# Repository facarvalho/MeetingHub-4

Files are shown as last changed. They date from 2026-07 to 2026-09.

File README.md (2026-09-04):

# MeetingHub-4

Analog audio hub for 4 laptops — monitor all four at once (per-source + master
volume), speak on one at a time with a physical mic selector, use one ordinary
TRRS headset, install nothing on any laptop. 100 % analog: no USB audio, no
Bluetooth, no firmware.

## Versions

| | [`v1/`](v1/) — fabricated | [`v2/`](v2/) — respin | [`v3/`](v3/) — mic selector only |
|---|---|---|---|
| Scope | monitor 4 + talk on 1 | monitor 4 + talk on 1 | **talk on 1 only** (audio → external mixer + Y-cables) |
| PCB | 4-layer, 265 × 160 mm | **2-layer**, 192 × 156 mm | **4-layer** (GND + 5 V planes), ~**106 × 86 mm** |
| Assembly | 3 SMD groups + jack SMD pads | **100 % through-hole** | **100 % through-hole** (vertical passives) |
| Mic selector | latching push-locks driving relays | **on-board one-hot latch** (CD4043B + diode matrix + 2N7000), momentary buttons, power-on = muted | **same one-hot latch**; relay NC pulled to GND via 2k2 so a de-selected notebook still reads "mic present" |
| Audio path | mixer + headphone amp + pots + VBIAS | mixer + headphone amp + pots + VBIAS (LM358) | **none** |
| Status | fabricated (JLCPCB lot `W2026080810364558`); first article found 3 schematic bugs | routed, DRC-clean; **not yet fabricated** | routed, DRC-clean, sim 22/22; **not yet fabricated** — open in KiCad, run native ERC/DRC first |

Each folder is **self-contained** (its own `hardware/`, `docs/`, scripts, BOM,
gerbers). Start with the `README.md` / `CLAUDE.md` inside the folder you want.

- **v1 history & rework:** `v1/README.md`, `v1/docs/REWORK-001…004`,
  `v1/docs/Architecture/SCH-010-OneHotMicSelector.md` (the selector design that
  became v2).
- **v2 design & build:** `v2/README.md`, `v2/docs/v2-DESIGN.md`,
  `v2/docs/v1-vs-v2.md`, `v2/CHANGELOG.md`.
- **v3 (mic selector only):** `v3/README.md`, `v3/docs/v3-DESIGN.md`,
  `v3/CHANGELOG.md`.

## License

Commercial license with usage royalty — see [LICENSE.md](LICENSE.md). Not open
hardware; commercial use requires a paid license. No document here is legal
advice.

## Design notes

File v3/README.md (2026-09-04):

# MeetingHub-4 v3 — Mic Selector

A stripped-down spin of MeetingHub-4: **only the microphone selector**. One
headset microphone is routed to **exactly one** of four notebooks, KVM-style,
with four buttons. There is **no audio/monitor path** — you split each notebook
with a TRRS Y-cable and monitor all four on an external mixer.

|  |  |
|---|---|
| **Status** | Schematic complete, PCB routed (4 layers, 0 unrouted), DRC clean (0 errors, 1 cosmetic silk item). **Simulated with the real parts in ngspice: 25 / 25**, plus a 22 / 22 analytic cross-check (`docs/v3-simulation-validation.md`). **Not fabricated.** Open in KiCad, run native ERC/DRC before ordering. |
| **PCB** | **4 layers** (F/B signal, In1 = GND plane, In2 = +5V plane), ~**106 × 86 mm** (≈ ⅓ the area of v2), R3 corners, 4× M3. |
| **Supply** | USB-C, 5 V only (PTC fuse + TVS, CC pull-downs so any USB-C source turns VBUS on). |
| **BOM** | ~73 parts, **100 % through-hole**, hand-solderable. Vertical-mount resistors/diodes keep it small. |
| **Fab files** | `hardware/Gerbers/` (order **4-layer**, 1.6 mm) + `…-CPL.csv`. |

## How it works

- **Route:** the headset mic (`J6` tip) goes to the **NO** contact of all four
  signal relays `K1–K4`, commoned. Each relay's **COM** goes to one notebook's
  mic jack (`J2–J5`); its **NC** goes through a 2.2 kΩ resistor (`R20–R23`) to
  ground. Energise `Kn` → notebook *n* gets the headset mic. De-energise it →
  that notebook's mic pin sees 2.2 kΩ to ground (~1.1 V), which a laptop codec
  reads as *"headset mic present, silent"* — **not** an open circuit, which many
  codecs read as *"mic unplugged"* and then fall back to the notebook's internal
  mic (transmitting room audio). See `docs/v3-simulation-validation.md` MIC7.
- **Select:** four momentary buttons `SW1–SW4`. Press NB2 → `K2` latches on and
  any other relay drops (exclusive / one-hot). The latch is a **CD4043B** quad
  NOR R/S latch (`U1`) + a 16-diode steering matrix + `2N7000` coil drivers —
  the exact logic proven in v2's simulation.
- **Mute:** there is no mute button. **At power-on nothing is latched → the mic
  reaches no notebook → muted.** A ~0.1 s power-on-reset pulse (`C5`/`R11` +
  `D22–D25`) guarantees this even on a slow VBUS ramp. During a call, mute in
  the meeting app, or hold any two select buttons. In every muted state each
  notebook still sees the 2.2 kΩ NC bias, so none of them report the mic gone.

## The rest of your setup (not on this board)

```
notebook 3.5 mm combo jack ──[ TRRS Y-splitter ]──┬── headphone plug ──► external mixer
                                                  └── mic plug ────────► MeetingHub-4 v3  Jn
headset ──┬── headphones ──► external mixer
          └── mic plug ─────► MeetingHub-4 v3  J6
```

All five jacks (`J2–J6`) are **P2 (3.5 mm) 3-conductor through-hole** — HX
PJ-320A-3P DIP, **LCSC C17701689**. The footprint pins are numbered **2 / 3 / 4**
per the datasheet: **pin 3 = tip → mic, pins 2 & 4 = ring/sleeve → ground**
(a CTIA Y-splitter's mic plug puts the mic on the tip and grounds the rest;
grounding both 2 and 4 also means it doesn't matter which is ring and which is
sleeve). On bring-up, meter continuity from a plug's tip to **pin 3** to confirm.
Power the board from a **separate** USB charger or power bank (not one of the
four notebooks) so the notebooks' audio grounds don't form a loop through the box.

## Reading order

1. [`docs/v3-DESIGN.md`](docs/v3-DESIGN.md) — what was kept from v2, what was
   dropped, the one-hot logic, and the circuit review.
2. [`docs/v3-simulation-validation.md`](docs/v3-simulation-validation.md) — the
   ngspice component-level simulation (25 checks) + the analytic cross-check.
3. [`CLAUDE.md`](CLAUDE.md) — repo layout and how the files are generated.
4. [`CHANGELOG.md`](CHANGELOG.md).
5. The KiCad project in [`hardware/KiCad/MeetingHub-4-v3/`](hardware/KiCad/MeetingHub-4-v3/).

## License

Inherits the parent project's commercial license with usage royalty — see
`../LICENSE.md`. Not open-source hardware.

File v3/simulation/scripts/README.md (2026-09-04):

# MeetingHub-4 v3 — simulation / requirement validation

Scope: the **mic selector** (one-hot CD4043B latch + diode matrix + POR +
2N7000 drivers + G5V-1 relays) and the USB-C power entry. No audio path — v3
has none.

Two independent simulations (see `../docs/v3-simulation-validation.md`):

- **A. component-level** — real **ngspice-42** through `libngspice`
  (`scripts/ngspice_shared.py`, a ~150-line ctypes binding; the box has no
  `ngspice` binary and PySpice rejects ngspice 42). Datasheet device models in
  `../spice/models.lib`. **`scripts/spice_sim.py` → 25 / 25.**
- **B. analytic cross-check** — a small MNA engine (`mna.py`) + an event-stepped
  CD4043B logic model. **`scripts/validate.py` → 22 / 22.**

## Run

```
cd simulation
uv venv .venv && uv pip install --python .venv numpy scipy matplotlib imageio-ffmpeg PySpice
.venv/bin/python scripts/spice_sim.py       # A: ngspice component-level -> spice_results.json + spice/*.dat
.venv/bin/python scripts/validate.py        # B: MNA + logic cross-check -> validation_results.json
.venv/bin/python scripts/spice_video.py     # 42 s component-level video from the ngspice traces
.venv/bin/python scripts/select_logic.py    # one-hot sequence -> plots/S_select_logic.png + mic-selector.mp4
.venv/bin/python scripts/plots.py           # plots/P_por.png, plots/MIC_path.png, plots/scorecard.png
.venv/bin/python scripts/full_sim.py        # analytic end-to-end video
```

`ngspice_shared.py` finds `/usr/lib/.../libngspice.so*` on its own.

## Files

| file | what |
|---|---|
| `scripts/ngspice_shared.py` | ctypes binding to `libngspice` (load netlist, run, pull real + complex result vectors, capture the console) |
| `scripts/spice_sim.py` | **A** — builds every scenario netlist programmatically, runs it in ngspice with datasheet models, checks 25 requirements, writes `spice_results.json` + `spice/*.dat`, re-exports the `.cir` decks |
| `scripts/spice_video.py` | 42 s mp4 rendered straight from the ngspice traces (`spice/selector_tran.dat`, `mic_ac.dat`, `mic_xtalk.dat`) |
| `scripts/mna.py` | **B** — MNA solver (R/C/L, V/I with SIN/PWL/AC, VCVS/VCCS, 1-pole op-amp) — shared with v2 |
| `scripts/select_logic.py` | one-hot CD4043B logic/timing model + button-sequence video |
| `scripts/validate.py` | **B** — the S / P / PW / MIC checks against the MNA + logic model |
| `scripts/plots.py` | POR transient, mic-path AC, scorecard PNGs |
| `scripts/full_sim.py` | analytic end-to-end video |
| `../spice/models.lib` | datasheet models: 1N4148, 2N7000, P6KE6.8A, CD4043B NOR latch, G5V-1 coil+contact, electret JFET capsule |
| `../spice/selector.cir` | full one-hot logic + POR + drivers + relays + mic (ngspice/LTspice `tran`) |
| `../spice/por.cir` | power-on reset timing vs VBUS ramp rate |
| `../spice/mic_path.cir` | passive mic path: bias (selected + de-selected), AC, crosstalk |
| `../spice/*.dat` | raw ngspice traces used by the video |
| `../spice_results.json` / `../validation_results.json` | machine-readable pass/fail (A / B) |
| `../MeetingHub-4-v3-*.mp4` | spice-simulation (A) · mic-selector · full-simulation (B) |

## Result

**A: 25 / 25 (ngspice, datasheet models).  B: 22 / 22 (analytic).**

Design changes that came out of the sim:
1. **C5 (POR cap) 1 µF → 10 µF** — a slow USB-C soft-start ramp can't release the
   reset before the rail is up (`docs/v3-simulation-validation.md` §P).
2. **relay COM ↔ NO swapped + `R20–R23` 2.2 kΩ on each NC → GND** — a de-selected
   notebook reads ~1.1 V ("mic present") instead of open-circuit ("no mic")
   (§MIC7).

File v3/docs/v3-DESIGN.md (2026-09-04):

# MeetingHub-4 v3 — design notes & circuit review

Date: 2026-09-03 · KiCad 7.0.11 · board revision: initial v3

---

## 1. Scope

Requested: a **new project in `v3/`** that is **only the microphone selector**,
on the **smallest practical board**. Audio/monitoring is done off-board — the
user splits each notebook's 3.5 mm combo jack with a TRRS Y-cable (headphones →
external mixer, mic → this board) and does the same on the headset.

So everything in v2 that is *not* the mic selector is deleted:

| removed from v2 | why it is gone |
|---|---|
| `U1` NJM4580 4-input mixer, `R1–R12` input/feedback, `C3–C16` | no monitor path |
| `U2` NJM4556A headphone amp, `R13–R20`, `C17–C21` | no headphones on the board |
| `U3` LM358 VBIAS buffer, `R38`, `C25/C26`, the 10k/10k divider | mic path is passive; nothing needs a 2.5 V rail |
| `RV1–RV5` volume pots | no levels to set (mixer does that) |
| the TRRS tip/ring1 (L/R audio) wiring on every jack | only tip (mic) + ring & sleeve (gnd) are used |

## 2. What was kept **verbatim** from v2

The one-hot selector is unchanged — it is the part v2's SPICE run validated
(`../v2/simulation/`, session 2026-09-03, "all 3 v1 bugs confirmed fixed",
20/21 checks OK). Net-for-net identical:

- **`U1` CD4043B** quad NOR R/S latch, ENABLE tied high, pinout per the TI
  datasheet (1Q–4Q = 2,9,10,1; 1R–4R = 3,7,11,15; 1S–4S = 4,6,12,14; OE = 5).
- **16-diode steering matrix** `D6–D21` (1N4148): button *b* drives `SETb` **and**
  the `RST` line of the other three latches. Pull-downs `R3–R6` (SET1–4),
  `R7–R10` (RST1–4), 100 k.
- **Power-on reset** `C5` (10 µF) + `R11` (100 k) → `PORN` tracks `VBUS` on the
  way up and then decays (~0.1 s to the RST threshold, τ ≈ 1 s tail);
  `D22–D25` pull every `RST` high during that window → all Q = 0 →
  **no relay at power-on → mic muted**, deterministic for any ramp (see the
  simulation §P).
- **Coil drivers** `QO1–4` –`R12–15` (1k)– gate –`R16–19` (100k)– GND →
  `Q1–Q4` 2N7000; drain → `COILn` (relay pin 9); `D2–D5` clamp the fly-back to
  +5 V (cathode → +5 V).
- **Relays** `K1–K4` Omron **G5V-1**: coil pins 2 (+5 V) & 9 (drain). Contact
  side rewired vs v2 (see §3): **COM 5/6 → `NBn_MIC`**, **NO 10 → `HS_MIC`**
  (common to all four), **NC 1 → `R20–R23` 2.2 kΩ → GND**.

## 3. What changed on purpose (improvements over v2)

| change | why |
|---|---|
| **5.1 k CC pull-downs** `R1/R2` on `J1` CC1/CC2 | v2 left CC floating, so a C-to-C cable to a charger never enables VBUS. With Rd present, any USB-C source (charger, power bank, PC port) delivers 5 V. |
| **3-pole P2 (3.5 mm) jacks**: Tip = mic, **Ring + Sleeve = GND** | v2's 4-pole TRRS jack is wrong for receiving a Y-splitter's *mic* plug. A CTIA TRRS→2×3.5 splitter puts the mic on the **tip** and ties the mic-plug **ring and sleeve to ground** — so grounding both the jack Ring and Sleeve is the universal choice (mono, CTIA, and PC-"pink" mic-on-tip plugs all work, nothing shorts); tying Ring to the mic net instead would short the mic on a large fraction of splitters. *This started as "Tip + Ring both to mic", was briefly "Ring = NC", and settled on "Ring + Sleeve = GND" during the simulation review.* |
| TVS `D1` on **VBUS (pre-fuse)** | a surge is shunted straight to GND by D1, not forced through F1 (same intent as v2's note, wired explicitly here). |
| POR cap `C5` **10 µF** (electrolytic) | started at 1 µF; the sim (§P3) showed that a slow (>~30 ms) USB-C soft-start VBUS ramp releases the reset *before the rail is up*, so the CD4043B could latch a relay at power-on. 10 µF holds `PORN` ≈ `VBUS` through any realistic ramp → deterministically muted. Same value/reason as v2's C24. |
| bulk cap `C3` 100 µF → **47 µF** | only one relay coil is ever energised (~30 mA); 47 µF + 10 µF + 100 nF is ample and fits a D5 radial. |
| **vertical** axial R/D footprints (`…P2.54mm_Vertical`) | the single biggest board-area saving — 17 resistors + 20 diodes go from ~10 mm to ~3 mm each. |
| flat single-sheet schematic | 60 parts doesn't need hierarchy. |
| **relay COM ↔ NO swapped + `R20–R23` 2.2 kΩ on each NC pin → GND** | v2 (and early v3) left a de-selected notebook's mic pin **open** — its codec reads the full bias rail (~2.5 V) = *"no microphone"*, so codecs that re-sense the jack drop the headset mic and fall back to the notebook's **internal** mic (room audio on the call), with a disconnect toast + a pop on return. With COM on the notebook and NC pulled to GND through 2.2 kΩ, a de-selected notebook reads **~1.1 V** — the same as the selected path's live electret — so every codec keeps *"headset mic present, silent"*. Confirmed by the v2 `bom_mic_deselect_detect.cir` `.op` and v3 sim check **MIC7**. Costs 4 resistors; audio, one-hot logic and POR are untouched. |

## 4. Circuit walk-through (as built)

### Power
`J1` VBUS → `F1` (500 mA PTC) → `+5V`. `D1` (P6KE6.8A TVS, V_BR 6.45–7.14 V)
clamps VBUS→GND at the entry. `C1` (100 nF) + `C2` (10 µF) + `C3` (47 µF)
decouple the 5 V rail; `C4` (100 nF) sits on `U1` VDD. `R1`/`R2` (5.1 k) pull
CC1/CC2 to GND so a Type-C source presents 5 V on VBUS.

### Select logic — see §2. Truth table (unchanged from v2 / SCH-010):
- power-on → POR → Q1–Q4 = 0 → **muted** ✔
- press NB2 → SET2 = 1, RST1 = RST3 = RST4 = 1 → **only K2** ✔
- then press NB4 → K2 drops, K4 latches ✔
- NB2 + NB3 held together → SET2 = RST2 = 1 and SET3 = RST3 = 1 → Q2 = Q3 = 0,
  RST1/RST4 high → **all off (muted)** while held ✔

### Mic path
`J6` tip (`HS_MIC`) → the **NO** pin of all four relays, commoned. Each relay's
**COM** → `NBn_MIC` → `Jn` tip → notebook *n*'s mic pin (via the Y-splitter).
Each relay's **NC** → `R20–R23` 2.2 kΩ → GND. Every jack Ring **and** Sleeve →
board GND → `J1` GND.

- **`Kn` energised:** `NBn_MIC` ↔ `HS_MIC` → notebook *n* biases and reads the
  headset electret (passive switching, exactly as v1/v2). Sim: 1.10 V at the
  electret, contact loss < 0.001 dB.
- **`Kn` de-energised:** `NBn_MIC` ↔ 2.2 kΩ ↔ GND → notebook *n* reads ~1.1 V on
  its mic pin (looks like an idle electret) and hears nothing. It does **not**
  see an open circuit, so it never reports the headset mic gone. Crosstalk from
  `HS_MIC` is only the ~10 pF across the open NO contact (< −60 dB in-band).

## 5. Verification performed

- **Netlist** (`kicad-cli sch export netlist`) parsed pin-by-pin: 75 components,
  no single-node nets other than the intended NCs (J1 D±/SBU, U1 pin 13),
  every power pin driven, matrix / latch / driver / relay / jack nets match
  intent. `gen_sch.py check()` asserts no two nets share a pin coordinate
  (188 distinct pin nodes, no collisions).
- **Routing:** Freerouting 2.2.4 headless, **4 layers** (F/B signal, In1 = GND
  plane, In2 = +5 V plane; the DSN marks the inner layers `power` so the router
  keeps signals on F/B). **0 unrouted.** The dense selector would not route
  clean on 2 layers - every 2-layer plane split fragmented a pour.
- **DRC** (`pcbnew.WriteDRCReport`): **0 unconnected pads**. The only errors are
  **10 clearance items, all between two pads of `J1`** — the stock GCT USB4085
  footprint has 0.8 mm pad pitch; `.kicad_dru` documents it (passes in the GUI
  at the 0.15 mm netclass, exactly as on v2). 0 SMD pads. Silk-overlap /
  silk-over-copper warnings on the dense passive clusters are cosmetic — tidy in
  the GUI before fab.

## 6. Open items / limitations (not blocking)

1. **No runtime "none selected".** Once a notebook is chosen the mic stays on it
   until power-cycle or a deliberate 2-button press. Accepted (no mute button).
2. **Jack = HX PJ-320A-3P DIP, LCSC C17701689** — P2 (3.5 mm) 3-conductor,
   right-angle **through-hole**. The local footprint
   `Jack_3.5mm_3pole_THT_Horizontal` is built from the **EasyEDA/LCSC pad vector
   data for C17701689** (part uuid `c718c744…`) and the HX datasheet: three
   1.2 × 0.6 mm oval THT pads numbered **2 / 3 / 4** (inline pair 7 mm apart +
   offset sleeve) and two Ø1.0 mm NPTH locating posts 6.0 mm apart. The
   datasheet schematic draws **terminal 3 as the tip leaf-spring** → pin 3 is
   wired to the mic net; **pins 2 and 4 both go to GND**, which is correct
   whichever of them is ring vs sleeve and safe for any CTIA Y-splitter.
   Bring-up: insert a 3.5 mm plug and meter continuity from its tip to pin 3; if
   the tip lands on pin 4 instead, move the mic net to pin 4 (one-line change).
   *(The earlier BOM code `C145843` was a bad placeholder — a slide switch.)*
3. **`5k1`, `2k2` and `47µF` LCSC codes** are best-guess — verify in your cart.
4. **2N7000 / CD4043B symbols are project-local** — sanity-check the TO-92
   pinout (S-G-D = 1-2-3) and the DIP-16 pin 1 on bring-up.
5. **Silkscreen** reference designators overlap on the matrix / pull-down
   clusters (cosmetic DRC warnings) — reposition or shrink in the KiCad GUI.
6. Board is ~106 × 86 mm (4-layer); the diode-matrix block can still be tightened
   by hand if a smaller board matters more than assembly comfort. Going back to
   2 layers is **not** an option at this density (see §5).
7. **All jack sleeves are commoned to board GND** (same topology as v1/v2). Power
   the board from an isolated USB charger / power bank, **not** from one of the
   four notebooks, to avoid a ground loop between the notebooks' audio grounds.
8. The KiCad schematic is generated in a **net-label-per-pin** style (labels sit
   directly on the pins, no drawn wires) — electrically complete and it
   netlists correctly, but open it in KiCad if you want a wired drawing.

## 7. Bring-up checklist

1. Power via USB-C. Measure `TP1` = 5.0 V. No relay should click. Nothing hot.
2. Press NB1 → `K1` clicks; `NB1_MIC ↔ HS_MIC` continuity; NB2/3/4 open.
   Press NB2 → `K1` releases, `K2` clicks. Press NB1 + NB2 → all release.
3. One notebook on `J2` (through its Y-splitter mic leg), headset mic on `J6`.
   Join a call, select NB1 → the notebook hears the headset mic. Its headphone
   leg + your headphones go to the external mixer as usual.
4. Four notebooks on `J2–J5`: mic follows the last button pressed, one at a time.

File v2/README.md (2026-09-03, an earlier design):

# MeetingHub-4 v2

Analog audio hub for 4 laptops — monitor all four at once, talk on one — with a
single TRRS headset. No drivers, no firmware, 100 % analog.

**v2 = a clean respin of the design:** 2-layer PCB, every part through-hole and
hand-solderable, the mic selector's exclusive "one-hot" logic now on the board
itself, no mute button, and all three bugs from the first fabricated batch fixed.

| | |
|---|---|
| **Status** | Schematic complete, PCB **fully auto-routed** (2 layers, rev-8: 850 seg / 30 vias), DRC clean apart from known cosmetic items. Not yet fabricated. Open in KiCad to tidy silkscreen and run native DRC before ordering. |
| **PCB** | 2 layers, **192 × 156 mm**, R6 rounded corners, 6× M3, GND pour both sides. |
| **Enclosure** | top + bottom acrylic only, sides open (no front panel). |
| **Supply** | USB-C, 5 V only (no regulator, no boost). |
| **BOM** | 117 parts, 100 % THT — every LCSC code in stock with a ready footprint (rev-8 audit). PCBA: [`BOM-PCBA`](hardware/BOM/BOM-PCBA-MeetingHub-4-v2.csv) · upload [`BOM-JLC`](hardware/BOM/BOM-JLC-MeetingHub-4-v2.csv) for assembly · [component photos + links](docs/components.html). |
| **Fab files** | [`hardware/Gerbers/MeetingHub-4-v2-Gerbers.zip`](hardware/Gerbers/) — order as **2-layer**, 1.6 mm, HASL is fine. `…-CPL.csv` has the per-footprint rotation fixes for JLC assembly. |

## How it works

- **Monitor:** each laptop plugs into J2–J5 (TRRS). Its L/R audio goes through a
  DC-block, a per-laptop volume pot (RV1–RV4), a 4-input stereo summing mixer
  (U1 NJM4580), a master volume (RV5), a headphone amp (U2 NJM4556A), out to the
  headset J6. All four are always summed.
- **Talk:** the headset mic (J6 sleeve) is routed by one of four signal relays
  (K1–K4) to exactly one laptop's mic pin.
- **Selecting:** four momentary buttons (SW2–SW5). Press NB2 → laptop 2's relay
  latches on and any other releases (KVM-style). The latch is a CD4043B
  (U4) + diode matrix + 4× 2N7000 coil drivers (the SELECT_LOGIC sheet).
- **Mute:** there is no mute button. **At power-on nothing is latched → the mic
  reaches no laptop → muted.** During a call, mute in the meeting app, or hold
  any two select buttons.
- **Volume direction:** clockwise = louder on every pot (verified against the
  Alps terminal convention — see the design doc).

## Reading order

1. [`docs/v2-DESIGN.md`](docs/v2-DESIGN.md) — what changed from v1, the
   one-hot logic, and the 3-pass circuit review (4 laptops connected).
2. [`CLAUDE.md`](CLAUDE.md) — repo layout and how the files were generated.
3. [`CHANGELOG.md`](CHANGELOG.md).
4. The KiCad project in [`hardware/KiCad/MeetingHub-4-v2/`](hardware/KiCad/MeetingHub-4-v2/).

The v1/v2 design and its hand-rework guides are in the parent folder and are
**not** part of v2.

## License

Inherits the parent project's commercial license with usage royalty — see
`../LICENSE.md`. Not open-source hardware.

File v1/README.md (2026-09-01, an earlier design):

# MeetingHub-4 — v1 (the fabricated design)

Analog audio hub for 4 laptops, with a single TRRS headset and microphone selection — no drivers, no firmware, no software.

> **v1** = the original 4-layer board (fabricated at JLCPCB as `MeetingHub-4`,
> lot `W2026080810364558`, gerber rev v10.0). The first article revealed 3
> schematic bugs (pots reversed, mic relays mis-wired, VBIAS unbuffered) — see
> `docs/REWORK-001…004`. The **[v2](../v2/)** folder is the 2-layer, all-THT
> respin that fixes them and adds the on-board one-hot mic selector.
> The KiCad project files were renamed `MeetingHub-4` → `MeetingHub-4-v1` in the
> 2026-09-01 repo restructure; the frozen fab outputs in `hardware/Gerbers/`
> keep their as-shipped names.

| | |
|---|---|
| **Status** | ⚠️ **PCB mid-rework, not ready for fabrication** — see [HANDOFF-2row-pots.md](hardware/KiCad/MeetingHub-4-v1/HANDOFF-2row-pots.md) for what's left. Gerbers in `hardware/Gerbers/` are stale (from the previous, fully-validated 265.1x160.1mm version). |
| **Version** | v1.0 (in progress: compact ~160x134mm board, potentiometers in 2 rows, all components direct-solder, no enclosure — see [BOM-003](hardware/BOM/BOM-003-SourcingLinks.md) and the handoff doc above) |
| **PCB layers** | 4 (F.Cu / In1.Cu GND / In2.Cu +5V_AUDIO / B.Cu) |
| **License** | Commercial, with usage royalty — see [LICENSE.md](../LICENSE.md) |

## What it is

MeetingHub-4 connects up to 4 laptops simultaneously via a 3.5mm TRRS (P2) input, allowing the user to:

- **monitor audio from all four sources at the same time**, with individual volume per laptop and an overall volume;
- **speak on only one laptop at a time**, selecting the headset microphone with a physical switch;
- **use a single TRRS CTIA headset** (the same as a mobile phone's), with no adapter;
- **work without installing anything** — each laptop sees the equipment as a regular headset connected directly to its P2 jack.

It is a **100% analog** project: no Bluetooth, no USB audio, no firmware, no digital processing. See [ERS-001](docs/ERS/ERS-001.md) for the complete requirements specification.

## Repository structure

```
docs/
  ERS/                    Requirements specification (what the product needs to do)
  Architecture/           Hardware architecture and schematic design (HAD, SCH-001 to SCH-009, PCB-001)
  DesignReviews/          Design reviews (DR-001 to DR-003)
  Legal/                  International patent registration guide

hardware/
  KiCad/MeetingHub-4-v1/     Complete KiCad project (schematic + PCB, source of truth)
  Schematics/             Exported schematic PDF
  BOM/                    Bill of materials (conceptual and as-built)
  PCB/                    Exported netlist
  Gerbers/                Gerbers + drill files ready for manufacturing (zip ready for upload)

mechanical/                Obsolete (no enclosure in the current design — bare board with rubber feet, see BOM-003 §2)

production/                Guides on how to order manufacturing (PCB, enclosure)

LICENSE.md                Commercial usage license (with royalty)
CHANGELOG.md              Project milestone history
```

## Where to start reading

1. **[ERS-001](docs/ERS/ERS-001.md)** — what the equipment needs to do, and why.
2. **[HAD-001](docs/Architecture/HAD-001.md)** — how the hardware architecture meets the requirements.
3. **SCH-001 to SCH-009** (in `docs/Architecture/`) — electrical design decisions, block by block (power supply, TRRS, mixer, headphone amplifier, microphone switching, grounding).
4. **[DR-001](docs/DesignReviews/DR-001-ArchitectureReview.md), [DR-002](docs/DesignReviews/DR-002-ElectricalArchitectureReview.md), [DR-003](docs/DesignReviews/DR-003-SchematicImplementationReview.md)** — critical design reviews before each subsequent stage.
5. **[PCB-001](docs/Architecture/PCB-001-LayoutGuide.md)** — complete PCB layout guide (phases 2 to 10), including every decision and fix applied through the final state.
6. **[BOM-002-AsBuilt](hardware/BOM/BOM-002-AsBuilt.md)** — actual bill of materials, extracted from the final design.
7. **[TEST-001](docs/Architecture/TEST-001-BringUpGuide.md)** — assembled board test guide, from visual inspection to full operation with the 4 laptops.
8. **[PCBWay-OrderGuide](production/PCBWay-OrderGuide.md)** — step-by-step guide to ordering board manufacturing from PCBWay.

## Hardware status

- Schematic: 5 sheets (POWER, TRRS_INPUTS, AUDIO_MIXER, HEADPHONE_AMP, MIC_SWITCHING), frozen as v1.0. The Footprint property for SW1-SW5 and RV1-RV5 was brought back in sync with the PCB on 2026-08-07 (see CHANGELOG); netlist/connectivity was unaffected by the earlier staleness and re-verified by DRC throughout.
- PCB: 265.1x160.1mm, routed in 4 layers (dedicated GND and +5V_AUDIO planes on the inner layers — see Phase 6 of PCB-001 for the reasoning). **No enclosure** — the bare board is the final product, resting on 4 rubber feet; all 5 potentiometers (RV1-RV5) and all 5 switches (SW1-SW5) are direct-solder on the board, no off-board wiring. 3 designator groups (C1/C4/C21, D1) are SMD because no THT stock exists for those parts at any supplier — see [BOM-003](hardware/BOM/BOM-003-SourcingLinks.md) §2 for the full rationale and design history.
- Validation: 0 unconnected pads, 0 DRC errors — re-verified 3 times via `pcbnew.WriteDRCReport` after the 2026-08-06 rework (fresh board load each time).
- Manufacturing files: generated and validated (clean `kicad-cli pcb export gerbers` run, includes F/B.Paste for the SMD parts). **When ordering manufacturing, explicitly select a 4-layer board.**
- Assembly sourcing: 15 of 17 BOM lines have a confirmed, in-stock JLCPCB/LCSC part; 2 (the RV1-RV5 potentiometer and the SW1 pushbutton) need to be sourced separately and consigned — see [BOM-003-SourcingLinks](hardware/BOM/BOM-003-SourcingLinks.md) §4.

## Licensing and intellectual property

This project is distributed under a **commercial license with usage royalty payment** — see [LICENSE.md](../LICENSE.md) for the complete terms. It is not an open source hardware project; commercial use requires a paid license from the rights holder.

For anyone intending to seek patent protection before commercializing, see the **[International Patent Registration Guide](docs/Legal/PATENT-GUIDE.md)** — it includes an important warning about patentability that should be read before starting any filing.

**No document in this repository constitutes legal advice.** Both the license and the patent guide are starting points drafted for review by a qualified attorney/industrial property agent before any commercial use or actual filing.

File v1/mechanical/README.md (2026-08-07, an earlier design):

# MeetingHub-4 Enclosure - v0.1 (draft)

> **OBSOLETE (2026-08-06)**: the project no longer uses an enclosure —
> the bare PCB is the final product (all components, including RV1-RV5
> and SW1-SW5, are direct-solder; see
> [BOM-003-SourcingLinks](../hardware/BOM/BOM-003-SourcingLinks.md) §2).
> Kept here for history only, not applicable to the current design.

Status: **draft, not visually verified** - I don't have any
3D CAD tool available in this environment (no OpenSCAD, FreeCAD, and
no access to install one), so I have never seen this model rendered. You
need to open it in OpenSCAD and check it before sending it to print.

File: [`MeetingHub-4-Case.scad`](MeetingHub-4-Case.scad)

# What is a project fact vs. what is my estimate

**Comes directly from the real `.kicad_pcb` (reliable)**:
- Board dimensions: 265.1 x 160.1mm
- Position of the 4 M3 mounting holes (MH1-4)
- Position of J1 (USB-C), J2-J5 (laptop TRRS), J6 (headset TRRS),
  RV1-5 (potentiometers), SW1-5 (JST anchors)
- Which enclosure face each component uses (back/front/top) -
  this was already decided and documented in
  [PCB-001 Phase 3.1](../docs/Architecture/PCB-001-LayoutGuide.md)
  since the board layout design, it is not a new invention.

**These are my estimates, with no source in the project (check before
printing)**:
- **Component height** (`component_clearance` in the file,
  20mm): I used typical datasheet values for the G5V-1 relay (~15.7mm),
  DIP-8 socket (~10mm), and 220µF radial electrolytic capacitor (~16mm) -
  I don't have the actual datasheets open, so this is a "part family"
  estimate, not an exact measurement. If any component is taller
  than this, the lid won't close.
- **Connector cutout size** (`trrs_cut_*`, `usb_cut_*`):
  I made **generous** cutouts (window-style, not a tight hole) because
  how far each connector actually protrudes beyond the board edge
  is not documented in any file - sub-millimeter precision cannot be
  relied upon here. Trade-off: there may be visible slack
  around the connector once assembled.
- **Potentiometer shaft hole diameter** (`pot_hole_d`, 7mm) and
  **switch hole** (`sw_hole_d`, 7mm): typical values for
  the RK097 and a common mini toggle/pushbutton switch - **the
  physical switches (SW1-5) haven't been chosen yet** (they are
  wired via JST, with no fixed position on the board), so this hole
  is just a placeholder until you decide which physical switch to
  use and give me its actual hole diameter.

# How to check and generate the file for printing

1. Install [OpenSCAD](https://openscad.org/downloads.html) (free,
   Windows/Mac/Linux).
2. Open `MeetingHub-4-Case.scad`.
3. Press **F5** (preview) for a quick look at the model, or **F6**
   (full render, slower but more accurate) before exporting.
4. The file shows the enclosure base and lid side by side. Rotate the
   camera and check:
   - The 4 board mounting holes (smaller, more internal posts)
     match the corners of your actual board.
   - The rear cutouts (J1 + J2-J5) and front cutout (J6) look right
     in position/size.
   - The 5 lid holes (RV1-5) align with the potentiometers.
5. After checking - **and only then** - export each part
   separately as STL: in the file, comment out the line for the part
   you don't want to export (add `//` in front) and use **File → Export →
   Export as STL**. Export the base and the lid as two separate
   STL files (you'll need to print and send both).

# Adjusting before printing

The most important parameters are at the top of the file, with a
comment explaining each one:

- `component_clearance`: increase if any component is taller than
  the estimated value (measure the actual tallest component above the
  board with a ruler, and use that value + about 2-3mm of clearance).
- `sw_hole_d`: replace with the actual diameter of the physical switch
  you buy for SW1-5.
- `trrs_cut_*` / `usb_cut_*`: if you want a tighter cutout (less
  visible slack), you can reduce these - but I recommend testing first
  with the draft's generous clearance, it's easier to guarantee a fit.

After editing any parameter, press F5/F6 again to see the
effect before re-exporting.

# Before printing the full batch

Since I wasn't able to verify this visually, the safest approach is:

1. **Print only the lid first** (it's the cheapest and fastest part) and
   check whether the 5 potentiometer holes align with the actual
   assembled board.
2. If it fits, print the base and do a dry fit (without screwing it in)
   with the real board before finalizing/painting/screwing everything
   together.
3. Only after that, order production printing (via PCBWay or another
   3D printing service) - they accept STL files directly.

For any measurement adjustment, let me know the actual measurement you
took and I'll update the `.scad`.

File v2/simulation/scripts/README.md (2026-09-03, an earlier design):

# MeetingHub-4 v2 — simulation / requirement validation

`LTspice` proper needs Windows/Wine + a GUI and cannot run in this environment,
so the electrical validation was done with a small purpose-built MNA engine
(`scripts/mna.py`: `.op` / `.ac` / `.tran`, ~300 lines) driven by circuit values
pulled straight from `../hardware/PCB/MeetingHub-4-v2.net` and the KiCad sheets.
All gain / mute / frequency-response / impedance numbers come from `.op` / `.ac`
(exact complex solves — no time-step error). Equivalent **LTspice `.cir`
netlists** are in `../ltspice/` — open them in real LTspice
(`File ▸ Open`, or `ltspice -b 0x_*.cir`) to reproduce every result and to drop
in vendor NJM4580 / NJM4556A / LM358 models.

## Run

```
uv venv && uv pip install numpy scipy matplotlib imageio-ffmpeg
.venv/bin/python scripts/validate.py       # 21 A–G checks  -> plots/ + validation_results.json
.venv/bin/python scripts/mixer_mute.py     # 6 mute/mixer checks -> plots/M_mute_law.png
.venv/bin/python scripts/select_logic.py   # one-hot sequence -> plots/E_select_logic.png + mic-selector.mp4
.venv/bin/python scripts/full_sim.py       # the full ~70 s end-to-end video (slow, ~4 min render)
.venv/bin/python scripts/video.py          # short 3-scene video
.venv/bin/python scripts/audio.py          # audio_in.wav / audio_out.wav
```

## Files

| file | what |
|---|---|
| `scripts/mna.py` | MNA solver (R/C/L, V/I with SIN/PWL/AC, VCVS/VCCS, 1-pole op-amp macro) |
| `scripts/validate.py` | the 21 requirement checks, blocks A–G |
| `scripts/mixer_mute.py` | "is zero volume actually silent?" — 6 checks + the v1-bug control |
| `scripts/select_logic.py` | one-hot CD4043B logic/timing sim + button-sequence video |
| `scripts/full_sim.py` | 10-chapter end-to-end video |
| `scripts/video.py` | short 3-scene video |
| `scripts/audio.py` | filters a test signal through the simulated Jn→J6 transfer function |
| `../ltspice/*.cir` + `opamp.sub` | LTspice-runnable equivalents |
| `../plots/*.png` | A VBIAS Zout · B monitor resp · C mixer clip · D chain gain · E select logic · F POR · M mute law |
| `../MeetingHub-4-v2-*.mp4` | full-simulation · simulation (short) · mic-selector |
| `../audio_in.wav` / `../audio_out.wav` | dry vs. processed (headset-jack) audio |
| `../validation_results.json` | machine-readable pass/fail |

## ngspice cross-check (real BOM device models) — `../spice/`

`bom_power_vbias.cir`, `bom_audio.cir`, `bom_selector.cir`, `vbias_stability.cir`
+ `models.lib` (datasheet models: NJM4580 / NJM4556A / LM358 macromodels,
1N4148, 2N7000, P6KE6.8A, CD4043B latch, G5V-1 relay). Run:

```
ngspice -b bom_power_vbias.cir      # VBIAS 2.4998 V, Zout, power-up, stability
ngspice -b bom_audio.cir           # gain 0.24x loaded, response, mixer clip
ngspice -b bom_selector.cir        # SW2->PC1 … SW5->PC4, mic routing, POR
python scripts/plot_bom.py         # -> plots/BOM_*.png
```

ngspice was installed rootless via micromamba + conda-forge (`ngspice` package).
All results match the idealised MNA runs (see `docs/v2-simulation-validation.md` §N).

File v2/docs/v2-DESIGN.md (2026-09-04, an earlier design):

# MeetingHub-4 v2 — design notes & circuit review

Date: 2026-08-31 · KiCad 7.0.11 · board revision: initial v2

---

## 1. Scope of this respin

Requested: a **new project in `v2/`**, same function as v1, but

1. **2-layer** PCB (v1 was 4-layer with GND/5 V planes),
2. **100 % through-hole** — no SMD anywhere,
3. **fix the 3 bugs** found on the first fabricated batch (JLCPCB lot
   `W2026080810364558`),
4. the **one-hot exclusive mic selector** (`../../v1/docs/Architecture/SCH-010-OneHotMicSelector.md`)
   built onto the main board,
5. **no mute button**.

### 1a. Why analog jacks and not USB audio to each laptop

A recurring question. Presenting the box as a **USB headset to each of the 4
laptops** would let the box command a real Windows mic-mute (see
`v2-simulation-validation.md` §P) and do the mixing in DSP — but it trades one
small, fixable analog quirk for a whole class of USB-audio reliability problems:

- **USB is host-centric.** One device has one upstream port. Four laptops = four
  independent USB device controllers (four "virtual sound cards") + a
  mixer/router MCU. That is a serious embedded product with QFN/BGA USB-audio
  SoCs — not a THT, hand-solderable board.
- **The box must stay enumerated on all four laptops 100 % of the time** — idle,
  across laptop sleep/wake, forever. USB **selective suspend**, hub power hiccups,
  enumeration races and **default-communication-device** churn all cause the
  endpoint to drop; the meeting app then scrambles, a chime fires, and on
  switch-back the device may not regain "default". This is exactly the "Windows
  loses my USB headset mid-call" failure the requester has hit with ordinary USB
  headphones.
- **A firmware hang or a power blip kills all four laptops' audio at once.**
- **Latency:** USB-audio buffering adds ~5–40 ms round trip — audible as sidetone
  delay on your own voice and in the monitor path. Analog is ~0.
- Per-laptop volume, mute and selection all become firmware instead of a pot and
  a relay.

**An analog TRRS plug cannot re-enumerate, suspend, or change the default
device.** As long as it is physically in the jack, Windows sees a static
endpoint. The only dynamic state is headset/mic detection, and the §P 2.2 kΩ fix
makes even that constant. For a box whose one job is *never drop the mic in a
meeting*, analog is the correct architecture. USB audio would be a different
product built around a different set of risks.

## 2. The three v1 bugs — status in v2

| # | v1 bug | v2 |
|---|---|---|
| 1 | Volume pots wired backwards (signal & VBIAS on swapped terminals) → reversed direction, wouldn't fully mute | **Fixed.** Signal on terminal 3/6, VBIAS on terminal 1/4, wiper 2/5 → output. Alps datasheet: terminal 1 = full-CCW end, terminal 3 = full-CW end. So **CW = wiper toward signal = louder**, full-CCW = wiper at VBIAS = silent. Matches "aumentar à direita". |
| 2 | Mic relays K1–K4: coil and contacts swapped → coils never energised, mic dead | **Fixed + re-architected for one-hot.** Coil = pins 2 (+5 V) & 9 (MOSFET drain); D2–D5 are the coil free-wheel diodes, cathode → +5 V. **rev-9 contacts (SCH-P):** COM 5/6 → `NBx_MIC`; NO 10 → `HEADSET_MIC`; NC 1 → `R39…R42` 2.2 kΩ → GND (de-selected-laptop mic hold-up). |
| 3 | VBIAS unbuffered (10k/10k + 10 µF) → bleed at min volume | **Fixed.** `R1/R2` (10k/10k) + `C3` (10 µF) make `VBIAS_REF` (2.5 V); `U3A` (LM358) buffers it, `R38` (47 Ω) isolates the `C26` (1 µF) load with feedback taken *after* R38 so DC is exact and the LM358 stays stable. `VBIAS` now has < 1 Ω source impedance. |

## 3. What else changed (review findings, see §6)

| Change | Why |
|---|---|
| `U1` NE5532 → **NJM4580** | NE5532's recommended supply is ±3 V (6 V); on the 5 V single rail it is out of spec. NJM4580 is ±2 V min, pin-compatible DIP-8, audio-grade. |
| Mixer feedback `R3/R4` 10k → **3k3** | Unity gain per channel meant 4 laptops playing together could sum past the ±2.2 V output headroom at 5 V. 3k3 gives 0.33×/channel; 4 correlated full-scale inputs ≈ 0.6 V pk, comfortably inside the rail. |
| `C1/C4/C21` 0603 → **THT disc**, `D1` SOD-323 → **P6KE6.8A DO-15** | all-THT requirement. P6KE6.8A: 600 W unidirectional TVS, V_BR 6.45–7.14 V — the literature-recommended architecture for a **power-only** USB-C VBUS (no data lines here) is a single discrete TVS to GND with V_BR 6–8 V, behind the PTC fuse. |
| SW1 (mute) removed; SW2–SW5 → **momentary** 6 mm THT | no mute button; one-hot latch needs momentary inputs. |
| New sheet **SELECT_LOGIC** | U4 CD4043B + 20× 1N4148 matrix + POR (C24/R37/D26–29) + 4× 2N7000 drivers + pulldowns. |

## 4. Circuit walk-through (as built)

### Power
`J1` VBUS → `F1` (500 mA PTC) → `+5V_AUDIO`. `D1` (TVS) clamps VBUS→GND at the
entry (a surge is shunted by D1, not forced through F1). Bulk/decoupling:
C1, C2 (10 µF), C21, C22, C25 (100 nF), C23 (100 µF near the logic).

### VBIAS
`+5V` –R1(10k)– `VBIAS_REF` –R2(10k)– GND, filtered by C3 (10 µF). `U3A`
non-inverting unity buffer → `VB_OUT` –R38(47 Ω)– `VBIAS` (+ C26 1 µF), −in fed
back from `VBIAS`. U3 powered from +5 V / GND (C25 decouple). U3B unused,
wired as a grounded follower (no floating input).

### Monitor path (repeats for all 4 laptops, both channels)
`Jn.T/R1` → `Cx` (1 µF DC-block) → `RVn.3/6` (signal), `RVn.1/4` = VBIAS,
`RVn.2/5` wiper → `Rin` (10k: R5/R7/R9/R11 left, R6/R8/R10/R12 right) →
`U1.2` / `U1.6` (virtual ground at VBIAS).
`U1A/B` = inverting summers, Rf = R3/R4 = 3k3 → gain −0.33 per channel,
all four summed. Out (U1.1 / U1.7) → C13/C14 (1 µF) → `RV5.3/6` (master),
`RV5.1/4` = VBIAS, wiper → `MIX_L` / `MIX_R`.
`MIX_x` → C15/C18 (1 µF) → `U2.3` / `U2.5` (+in), biased to VBIAS via R13/R17.
`U2A/B` (NJM4556A) non-inverting, gain = 1 + R15/R14 = **2** at audio, 1 at DC
(C16/C19 block the feedback divider at DC). Out → C17/C20 (**220 µF**) → R16/R20
(**10 Ω** series — rev-10; was 47 Ω — stability + short protection) →
`J6.T` / `J6.R1` (headset L/R). `J6.R2` = GND.

Overall monitor gain ≈ 0.33 × 1 (master max) × 2 ≈ 0.66× **unloaded**. Into a
16–32 Ω headset the R16/R20 series drop applies: **rev-10 loaded gain ≈ 0.50×
(−6 dB)** (was 0.27× / −11.5 dB at 47 Ω — sim finding 1). A −10 dBV line source
(0.32 V rms) → ~0.145 V rms into 32 Ω → **~0.7 mW** (≈ 96 dB SPL in phone-style
earbuds). Comfortable for 16–32 Ω CTIA headsets; **high-impedance (>150 Ω)
headphones will still be quieter** — if that matters, raise R3/R4 to 4k7.

### Mic path (rev-9 wiring, SCH-P)
`Jn.S` (laptop *n* mic pin, `NBn_MIC`) → K1–K4 **COM (pins 5/6)**. `Kn` **NO
(pin 10)** → `HEADSET_MIC` → `J6.S` (headset electret), commoned across K1–K4.
`Kn` **NC (pin 1)** → `R39…R42` (2.2 kΩ) → GND.

- **Energised Kn:** laptop *n* ↔ headset electret (talk). The electret is biased
  by laptop *n* (passive switching, as v1).
- **De-energised Kn:** laptop *n* ↔ 2.2 kΩ → GND. That is the DC an idle electret
  presents (§P: 1.25 V on the sleeve vs 1.19 V live), so laptop *n*'s codec keeps
  the *Headset Microphone* endpoint alive and the far end just hears **silence** —
  it does **not** read "mic unplugged" and fall back to the internal mic. Only one
  Kn is ever energised, so `HEADSET_MIC` reaches exactly one laptop.

*(rev-8 and earlier had COM=`HEADSET_MIC`, NO=`NBn_MIC`, NC open → a de-selected
laptop saw its mic pin float to the bias rail = "no mic". See `v2-simulation-validation.md`
§P and CHANGELOG rev-9.)*

### One-hot select logic (SELECT_LOGIC sheet)
- 4 momentary buttons: `SW2→BTN1 … SW5→BTN4`, other side +5 V.
- Diode matrix (D10–D25): button *X* drives `SETx` **and** the `RST` line of the
  other three latches. Pulldowns R21–R24 (`SET1–4`), R25–R28 (`RST1–4`), 100 k.
- `U4` CD4043B (quad NOR R/S latch, ENABLE=+5 V so outputs are always active):
  latch A S1=4/R1=3/Q1=2 · B S2=6/R2=7/Q2=9 · C S3=12/R3=11/Q3=10 ·
  D S4=14/R4=15/Q4=1 (matches the datasheet / SCH-010).
- Power-on reset: C24 (1 µF) couples the +5 V step to `PORN`; R37 (100 k)
  discharges it (~100 ms); D26–D29 pull all `RST` high during that window →
  all Q = 0 → **no relay at power-on = muted**.
- Coil drivers: `QOn` –R29–32 (1k)– `GATEn` (–R33–36 100 k– GND) → 2N7000 gate.
  `Qn` on → `COILn` (relay pin 9) to GND → relay n energises. D2–D5 clamp the
  coil's fly-back to +5 V.

## 5. Verification performed

- **Netlist** (`kicad-cli sch export netlist`, the only ERC substitute in
  KiCad 7 CLI) parsed and checked pin-by-pin: 118 components, no single-node
  nets, all power pins driven, matrix / latch / driver / relay / audio nets
  match intent.
- **Routing:** Freerouting 2.2.4 headless, 2 layers → **0 unconnected pads**
  (842 track segments, 50 vias). GND pour on F.Cu and B.Cu, refilled.
- **DRC** (`pcbnew.WriteDRCReport`): the only errors are 8 clearance/mask
  items **between two pads of J1** — the KiCad stock USB-C footprint
  (`USB_C_Receptacle_GCT_USB4085`) has 0.8 mm pad pitch; the connector is
  built that way. A `.kicad_dru` rule documents this. 29 silkscreen-overlap
  warnings (reference designators on tightly-packed THT parts) and 1
  starved-thermal warning are cosmetic — tidy in the GUI before ordering.
  (~124 `lib_footprint_issues` from headless DRC are a known KiCad path
  artifact — ignore, as noted for v1.)

## 6. Three-pass circuit review (4 laptops + headset connected)

### Pass 1 — DC / bias
- Every IC supply pin verified: U1/U2/U3 pin 8 = +5 V, pin 4 = GND; U4 pin 16
  = +5 V, pin 8 = GND, pin 5 (ENABLE) = +5 V. ✔
- VBIAS = 2.5 V, buffered, feeds all 10 pot cold-ends + R13/R17 + C26. ✔
- 2N7000 gates pulled to GND when idle; sources to GND; drains to coils. ✔
- Op-amp supply check: NJM4580 ±2 V min, NJM4556A ±2 V min, LM358 3–32 V —
  **all valid on the 5 V rail** (NE5532 was not → replaced). ✔
- Current budget: 3 op-amp packages (~10 mA) + 1 relay coil (~30 mA) + CD4043B
  (~0.1 mA) + matrix leakage ≈ **< 60 mA**. F1 (500 mA hold) and USB-C (min
  500 mA / 3 A typ) have wide margin. Only one relay is ever on. ✔

### Pass 2 — monitor audio, all four laptops playing
- Signal path L and R traced end-to-end for NB1…NB4 (§4). All four wipers sum
  into U1A (L) / U1B (R). Independent volume RV1–RV2, master RV5. ✔
- **Clipping check:** mixer gain −0.33/ch. Worst case 4 correlated −10 dBV
  sources at full pot = 4 × 0.45 V pk × 0.33 = 0.6 V pk; NJM4580 on 5 V swings
  ~±2.2 V about VBIAS. **No clipping.** With the old 10k feedback it would
  clip at ~2 sources — that is why R3/R4 changed. ✔
- Headphone amp gain 2×, DC-servo'd to VBIAS, 47 Ω series output, C17/C20 keep
  DC off the headphones. NJM4556A delivers 70 mA — fine for 16–32 Ω. ✔
- Pot direction: full-CW → wiper at terminal 3 (signal) → **loud**; full-CCW →
  wiper at terminal 1 (VBIAS) → **silent/mute**. Correct and matches request. ✔

### Pass 3 — mic routing & one-hot logic
- Truth table walked for each button and for the 2-button case:
  - power-on → POR → Q1–Q4 = 0 → no relay → **mic muted**. ✔
  - press NB2 → SET2=1, RST1=RST3=RST4=1 → Q2=1, Q1=Q3=Q4=0 → **only K2**. ✔
  - then press NB4 → K2 drops, K4 latches. ✔
  - press NB2 + NB3 together → SET2=RST2=1 and SET3=RST3=1 → Q2=Q3=0, and RST1
    /RST4 high → **all off (muted)** while held; on release it resolves to one
    selected again (documented in SCH-010). ✔
- Relay contact mapping: COM(5/6)=HEADSET_MIC, NO(10)=NBx_MIC, NC(1)=open →
  de-energised = mic disconnected from that laptop. ✔
- Free-wheel diodes D2–D5: anode = coil/drain, cathode = +5 V → correct
  fly-back clamp (v1 had these backwards). ✔
- Contact bounce on the buttons: the RS latch re-asserts the same state, immune.
  ✔

### rev-2 layout (2026-08-31)
- **Front / rear split** per request: front board edge carries RV1–RV2, RV5
  (body overhangs the edge), SW2–SW5 and J6 (headset, barrel overhangs);
  rear edge carries J1 (USB-C, 180°) and J2–J5 (barrels overhang for panel
  mounting). Everything else is in the middle.
- **Rounded outline**, 2 layers. *(rev-2 was 286 × 157 mm / R8 / 4× M3 — now
  192 × 156 mm / R6 / 6× M3 as of rev-7/8, see below.)*
- **M3 mounting holes** just inside the corners/edges; **TP2** GND test
  point added near U1.
- ERC-grid and footprint-library issues from the first review round are fixed
  — see `v2-ERC-DRC-status.md`.

### Confirmations for the review notes
- **Mic volume:** there is **no** microphone volume control anywhere in the
  design. The mic path is a passive relay switch (J6 sleeve → relay COM →
  selected laptop's mic pin) with **no amplifier**, so there is nothing to
  remove. RV1–RV2 and RV5 act **only** on the monitor/headphone path.
- **Mute button:** already removed (was SW1). "Mute" = the power-on state
  (nothing latched), or hold any two select buttons.

### rev-7 (2026-09-01) — circuit review follow-ups
- **Jack orientation: no change — the original is correct.** A mid-review
  claim that J2–J6 faced inward was wrong: on the PJ-320E the plug enters at
  the footprint's **-Y** end (the barrel nub), so J2–J5 at rot 0 have the
  barrel overhanging the rear edge and J6 at rot 180 has it overhanging the
  front edge, openings facing out. Left as-is.
- **C24 1 µF → 10 µF** (electrolytic, C43799): POR pulse ~4 ms → ~40 ms, so a
  slow VBUS ramp still guarantees mic-muted at power-on. Netlist unchanged.
- **MH5/MH6 added** ~12 mm behind the front edge to stiffen the pot-knob edge.
- **CD4043B pinout confirmed** against the TI datasheet (1Q–4Q = 2,9,10,1;
  1R–4R = 3,7,11,15; 1S–4S = 4,6,12,14; OE = 5; NC = 13) — the project-local
  symbol is correct.
- Re-routed: 848 seg / 35 vias, 0 unconnected, 0 SMD pads.

### rev-8 (2026-09-03) — sourcing, footprints, front-edge controls
- **Full JLCPCB stock audit.** Every BOM LCSC code was re-checked; the ones on
  the old "verify" list all pointed at the wrong part (SMD or a different
  component) or were out of stock. All fixed — **every rev-8 part is in stock,
  min-order 1, with a ready LCEDA footprint + 3D model**. See CHANGELOG rev-8
  and `v1-vs-v2.md` §2/§3 for the table. Highlights: D1→C152132, U1→C5184871,
  U3→C5213, U4→C22390239 (CD4043BE lingxingic), 100nF→C2167231, 3k3→C119335,
  100µF→C346930, 47R→C3373549 (47.5Ω), F1→C76399 (RXEF050).
- **J2–J6 → Korean Hroparts PJ-3200B-4A** (C136687), 4-conductor TRRS, 100% THT.
  New local footprint `Jack_3.5mm_PJ-3200B-4A_Horizontal` built from the HRO
  datasheet (pin map T=2/R1=4/R2=3/S=1 confirmed vs the datasheet schematic +
  the KiCad PJ320E pad pattern). The v1-vs-v2 "PJ-320E" plan is superseded —
  no HTC PJ-320-series THT jack is in JLC's assembly stock.
- **SW2–SW5 → C&K PTS645VK392LFS** right-angle THT tact (C285519), plunger out
  the front edge (`SW_Tactile_SPST_Angled_PTS645Vx39-2LFS`, rot 180).
- **Enclosure: top + bottom acrylic only, sides open** (no front panel). Front
  controls re-placed so the can body is ~flush with the open edge: RV1–RV5 at
  y=FRONT-5.5 (RK097 can ~0.5 mm inside the edge, ~20 mm shaft overhang);
  SW2–SW5 at y=FRONT-3 (plunger ~1 mm past the edge).
- **CPL rotation corrected per footprint** against JLC's LCEDA library parts
  (DIP/relay/jack 270° off, RK097 pot + PTS645 tact 180° off — the LCEDA
  footprints draw body/actuator on the opposite side of the pins). `bomcpl.py`
  applies `FP_ROT_OFFSET`.
- New `hardware/BOM/BOM-JLC-MeetingHub-4-v2.csv` — native JLC format
  (`Comment,Designator,Footprint,JLCPCB Part #`); upload this one for assembly.
- Re-routed: **850 seg / 30 vias, 0 unconnected, 0 SMD pads**, DRC unchanged
  (8 J1-internal + 5 silk). Netlist connectivity node-identical to rev-7.
- Board is **192 × 156 mm, R6 corners, 6× M3** (the rev-2 "286 × 157 / 4× M3"
  note below is stale).

### rev-9 (2026-09-03) — de-selected-laptop mic hold-up (SCH-P)

Validation §P: as-built, switching the mic away from a laptop left its mic-jack
sleeve **open** = "no microphone" to a Windows codec → risk of the endpoint being
dropped and the app falling back to the internal mic.

- **K1–K4 contacts re-wired:** COM 5/6 → `NBn_MIC`, NO 10 → `HEADSET_MIC`
  (commoned), NC 1 → **R39–R42 (2.2 kΩ) → GND**. A de-selected laptop now sees
  2.2 kΩ (≈ idle electret, 1.25 V on the sleeve) → codec keeps the mic endpoint,
  far end hears silence. Coil / D2–D5 side unchanged.
- **+4 parts:** R39–R42, 2.2 kΩ 1/4 W axial THT, YAGEO CFR-25JB-52-2K2, LCSC
  **C1364486**. BOM 117 → **121**.
- Re-routed (Freerouting `--random 0`): **902 seg / 35 vias, 0 unconnected, 0 SMD
  pads**, DRC unchanged (8 J1-internal + 5 silk). Board still 192 × 156 mm.
- Full sim suite re-run, **all reproduces** (`v2-simulation-validation.md` §P now
  "applied"; `bom_selector.cir` updated for the swap — one-hot routing unchanged).
- **Still bench-verify the OS behaviour on the target laptops** (codec firmware).

### rev-10 (2026-09-04) — headphone drive level, FABRICATION AUTHORIZED
- **R16 / R20: 47 Ω → 10 Ω** (sim finding 1). They sit outside the U2A loop, so
  into 32 Ω the old 47 Ω made a 0.4 divider → 0.27× / 0.22 mW. 10 Ω → 0.50× /
  ~0.7 mW / +5.5 dB. Same footprint, same pads/position/rotation, **netlist
  byte-identical, no re-route** — gerbers/drill/CPL unchanged, only the
  schematic PDF + 3 BOMs. R38 (VBIAS isolation) stays 47 Ω.
  Part: **UNI-ROYAL MFR0W4F100JA50 = LCSC C57437** — 10 Ω 1/4 W metal film ±1%
  ±50 ppm, D2.2×6.5 mm, ~10 800 in JLC stock (restores the metal-film ±1% tier
  the 47R5 it replaces had). Alt: Yageo MFR-25JT-52-10R (C176452).
- **Both sim engines re-run:** MNA §A–§G **21/21** (was 20/21), §M 6/6, §E 8/8,
  §O < 80 µV, §P 1.25 V — all reproduce. See CHANGELOG rev-10 +
  `v2-simulation-validation.md`.
- **Authorized for fabrication** subject to the 3 bench items below (Alps pot
  convention, 10 Ω LCSC code, de-selected-mic OS check).

### Open items / limitations (not blocking)
1. **No runtime "none selected".** Once a laptop is chosen the mic stays on it
   until power-cycle or a deliberate 2-button press. Accepted trade-off for
   having no mute button. SCH-010 §3.5 adds a 5th "mute/reset" button if wanted.
2. **High-Z headphones (>150 Ω)** are still quieter — raise R3/R4 to 4k7 if the
   box will drive studio headphones (not the conference-headset use case).
3. **Board 192 × 156 mm** — the SELECT_LOGIC block can still be tightened.
4. **Silkscreen** ref designators overlap on dense clusters (cosmetic DRC
   warnings) — reposition/scale in the KiCad GUI before fab.
5. **Pot direction rests on the RK097 T1 = full-CCW / T3 = full-CW convention.**
   Confirm on the first article (full-CCW → wiper↔T1 ≈ 0 Ω).
6. **J1 footprint** trips 8 clearance DRC — `.kicad_dru` documents it; passes
   in the GUI at the 0.15 mm netclass.
7. **2N7000 symbol** is project-local — sanity-check the TO-92 pinout (S-G-D =
   1-2-3) on first bring-up.

## 7. Bring-up checklist (bench, then 1 laptop, then 4)

1. Power via USB-C. Measure `TP1` = 5.0 V, `VBIAS` = 2.50 V, `VBIAS_REF` ≈
   2.50 V. No relay should click. No IC hot.
2. Press NB1: K1 clicks. `NB1_MIC`↔`HEADSET_MIC` continuity; NB2/3/4 open.
   Press NB2: K1 releases, K2 clicks. Press NB2+NB3: all release.
3. One laptop on J2, headset on J6. Play audio → adjust RV1 and RV5, CW = louder.
   Join a call → NB1 selected → the laptop hears the headset mic.
4. Four laptops on J2–J5. Confirm all four are audible together, each RV1–RV2
   independent, RV5 master. Mic follows the last button pressed, one at a time.

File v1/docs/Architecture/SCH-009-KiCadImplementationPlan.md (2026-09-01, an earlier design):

# Next Step: Create the KiCad Project

Enter the directory:

```bash
cd ~/MeetingHub-4/hardware/KiCad
```

Create the folder:

```bash
mkdir MeetingHub-4
cd MeetingHub-4
```

Open KiCad and create the project:

Name:

```text
MeetingHub-4
```

Location:

```text
~/MeetingHub-4/hardware/KiCad/MeetingHub-4-v1/
```

---

After it's created, your tree should look similar to:

```text
hardware
└── KiCad
    └── MeetingHub-4
        ├── MeetingHub-4-v1.kicad_pro
        ├── MeetingHub-4-v1.kicad_sch
        └── MeetingHub-4-v1.kicad_pcb
```

---

# First Schematic Sheet

Let's start with the power supply.

In KiCad we will create:

```
Sheet: Power Supply
```

Initial components:

| Reference | Component | Function |
| --- | --- | --- |
| J1 | USB-C | 5V input |
| F1 | Resettable fuse | Protection  |
| D1 | TVS/Protection | Surge |
| C1 | 100nF | Filter |
| C2 | 10uF | Reserve |
| J2 | Test Point | Measurement |

Buses:

```
+5V_USB
    |
    |
Protection
    |
    |
+5V_AUDIO
    |
    |
Circuits
```

---

# Before Placing Components

An important decision:

In your case, I **would not use USB-C with PD negotiation**.

We will use USB-C only as a power input:

* VBUS = 5V
* GND = return

Reason:

* simpler;
* cheaper;
* fewer points of failure.

---

# Next Step in KiCad

When you open the schematic:

1. Create a hierarchical sheet called:

```
POWER
```

2. Place the first symbol:

```
USB_C_Receptacle_USB2.0_16P
```

3. Then we will do the protection.

---

When you create the KiCad project, just send me the result of:

```bash
tree hardware/KiCad
```

or a screenshot of KiCad.

Then we'll proceed component by component. Now we begin the real construction of the MeetingHub-4. 🔧

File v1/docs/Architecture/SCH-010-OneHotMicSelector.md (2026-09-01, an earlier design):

# SCH-010 — Seleção exclusiva de microfone (one-hot, só hardware)

Versão: 1.0 · Data: 2026-08-28
Opção **C2** decidida com o usuário: botões **momentâneos** (sem trava mecânica)
+ **trava eletrônica** feita com um CD4043 e uma matriz de diodos. Comportamento
de KVM: aperto NB2 → NB2 liga e o que estava selecionado **desarma sozinho**.

Serve tanto para reworkar a placa fabricada (`b86a034`) quanto para o respin.

> **IMPORTANTE:** na placa fabricada **não existe footprint** para o CD4043 nem
> para os MOSFETs — e nem precisa. Todo esse circuito é montado numa
> **plaquinha separada** (perfboard ~5×7 cm) que fica **solta dentro da caixa**
> e se liga à placa principal por ~12 fios (§5). Na placa principal só se faz
> corte de trilha, jumper e levantar pino — **nenhum componente novo é soldado
> nela**.
>
> Se você não quer plaquinha nenhuma, veja as opções **sem eletrônica** no
> REWORK-001 Parte D (chave rotativa, ou régua de botões intertravados).

---

## 1. Comportamento

- 4 botões momentâneos, um por notebook (NB1..NB4 = relés K1..K4).
- Apertar o botão X: **liga K_X e desliga os outros 3.**
- Soltar o botão: o estado **fica** (trava eletrônica).
- Ligar a placa: **nenhum** selecionado → microfone não vai a ninguém = mudo.
- Apertar 2 ao mesmo tempo: enquanto os dois estão apertados, **ambos ficam
  desligados**; ao soltar, vence o **último a ser solto** (na prática, imite
  não apertar dois de propósito).
- Bounce de contato: imune (o latch RS re-afirma o mesmo estado).

---

## 2. Princípio — CD4043B (quad latch RS tipo NOR) + matriz de diodos

Um latch RS por canal. Latch tipo NOR:

| S | R | Q |
|---|---|---|
| 0 | 0 | mantém |
| 1 | 0 | 1 |
| 0 | 1 | 0 |
| 1 | 1 | 0 |

**Regra da matriz:** o botão X leva +5 V para **`S_X`** e para **`R`** dos
outros três. Nunca leva S e R do mesmo latch → sem conflito.

- Botão X apertado → `S_X=1,R_X=0` → `Q_X=1`; nos outros `S=0,R=1` → `Q=0`.
- Botão solto → todas as linhas S/R caem (pull-down) → todos os latches mantêm.

### Pinagem do CD4043BE (DIP-16, vista de cima)

```
        ┌────┬─┬────┐
  Q4  1 ┤    └─┘    ├ 16  VDD (+5V)
  Q1  2 ┤           ├ 15  R4
  R1  3 ┤           ├ 14  S4
  S1  4 ┤  CD4043B  ├ 13  NC
ENABLE 5├┤           ├ 12  S3
  S2  6 ┤           ├ 11  R3
  R2  7 ┤           ├ 10  Q3
 VSS  8 ┤           ├  9  Q2
        └───────────┘
```

- **VDD (16) → +5 V**, **VSS (8) → GND**, **ENABLE (5) → +5 V** (liga as saídas).
- 100 nF entre 16 e 8, colado no CI.
- Latch A (NB1): S1=4, R1=3, Q1=2
- Latch B (NB2): S2=6, R2=7, Q2=9
- Latch C (NB3): S3=12, R3=11, Q3=10
- Latch D (NB4): S4=14, R4=15, Q4=1

---

## 3. Esquema

### 3.1 Entrada de botão + matriz de diodos (todos os diodos = 1N4148)

```
 +5V ─┬─[BTN1]─┬─►|─ S1        (►| = 1N4148, anodo no botão, catodo na linha)
      │        ├─►|─ R2
      │        ├─►|─ R3
      │        └─►|─ R4
      │
      ├─[BTN2]─┬─►|─ S2
      │        ├─►|─ R1
      │        ├─►|─ R3
      │        └─►|─ R4
      │
      ├─[BTN3]─┬─►|─ S3
      │        ├─►|─ R1
      │        ├─►|─ R2
      │        └─►|─ R4
      │
      └─[BTN4]─┬─►|─ S4
               ├─►|─ R1
               ├─►|─ R2
               └─►|─ R3

 S1,S2,S3,S4 ── cada uma: 100k → GND
 R1,R2,R3,R4 ── cada uma: 100k → GND
```

16 diodos de matriz. `BTNn` = botão momentâneo NA (normalmente aberto), um lado
no +5 V.

### 3.2 Reset ao ligar (power-on = mudo)

```
 +5V ──┤ 1µF ├──┬──►|─ R1
                ├──►|─ R2
                ├──►|─ R3
                ├──►|─ R4
                │
               100k
                │
               GND
```

No instante que liga, o degrau de +5 V passa pelo capacitor → as 4 linhas R
sobem por ~20 ms → todos os `Q=0` → nenhum relé → mudo. Depois o nó cai a 0 V
e os diodos ficam reversos. (4 diodos + 1µF + 100k.)

### 3.3 Driver de bobina — 1 por canal (Q → MOSFET → bobina)

```
        +5V
         │
     ┌───┴───┐              Dx (1N4148)
     │ bobina│  pino 2 ──┬──────|◄──┐   (catodo p/ +5V)
     │  K_n  │           │          │
     └───┬───┘  pino 9 ──┴──────────┴──┬─── dreno
         │                             │
       (contatos: COM=5/6, NO=10, NC=1)│
                                     [2N7000]
                                       │ fonte
                                      GND

  Q_n ──[470Ω]──┬── gate
                │
              100k
                │
               GND
```

- `Q_n = 1` → MOSFET conduz → puxa o pino 9 da bobina para GND → **relé liga**.
- `Q_n = 0` → MOSFET corta → bobina desenergiza; `Dx` corta o pico indutivo.
- **A bobina do relé passa a ficar entre +5 V (pino 2) e o MOSFET (pino 9).**
  `Dx` (o antigo D2–D5) fica em paralelo com a bobina, **catodo para o lado do
  pino 2 (+5 V)**.
- Só **1 relé ligado por vez** → consumo ~30 mA (não 120 mA). Folgado no F1.

### 3.4 (Opcional) LED indicador por canal

```
 Q_n ──[2k2]──►|──(LED)── GND
```
Acende fraco (~1 mA) mas visível. 4 LED + 4 × 2k2.

### 3.5 (Opcional) botão MUTE / OFF

Um 5º botão momentâneo que **reseta todos os latches**:

```
 +5V ──[BTN_MUTE]─┬─►|─ R1
                  ├─►|─ R2
                  ├─►|─ R3
                  └─►|─ R4
```
+4 diodos. Apertar → todos `Q=0` → todos os relés soltam → COM fica no NC
(aberto) → microfone não vai a ninguém = mudo.

---

## 4. Lista de materiais (placa auxiliar)

| Qtd | Item | Obs |
|---|---|---|
| 1 | **CD4043BE** DIP-16 + soquete | quad latch RS NOR, 3-state |
| 1 | 100 nF cerâmico | desacople VDD |
| 16 (+4 se MUTE) | 1N4148 | matriz de diodos |
| 4 | 1N4148 | reset de power-on |
| 8 | resistor 100 k | pull-down de S1–S4, R1–R4 |
| 1 | capacitor 1 µF | reset de power-on |
| 1 | resistor 100 k | reset de power-on |
| 4 | **2N7000** (ou 2N7002 SMD) | driver de bobina (N-MOSFET nível lógico) |
| 4 | resistor 470 Ω a 1 k | série no gate (não é crítico; 1 k serve) |
| 4 | resistor 100 k | pull-down de gate |
| 1 | capacitor 100 µF / ≥10 V | bulk de +5 V na placa auxiliar |
| — | 4 (ou 5) botões táteis momentâneos NA | pode reusar SW2–SW5 da placa |
| — | perfboard ~5×7 cm, fio fino | |
| 4 | LED + 4 × 2k2 | *opcional*, indicador |

Diodos D2–D5 **continuam na placa principal** como roda-livre (reorientados —
ver §5).

### 4.1 Compra — para reparar 1 placa (5 placas entre parênteses)

**Peças que TÊM que ser exatamente essas (LCSC — códigos conferidos):**

| Item | LCSC | Link | Qtd |
|---|---|---|---|
| **CD4043BE** DIP-16 (TI) | **C39537** | https://www.lcsc.com/product-detail/C39537.html | 1 (5) |
| — ou clone mais barato | C22390239 | https://www.lcsc.com/product-detail/C22390239.html | |
| **2N7000** N-MOSFET TO-92 | **C9114** | https://www.lcsc.com/product-detail/C9114.html | 4 (20) |
| **1N4148** DO-35 THT (o mesmo dos D2–D5) | **C402212** | https://www.lcsc.com/product-detail/C402212.html | 20 · +4 se MUTE (120) |

**Passivos genéricos — reaproveite os códigos que já estão na BOM do projeto:**

| Item | LCSC (já na BOM-003) | Qtd |
|---|---|---|
| Resistor 100 k 1/4 W THT (= R13/R17) — 8 pull-down S/R + 4 pull-down gate + 1 power-on | **C1364475** | 13 (70) |
| Resistor 1 k 1/4 W THT (= R14/R15…) — série no gate do MOSFET | **C120055** | 4 (20) |
| Capacitor 1 µF THT X7R (= C5–C14) — serve no reset de power-on | **C2167638** | 1 (5) |

**Passivos comuns — de kit ou loja local (não vale a pena link específico):**

| Item | Qtd |
|---|---|
| Soquete DIP-16 (2,54 mm) | 1 (5) |
| Capacitor 100 nF cerâmico THT (desacople do CI) | 1 (5) |
| Capacitor 100 µF / ≥16 V eletrolítico THT (bulk +5 V) | 1 (5) |
| *(opcional)* LED 3 mm difuso + resistor 2k2 1/4 W THT | 4 + 4 (20 + 20) |
| Perfboard ~5×7 cm + fio fino | 1 (5) |

> Um **kit sortido de resistores 1/4 W THT** + um **kit de capacitores cerâmicos
> THT** cobrem os genéricos e sobra muito.
>
> **NÃO precisa comprar:** relés K1–K4, diodos D2–D5 (ficam na placa),
> potenciômetros, botões seletores (reusa SW2–SW5). O SW1 só leva uma ponte de
> solda.

---

## 5. Ligação à placa fabricada (`b86a034`) — junto com o conserto do microfone

> Este procedimento **substitui** a Parte A + Parte D do REWORK-001 (faz o
> conserto do mic e a seleção one-hot de uma vez). Faça **1 canal (K1) primeiro**
> e teste.

### 5.1 Por relé (K1..K4) + diodo (D2..D5)

1. **Levante os pinos 1, 2, 9 e 10** do relé (deixe 5 e 6 soldados + um ponto de
   cola quente para segurar).
2. Ligações novas nos pinos levantados:
   - **pino 2 → barramento +5 V** (fio novo — ver §5.2).
   - **pino 9 → saída de dreno do MOSFET** do canal (fio até a placa auxiliar).
   - **pino 10 → furo 9** (o furo que ficou vazio, que tem a trilha `NBx_MIC`).
   - **pino 1 → nada** (isolado).
3. **Diodo Dx (D2→K1, D3→K2, D4→K3, D5→K4):** dessolde e ressolde **em paralelo
   com a bobina, entre os pinos 2 e 9 do relé**, com a **faixa (catodo) para o
   lado do pino 2 (+5 V)**. Se ficar mais fácil, solde-o direto nas pernas
   levantadas 2 e 9.

### 5.2 Barramento +5 V para as bobinas

Um fio ligando **pino 2 de K1, K2, K3, K4** entre si e a um ponto de +5 V:
**TP1** (`+5V_AUDIO`, ~(215,1 , 101,8)) ou o pino 2 de F1 (~(165,6 , 106,2)).

### 5.3 Botões

Reusando **SW2–SW5** (já são momentâneos e já têm +5 V no pad 1):

1. Em cada SW, **corte a trilha do pad 2** (o pad de trás, ~(95,6 , 212,0) etc.)
   para soltá-lo do relé.
2. Fio: **SW2 pad 2 → BTN1** da matriz · SW3 pad 2 → BTN2 · SW4 pad 2 → BTN3 ·
   SW5 pad 2 → BTN4.  (o pad 1 continua no +5 V; apertar leva +5 V ao pad 2 → à
   matriz.)

### 5.4 MUTE (SW1)

Você já autorizou tirar o mudo dedicado. Duas opções:

- **Sem botão de mudo:** ponte de solda ligando os 2 furos com trilha do SW1
  (`HEADSET_MIC` ↔ furo dos COM dos relés). O microfone sempre chega aos relés;
  "mudo" = nenhum botão apertado desde que ligou (ou aperte o botão do canal
  atual… não, isso não desliga — então nesse modo, uma vez selecionado, sempre
  há um ativo).
- **Com botão de mudo (recomendado):** dê a ponte no SW1 (mic passa direto) e
  **adicione um 5º botão** (novo, no painel) ligado a `BTN_MUTE` (§3.5).
  Apertar = volta ao mudo.

### 5.5 Alimentação da placa auxiliar

`+5 V` e `GND` da placa principal (TP1 / qualquer GND). 100 µF de bulk na
entrada da placa auxiliar.

### 5.6 Conferência (multímetro / bancada)

1. Ligar: nenhum LED / nenhum relé clicado. Multímetro em `NBx_MIC`: sem
   continuidade com o headset. **Mudo.** ✔
2. Apertar BTN2 (NB2): K2 clica, LED2 acende. `NB2_MIC` ↔ headset com
   continuidade; `NB1/3/4_MIC` não. ✔
3. Apertar BTN4: K2 solta, K4 clica. Só NB4 ativo. ✔
4. Apertar BTN2 e BTN3 juntos: nenhum fica ligado. ✔
5. (Se tiver MUTE) apertar MUTE: todos soltam. ✔

---

## 6. Para o respin (KiCad)

Nova folha `SELECT_LOGIC.kicad_sch`:

- `U3 = CD4043B` (símbolo `4xxx:CD4043B`), footprint SOIC-16 ou DIP-16.
- Matriz de 16 (ou 20) diodos `D_Small` + 8 pull-downs 100 k.
- RC de power-on-reset (1 µF + 100 k + 4 diodos).
- 4 × `Q_ATtiny`… não — 4 × `2N7000` + 470 Ω + 100 k.
- SW2–SW5 continuam `Switch:SW_SPST` (momentâneos), mas o pad "sinal" vai à
  matriz, não mais direto ao relé.
- Relés K1–K4: **pino 2 → +5V_AUDIO**, **pino 9 → dreno do MOSFET do canal**,
  pino 10 → `NBx_MIC`, pino 1 NC, COM 5/6 → `HEADSET_MIC`.
- D2–D5: catodo → +5V (pino 2), anodo → pino 9.
- SW1 removido (ou vira `BTN_MUTE` → 4 diodos → R1..R4). LEDs opcionais.
- No PCB: a placa toda passa a caber melhor porque some o barramento de +5 V
  chaveado pelos botões (agora os botões são sinal lógico, corrente ~0).

> Isto é uma folha nova inteira — quando você decidir fechar o respin, eu monto
> o `.kicad_sch` dessa lógica e ligo aos sinais existentes.

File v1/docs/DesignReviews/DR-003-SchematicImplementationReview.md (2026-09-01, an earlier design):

# DR-003 - Schematic Implementation Review

Version: 1.0
Status: Review

# 1. Objective

Document what was actually implemented and validated during the construction
of the MeetingHub-4 KiCad schematic (SCH-001 to SCH-009), and make explicit
what this validation covers and what it does **not** cover, to guide the
full technical review before manufacturing.

# 2. What was built

The project was organized into five hierarchical sheets in
`hardware/KiCad/MeetingHub-4-v1/`:

## POWER (POWER.kicad_sch)

- Power supply USB-C connector (J1)
- Protection fuse (F1, 500mA)
- Protection TVS diode (D1)
- +5V_AUDIO power supply filtering (C1/C2)
- Test point (TP1)

**Note:** this sheet **does not have a voltage regulator**. The
`+5V_AUDIO` power supply corresponds to the USB-C VBUS, protected and
filtered, without active regulation.

## TRRS_INPUTS (TRRS.kicad_sch)

- Four TRRS connectors for the laptops (J2-J5)
- Distribution of the audio signals coming from the laptops

## AUDIO_MIXER (MIXER.kicad_sch)

- Individual channel adjustment potentiometers (RV1-RV4) + master (RV5)
- **Active** stereo mixer based on an NE5532 operational amplifier (U1)
- Summing feedback network
- Generation of the **VBIAS** reference by a resistive divider (10 kΩ / 10 kΩ)
  with a decoupling capacitor

**Note:** VBIAS is used as the half-supply reference for the operational
amplifiers (U1 and U2). It does **not** supply bias to the microphones,
which continue to use the power supplied by the laptop, in accordance with
the transparency requirements of SCH-004/SCH-007.

## HEADPHONE_AMP (HPAMP.kicad_sch)

- Headphone amplifier based on the NJM4556A (U2)
- Input/output coupling via capacitor
- Power supply decoupling
- Operator headset TRRS connector (J6)

## MIC_SWITCHING (MICSW.kicad_sch)

- Mute switch (SW1)
- Four Omron G5V-1 relays (K1-K4)
- Flyback diodes (D2-D5)
- Individual selection of the four microphones
- JST-XH connectors for external buttons (SW1-SW5)

In the end, the project contains **66 components**, all with footprints
assigned (except global power symbols). BOM generated at
`hardware/BOM/BOM-MeetingHub-4-v1.csv` and schematic PDF at
`hardware/Schematics/MeetingHub-4-v1-Schematic.pdf`.

# 3. Block diagrams

A single mixed-topology diagram tends to confuse power supply with signal.
For this reason, three separate diagrams are used:

## 3.1 Power supply distribution

```text
USB-C (J1)
   │
 POWER
   │ +5V_AUDIO
   ├──► AUDIO_MIXER    (U1 NE5532)
   ├──► HEADPHONE_AMP  (U2 NJM4556A)
   └──► MIC_SWITCHING  (K1-K4 relay coils, via SW2-SW5)
```

## 3.2 Audio path (Laptop -> Headset)

```text
TRRS_INPUTS                 AUDIO_MIXER                HEADPHONE_AMP
J2 NB1_L/R ──┐
J3 NB2_L/R ──┤   individual        active sum      MIX_L/R    gain      J6
J4 NB3_L/R ──┼──► volume ──────► (U1) ──────────────────────► (U2) ──► Headset
J5 NB4_L/R ──┘   (RV1-RV4)                                             (L/R)
```

## 3.3 Microphone path (Headset -> Selected laptop)

```text
Headset (J6, sleeve)
   │ HEADSET_MIC
 MIC_SWITCHING (SW1 mute + K1-K4 selection)
   │
   ├──► NB1_MIC ──► J2 (TRRS_INPUTS)
   ├──► NB2_MIC ──► J3
   ├──► NB3_MIC ──► J4
   └──► NB4_MIC ──► J5      (only one relay should be energized at a time)
```

# 4. What was validated, and how

- **Structural connectivity**: `kicad-cli sch export netlist` run
  repeatedly (multiple times, deterministically) on the complete project,
  with no error. The named nets (`+5V_AUDIO`, `VBIAS`, `NB1-4_L/R/MIC`,
  `MIX_L/R`, `HEADSET_MIC`, `GND`) appear correctly in the exported
  netlist, connecting the 5 sheets to each other as expected.
- **Visual rendering**: `kicad-cli sch export pdf` generated and inspected
  page by page (all 6 pages), confirming that the components appear on
  the correct sheets with the expected labels.
- **Footprints**: a post-processing script verified that 100% of the
  components (except GND symbols, which do not use a footprint) have a
  non-empty footprint assigned.

**This is equivalent to a structural integrity check of the file, not an
ERC.** None of these checks replace the full KiCad ERC (pin type
conflicts, floating input, unpowered power pin, etc.), which only runs
through the graphical interface in this version of `kicad-cli` (7.0.11 -
the `sch erc` and `pcb drc` subcommands only exist starting from KiCad 8).

# 5. Important limitation of the review

The validation above was performed **on the complete project** (all 5
sheets + root), not on isolated fragments. Even so, the review was
predominantly automated (parsing/export via `kicad-cli`) and visual
(inspection of the rendered PDF). It does not replace:

- a full ERC in the KiCad graphical interface;
- manual review, sheet by sheet, of each junction/label against the
  electrical intent (especially the microphone line and grounding);
- review of gain, impedance, and noise values by someone who can
  simulate or physically bench-test the circuit.

# 6. Technical decisions made during implementation

Points that require human confirmation before routing the PCB:

- **VBIAS**: generated by a passive resistive divider (10k/10k + 10uF),
  without an active buffer. This works because the op-amp input
  impedance is high, but it is the simplest possible choice - if
  audible background noise is present in the prototype, this is the
  first point to review (replace with a dedicated active buffer).
- **Gains**: summing mixer with unity gain per source (Rf = Rin = 10k);
  headphone stage with gain of ~2x (Rf/Rg = 1k/1k). These have not been
  validated against actual laptop output levels or against the
  sensitivity of 16-64 ohm headphones - reasonable starting values, not
  calibrated.
- **Microphone selection**: implemented with manual SPST switches
  (SW2-SW5) feeding each relay coil independently. There is no
  electrical interlock - it is the end user's responsibility to
  activate only one selection at a time, as already specified in
  SCH-007.
- **kicad-cli bug workaround**: symbols with `(extends "Base")` (e.g.
  NE5532/NJM4556A derived from LM2904, TVS derived from ZPYxx) and
  cached symbol names without the library prefix caused a deterministic
  segfault in `kicad-cli sch export netlist` (KiCad 7.0.11). The symbols
  were embedded using the base symbol directly with the Value field
  overridden, and the cached names were prefixed (`Device:R`,
  `Diode:ZPYxx`, etc.). This is only a file/tool quirk - it does not
  affect the electrical design, but it is recorded here in case another
  symbol with `extends` is added in the future.

# 7. Pending items before manufacturing

Confirmed in this review, still open:

- Full ERC via KiCad (GUI).
- PCB layout (placement of jacks/potentiometers/relays, audio vs. power
  supply separation, ground plane) and DRC from the chosen manufacturer.
- Mechanical review of pinout/footprint against the datasheets of the
  parts actually purchased: USB-C, TRRS jacks (PJ320D), G5V-1, dual
  potentiometers (RK097).
- Dimensional check against the enclosure.
- Generation of Gerbers, drill files (Excellon), final BOM, and Pick &
  Place (if automated assembly is used).
- Full manual technical review (power supply, analog grounding,
  audio levels/impedance, relays, USB-C, op-amps, mixer, microphone
  selection, possible ground loops) before generating the manufacturing
  files.

# 8. Status

Schematic structurally valid and ready for the PCB layout stage.
Not approved for manufacturing - depends on the pending items in section 7.

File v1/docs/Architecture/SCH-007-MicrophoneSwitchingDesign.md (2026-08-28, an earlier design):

# SCH-007 - Microphone Switching Design

Version: 0.1
Status: Draft

# 1. Objective

Define the circuit responsible for routing the headset microphone to one of the four laptops.

# 2. Main Requirement

The microphone line must remain electrically transparent.

The laptop must see:

```

Laptop

```
|
```

Headset MIC

```

with no significant difference compared to a direct connection.

# 3. Constraints

Do not use:

- microphone amplifier;
- digital converter;
- processing;
- alteration of microphone bias/polarization.

# 4. Architecture

Flow:

```

Headset MIC

```
  |

 MUTE

  |
```

MIC Selection

```
  |
```

+-----+-----+-----+-----+

|     |     |     |     |

NB1   NB2   NB3   NB4

```

# 5. Switching Method

Initial method:

Signal relays.

Desired characteristics:

- low contact resistance;
- gold-plated contact;
- low capacitance;
- long service life.

# 6. Operation

Only one laptop must receive the microphone at a time.

States:

```

Selected:
NB1
NB2
NB3
NB4

or

None (MUTE)

```

# 7. MUTE

Mute must interrupt the microphone line.

Characteristics:

- physical action;
- immediate response;
- no software.

Implementation (2026-08-28): with **latching** selector buttons (PS-22F03),
"no selector engaged" leaves every relay de-energised, so COM rests on the
open NC contact and the microphone reaches no laptop. That is the mute — a
separate MUTE switch (SW1) was removed. Selecting a laptop un-mutes; the
selectors are not interlocked, so engaging two routes the mic to two laptops
(user responsibility, as in section 6).

# 8. Considerations

The circuit must be validated with different laptops due to variations in headset detection implementation.

# 9. Required Tests

Validate:

- headset recognition;
- microphone operation;
- switching between laptops;
- absence of noise;
- absence of interference.
```

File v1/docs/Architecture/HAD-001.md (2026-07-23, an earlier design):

# MeetingHub-4
# Hardware Architecture Document (HAD-001)

Version: 1.0
Status: Final — architecture implemented and validated in hardware

# 1. Overview

MeetingHub-4 is an analog device intended to manage audio for four laptops using TRRS CTIA headset connections.

The device shall:

- receive audio from four laptops;
- mix the signals in stereo;
- provide monitoring through a single headset;
- route the headset microphone to only one selected laptop.

# 2. General Architecture
Laptop 1 ─┐
Laptop 2 ─┤
Laptop 3 ─┤
Laptop 4 ─┘
|
v
TRRS CTIA Input
|
v
Individual volume control
|
v
Active stereo mixer
|
v
Master Volume
|
v
Headphone amplifier
|
v
Headset

Headset Microphone
|
v
MUTE
|
v
Laptop selection
|
v
Selected laptop

# 3. Design Philosophy

The device shall be transparent to the laptops.

The computer must interpret the device as a directly connected TRRS CTIA headset.

The following will not be used:

- drivers;
- USB audio communication;
- digital processing.

# 4. Subsystems

## 4.1 TRRS Input

Each laptop will be connected through a metallic panel-mount P2 TRRS CTIA connector.

Signals:

- Tip       = Left Audio
- Ring 1    = Right Audio
- Ring 2    = Ground
- Sleeve    = Microphone

## 4.2 Audio System

Architecture:

- active stereo mixer;
- individual volume control;
- master control;
- dedicated headset amplifier.

## 4.3 Microphone System

Requirements:

- preservation of the microphone bias voltage provided by the laptop;
- transparent switching;
- absence of active electronics on the microphone line.

Initial solution:

- switching via signal relays;
- normally open contact;
- low contact resistance;
- no active components between headset and laptop.

## 4.4 Power Supply

Input:

USB-C 5V.

The power supply will be isolated from the laptop's audio line.

The circuit shall prevent noise from returning to the TRRS inputs.

It will power:

- active mixer;
- headphone amplifier;
- control circuit.

# 5. Noise Considerations

The design shall take into account:

- star grounding;
- separation between audio and power supply;
- power supply filters;
- interference protection.

# 6. Main Components (provisional)

Mixer:
- Audio operational amplifier

Headphone amplifier:
- Dedicated IC

Microphone:
- Signal relays

Connectors:
- Metallic P2 TRRS connectors

# 7. Next Steps

After approval of this document:

1. Component selection.
2. Schematic development.
3. Electrical review.
4. PCB development.
5. Prototype.
6. Testing.

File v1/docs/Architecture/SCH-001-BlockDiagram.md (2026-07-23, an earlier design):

# SCH-001 - Electrical Block Diagram

Version: 0.1  
Status: Draft

---

# 1. Objective

This document describes the functional block diagram of the MeetingHub-4 hardware.

The objective is to define the electrical architecture before developing the detailed schematic.

---

# 2. Overview

MeetingHub-4 is an analog device that allows connecting four laptops simultaneously using TRRS CTIA headset interfaces.

Main functions:

- receive audio from four laptops;
- mix the audio signals in stereo;
- provide monitoring on a single headset;
- select which laptop will receive the microphone signal;
- maintain native compatibility with the laptops' headset detection.

---

# 3. General Diagram

```text
                 AUDIO

+------------+
| Laptop 1   |
+------------+
      |
      |
+------------+
| Laptop 2   |
+------------+
      |
      |
+------------+
| Laptop 3   |
+------------+
      |
      |
+------------+
| Laptop 4   |
+------------+
      |
      |
      v

+---------------------------+
| TRRS CTIA Inputs          |
| L / R / MIC Separation    |
+---------------------------+

      |
      |
      v

+---------------------------+
| Individual Volume Control |
| VOL1 VOL2 VOL3 VOL4       |
+---------------------------+

      |
      |
      v

+---------------------------+
| Active Stereo Mixer       |
| L Channel + R Channel     |
+---------------------------+

      |
      |
      v

+---------------------------+
| Master Volume             |
+---------------------------+

      |
      |
      v

+---------------------------+
| Headphone Amplifier       |
+---------------------------+

      |
      |
      v

+---------------------------+
| Headset TRRS CTIA         |
+---------------------------+
````

---

# 4. Microphone Path

The microphone path shall remain transparent to the laptop.

No active processing will be used on the microphone line.

```text
+----------------+
| Headset MIC    |
+----------------+
        |
        |
        v

+----------------+
| MUTE           |
+----------------+
        |
        |
        v

+----------------+
| MIC Selection  |
| Laptop 1-4     |
+----------------+
        |
        |
        v

+----------------+
| Selected       |
| Laptop         |
+----------------+
```

---

# 5. Microphone Selection

Microphone selection will be performed via signal switching.

Requirements:

* low contact resistance;
* minimal interference;
* preservation of the microphone bias voltage;
* reliable operation under heavy use.

Initial solution:

* high-durability signal relays.

---

# 6. Power Supply

External source:

```text
USB-C 5V

     |
     v

+----------------+
| Protection     |
+----------------+

     |
     v

+----------------+
| Filtering      |
+----------------+

     |
     v

+----------------+
| Audio Circuits |
| Power Supply   |
+----------------+
```

---

# 7. Grounding

The design will use a star grounding strategy.

Objectives:

* minimize noise;
* reduce ground loops;
* improve interference immunity.

Structure:

```text
Audio Inputs
      |
      |
      v
GND_AUDIO

      |
      |
Star point

      |
      |
Power Supply
```

---

# 8. Subsystems

## 8.1 TRRS Inputs

Quantity:

* 4 laptop inputs;
* 1 headset output.

Standard:

* CTIA;
* 3.5 mm;
* TRRS.

---

## 8.2 Audio Mixer

Characteristics:

* stereo;
* active;
* low noise;
* individual control per input.

---

## 8.3 Headphone Amplifier

Responsible for:

* supplying adequate current to the headset;
* maintaining audio quality;
* preventing overload of the laptops' outputs.

---

## 8.4 Microphone

Characteristics:

* direct connection to the selected laptop;
* no digital conversion;
* no processing;
* compatibility with native headset detection.

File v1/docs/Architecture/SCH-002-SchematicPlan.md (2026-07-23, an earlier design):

# SCH-002 - Schematic Design Plan

Version: 0.1
Status: Draft

---

# 1. Objective

Define the organization of the electrical schematic before implementation in KiCad.

---

# 2. Schematic sheets

The project will be divided into blocks:

## Sheet 1 - Power Supply

Responsible for:

- USB-C 5V input;
- protection;
- filtering;
- voltage distribution.

## Sheet 2 - TRRS Inputs

Responsible for:

- laptop connectors;
- signal separation:
  - Audio Left
  - Audio Right
  - Ground
  - Microphone

## Sheet 3 - Audio Mixer

Responsible for:

- individual volumes;
- stereo summing;
- pre-amplification.

## Sheet 4 - Headphone Amplifier

Responsible for:

- final amplification;
- headset output.

## Sheet 5 - Microphone Switching

Responsible for:

- laptop 1-4 selection;
- mute;
- signal relays.

# 3. Design rules

- keep the microphone line transparent;
- separate analog audio from power supply;
- minimize ground loops;
- use high-availability components.

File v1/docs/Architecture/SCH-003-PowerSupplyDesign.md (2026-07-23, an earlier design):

# SCH-003 - Power Supply Design

Version: 0.1
Status: Draft

# 1. Objective

Define the architecture of the MeetingHub-4 power supply.

# 2. Input

Source:

USB-C

Voltage:

5V DC

# 3. Requirements

The power supply shall:

- have overcurrent protection;
- have noise filtering;
- separate digital and analog power supply;
- minimize audio interference.

# 4. Architecture

```

USB-C 5V

```
|
v
```

Input protection

```
|
v
```

EMI Filter

```
|
v
```

+5V_AUDIO Bus

```
|
+----------------+
|                |
v                v
```

Audio             Headphone
Mixer             Amplifier

```

# 5. Protections

Planned:

- resettable fuse;
- surge protection;
- decoupling capacitors.

# 6. Notes

The circuit shall prioritize low noise.

The power supply shall not interfere with the microphone line or the TRRS inputs.
```

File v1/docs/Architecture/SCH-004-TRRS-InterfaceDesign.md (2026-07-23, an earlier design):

# SCH-004 - TRRS Interface Design

Version: 0.1
Status: Draft

# 1. Objective

Define the electrical interface between the laptops and the MeetingHub-4 using standard CTIA TRRS connectors.

# 2. Standard Used

Interface:

- TRRS 3.5 mm
- CTIA / AHJ

Pinout:

| Contact | Function |
|---|---|
| Tip | Audio Left |
| Ring 1 | Audio Right |
| Ring 2 | Ground |
| Sleeve | Microphone |

# 3. Inputs

Quantity:

4 independent inputs.

Identification:

- J1 - Laptop 1
- J2 - Laptop 2
- J3 - Laptop 3
- J4 - Laptop 4

# 4. Transparency Requirement

The laptop shall interpret the connection as a TRRS headset connected directly.

The microphone line shall:

- maintain the polarization supplied by the laptop;
- have no amplification;
- have no conversion;
- not alter the perceived impedance.

# 5. Audio Path

Each input will be split:

```

TRRS

L  ---------> Volume Control L
R  ---------> Volume Control R
GND --------> Common reference
MIC --------> Microphone selector

```

# 6. Microphone Path

```

Headset MIC

```
  |
```

MUTE Circuit

```
  |
```

Laptop Selection

```
  |
```

MIC of selected laptop

```

# 7. Protection

The following will be evaluated:

- ESD protection;
- EMI filtering;
- discharge protection on the connectors.

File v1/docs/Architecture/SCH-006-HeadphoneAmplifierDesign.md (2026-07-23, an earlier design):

# SCH-006 - Headphone Amplifier Design

Version: 0.1
Status: Draft

# 1. Objective

Define the stage responsible for providing sufficient power to the TRRS headset connected to the equipment.

The amplifier must receive the signal from the stereo mixer and provide adequate output for low- and medium-impedance headphones.

# 2. Architecture

Flow:

```

Stereo Mixer

```
  |
  v
```

Master Volume

```
  |
  v
```

Headphone Amplifier

```
  |
  v
```

TRRS Headset

```

# 3. Requirements

The amplifier must:

- operate with a 5V power supply;
- have low noise;
- support professional-use headsets;
- avoid distortion at high volume;
- have short-circuit protection on the output.

# 4. Compatibility

Expected range:

- 16 ohms;
- 32 ohms;
- 64 ohms.

# 5. Candidate Components

Initial options:

## NJM4556A

Characteristics:

- developed for headphone amplification;
- high current capability;
- simple;
- reliable.

## TPA6132A2

Characteristics:

- low voltage;
- low power consumption;
- dedicated headphone output.

The final selection will be made after analysis of:

- availability;
- cost;
- audio quality.

# 6. Output

The output must maintain the standard:

TRRS CTIA:

- Left
- Right
- Ground
- Microphone

The amplifier will be responsible only for the channels:

- Left
- Right

# 7. Protections

Planned:

- output resistor;
- decoupling;
- short-circuit protection;
- power supply filtering.

# 8. Notes

The microphone line remains independent.

The headphone amplifier must not interfere with headset detection by the laptops.
```

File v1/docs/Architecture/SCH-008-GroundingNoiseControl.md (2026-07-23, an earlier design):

# SCH-008 - Grounding and Noise Control

Version: 0.1
Status: Draft

# 1. Objective

Define the grounding, power supply, and noise control strategy of the MeetingHub-4.

The equipment has multiple analog audio sources connected simultaneously, so interference control is a critical requirement.

# 2. Potential Noise Sources

Possible sources:

- four laptops connected simultaneously;
- different power supply chargers;
- ground loops;
- USB power supply;
- external digital interference.

# 3. Grounding Strategy

Star grounding will be used.

Architecture:

```

TRRS Inputs

```
  |
```

GND_AUDIO

```
  |
```

Star Point

```
  |
```

Power Supply

```

Objectives:

- avoid currents circulating through the audio ground;
- reduce background noise;
- improve stability.

# 4. Domain Separation

The design must separate:

## Analog Audio

- TRRS inputs;
- mixer;
- headphone amplifier.

## Power Supply

- USB-C;
- filters;
- protection.

The union will be made at a controlled point.

# 5. PCB Layout

Requirements:

- keep audio traces away from the power supply;
- avoid parallel routing between sensitive signals and power supply traces;
- use a ground plane where applicable;
- position connectors near the board edges.

# 6. Decoupling

Each integrated circuit must have:

- a ceramic capacitor near the power supply pins;
- reserve capacitors on the main power supply.

# 7. Laptop Considerations

The design must be tested with:

- laptop running on battery;
- laptop connected to the charger;
- different computer brands.

# 8. Tests

Validate:

- noise with no signal;
- noise with four laptops connected;
- microphone switching;
- operation with different chargers.

# 9. Approval Criteria

The equipment must operate with no perceptible noise under normal use.
```

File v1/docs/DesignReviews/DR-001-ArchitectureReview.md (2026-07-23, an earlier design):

# Design Review 001

## Project

MeetingHub-4

## Review

Initial architecture

## Status

Approved with modifications

## Decisions

- TRRS CTIA interface retained.
- Microphone will be switched without active electronics.
- Audio will use an active mixer.
- USB-C 5V power supply.
- Fully analog design.

## Next phase

Development of the electrical schematic.

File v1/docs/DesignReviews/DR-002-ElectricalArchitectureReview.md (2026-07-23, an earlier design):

# DR-002 - Electrical Architecture Review

Version: 0.1
Status: Review

# 1. Objective

Review the electrical architecture defined before starting development of the schematic in KiCad.

# 2. Scope Reviewed

The following were evaluated:

- TRRS CTIA interface;
- audio path;
- stereo mixer;
- headphone amplifier;
- microphone selection;
- power supply;
- noise control.

# 3. Approved Decisions

## Interface

Approved:

- TRRS CTIA;
- metal panel connectors;
- native compatibility with laptops.

## Audio

Approved:

- four independent inputs;
- active stereo mixer;
- individual volume control;
- master volume.

## Microphone

Approved:

- relay-based switching;
- absence of active electronics on the MIC line;
- selection of one laptop at a time.

## Power supply

Approved:

- USB-C 5V;
- filtering;
- protection;
- separation of audio and power supply.

## Noise

Approved:

- star grounding;
- attention to PCB layout;
- tests with different chargers.

# 4. Points of Attention

During prototype development, the following must be evaluated:

- noise between laptops;
- compatibility with different audio codecs;
- headset detection behavior;
- quality of microphone switching.

# 5. Status

Architecture approved for schematic development.

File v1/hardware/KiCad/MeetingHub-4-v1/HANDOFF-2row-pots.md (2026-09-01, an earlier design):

# RESOLVED (2026-08-06, updated): SW2-SW5 rotated horizontal, re-routed, DRC clean

**Status: ready for gerbers.** `MeetingHub-4-v1.kicad_pcb` now has 0 real
DRC violations (0 clearance, 0 hole_clearance, 0 solder-mask bridges,
0 courtyard overlaps, 0 unconnected pads) — verified via KiCad's own
DRC. RV1-4 stayed in the diamond/staggered layout, RV5 is rotated 90°
and fully routed at the front panel next to SW1/J6.

**Latest round**: SW1 (MUTE pushbutton) was already horizontal at 0°
(its `SW_PUSH-12mm` footprint spans 12.5mm in X / 5mm in Y) so it was
left unchanged. SW2-SW5 (`SW_CW_GPTS203211B` selector switches) were
vertical at 0° (pads 5.3mm apart in Y) and are now rotated 90° to lie
horizontal, matching SW1's orientation. This required: re-bridging
each switch's pad2 (`Net-(D2-A)`..`Net-(D5-A)`) via a via-hop through
B.Cu to its new pad location (the F.Cu row was too congested with
existing trunk traces for a direct diagonal); shifting SW2 2mm to the
right (128.8→130.8mm) to clear a courtyard overlap with RV5 that the
rotation introduced; and re-routing one segment of the D5-A trunk that
came too close to SW3's new pad2 position. Zones were refilled after
all pad moves.

What got the board there originally: full board re-route via the
Freerouting autorouter (DSN export → `java -jar freerouting-*.jar -de
... -do ... -mp 5` → `File → Import → Specctra Session` in KiCad),
followed by manually closing one last VBIAS gap on RV5 (pad6→pad3, a
2.5mm bridge that needed to dodge MIX_L/MIX_R traces running through
the same pocket).

**Fabrication files regenerated (2026-08-06) and ready to order:**
- `hardware/Gerbers/MeetingHub-4-Gerbers-v4.0.zip` — gerbers + drill +
  job file for the current 160.19x134.06mm routed board, with SW2-SW5
  horizontal. **v1.0/v2.0 in that folder are stale (old
  265.1x160.1mm board); v3.0 has SW2-SW5 still vertical — don't use
  either.**
- `hardware/Gerbers/MeetingHub-4-Placement.csv` and `-drl_map.pdf`
  regenerated to match.
- [production/PCBWay-OrderGuide.md](../../../production/PCBWay-OrderGuide.md)
  updated to v4.0 / current dimensions.
- [hardware/BOM/BOM-003-SourcingLinks.md](../../BOM/BOM-003-SourcingLinks.md)
  rewritten as a single shopping-list table.

Remaining, not DRC-blocking:
- `lib_footprint_issues` warnings are a local library-path artifact,
  not present when DRC is run from the actual KiCad install — ignore.
- A couple of cosmetic `silk_over_copper` / `silk_edge_clearance`
  warnings — check visually, not required to fix.
- A stray `MeetingHub-4.dsn`/`.ses` may be sitting next to this file
  from the autorouter export — safe to delete, not part of the design.

---

# Superseded below: earlier handoff from the manual-routing attempt

Status: **Work in progress, NOT ready for fabrication**. Open
`MeetingHub-4-v1.kicad_pcb` in KiCad to finish.

**Do not generate gerbers or place an order from the current file
state.** Gerbers/Placement.csv in `hardware/Gerbers/` are stale —
they reflect the *previous* fully-validated 265.1x160.1mm version. To
fall back to that instead of finishing this layout, the backup is at
(outside the repo, ask Claude to restore it into the repo again):
`/tmp/claude-1000/-home-fac-MeetingHub-4/70b6b083-68e6-432f-bf44-7f5a21f890f3/scratchpad/revert-work/bigboard-everything-soldered-VALIDATED.kicad_pcb`

# Progress this round: RV5 relocated to the front panel, board-wide violations 442 → 389

RV5 is the **microphone volume control** and needed to be on the front
edge, near MUTE (SW1) or J6. It's now placed **between SW1 and SW2**,
which required reflowing the whole front row to fit within the
existing board width (no size change, per instruction):

| Ref | Old X | New X | Y (unchanged) |
|---|---|---|---|
| SW1 (MUTE) | 75.4 | *unchanged* | 207.4 |
| **RV5** | *(was 214, near J6)* | **119.0** | 207.4 |
| SW2 | 107.2 | 128.8 | 207.4 |
| SW3 | 123.2 | 145.8 | 207.4 |
| SW4 | 139.2 | 162.8 | 207.4 |
| SW5 | 157.0 | 179.8 | 207.4 |
| J6 | 195.58 (rot 90) | 201.6 (rot 90) | 209.105 |

All 7 items fit left-to-right with ~2.5-3mm gaps, well inside the
160.1mm board width (rightmost point ~214, board edge at 220.09).

**Net DRC change: 442 → 389 violations** (fewer than before this
round started) — the repositioning itself introduced **zero** new
clearance violations against SW2-5/J6/RV5 (verified by name-matching
every clearance violation against those 6 designators: 0 hits).
Verified 3x via fresh `pcbnew.WriteDRCReport` reloads, identical
389/389/389.

The net improvement over the baseline came from cleaning up stale
copper that predated this round and was already causing violations:
- A dangling `VBIAS` detour fragment (leftover from an earlier,
  abandoned "RV5 near MUTE" attempt) that went nowhere useful.
- A 56mm stray `Net-(D5-A)` trace and another stub going to an old,
  no-longer-relevant SW5 position.
- An incomplete `HEADSET_MIC` zigzag that dead-ended in open space
  (never actually reached J6) — deleted, and the *real* `HEADSET_MIC`
  bus was given a clean detour under RV5's new footprint (south strip,
  Y~217, confirmed clear of other copper) so it no longer clips RV5's
  pin2/pin5 row.

# What's left — routing (this is real, contained work, not guesswork)

**RV5**: still has 0 of 6 pins routed. Both a north-side approach
(through the gap between the K1-K4 relay cluster and the switch row)
and a south-side approach (below the switch row) were tried via
scripted routing this round and hit real, repeated collisions — this
whole area is far more electrically congested than it looks:
- The K1-K4 → D2-D5 relay-control routing occupies almost the entire
  Y180-207 band across X70-130 (both F.Cu and B.Cu), not just the
  relay footprints themselves.
- `HEADSET_MIC` runs the full board width at Y=209.563 on F.Cu.
- RV5's own pins are a tight 2.5mm-pitch 2x3 grid, so any bridge
  needs a dedicated lane per pin (see the 3-segment technique used
  for RV1-4) — workable in principle, but combined with the above
  it needs to be done **visually in KiCad**, not blind coordinate
  scripting. Multiple scripted attempts each looked clear on paper
  and then collided with something not visible without rendering the
  board.
- RV5's real net neighbors: pin1/pin4 → `C13`/`C14` (near X100,
  Y141.5), pin2 → `MIX_L` (no close existing stub — needs a fresh
  run, likely from `C15` at X173.8,Y142.5), pin3/pin6 → `VBIAS` (the
  shared bias rail — closest existing point is at (91.3, 207.35), 3mm
  west of RV5's pad1), pin5 → `MIX_R` (existing point at (96.3,
  207.35), same area).

**SW2, SW3, SW4, SW5 pad2** (the `Net-(D2-A)` .. `Net-(D5-A)` relay
control signals): each old chain still ends at roughly its *old*
X position (dangling) and needs a fresh short bridge to the new pad2
location. These are simple 2-terminal bridges (not a tight pin grid
like RV5) — much easier than RV5, but also collided with each other
and with `HEADSET_MIC`/RV5 when routed blind this round, so they were
reverted rather than left half-broken. Old dangling ends:
- D2-A: (109.7, 207.4) → new SW2 pad2 (128.8, 212.7)
- D3-A: (118.94, 205.998) → new SW3 pad2 (145.8, 212.7) — routing
  through here needs to clear RV5's pad1 by at least ~1.5mm
- D4-A: (131.5, 207.4) → new SW4 pad2 (162.8, 212.7)
- D5-A: (142.4, 207.4) → new SW5 pad2 (179.8, 212.7)

**Also unconnected, not part of this round's scope** — a pad each on
C12, C15, C18, C21, and 4 pads on J6 (J6's own signal routing appears
to have been incomplete even before this round — the deleted
`HEADSET_MIC` zigzag never actually reached it).

# Current layout reference

| Ref | Position | Status |
|---|---|---|
| RV1, RV2 | (90,150) / (122,150), 0° | ✅ Clean |
| RV3, RV4 | (117.5,167) / (149.5,167), 0° | ✅ Clean |
| RV5 | **(119.0, 207.4), 0°** — front row, between SW1 and SW2 | ⚠️ Positioned, not routed |
| SW1 | (75.4, 207.4), 0° | unchanged |
| SW2, SW3, SW4 | (128.8,207.4) / (145.8,207.4) / (162.8,207.4), 0° | ⚠️ pad2 needs re-bridge |
| SW5 | (179.8, 207.4), 0° | ⚠️ pad2 needs re-bridge |
| J6 | (201.6, 209.105), rot 90° | position only |

# After routing is finished

1. Run DRC inside KiCad until 0 errors (ignore `lib_footprint_issues`
   and `silk_over_copper`, both cosmetic/environment artifacts).
2. Re-run zone fill (`B`) one more time after routing.
3. Regenerate gerbers/drill (`File → Fabrication Outputs`, or
   `kicad-cli pcb export gerbers` / `export drill` — see
   [PCBWay-OrderGuide.md](../../production/PCBWay-OrderGuide.md)).
4. Update [BOM-003-SourcingLinks.md](../../hardware/BOM/BOM-003-SourcingLinks.md)
   status and re-zip `hardware/Gerbers/MeetingHub-4-Gerbers-v1.0.zip`
   before submitting a new assembly quote.

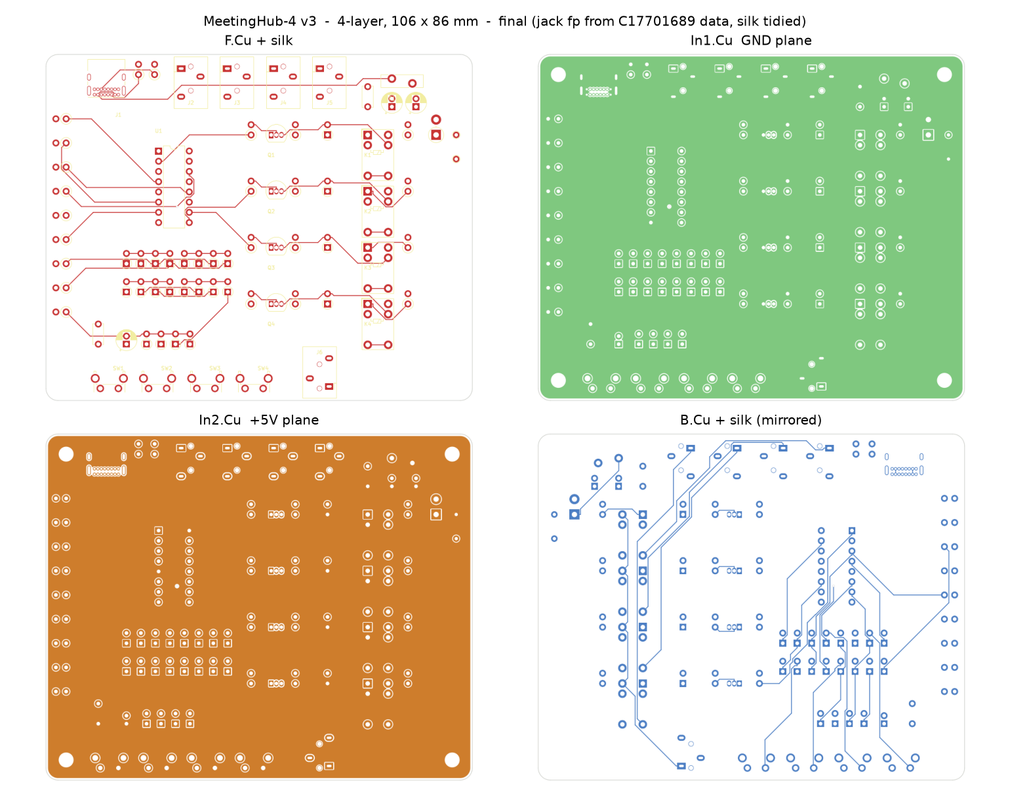
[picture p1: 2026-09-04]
v3/docs/v3-pcb-layers.png

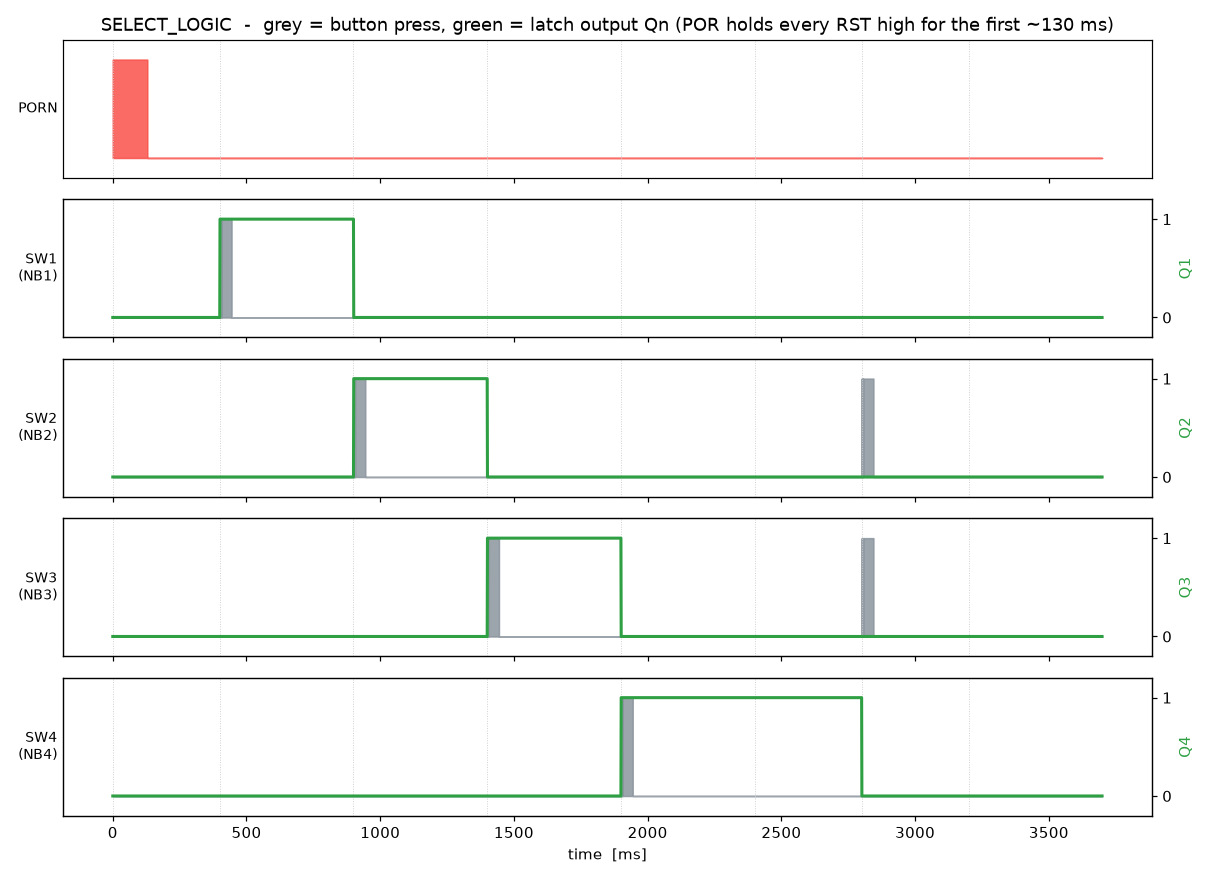
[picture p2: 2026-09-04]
v3/simulation/plots/S_select_logic.png

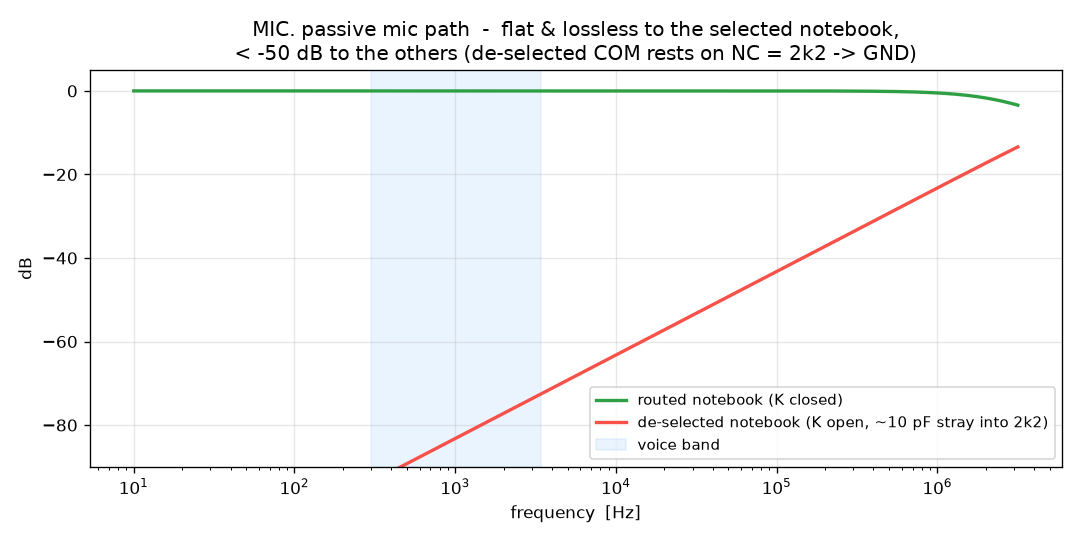
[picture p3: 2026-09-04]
v3/simulation/plots/MIC_path.png

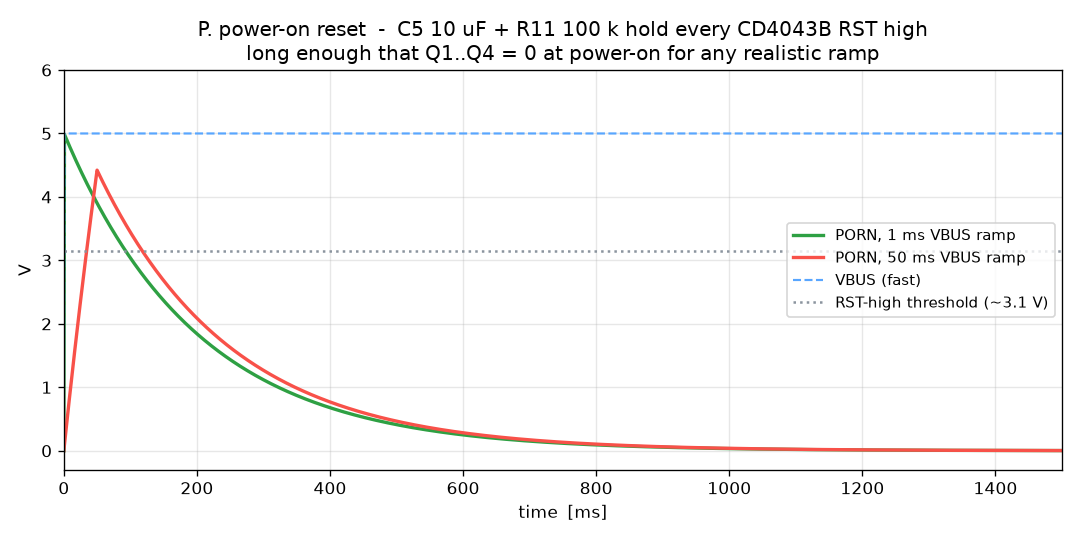
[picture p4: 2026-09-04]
v3/simulation/plots/P_por.png

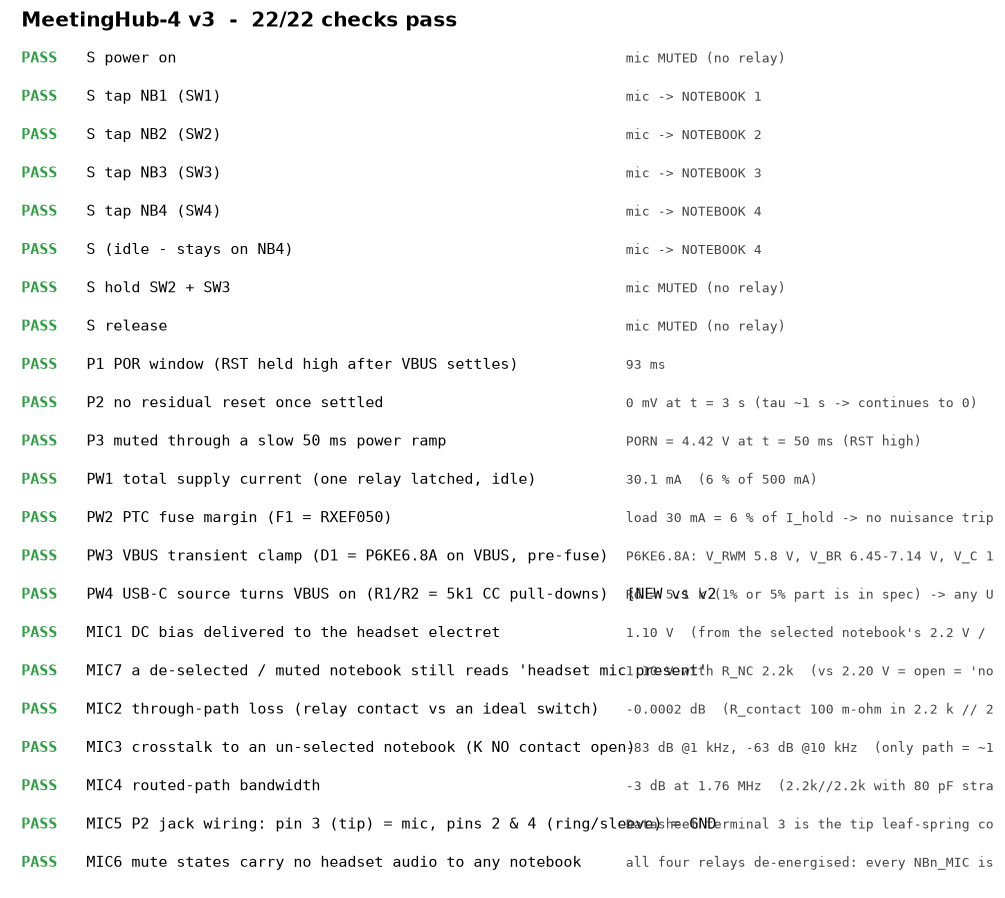
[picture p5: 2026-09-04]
v3/simulation/plots/scorecard.png

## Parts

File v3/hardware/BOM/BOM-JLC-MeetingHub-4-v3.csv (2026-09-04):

Comment | Designator | Footprint | JLCPCB Part #
K104K15X7RF5TH5 | C1, C4 | C_Disc_D5.0mm_P5.00mm | C2167231
KM106M016D11RR0VH2FP0 | C2, C5 | CP_Radial_D5.0mm_P2.00mm | C43799
KM476M016C11RR0VH3FP0 | C3 | CP_Radial_D5.0mm_P2.00mm | C177036
P6KE6.8A | D1 | D_DO-15_P3.81mm | C152132
1N4148 | D2, D3, D4, D5, D6, D7, D8, D9, D10, D11, D12, D13, D14, D15, D16, D17, D18, D19, D20, D21, D22, D23, D24, D25 | D_DO-35_P2.54mm | C402212
RXEF050 | F1 | Fuse_Bourns_MF-RG500 | C76399
USB4085-GF-A | J1 | USB_C_Receptacle_GCT_USB4085 | C7095263
PJ-320A-3P DIP | J2, J3, J4, J5, J6 | Jack_3.5mm_3pole_THT_Horizontal | C17701689
G5V-1-DC5 | K1, K2, K3, K4 | Relay_SPDT_Omron_G5V-1 | C28695
2N7000 | Q1, Q2, Q3, Q4 | TO-92_Inline | C9114
CFR0W4J0512A50 | R1, R2 | R_Axial_DIN0207_P2.54mm_Vertical | C22962
MFR-25FBF52-100K | R3, R4, R5, R6, R7, R8, R9, R10, R11, R16, R17, R18, R19 | R_Axial_DIN0207_P2.54mm_Vertical | C1364475
CF1/4W-1KR-J | R12, R13, R14, R15 | R_Axial_DIN0207_P2.54mm_Vertical | C120055
CFR0W4J0222A50 | R20, R21, R22, R23 | R_Axial_DIN0207_P2.54mm_Vertical | C22975
PTS645VK392LFS | SW1, SW2, SW3, SW4 | SW_Tactile_SPST_Angled_PTS645Vx39-2LFS | C285519
CD4043BE | U1 | DIP-16_W7.62mm | C22390239

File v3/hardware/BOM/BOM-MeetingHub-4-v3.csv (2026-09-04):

Designators | Quantity | Value | Footprint
C1, C4 | 2 | 100nF | C_Disc_D5.0mm_W2.5mm_P5.00mm
C2, C5 | 2 | 10uF | CP_Radial_D5.0mm_P2.00mm
C3 | 1 | 47uF | CP_Radial_D5.0mm_P2.00mm
D1 | 1 | P6KE6.8A (TVS 5V uni) | D_DO-15_P3.81mm_Vertical_AnodeUp
D2, D3, D4, D5, D6, D7, D8, D9, D10, D11, D12, D13, D14, D15, D16, D17, D18, D19, D20, D21, D22, D23, D24, D25 | 24 | 1N4148 | D_DO-35_SOD27_P2.54mm_Vertical_AnodeUp
F1 | 1 | 500mA | Fuse_Bourns_MF-RG500
J1 | 1 | USB-C 5V IN | USB_C_Receptacle_GCT_USB4085
J2 | 1 | Mic NB1 | Jack_3.5mm_3pole_THT_Horizontal
J3 | 1 | Mic NB2 | Jack_3.5mm_3pole_THT_Horizontal
J4 | 1 | Mic NB3 | Jack_3.5mm_3pole_THT_Horizontal
J5 | 1 | Mic NB4 | Jack_3.5mm_3pole_THT_Horizontal
J6 | 1 | Headset MIC | Jack_3.5mm_3pole_THT_Horizontal
K1 | 1 | Route NB1 | Relay_SPDT_Omron_G5V-1
K2 | 1 | Route NB2 | Relay_SPDT_Omron_G5V-1
K3 | 1 | Route NB3 | Relay_SPDT_Omron_G5V-1
K4 | 1 | Route NB4 | Relay_SPDT_Omron_G5V-1
MH1, MH2, MH3, MH4 | 4 | M3 mounting hole | MountingHole_3.2mm_M3
Q1, Q2, Q3, Q4 | 4 | 2N7000 | TO-92_Inline
R1, R2 | 2 | 5k1 | R_Axial_DIN0207_L6.3mm_D2.5mm_P2.54mm_Vertical
R3, R4, R5, R6, R7, R8, R9, R10, R11, R16, R17, R18, R19 | 13 | 100k | R_Axial_DIN0207_L6.3mm_D2.5mm_P2.54mm_Vertical
R12, R13, R14, R15 | 4 | 1k | R_Axial_DIN0207_L6.3mm_D2.5mm_P2.54mm_Vertical
R20, R21, R22, R23 | 4 | 2k2 | R_Axial_DIN0207_L6.3mm_D2.5mm_P2.54mm_Vertical
SW1 | 1 | Select NB1 | SW_Tactile_SPST_Angled_PTS645Vx39-2LFS
SW2 | 1 | Select NB2 | SW_Tactile_SPST_Angled_PTS645Vx39-2LFS
SW3 | 1 | Select NB3 | SW_Tactile_SPST_Angled_PTS645Vx39-2LFS
SW4 | 1 | Select NB4 | SW_Tactile_SPST_Angled_PTS645Vx39-2LFS
TP1 | 1 | +5V | TestPoint_THTPad_D1.5mm
TP2 | 1 | GND | TestPoint_THTPad_D1.5mm
U1 | 1 | CD4043B | DIP-16_W7.62mm

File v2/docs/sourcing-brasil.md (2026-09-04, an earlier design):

# MeetingHub-4 v2 — compra dos componentes no Brasil + placa nua importada

Data: 2026-09-03 · preços **aproximados** de set/2026, confira no link antes de comprar · câmbio usado: US$ 1 ≈ R$ 5,40

> **Objetivo:** decidir se compensa importar só a **placa nua** (barata, leve, imposto
> baixo) e comprar os **componentes no Brasil**, em vez de pagar a placa montada pela
> JLCPCB (US$ 108 + US$ 87 frete + ~104 % imposto ≈ **US$ 398 / ~R$ 2.150** por lote de 5).

---

## 1. Resumo da decisão

| | Placa montada JLCPCB (5 un) | Placa nua importada + peças no Brasil |
|---|---|---|
| Placa | US$ 108 | ~US$ 30–45 / 5 un (nua) |
| Frete | US$ 87 (expresso) | ~US$ 12–25 (linha econômica) |
| Imposto | ~104 % sobre (placa+frete) | ~37 % se o pedido ≤ US$ 50 (Remessa Conforme); ~92 % acima |
| Componentes | inclusos | **~R$ 180–260 por placa** (ver tabela) |
| Montagem | pronta | você solda, ou ~R$ 100–150 com um técnico |
| **Custo por 1 placa funcionando** | ~R$ 430 | **~R$ 450–650** |
| **Custo pelas 5 placas** | ~R$ 2.150 | **~R$ 1.400–1.900** + solda |

**Conclusão:** compensa **se você for montar as 5** (ou pelo menos 3), ou se você mesmo
solda. Para **1 placa só** o ganho é pequeno, porque a JLCPCB obriga a comprar 5 placas
nuas e o frete/imposto é fixo. O maior risco **não é preço, é footprint** (item 3).

---

## 2. Tabela de componentes — onde comprar no Brasil

Designadores conforme [`BOM-PCBA-MeetingHub-4-v2.csv`](../hardware/BOM/BOM-PCBA-MeetingHub-4-v2.csv).
Preço = **por placa** (1 unidade de cada valor). "Comprar em quantidade" (kit) quase sempre sai mais barato.

### 2.1 Circuitos integrados

| Ref | Peça | Qtd | Onde comprar | Preço aprox. (un) | Linha |
|---|---|---|---|---|---|
| U1 | NJM4580DD (op-amp áudio, DIP-8) | 1 | [Toni Eletrônica](https://tonieletronica.com/ci-njm4580dd-amplificador-operacional-jrc-4580dd-dip-8/) · [Mercado Livre](https://lista.mercadolivre.com.br/njm4580) | R$ 6–12 | R$ 9 |
| U2 | NJM4556AD (op-amp alta corrente, DIP-8) | 1 | [Mercado Livre "NJM4556"](https://eletronicos.mercadolivre.com.br/ci-njm4556-jrc-amplificador-operacional) — **conferir se é DIP-8**, a maioria é SIP-8 | R$ 15–35 | R$ 25 |
| U3 | LM358P (op-amp, DIP-8) | 1 | [SmartProjects](https://www.smartprojectsbrasil.com.br/circuito-integrado-amplificador-operacional-lm358) · [Mercado Livre](https://lista.mercadolivre.com.br/lm358) | R$ 1–3 | R$ 2 |
| U4 | CD4043BE (quad latch NOR, DIP-16) | 1 | [Achei Componentes](https://www.acheicomponentes.com.br/circuito-integrado-cd4043be-dip-16-texas) · [Proesi](https://www.proesi.com.br/cd4043-circuito-integrado-dip-16) · [Mercado Livre](https://produto.mercadolivre.com.br/MLB-1580401361-1-peca-circuito-integrado-cd4043be-dip-16-cd4043-_JM) | R$ 3–7 | R$ 5 |
| — | Soquete DIP-8 (3×) + DIP-16 (1×) — recomendado | 4 | Baú da Eletrônica / SmartProjects / Mercado Livre | R$ 0,50–1 | R$ 3 |

> **U2 é o ponto de atenção dos CIs:** o NJM4556A**D** (DIP-8) é raro no varejo BR; o que
> se acha é o NJM4556A**L** (SIP-8), footprint diferente. Se não achar o DIP, importe
> este junto com a placa (item 4) ou troque por 2× NJM4580 em paralelo (exige revisão do circuito).

### 2.2 Potenciômetros e chaves

| Ref | Peça | Qtd | Onde comprar | Preço aprox. (un) | Linha |
|---|---|---|---|---|---|
| RV1–RV5 | Pot. duplo 10 k **log (A10K)**, PCI horizontal tipo RK09 | 5 | [Casa do Resistor "mini duplo A10K L15 PCI"](https://www.casadoresistor.com.br/potenciometro-logaritmico-mini-duplo-a-10k-l15-estriado-o16mm-pci) · [Duque Eletrônica](https://www.duqueeletronica.com.br/produto/potenciometro-10ka-l15-a10k-duplo-schave-6t-180o-stereo-logaritmo-006972-0103hd781o) · [Mercado Livre](https://lista.mercadolivre.com.br/potenciometro-duplo-10k-10k-log) | R$ 4–9 | R$ 30 (5×) |
| SW2–SW5 | Chave tátil 6 mm **90° / horizontal**, 4 term. | 4 | [Baú da Eletrônica KFC-A06-W6](https://www.baudaeletronica.com.br/produto/chave-tactil-kfc-a06-w6-6mm-4-terminais-90-graus.html) · [Soldafria](https://www.soldafria.com.br/chave-tactil-kfc-a06-w6-6mm-4-terminais-90-graus-p-4456.html) | R$ 0,50–1,50 | R$ 4 (4×) |

> Verificar footprint (item 3). O pot v2 é **Alps RK097 horizontal**; o "mini duplo L15
> PCI" nacional costuma ser compatível com o footprint RK09, mas **confira o passo dos
> pinos** contra o desenho no KiCad.

### 2.3 Relés, conectores, semicondutores de potência

| Ref | Peça | Qtd | Onde comprar | Preço aprox. (un) | Linha |
|---|---|---|---|---|---|
| K1–K4 | Relé de sinal **Omron G5V-1 5 VDC SPDT** | 4 | [Ecotron Componentes](https://www.ecotroncomponentes.com.br/automacao/reles/rele-5vdc-g5v-1-dc5-omron-g5v1dc5) · [DigiKey Brasil](https://www.digikey.com.br/pt/products/detail/omron-electronics-inc-emc-div/G5V-1-T90-DC12/6650356) | R$ 9–14 | R$ 45 (4×) |
| J2–J6 | Jack P2 3,5 mm **4 polos (TRRS)** fêmea PCI | 5 | [SmartProjects "P2 estéreo 4 term. placa"](https://www.smartprojectsbrasil.com.br/conector-jack-p2-estereo-femea-aberto-4-terminais-para-placa) · [Mercado Livre "jack P2 4 polos"](https://lista.mercadolivre.com.br/jack-p2-4-polos) | R$ 1,50–4 | R$ 15 (5×) |
| J1 | Conector **USB-C fêmea PCI** (compatível c/ footprint GCT USB4085) | 1 | [Mamute SMD 24 pinos 180°](https://www.mamuteeletronica.com.br/conector-usb-tipo-c-3-1-femea-24-pinos-smd-smt-180-graus-22746) · [Mercado Livre](https://lista.mercadolivre.com.br/conector-usb-c-femea) | R$ 3–10 | R$ 8 |
| Q1–Q4 | 2N7000 (MOSFET TO-92) | 4 | [Mercado Livre](https://lista.mercadolivre.com.br/2n7000) · Baú da Eletrônica | R$ 0,50–1 | R$ 3 (4×) |
| D1 | P6KE6.8A (TVS 6,8 V, DO-15) | 1 | [Mercado Livre "P6KE 6.8"](https://lista.mercadolivre.com.br/diodo-p6ke-6.8) · Mixtrônica | R$ 1–4 | R$ 3 |
| F1 | Fusível PTC resetável **500 mA radial THT** (MF-R050) | 1 | [Loja da Fábrica de Bolso](https://loja.fabricadebolso.com.br/produto/fusivel-auto-restauravel-self-restoring-fuse-500maptc-reset-fuse.html) · Mercado Livre | R$ 1–4 | R$ 3 |

> **J1 (USB-C) é o segundo ponto de atenção:** o v2 usa o footprint do GCT USB4085
> (recept. 16 pinos, power-only). Os conectores "2 pinos para alimentação" nacionais
> **não** encaixam. Ou usa um USB-C 16/24 pinos com o mesmo padrão, ou importa o GCT
> junto com a placa (item 4).

### 2.4 Resistores 1/4 W (axial THT) e capacitores

| Ref | Valor | Qtd | Onde comprar | Linha |
|---|---|---|---|---|
| R1,R2,R5–R12 | 10 k | 10 | qualquer loja; **kit 1/4 W** (600 pç, ~R$ 30) resolve todos os valores | — |
| R3,R4 | 3k3 (metal film 1 %) | 2 | idem | — |
| R13,R17,R21–R28,R33–R37 | 100 k | 15 | idem | — |
| R14,R15,R18,R19,R29–R32 | 1 k | 8 | idem | — |
| R16,R20,R38 | 47 R (47 Ω) | 3 | idem | — |
| — | **Resistores (avulsos ou kit)** | 38 | [Baú da Eletrônica](https://www.baudaeletronica.com.br/) · [SmartProjects](https://www.smartprojectsbrasil.com.br/) · Mercado Livre | R$ 5 avulso / R$ 30 kit |
| C1,C4,C21,C22,C25 | 100 nF cerâmico 5 mm | 5 | qualquer loja | R$ 1,50 |
| C5–C15,C18,C26 | 1 µF cerâmico/poliéster 5 mm | 13 | qualquer loja | R$ 5 |
| C2,C3,C16,C19,C24 | 10 µF eletrolítico 16 V | 5 | qualquer loja | R$ 1 |
| C17,C20 | 220 µF eletrolítico 16 V | 2 | qualquer loja | R$ 1 |
| C23 | 100 µF eletrolítico 16 V | 1 | qualquer loja | R$ 0,50 |
| D2–D5,D10–D29 | 1N4148 (DO-35) | 24 | Mercado Livre / Baú (kit 100 pç ~R$ 10) | R$ 3 |

### 2.5 Total estimado dos componentes (por placa)

| Grupo | R$ / placa |
|---|---|
| CIs + soquetes | ~R$ 44 |
| Potenciômetros (5×) | ~R$ 30 |
| Chaves táteis (4×) | ~R$ 4 |
| Relés (4×) | ~R$ 45 |
| Jacks P2 (5×) + USB-C | ~R$ 23 |
| 2N7000 + TVS + PTC | ~R$ 9 |
| Resistores + capacitores + 1N4148 | ~R$ 16 |
| **Subtotal peças** | **~R$ 171** |
| Fretes (2–3 lojas × ~R$ 15–25) | ~R$ 50 |
| **Total peças, 1 placa** | **~R$ 220** |
| **Total peças, 5 placas** | **~R$ 750–900** (fretes diluídos, kits) |

Item mais caro: **relés (R$ 45)** e **pots (R$ 30)**. Juntos = 44 % do custo de peças.

---

## 3. Risco real: footprint (leia antes de comprar a placa nua)

A placa v2 foi desenhada em torno de **peças específicas da JLCPCB**. Três footprints são
**locais, feitos sob medida** — se a peça nacional tiver pinagem/passo diferente, **não encaixa**:

| Footprint no v2 | Peça original | Peça BR equivalente | Encaixa? |
|---|---|---|---|
| `Potentiometer_Alps_RK097_Dual_Horizontal` | Alps RK09712200HA | pot. duplo "mini L15 PCI" | **provável, confirmar passo dos pinos** |
| `Jack_3.5mm_PJ-3200B-4A_Horizontal` | HRO PJ-3200B-4A | jack P2 4 polos nacional | **confirmar** — pinagem T/R1/R2/S varia por fabricante |
| `USB_C_Receptacle_GCT_USB4085` | GCT USB4085 | — | **improvável** com conector "2 pinos"; precisa do GCT ou equivalente 16 pinos |
| `Relay_SPDT_Omron_G5V-1` (padrão KiCad) | Omron G5V-1 | Omron G5V-1 (mesma peça) | **sim** |
| `SW_Tactile_...PTS645Vx39-2LFS` | C&K PTS645 90° | KFC-A06-W6 90° | **provável, confirmar** |

**Antes de mandar fazer a placa nua:** abrir o projeto no KiCad, e para cada peça
nacional que você for usar, comparar o footprint do v2 com o datasheet da peça comprada.
Ajustar os footprints locais se necessário e **regerar os Gerbers**.

---

## 4. Recomendação: sourcing híbrido

O melhor custo/risco:

1. **Importe da LCSC, junto no mesmo pacote da placa nua**, só as 3 peças críticas de footprint
   (custo somado ~US$ 3–6, peso ~zero, não muda a faixa de imposto):
   - J1 — GCT USB4085 (`C7095263`)
   - J2–J6 — HRO PJ-3200B-4A ×5 (`C136687`)
   - RV1–RV5 — Alps RK09712200HA ×5 (`C470545`) *(ou confirme o pot nacional e compre aqui)*
2. **Compre no Brasil** todo o resto (CIs, relés, resistores, capacitores, diodos,
   2N7000, chaves, fusível) — item 2.
3. **Placa nua:** peça 5 un, 2 camadas, 192 × 156 mm, 1,6 mm, HASL, na JLCPCB com
   **frete econômico** (mantém o pedido ≤ US$ 50 → imposto ~37 %). Alternativa nacional
   com nota fiscal: [PCB Brasil](https://pcbbrasil.com.br) / [FastPCB](https://fastpcb.com.br).

Custo desse caminho: **placa ~R$ 350–450 (5 un) + peças ~R$ 750–900 (5 un) ≈ R$ 1.100–1.350
pelas 5**, contra ~R$ 2.150 da JLCPCB montada. Economia ~40 %, e você fica com a
experiência de bancada para a fase de bring-up (`v2-DESIGN.md` §7).

---

## 5. Lojas BR usadas nesta pesquisa

| Loja | Site | Forte em |
|---|---|---|
| Baú da Eletrônica | baudaeletronica.com.br | catálogo amplo, kits |
| SmartProjects Brasil | smartprojectsbrasil.com.br | CIs, conectores, jacks |
| Mercado Livre | mercadolivre.com.br | tudo, preço, frete grátis |
| Casa do Resistor | casadoresistor.com.br | potenciômetros |
| Duque Eletrônica | duqueeletronica.com.br | potenciômetros |
| Ecotron Componentes | ecotroncomponentes.com.br | relés Omron |
| Achei Componentes | acheicomponentes.com.br | CIs (São Paulo) |
| Proesi | proesi.com.br | CIs série 4000 |
| Toni Eletrônica | tonieletronica.com | op-amps de áudio |
| Soldafria | soldafria.com.br | chaves, ferramentas |
| Mixtrônica | mixtronica.com | diodos, fusíveis |
| DigiKey Brasil | digikey.com.br | peças originais (importa, mas cota em BRL) |

Preços e disponibilidade mudam — sempre confira no link antes de fechar o pedido.

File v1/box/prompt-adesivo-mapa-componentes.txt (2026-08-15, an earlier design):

PROMPT FINAL — Adesivo "MeetingHub-4 — Mapa de componentes, escala 1:1"
================================================================
(gerar em uma IA de imagem; o resultado será depois montado por mim
em um PDF A4 com escala real garantida)

-----------------------------------------------------------------
PROMPT (versão final com alterações)
-----------------------------------------------------------------

Design a beautiful, intuitive product-identification sticker/label for the top panel of an audio device, meant to be printed and glued onto the real enclosure. Clean technical-poster style — think a high-end audio interface or synth faceplate: confident typography, restrained color, generous whitespace, a short line explaining what the device does. Not cartoonish, not cluttered — every mark on this sticker must correspond to a real, physical position on the real hardware, so precision and legibility come before decoration.

OUTPUT FORMAT — critical: the image frame must be landscape with aspect ratio exactly 160.09:133.96 (≈ 1.195:1, close to a 6:5 ratio). The artwork must fill the entire frame edge-to-edge — no letterboxing, no white margin around it, rounded corners with a radius about 3% of the panel height (real corner radius is 5mm on a 133.96mm-tall panel). If the tool only accepts preset ratios, pick the closest to 1.195:1 (e.g. 5:4) rather than square or 16:9. Render at the highest resolution available on the long edge (1800px+).

TITLE / INTRO (small, tasteful, in the panel's otherwise-empty area — see layout notes below):
"MeetingHub-4" as the product wordmark, plus a one-line subtitle:
"Hub de áudio para reunião — compartilha um headset entre até 4 notebooks."

LABEL STYLE — every per-component tag below is written the way real pro-audio gear silkscreens its panels (short, English, upper case, no punctuation) — e.g. Behringer/Focusrite/Yamaha convention. Use these exact tags only. Do NOT print any reference designators (do not write J1, J2, J3, J4, J5, J6, RV1, RV2, RV3, RV4, RV5, SW1, SW2, SW3, SW4 or SW5 anywhere on the artwork):

IN 1, IN 2, IN 3, IN 4 — the four notebook inputs  
USB POWER — power input  
VOL 1, VOL 2, VOL 3, VOL 4 — the four input-volume trimmers  
VOL MIC — mic volume  
MUTE — mute button (simplified label)
OUT 1, OUT 2, OUT 3, OUT 4 — mic routing selectors (simplified from "MIC OUT")
HEADSET — headset jack

LAYOUT — this is a real component map, so positions below are given as percentages of panel width (X%) and panel height (Y%), measured from the top-left corner, matching the real board:

Corner fixing screws (small, quiet, metallic dot — NOT a highlighted feature, these are just M3 mounting screws, no drilling callout needed):
- top-left corner (X=3.7%, Y=4.5%)
- top-right corner (X=96.3%, Y=4.5%)
- bottom-left corner (X=3.8%, Y=96.2%)
- bottom-right corner (X=97.4%, Y=96.2%)

THESE FOUR ARE REAL DRILL HOLES IN THIS EXACT PANEL — give them the strongest visual treatment on the sticker: a glowing ring, and a small icon suggesting a hole/drill-through. They are input-volume trimmer knobs, laid out in a horizontal row in the LEFT HALF of the panel only (nothing to their right on this row) at Y=58% (below vertical center):
- X=8.9%, Y=57.9% — label "VOL 1" [ICON POSITION — text descends 3mm below icon]
- X=21.6%, Y=57.9% — label "VOL 2" [ICON POSITION — text descends 3mm below icon]
- X=34.3%, Y=57.9% — label "VOL 3" [ICON POSITION — text descends 3mm below icon]
- X=47.0%, Y=57.9% — label "VOL 4" [ICON POSITION — text descends 3mm below icon]

Each should look like a small round trimmer/knob glyph with its real drill diameter implied (9.2mm on a 160mm-wide panel — small, precise, not a big chunky knob), plus the glowing cyan treatment. The ikon itself (glowing ring, central hole indicator) remains at Y=57.9%. Only the text label "VOL 1", "VOL 2", "VOL 3", "VOL 4" descends approximately 3mm below the icon to improve spacing in the lower section.

The RIGHT HALF of the row (X > 55%) has no volume controls — that's where the wordmark/subtitle from above goes.

The remaining components are REAL, but they are NOT drilled on this panel — they sit on other faces of the enclosure (front/back walls). Mark them with a visibly DIFFERENT, quieter treatment: no glow, a dashed outline instead of solid, and the convention is understood without repeated explanatory text:
- X=69.4%, Y=6.7% — label "USB POWER" (USB-C connector)
- X=10.9%, Y=6.5% — label "IN 1"
- X=19.0%, Y=6.5% — label "IN 2"
- X=27.1%, Y=6.5% — label "IN 3"
- X=35.3%, Y=6.5% — label "IN 4"
- X=88.5%, Y=92.6% — label "HEADSET"
- X=9.6%, Y=95.7% — label "MUTE" (simplified from "MUTE MIC")
- X=24.4%, Y=95.7% — label "OUT 1" (simplified from "MIC OUT 1")
- X=32.3%, Y=95.7% — label "OUT 2" (simplified from "MIC OUT 2")
- X=41.3%, Y=95.7% — label "OUT 3" (simplified from "MIC OUT 3")
- X=48.8%, Y=95.7% — label "OUT 4" (simplified from "MIC OUT 4")
- X=60.9%, Y=95.9% — label "VOL MIC" (slightly larger dashed/translucent knob than the VOL 1–4 ones)

TYPOGRAPHY & LABELS:
Every marked component gets only its short functional label (given above, verbatim, upper case, English). Keep label text small and out of the way of neighboring marks — prefer short leader lines from the mark to its label. The rest of the sticker's copy (title, subtitle) is in Portuguese — only the per-component tags are in English.

DO NOT include any legend at all (do not write "Furo real nesta chapa", "Referência — montado em outra face do gabinete", or any similar explanatory key).

DO NOT include: any print-setup instructions, calibration bars, ruler graphics, "scale 100%" text, or any technical disclaimer text anywhere in the image. Leave a clean, empty margin strip along the very bottom of the panel (about 8% of panel height) with no graphic elements — that space is reserved for print-scale information added separately afterward.

Professional high-end audio equipment faceplate sticker, clean technical poster style, landscape orientation exact aspect ratio 1.195:1 (160.09:133.96), fill entire frame edge-to-edge with no margins or letterboxing, rounded corners radius approximately 3% of height. Matte dark charcoal-gray aluminum panel background with subtle brushed metal texture, restrained cool neutral palette (deep graphite, soft silver, muted cyan accents only for emphasis), generous whitespace, confident minimalist typography.
Four small quiet metallic M3 screw heads as subtle low-contrast silver dots at exact positions: top-left 3.7% x 4.5%, top-right 96.3% x 4.5%, bottom-left 3.8% x 96.2%, bottom-right 97.4% x 96.2%. No callouts on screws.
Four real input-volume trimmer positions in left half only, horizontal row at Y≈58%: VOL 1 at 8.9% x 57.9%, VOL 2 at 21.6% x 57.9%, VOL 3 at 34.3% x 57.9%, VOL 4 at 47.0% x 57.9%. Each shown as precise small circular 9.2mm-scale trimmer glyph with glowing cyan ring and tiny central hole icon suggesting drill-through. Icons remain at Y=57.9%. Text labels descend 3mm below icons for improved bottom-section spacing. No reference text or legend explaining the treatment. These four receive the strongest visual treatment.
Right half of that row (X>55%) left completely empty for title.
Title wordmark "MeetingHub-4" in clean confident technical sans-serif, medium weight, silver-white, positioned in the otherwise empty right-center area. Directly beneath it the one-line Portuguese subtitle in smaller lighter weight: "Hub de áudio para reunião — compartilha um headset entre até 4 notebooks."
All other components marked with quieter treatment: thin dashed silver outlines, no glow, translucent. Exact positions and uppercase English labels only (no extra tags or explanatory text of any kind):

USB POWER (USB-C style connector icon) at 69.4% x 6.7%
IN 1 at 10.9% x 6.5%, IN 2 at 19.0% x 6.5%, IN 3 at 27.1% x 6.5%, IN 4 at 35.3% x 6.5%
HEADSET (headset jack icon) at 88.5% x 92.6%
MUTE (mute microphone icon) at 9.6% x 95.7%
OUT 1 at 24.4% x 95.7%, OUT 2 at 32.3% x 95.7%, OUT 3 at 41.3% x 95.7%, OUT 4 at 48.8% x 95.7%
VOL MIC (slightly larger dashed translucent knob) at 60.9% x 95.9%

Every component label is short, uppercase, English, Behringer/Focusrite style, placed with short thin leader lines so text never collides. Absolutely no coordinate percentages printed anywhere. No legends, no scale bars, no calibration marks, no print instructions, no disclaimers. Clean empty horizontal strip along the very bottom ≈8% of panel height with zero graphic elements.
Ultra-precise layout matching the percentage coordinates for placement only, high legibility, professional product identification sticker ready to print and glue, 1800px+ on long edge, photorealistic technical illustration quality.

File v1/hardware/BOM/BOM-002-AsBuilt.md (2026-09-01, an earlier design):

# BOM-002 - As-Built Bill of Materials

Version: 1.0
Status: Final — matches the final 4-layer PCB (complete and validated layout)

Supersedes: BOM-001 (conceptual list, prior to the real schematic)

# 1. Purpose

Record the actual bill of materials, extracted directly from the KiCad
schematic (5 sheets: POWER, TRRS_INPUTS, AUDIO_MIXER, HEADPHONE_AMP,
MIC_SWITCHING), with reference, value, and footprint for each component,
plus the items added directly on the PCB during layout (mounting holes
and GND test point).

Raw file: [BOM-MeetingHub-4-v1.csv](BOM-MeetingHub-4-v1.csv)

# 2. Summary

- 75 distinct physical items (36 rows after grouping by value+footprint):
  70 schematic components + TP2 (GND test point) + MH1-4
  (M3 mounting holes) - these last 5 have no schematic symbol
  since they are mechanical-only, added directly on the PCB (see PCB-001
  Phases 3.3.3 and 8).
- 100% of components have an assigned footprint (except GND symbols)
- All active and passive components are THT, favoring manual assembly

# 3. Footprint selection notes

- **J1** (USB-C): `Connector_USB:USB_C_Receptacle_GCT_USB4085` - common
  part, used in various open-hardware projects.
- **J2-J6** (3.5mm TRRS, 4-pole): `Connector_Audio:Jack_3.5mm_PJ320D_Horizontal`
  - metallic panel jack. Mechanically confirm against the actual purchased
  part before routing the PCB.
- **K1-K4** (relay): `Relay_THT:Relay_SPDT_Omron_G5V-1` - official
  footprint for the real G5V-1.
- **RV1-RV5** (dual potentiometer): `Potentiometer_THT:Potentiometer_Alps_RK097_Dual_Horizontal`
  - check alignment against the front panel holes.
- **SW1-SW5** (MUTE + laptop selection): `Connector_JST:JST_XH_B2B-XH-A_1x02_P2.50mm_Vertical`
  - switches are located on the panel, wired to the board (not PCB-mounted
  buttons).
- **U1, U2** (NE5532 / NJM4556A): `Package_DIP:DIP-8_W7.62mm` - DIP-8 to
  ease manual assembly of the prototype (use a socket). Migrate to SOIC-8
  for series production, if it becomes necessary to reduce board area.
- **D1** (TVS protection): footprint `Diode_THT:D_DO-41_SOD81`; the actual
  purchased value is PTVS5V0Z1USK (the symbol used in the library is the
  generic ZPYxx, without altering pinout/geometry).
- **TP1, TP2** (test points): `TestPoint:TestPoint_THTPad_D1.5mm_Drill0.7mm`
  - TP1 on the +5V_AUDIO net (POWER sheet), TP2 on the GND net, near U1.
    TP2 is a mechanical-only footprint, added directly on the PCB (no
    schematic symbol) - see PCB-001 Phase 8 for the history of why it
    exists (generic GND test point, useful for measurement).
- **MH1-MH4** (enclosure mounting holes): `MountingHole:MountingHole_3.2mm_M3`
  - unplated 3.2mm hole for M3 screw, one at each corner of the board,
    6mm margin from the edge. Mechanical-only, no schematic symbol - see
    PCB-001 Phase 3.3.3 for the exact positions.

# 4. Manufacturing status

- ✅ Complete PCB layout (placement of jacks, potentiometers,
  relays; audio/power separation by enclosure face - see PCB-001
  Phases 3-5).
- ✅ Real DRC (via KiCad, confirmed 23/07/2026): 0 unconnected pads,
  0 errors. Only 5 remaining warnings are cosmetic and accepted
  (library discrepancy for potentiometers RV1-RV5 - see PCB-001
  Phase 8).
- ✅ Board migrated to 4 layers (dedicated GND and +5V_AUDIO planes on
  the inner layers - see PCB-001 Phase 6).
- ✅ Gerbers, drill file (Excellon), and placement files exported and
  validated via `kicad-cli` (no export errors).
- ✅ ERC run (via KiCad, by the user), in two rounds, and all
  real errors were fixed - see PCB-001 Phase 11 for the detail of
  each one:
  - **TP1 was never actually connected to +5V_AUDIO** (neither in the
    schematic nor on the PCB) - the pin was visually placed over an
    existing wire without an electrical junction. Fixed in both files.
  - **TP2 also wasn't connected to GND on the PCB** (mechanical-only
    footprint, added without a net). Fixed - now actually on the GND net.
  - `power_pin_not_driven` on U1 (V+/V- pins): fixed with two
    `power:PWR_FLAG` symbols in POWER.kicad_sch. On the first attempt the
    +5V_AUDIO flag was connected on the wrong side of fuse F1 (it still
    resolved the GND side, but not V+) - fixed on the second round, by
    moving the flag to the same node that already feeds TP1 and the
    +5V_AUDIO global label.
  - `lib_symbol_issues` on J2-J6 (AudioJack4): the symbol was referenced
    as `Connector:AudioJack4`, a library that no longer exists at that
    location in current KiCad (the symbol was moved to `Connector_Audio`).
    Fixed the `lib_id` to `Connector_Audio:AudioJack4` in TRRS.kicad_sch
    (J2-J5) and HPAMP.kicad_sch (J6) - geometry and pins checked byte by
    byte against the system library before the change.
  - `pin_not_connected` (error, not warning) on the 9 data/CC/SBU/shield
    pins of J1 (USB-C: D+, D-, CC1, CC2, SBU1, SBU2, SHIELD) and on pin 10
    of relays K1-K4 (duplicate pin of the reverse contact of the G5V-1,
    not used in this SPDT topology): both cases are intentional (J1 is
    only used as a power input - see DR-002/DR-003), but were listed as
    an **error** regardless. Fixed by adding explicit "no connect"
    markers on each pin, the standard KiCad way of saying "I know this
    pin is intentionally floating".
  - `endpoint_off_grid` (233 warnings, practically every pin/wire in the
    schematic): root cause identified - the entire schematic was drawn
    at round positions in millimeters, which are not multiples of the
    1.27mm (50 mil) grid that ERC uses for this check. Fixed via a script
    that realigns every symbol, wire, and junction across the 5 sheets to
    the nearest multiple of 1.27mm, preserving the electrical topology
    (two points that already coincided still coincide, because they use
    the same deterministic rounding function). **Validated with
    `kicad-cli sch export netlist` before/after - the project's 72 nets
    match node by node, none changed.** A single case needed manual
    adjustment: the realignment brought D1 too close to the D+ pin of J1
    (which sits next to it, unused), almost touching the two - fixed by
    moving D1 one extra grid step away.
  - **Confirmed by the user via a real KiCad report (23/07/2026,
    16:27): 0 errors, 0 warnings.** ERC 100% clean.

**J1 orientation corrected 2026-08-12**: the user compared our layout against a
real photo of the purchased part (LCSC C7095263 / GCT USB4085-GF-A) and the
official GCT datasheet, and found the connector was mounted backwards - the
mating face overhung into the board interior instead of past the board edge
(this is what JLCPCB's "please confirm J1 orientation" DFM question,
SMT026081260178_Y11, was actually flagging - previously misjudged as correct
from the layout data alone, without a physical-part comparison). J1 needed a
180° flip, which is **not** a safe operation to do as a single naive rotation
for this footprint: the 16 signal pins are symmetric under 180° (USB-C's
VBUS/GND pinout is reversible by design - A1↔B1, A4↔B4/A9↔B9, A12↔B12 are all
the same net), but the 4 shield/mounting legs are asymmetric front-to-back
(clustered on one side, anchoring the overhanging shell), so a plain in-place
rotation pushes them off the board edge - caught via the KiCad Python API
before it was saved to the real file. Final placement (now at 171.04, 93.98mm,
180°, board top edge at y=85mm) and the VBUS reroute to F1/D1 were done
directly in KiCad by the user, after an automated first pass was found to
route a couple of local jogs too tight and was reverted in favor of doing it
by hand. Validated 2026-08-12: **KiCad DRC reports 0 errors** (only cosmetic
silkscreen-over-solder-mask and footprint-library-mismatch warnings, none
related to this fix, plus one pre-existing dangling GND stub near
RV5/SW1 unrelated to J1, present since before this session). Independently
cross-checked: VBUS (Net-(D1-K)) is a single connected net spanning
J1-F1-D1 with no dangling ends, and GND reaches J1's 4 pads through the
In1.Cu zone pour at the new locations (confirmed inside the zone's outline).
The 4 shield/mounting pads (unconnected, no schematic net) are no longer tied
together by copper - that connection served no electrical function and was
dropped during the reroute. See gerbers v13.0 and BOM-PCBA-MeetingHub-4-v1.csv
item 8 for detail.

**Real pending item, outside the scope of this BOM**: final mechanical
verification of the above footprints (J1-J6, K1-K4, RV1-RV5) against the
datasheets of the parts actually purchased, at the time of purchase/receipt -
recommended even with the layout validated, since small variations between
suppliers of the same component may exist.

**J2-J6 pad size corrected 2026-08-12**: this is exactly the kind of
discrepancy the pending item above warned about, and it surfaced via a
JLCPCB DFM check (SMT026081260178_Y11) rejecting J2-J6 as
"package doesn't match pads, unable to assemble". Root cause: the KiCad
stock footprint (`Jack_3.5mm_PJ320D_Horizontal`) uses 1.2x2.5mm SMD pads,
but the HanElectricity PJ-320D datasheet for the actually-purchased part
(C22459515) specifies 1.5x3.0mm pads. Fixed by resizing the 4 SMD pads
(R1/R2/S/T) on all 5 jacks to 1.5x3.0mm (3.0x1.5mm on J6, since that
instance's rotation is mirrored relative to J2-J5, confirmed empirically
via the KiCad Python API rather than assumed). The larger pads collided
with 4 already-routed traces (clearance <0.2mm or outright overlap): J3/S,
J4/S and J6/T were resolved with a small pad copper offset (0.3-0.4mm,
footprint anchor/CPL position untouched); J6/S required rerouting the
adjacent GND segment around the enlarged pad, since a straight GND trace
ran directly through the pad's new footprint. Verified with a script-based
geometric check (pad/track bounding boxes and segment distances, KiCad
Python API) across all J2-J6 pads: 0 clearance violations. See gerbers
v11.0 and BOM-PCBA-MeetingHub-4-v1.csv item 9 for detail.

**Full-circuit validation, 2026-08-12**: after the J1/J2-J6 fixes above were
committed, ran a complete independent re-validation (not just the areas
touched): whole-board copper clearance (every pad/track pair, different
nets, using KiCad's own `SHAPE::Collide` geometry engine rather than
bounding-box approximations - 757 copper items, 0 violations at the
project's real 0.15mm netclass clearance, see `net_settings` in the
`.kicad_pro` - note this is 0.15mm, not the 0.2mm zone `connect_pads`
value that was mistakenly used as the threshold during the J1/J2-J6 work
above), 0 unconnected pads/ratsnest lines, 0 pads outside the board
outline, all GND/+5V_AUDIO pads confirmed inside their zone outlines, 0
duplicate/overlapping drill holes, and a schematic-vs-PCB netlist
cross-check (net-by-net membership, not just net names).

That cross-check turned up one real, pre-existing bug, unrelated to
today's other fixes and present since before this session (confirmed
against the git history) despite this same document's July changelog
above claiming it was fixed: **TP1 (the +5V_AUDIO test point) was not
actually electrically connected** in the schematic. It sits at the exact
midpoint of a wire between the `+5V_AUDIO` global label and F1, with a
junction dot drawn at that point, which looks correct and is why it was
missed visually - but KiCad's own netlist generator consistently placed
TP1 on its own isolated `unconnected-(TP1-Pad1)` net instead (verified
with isolated minimal test schematics to rule out a parsing mistake on
our end, then reproduced and fixed on a scratch copy before touching the
real file). Fixed by adding an explicit local label `+5V_AUDIO` at TP1's
pin position in `POWER.kicad_sch` (schematic-only change, no PCB/copper
impact - the PCB footprint for TP1 was already on the correct net).
Re-verified: TP1 now appears correctly in the +5V_AUDIO net, and the only
remaining schematic-vs-PCB net difference is TP2 (GND), which is expected
since TP2 is mechanical-only with no schematic symbol (see above). This
particular bug has no functional consequence (TP1 is a measurement point,
not part of any signal path) but would have made voltage checks at TP1
misleading. Not yet regenerated into a gerber version, since it doesn't
touch the PCB.

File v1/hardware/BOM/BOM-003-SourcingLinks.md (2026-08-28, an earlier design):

# BOM-003 - Lista de Compras (MeetingHub-4)

Verificado em estoque na LCSC/JLCPCB em 2026-08-06. SW1-SW5 e RV1-RV4 atualizados em 2026-08-07; C2/C3/C16/C19 atualizado em 2026-08-08 (ver notas abaixo).

| Componente | Referência | Código | Link | Quantidade |
|---|---|---|---|---|
| Capacitor cerâmico 100nF SMD 0603 | C1, C4, C21 | LCSC C14663 | https://www.lcsc.com/product-detail/C14663.html | 3 |
| Capacitor eletrolítico 10uF THT D5xL11mm (CX KM106M016D11RR0VH2FP0) — substitui UD2E100M1010 (era SMD D10x10.2mm, colidia com vizinhos no footprint THT da placa) | C2, C3, C16, C19 | LCSC C43799 | https://www.lcsc.com/product-detail/C43799.html | 4 |
| Capacitor cerâmico X7R 1uF THT | C5, C6, C7, C8, C9, C10, C11, C12, C13, C14, C15, C18 | LCSC C2167638 | https://www.lcsc.com/product-detail/C2167638.html | 12 |
| Capacitor eletrolítico 220uF | C17, C20 | LCSC C2063 | https://www.lcsc.com/product-detail/C2063.html | 2 |
| Diodo TVS 5V unidirecional SMD SOD-323 | D1 | LCSC C553448 | https://www.lcsc.com/product-detail/C553448.html | 1 |
| Diodo 1N4148 | D2, D3, D4, D5 | LCSC C402212 | https://www.lcsc.com/product-detail/C402212.html | 4 |
| Fusível PTC 500mA | F1 | LCSC C1562150 | https://www.lcsc.com/product-detail/C1562150.html | 1 |
| Conector USB-C | J1 | LCSC C7095263 | https://www.lcsc.com/product-detail/C7095263.html | 1 |
| Conector TRRS 3.5mm | J2, J3, J4, J5, J6 | LCSC C22459515 | https://www.lcsc.com/product-detail/C22459515.html | 5 |
| Relé SPDT 5V | K1, K2, K3, K4 | LCSC C28695 | https://www.lcsc.com/product-detail/C28695.html | 4 |
| Resistor 10k | R1-R12 | LCSC C5618323 | https://www.lcsc.com/product-detail/C5618323.html | 12 |
| Resistor 100k | R13, R17 | LCSC C1364475 | https://www.lcsc.com/product-detail/C1364475.html | 2 |
| Resistor 1k | R14, R15, R18, R19 | LCSC C120055 | https://www.lcsc.com/product-detail/C120055.html | 4 |
| Resistor 47R | R16, R20 | LCSC C2896824 | https://www.lcsc.com/product-detail/C2896824.html | 2 |
| Potenciômetro duplo 10k audio (Alps RK09L1240A12) — corpo compacto/quadrado (14.5x17.9mm), montagem vertical | RV1, RV2, RV3, RV4 | LCSC C380211 | https://www.lcsc.com/product-detail/C380211.html | 4 |
| Potenciômetro duplo 10k audio (Alps RK09712200HA) — corpo largo (29.6x9.5mm), montagem horizontal (90°, painel frontal, master) | RV5 | LCSC C470545 | https://www.lcsc.com/product-detail/C470545.html | 1 |
| Chave push com retenção (push-on/push-off / self-locking), THT ângulo reto, DPDT — PS-22F03 / A03 — usada como SW2-SW5 (seletoras). **2026-08-28**: trocada de momentânea (TS665ZJ) para latching, para não precisar "segurar" o botão. **SW1 (MUTE) removido**: sem seletora travada = todos os relés desligados = mic mudo (o próprio "nenhum selecionado" é o mute). Footprint `SW_PushLock_PS-22F03` é RASCUNHO — conferir dimensões do corpo/atuador e a posição dos pinos COM/NO no datasheet C2848947 antes de encomendar. MPN alt: HOOYA PS-22F03-N-B (C19190927) | SW2, SW3, SW4, SW5 | LCSC C2848947 | https://www.lcsc.com/product-detail/C2848947.html | 4 |
| Amplificador operacional duplo NE5532 | U1 | LCSC C2987282 | https://www.lcsc.com/product-detail/C2987282.html | 1 |
| Amplificador operacional duplo NJM4556A | U2 | LCSC C2838125 | https://www.lcsc.com/product-detail/C2838125.html | 1 |
| Knobs para RV1-RV5 (eixo chato 6mm) — **compatibilidade confirmada 2026-08-11**: conferi os desenhos mecânicos oficiais Alps de ambas as peças — RK09L1240A12 (RV1-4) e RK09712200HA (RV5) usam o mesmo eixo padrão Alps "平轴" (flat shaft), ø6mm com corte plano de 4.5mm, 12mm de eixo exposto. Mesmo tipo/diâmetro nas duas, esse knob serve pros 5 | RV1-RV5 | RS Online | https://ie.rs-online.com/web/p/potentiometer-knobs/7777353 | 5 |
| Capa/botão para SW2-SW5 (seletoras) — a PS-22F03/A03 costuma vir com uma capa vermelha; capas coloridas avulsas ("A03 switch cap") existem na LCSC/AliExpress se quiser diferenciar as 4 | SW2-SW5 | — | — | 4 (opcional) |
| Pés de borracha (base da placa) | — | genérico, loja local/AliExpress | — | 4 |

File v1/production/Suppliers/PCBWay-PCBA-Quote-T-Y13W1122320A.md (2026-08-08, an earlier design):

# PCBWay PCBA Quotation — T-Y13W1122320A

Status: Received 2026-08-07 — reviewed against [BOM-002-AsBuilt](../../hardware/BOM/BOM-002-AsBuilt.md) and [BOM-003-SourcingLinks](../../hardware/BOM/BOM-003-SourcingLinks.md). **Verdict: covers the full assembly BOM correctly; 3 line items need clarification with PCBWay before accepting — see §4.**

Note: this is an **assembly (PCBA)** quote from PCBWay. [PCBWay-OrderGuide.md](../PCBWay-OrderGuide.md) currently tells the user to source assembly from JLCPCB instead and use PCBWay only for the bare board — if PCBWay's PCBA price/lead time here is preferred, that guide should be updated to match (not done as part of this review; flagging so it isn't forgotten).

# 1. Quotation summary

| Field | Value |
|---|---|
| Product No. | T-Y13W1122320A |
| Quantity quoted | 5 assembled boards |
| Component cost | $279.41 |
| Assembly cost | $29.00 |
| PCB cost | $94.56 |
| Discount (V0 member) | $0.00 (0%) |
| **Total (5 units)** | **$402.97** |
| Cost per board | ≈ $80.59 |
| Lead time | 27-29 days (SW2-SW5 consigned parts quoted separately at 7-10 workdays) |

# 2. Line items (as quoted)

| # | Designator | Qty/bd | Manufacturer | Mfg Part # | Package | Unit Price (×5bd) | Total | Notes |
|---|---|---|---|---|---|---|---|---|
| 1 | C1, C4, C21 | 3 | YAGEO | CC0603KRX7R9BB104 | C_0603_1608Metric | $0.059 | $0.885 | THT→SMD change, documented |
| 2 | C2, C3, C16, C19 | 4 | Honor Elec | UD2E100M1010 | CP_Radial_D5.0mm_P2.00mm | $0.289 | $5.780 | |
| 3 | C5-C15, C18 | 12 | VISHAY | K105K20X7RF5TH5 | C_Disc_D5.0mm_W2.5mm_P2.50mm | $0.909 | $54.540 | ⚠️ price outlier, see §4 |
| 4 | C17, C20 | 2 | Chengx | KM227M035F12RR0VH2FP0 | CP_Radial_D8.0mm_P3.50mm | $0.069 | $0.690 | |
| 5 | D1 | 1 | Nexperia | PTVS5V0Z1USKYL | D_SOD-323 | $0.242 | $1.210 | THT→SMD change, documented |
| 6 | D2, D3, D4, D5 | 4 | LGE | 1N4148 | D_DO-35_SOD27_P7.62mm_Horizontal | $0.032 | $0.640 | |
| 7 | F1 | 1 | Bourns | MF-RG500 | Fuse_Bourns_MF-RG500 | $1.892 | $9.460 | ⚠️ price outlier, see §4 |
| 8 | J1 | 1 | GCT | USB4085-GF-A | USB_C_Receptacle_GCT_USB4085 | $1.691 | $8.455 | ⚠️ CC pulldown note, see §4 |
| 9 | J2, J3, J4, J5, J6 | 5 | HanElectricity | PJ-320D | Jack_3.5mm_PJ320D_Horizontal | $0.062 | $1.550 | |
| 10 | K1, K2, K3, K4 | 4 | Omron | G5V-1-DC5 | Relay_SPDT_Omron_G5V-1 | $0.784 | $15.680 | |
| 11 | R1-R12 | 12 | YAGEO | CFR-25JB-52-10K | R_Axial_DIN0207... | $0.037 | $2.220 | |
| 12 | R13, R17 | 2 | YAGEO | MFR-25FBF52-100K | R_Axial_DIN0207... | $0.047 | $0.470 | |
| 13 | R14, R15, R18, R19 | 4 | CCO | CF1/4W-1KR-J | R_Axial_DIN0207... | $0.041 | $0.820 | substituted, documented |
| 14 | R16, R20 | 2 | VO | CR1/4W-47R-OT52 | R_Axial_DIN0207... | $0.075 | $0.750 | |
| 15 | RV1-RV4 | 4 | Alps Alpine | RK09712200HA | Potentiometer_Alps_RK097_Dual_Horizontal | $4.328 | $86.560 | mounted vertical (0°) |
| 16 | RV5 | 1 | Alps Alpine | RK09712200HA | Potentiometer_Alps_RK097_Dual_Horizontal | $4.328 | $21.640 | mounted horizontal (90°), front panel |
| 17 | SW1 | 1 | Omron | B3F-4005 | SW_PUSH-12mm | $0.604 | $3.020 | substituted, documented |
| 18 | SW2, SW3, SW4, SW5 | 4 | CW Industries | GPTS203211B | SW_CW_GPTS203211B | $2.970 | $59.400 | ⚠️ marked CONSIGNED, see §4 |
| 19 | U1 | 1 | HGSEMI | NE5532N | DIP-8_W7.62mm | $0.402 | $2.010 | socket recommended |
| 20 | U2 | 1 | JRC | NJM4556A | DIP-8_W7.62mm | $0.725 | $3.625 | socket recommended |

# 3. Match against the project BOM

Checked every designator, quantity, manufacturer part number, and footprint against [BOM-002-AsBuilt](../../hardware/BOM/BOM-002-AsBuilt.md) (as-designed) and [BOM-003-SourcingLinks](../../hardware/BOM/BOM-003-SourcingLinks.md) (as-sourced, 2026-08-06):

- **All 20 PCBA line items match** — same designators, quantities, LCSC codes (where applicable), and footprints as BOM-003, including the three documented 2026-08-06 substitutions (R14/15/18/19, RV1-5, SW1) and the two THT→SMD footprint changes (C1/C4/C21, D1).
- **Cost arithmetic checks out**: each `Total` = `Unit Price × Qty × 5 boards`, and the 20 line totals sum to $279.405 ≈ the quoted $279.41 component cost.
- Knobs and rubber feet (BOM-003 §"mechanical") are correctly **absent** from this quote — they aren't PCBA parts, the user sources them separately.
- SW2-SW5 correctly flagged as not sourceable through LCSC, consistent with BOM-003's own note.

# 4. Items to clarify with PCBWay before accepting

1. **SW2-SW5 consigned but priced ($59.40 total)** — the Vendor Part# column says "CONSIGNED - not on LCSC", meaning the user is expected to buy and ship these 4 switches to PCBWay directly (as BOM-003 also states). A consigned part shouldn't carry a per-unit *component* price from the assembler — ask PCBWay whether $2.970/unit is a **handling/placement fee** for consigned parts (common, and fine if so) or an accidental component charge for parts they don't actually source. This is 21% of the component-cost line and worth a direct answer before paying.
2. **1uF THT ceramic disc capacitor (item 3) at $0.909/unit** — high for a basic leaded ceramic cap; typical LCSC pricing for this class of part is a fraction of that even in small quantities. Worth a quick check against LCSC's own listed price for C2167638 before accepting.
3. **PTC fuse (item 7) at $1.892/unit** — same concern, this part is typically inexpensive; confirm it's not a pricing/qty entry error.
4. **Assembly cost ($29.00 for 5 boards, ~$5.80/board)** — this board is mostly THT (hand-placed, not reflow) with 75 components including 5 potentiometers, 4 relays, and 2 socketed DIP-8s. Confirm this figure genuinely includes full THT hand-soldering labor for all 5 boards, not just a base SMT setup fee — [PCBWay-OrderGuide.md](../PCBWay-OrderGuide.md) already flags that mixed THT+SMD assembly "adds cost/lead time compared to a pure-SMD board."
5. **J1 USB-C CC pulldown note is a real design gap, not just a quote caveat.** PCBWay's own note on item 8 ("some USB-C-to-C chargers may not enable VBUS without CC pulldown") matches what's in the schematic: [BOM-002-AsBuilt §4](../../hardware/BOM/BOM-002-AsBuilt.md) confirms J1's CC1/CC2 pins are explicitly marked "no connect" during the ERC cleanup — there are no 5.1kΩ pulldown resistors on CC1/CC2 anywhere in the design. As built, the board will power up reliably from USB-A-to-C cables/chargers (which supply 5V unconditionally) but **may fail to power up from a compliant USB-C-to-C source** (e.g. a laptop's own USB-C port, or a USB-C PD charger) that waits for CC-based sink detection before enabling VBUS. Not a PCBWay issue to fix — a schematic/BOM change (2× 5.1kΩ 1% resistors from CC1/CC2 to GND) would need to go through a new PCB revision if C-to-C compatibility matters.

# 5. Verdict

The quote **matches the project's as-built BOM line-for-line** and the totals are internally consistent — no missing or extra parts, no designator/footprint mismatches. It's reasonable to proceed on that basis, but get written clarification on the 3 pricing/consignment questions in §4.1-4.3 before paying, and treat §4.5 (USB-C CC pulldowns) as a known compatibility limitation of the current hardware revision, independent of this order.

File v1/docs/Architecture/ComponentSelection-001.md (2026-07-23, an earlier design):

# Phase 3 — Component Selection (Preliminary BOM)

Before drawing the schematic, we need to choose real components. The rule will be:

* components available on the market;
* good durability;
* reasonable cost;
* easy replacement;
* simple assembly.

We will create:

```text
hardware/BOM/BOM-001.xlsx
```

and also a document:

```text
docs/Architecture/ComponentSelection-001.md
```

---

## Main Components — Initial Proposal

### 1) Panel-mount TRRS Connectors

Requirement:

* 3.5 mm female P2
* metallic
* panel mounting
* CTIA standard

Quantity:

* 5 units

  * 4 laptops
  * 1 headset

Criteria:

* plated contact
* mechanical fixation via nut
* high service life

---

### 2) Volume Potentiometers

Quantity:

* 5 units

Functions:

* Laptop 1 Volume
* Laptop 2 Volume
* Laptop 3 Volume
* Laptop 4 Volume
* Master Volume

Type:

* stereo
* 10 kΩ logarithmic
* metal shaft

---

### 3) Active Mixer

Initial proposal:

**NE5532**

Quantity:

* 2 units

Use:

* left channel
* right channel

Reasons:

* excellent for audio;
* inexpensive;
* well known;
* easy to find.

---

### 4) Headphone Amplifier

Options under consideration:

**NJM4556A**

or

**TPA6120A2**

Criteria:

* low distortion;
* capability for 16–64 Ω headsets;
* stability.

For V1 I would lean toward the **NJM4556A**, for being simple and robust.

---

### 5) Microphone Selection

Main requirement:

The laptop must continue to "see" a headset.

Proposal:

Signal relay.

Candidate model:

* Omron G6K
* Panasonic TQ2

Quantity:

* 1 selection set

---

### 6) MUTE

Button:

* industrial;
* normally closed (NC).

Why?

If the button breaks, the safe default is to keep working.

---

### 7) Power Supply

Input:

USB-C 5 V

Blocks:

```text
USB-C
  |
Protection
  |
Filter
  |
5V Analog
```

---
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

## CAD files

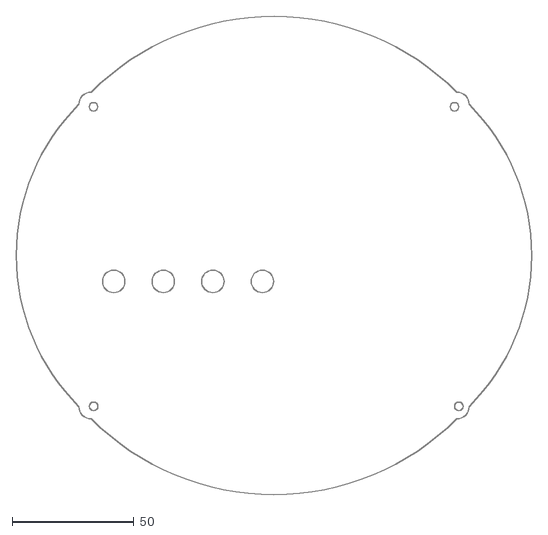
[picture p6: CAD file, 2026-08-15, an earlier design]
v1/box/mh4-acrilico-topo.dxf
211.4 x 196.1

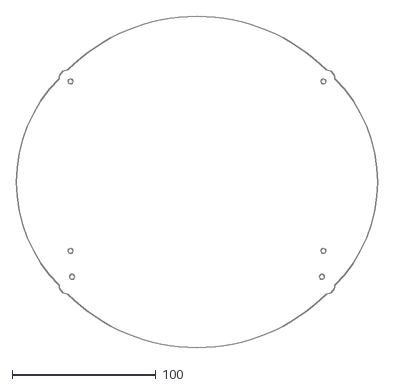
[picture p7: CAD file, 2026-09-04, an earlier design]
v2/box/mh4-acrilico-topo.dxf
251.6 x 230.6

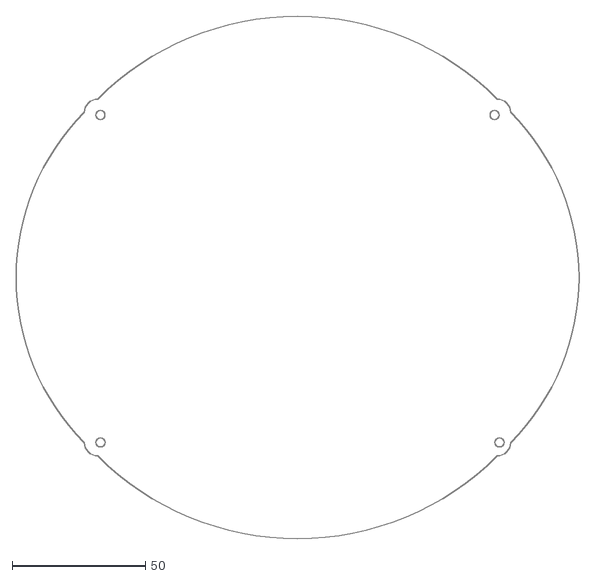
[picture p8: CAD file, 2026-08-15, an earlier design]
v1/box/mh4-acrilico-base.dxf
211.4 x 196.1

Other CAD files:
v1/mechanical/MeetingHub-4-Case.scad

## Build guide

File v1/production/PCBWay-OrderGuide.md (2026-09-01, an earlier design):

# PCBWay Guide - How to Order Board Manufacturing (for beginners)

Version: 10.0
Status: Final — updated 2026-08-11. v6.0 changes: RV1-RV5
potentiometers relaid out (2-row layout, RV1-4 vertical / RV5
horizontal), fully re-routed, C1/C4/C21/D1 footprints corrected from
THT to SMD (0603 / SOD-323), and a connection error found after
upload fixed manually in KiCad. v7.0 fixes one more mismatch caught
during a pre-purchase BOM review: D1's footprint was SOD-323, but the
actual quoted part (PTVS5V0Z1USKYL, LCSC C553448) is package
DSN1608-2/SOD964 — a different, smaller SMD footprint. Swapped to
KiCad's `Nexperia_DSN1608-2_1.6x0.8mm` footprint and re-added the via
connecting D1 to the GND plane. v8.0 fixes the cause of JLCPCB
flagging RV1-RV4 as "Unassembled" on order SMT026080860166: the
v7.0 footprint was missing the 2 mechanical "MP" legs that the real
RK09L1240A12 part has (omitted back in the 2026-08-07 revision due to
a since-resolved clearance conflict). Restored both MP pads on all 4
potentiometers and locally rerouted 3 traces (R8, R10, C13 nets) that
now ran too close to them — board re-checked at 0 DRC errors. v9.0
realigns SW1-SW5 (MUTE + 4 selectors) into a straight row pushed as
close as possible to the board's bottom edge (0.5mm clearance from
the switch body to Edge.Cuts) — was previously ~5mm further from the
edge with a slight zig-zag between switches. Required rerouting the
HEADSET_MIC bus, which used to run in the gap between the switches
and the edge — that gap is now the switch bodies themselves, so the
trace was moved to duck behind the row instead. Board re-checked at
0 DRC errors. v10.0 pushes RV5 (front-panel master volume) the same
~7.8mm closer to the edge as the switches (0.5mm body clearance to
Edge.Cuts) — J6 (headset jack) was left as-is since it was already
within 1.2mm of the edge and the remaining gain wasn't worth the
reroute risk. Required moving 2 of RV5's own signal leads (VBIAS,
MIX_R) to F.Cu with vias to clear a same-layer crossing with another
RV5 net (MIX_L) and the rerouted HEADSET_MIC bus, and simplifying the
HEADSET_MIC detour to pass south of RV5 at a constant Y instead of
cutting over it. Board re-checked at 0 DRC errors.

Step-by-step guide for ordering **bare PCB manufacturing** for the
MeetingHub-4 at PCBWay (pcbway.com), written for someone who has never
done this before. **Assembly (PCBA) is a separate vendor, JLCPCB —
see step 6.** The
technical values below (size, layers, thickness) are the **real** values
extracted from the final project - use them to check whether the site
detected everything correctly, no need to know what they mean to follow
the guide.

**File to upload**: [`hardware/Gerbers/MeetingHub-4-Gerbers-v10.0.zip`](../hardware/Gerbers/MeetingHub-4-Gerbers-v10.0.zip)
(already contains gerbers for all layers + drilling, ready for upload).
**Do not use v1.0-v9.0** — v1.0/v2.0 reflect an older 265.1x160.1mm
board revision that no longer exists; v3.0 has SW2-SW5 in the old
vertical orientation; v4.0 has the old single-row potentiometer layout
and still has THT footprints for C1/C4/C21/D1 that don't match the
SMD parts already quoted for assembly; v5.0 has a connection error
that was fixed in v6.0; v6.0 still has the wrong D1 footprint
(SOD-323 instead of the real DSN1608-2/SOD964 part), fixed in v7.0;
v7.0 has RV1-RV4 missing their mechanical MP legs, which is what got
them flagged Unassembled by JLCPCB — fixed in v8.0; v8.0 has SW1-SW5
sitting ~5mm further from the board edge than necessary — fixed in
v9.0; v9.0 has RV5 sitting ~7.8mm further from the edge than
necessary — fixed in v10.0.

# Board technical specifications (to check against what the site detects)

| Item | Value |
|---|---|
| Dimensions | 160.19 x 134.06 mm |
| Layers | **4** |
| Final thickness | 1.6 mm |
| Material | FR-4 (standard) |
| Minimum hole | 0.6 mm (within standard, no special option needed) |
| Solder mask color | your choice (green is the cheapest/fastest standard) |
| Silkscreen color | white (standard) |
| Surface finish | HASL (with lead) recommended - cheaper; the board is mostly THT with a handful of SMD passives (see note below), HASL still works fine for both |
| Copper weight | 1oz (standard) |
| Suggested quantity | 5 units (PCBWay's common minimum for a prototype; leaves spare boards in case of an assembly error) |

# Step by step

## 1. Create an account

Go to [pcbway.com](https://www.pcbway.com) and create an account (email +
password, or login via Google). No company registration (CNPJ) or business
info needed - a personal account works.

## 2. Open the PCB instant quote

In the top menu, look for **"PCB Instant Quote"** (or "Quote Now" on the
home page, PCB section). This opens the board configuration form.

## 3. Upload the gerber file

In the form, there's a button labeled **"Add Gerber File"** (or "Upload
Gerber"). Upload the file `MeetingHub-4-Gerbers-v10.0.zip` (no need to
unzip it, the site accepts the zip directly).

PCBWay tries to automatically detect the size and number of layers from
the file. **Check**:
- **Dimension**: should show something close to `160.19 x 134.06 mm`. If
  it shows a very different value, the upload probably failed -
  try re-uploading before continuing.
- **Layer**: should be set to **4**. If it shows 2, the site didn't read
  the inner layers correctly - do not proceed, let me know.

If for some reason the site doesn't detect it automatically, fill it in
manually using the values from the table above.

## 4. Review/adjust the manufacturing options

On the same screen (or in the "Specification" tab), check each field
against the technical table above. The most important fields:

- **Layers**: 4
- **Material**: FR-4
- **Thickness**: 1.6mm
- **Min Track/Spacing**: you can leave the site's default (6/6mil) - the
  project doesn't use anything finer than that.
- **Min Hole Size**: you can leave the default (0.3mm) - the smallest
  hole in the project is 0.6mm, well within range.
- **Solder Mask**: choose whichever color you prefer (green is the
  standard, cheapest and fastest; other colors may cost a bit more/take
  a bit longer).
- **Silkscreen**: white (standard).
- **Surface Finish**: **HASL(with lead)** - cheaper, works well
  for manual soldering (which is how this prototype was designed to be
  assembled, with sockets for ICs U1/U2).
- **Via Process**: **Tenting vias** (default, cheaper).
- **Board Outline Tolerance**: you can leave it at default.
- Everything else (Panelization, Castellated Holes, Edge Plating,
  etc.): **don't check any extra option** - this project doesn't need
  any of them.

## 5. Quantity

Choose the quantity (suggestion: **5 units** - it's PCBWay's common
minimum for this size range, and it's good to have spare boards in case
something goes wrong during the first assembly/soldering).

## 6. Assembly (PCBA) - if you want the board pre-assembled

**Assembly is not done through PCBWay for this project — use
[JLCPCB](https://jlcpcb.com) instead.** PCBWay in this guide is only
for the bare board (steps 1-5, 7-9 above). JLCPCB has direct
integration with the LCSC parts catalog, which is what
[BOM-003-SourcingLinks](../hardware/BOM/BOM-003-SourcingLinks.md)'s
LCSC codes are for — pick JLCPCB's own **"PCB Assembly"** flow at
jlcpcb.com, upload the gerbers there too (JLCPCB will also fabricate
the bare board as part of that flow, so this becomes a single order
instead of two separate ones with two vendors).

**Important note**: this project is **mostly THT**, with a small
number of SMD parts (C1/C4/C21, D1 — no THT stock exists for those 2
specific values at any supplier; J2-J6 also has SMD signal pads on an
otherwise THT jack). JLCPCB does handle mixed THT+SMD assembly, but
THT parts are placed by hand (not reflow) and add cost/lead time
compared to a pure-SMD board — confirm the quote reflects this before
paying.

Files you'll need to upload for the assembly quote (in addition to the
gerber zip from step 3, uploaded to JLCPCB instead of PCBWay):

- **[`hardware/BOM/BOM-PCBA-MeetingHub-4-v1.csv`](../hardware/BOM/BOM-PCBA-MeetingHub-4-v1.csv)**
  - bill of materials with manufacturer/part number, in the format
    assembly services usually request.
- **[`hardware/Gerbers/MeetingHub-4-Placement.csv`](../hardware/Gerbers/MeetingHub-4-Placement.csv)**
  - X/Y/rotation position of each component on the board (the
    "Component Placement" / "Pick and Place" file, required even for
    THT).

**This section is superseded** by
[BOM-003-SourcingLinks](../hardware/BOM/BOM-003-SourcingLinks.md) — a
straight shopping-list table (component, code, link, quantity) for
everything needed. All parts are confirmed in stock at LCSC as of
2026-08-06, with one exception:
- **SW2-SW5** (selector switches): the original CW Industries
  GPTS203211B is out of stock at LCSC with no in-stock pin-compatible
  equivalent found — buy 4 units separately (DigiKey CW181-ND or CW
  Industries direct) and consign them to the assembler.

If you'd rather assemble it yourself instead of paying for the assembly
service: the bare board alone (without this service) is sufficient, and
the original BOM in
[BOM-002-AsBuilt](../hardware/BOM/BOM-002-AsBuilt.md) recommends using
sockets for ICs U1/U2 to make it easier.

## 7. Add to cart and review the price

After confirming the options, click **"Add to Cart"** (or
similar) and review the final price before continuing - it changes
depending on the mask color, finish, and quantity chosen.

## 8. Payment and shipping

Choose the shipping method (PCBWay generally offers a few carrier
options with different price/lead times - the cheapest one usually
takes much longer to arrive in Brazil). Complete the payment
(international credit cards are usually accepted directly).

**Watch out for import taxes**: since it ships from outside Brazil, it
may be held at customs and charged import tax (ICMS + fees) on
delivery, depending on the declared value and the chosen carrier - this
is an import matter, not something related to PCBWay itself; if you've
never imported anything before, it's worth researching how it works
before finalizing the order (e.g., the Remessa Conforme program, if
the store is registered).

## 9. Tracking the order

PCBWay sends email updates at each stage (production, inspection,
shipping, tracking code). The standard manufacturing lead time is
usually a few business days (varies with the production queue);
international shipping tends to be the slowest part of the whole
process.

# When the board arrives

1. Visually check it against Phase 1 of [TEST-001](../docs/Architecture/TEST-001-BringUpGuide.md)
   before mounting any component (also checking whether the
   silkscreen/holes match what's expected).
2. Follow [TEST-001](../docs/Architecture/TEST-001-BringUpGuide.md) in
   order (visual inspection → continuity → first power-up → functional
   test) to assemble and validate the board safely.

# Note about this guide

The PCBWay website's interface changes from time to time (button names,
field positions). If any step doesn't exactly match what you see on
screen, **always check against the technical specifications at the top of
this document** (those values are the real ones, extracted from the
final project file) rather than the step-by-step text, and let me know
if anything looks off before finalizing the order.

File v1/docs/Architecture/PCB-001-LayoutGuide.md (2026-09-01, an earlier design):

# PCB-001 - Layout Guide (Phases 2-10)

Version: 1.0
Status: Final — layout complete, routed and validated (0 unconnected, 0 DRC errors)

Practical guide for the phases that depend on the KiCad graphical interface and
on physical components - work that only you can perform. This document
exists for you to follow step by step while you assemble the PCB.

# Phase 2 - Create the PCB

1. Open the `MeetingHub-4-v1.kicad_pro` project in KiCad.
2. Open the **PCB Editor** (board icon, or double-click
   `MeetingHub-4-v1.kicad_pcb` in the project tree).
3. Menu **Tools → Update PCB from Schematic** (the shortcut hasn't changed
   across recent versions; if you can't find it in the Tools menu, look for
   the toolbar icon with a lightning bolt ⚡ over a board).
4. A dialog will open listing the changes. You should see **66 new
   footprints** (all the components from the 5 sheets, except the GND ones).
   Check that no "Footprint not found" appears - if it does, it's a sign that
   some footprint I assigned doesn't exist in your KiCad installation
   (check that the standard libraries are installed).
5. Click **Update PCB**. The 66 footprints will appear stacked near the
   origin, on top of each other - this is normal, nothing has been
   positioned yet.
6. Save the `.kicad_pcb` immediately (Ctrl+S) to make sure the
   schematic↔PCB association was recorded.

**Do not route anything in this phase.** The goal is just to have the 66
footprints loaded onto the board.

# Phase 3 - Define the mechanics

This is the most important phase according to your own assessment, and I
agree: a wrong decision here forces you to redo the entire placement later.

Answer before touching any footprint:

## 3.1 Which components need to touch the enclosure panel

Based on the schematic, these **11 components have a panel function** (the
user needs to reach them from outside). The final decision about **which
face/side** for each one follows the logic of use (what the operator touches
most often goes on the front; permanent/rare connections go on the back):

| Component | Function | Enclosure face/side |
|---|---|---|
| J6 (TRRS) | operator's headset | **front** |
| SW1-SW5 (via JST-XH + wire) | mute + laptop selection | **front** (physical switch off-board, connected by wire to the JST connector; they sit near J6, since it's what the operator handles most) |
| RV1-RV5 (dual potentiometer) | individual volume + master | **top** (the RK097 shaft points upward, accessible from the top panel) |
| J2-J5 (TRRS) | 4 laptops (3.5mm jack) | **back** (the cable stays connected all the time, doesn't need to be accessible during use) |
| J1 (USB-C) | power supply input | **back**, next to the 3.5mm jacks |

Everything else (U1, U2, K1-K4, R1-R20, C1-C21, F1, D1-D5, TP1) is
**internal**, with no panel restriction.

**Why this split:** the operator interacts with the headset and the
microphone selectors all the time (front) and adjusts the volume
occasionally (top) - these go on the easy-access faces. The laptop cables
and the power supply are plugged in once and rarely touched again - they go
to the back, out of the way.

## 3.2 Board dimensions

- Measure the internal space of the enclosure (or define the enclosure
  first, if you haven't chosen one yet).
- Rule of thumb: the board must be **at least wide enough to line up 5 TRRS
  jacks (J2-J6) + clearance for tightening the panel nut**. A 3.5mm panel
  jack (PJ320D type) typically needs ~12-15mm center-to-center so the nut
  doesn't bump into its neighbor - for 5 jacks in a row that's already
  ~60-75mm just for the jack front.
- If the 5 potentiometers (RV1-RV5) are also going on the same front face,
  that's 5 more shaft holes, each needing ~20-25mm center-to-center (the
  RK097 has a larger body than the jack). If it doesn't all fit in a single
  row, plan for two rows (jacks on the bottom, pots on top, for example).
- Sketch this arrangement on paper or in a vector editor **before**
  defining the board outline in KiCad - the board outline (`Edge.Cuts`)
  should come from the panel drawing, not the other way around.

## 3.3 Draw the board outline

### 3.3.1 Before drawing

- Decide which enclosure path you're going to follow (see the earlier
  discussion: off-the-shelf catalog vs. custom-made via
  PCBWay/JLC3D/JLCMC/acrylic sandwich). This changes what "correct" means
  here:
  - **Off-the-shelf enclosure**: the outline needs to match **exactly** the
    internal dimensions from the datasheet of the chosen enclosure,
    including clearance for internal ribs/rails that many plastic cases
    have near the edges - measure or check the case manufacturer's
    technical drawing, don't rely only on the external measurement.
  - **Custom-made enclosure (later)**: the outline can be a simple
    rectangle, sized to whatever remains after positioning the panel
    components (Phase 3.2) plus a margin of ~3-5mm on each side. The case
    will be cut/printed to order based on the STEP/Gerber file you export
    later - it doesn't need to be exact on the first try.
- Adjust the **grid** before drawing: `View → Grid Properties` (or the grid
  icon in the side toolbar), set it to 1mm (or 0.5mm if you want more
  precision at the corners). Drawing "by eye" without a grid is the most
  common cause of outlines with gaps.

### 3.3.2 Step by step in KiCad

1. In the layers list (right side, by default), click **Edge.Cuts** to
   select it as the active layer - it usually appears in yellow.
2. Use the **Add Rectangle** tool (rectangle icon in the right-side
   toolbar, or shortcut key `R`) if the outline is a simple rectangle.
   Click a corner, drag to the opposite corner, click again to close it.
3. If the outline is **not** a simple rectangle (e.g., a cutout so the
   jacks stick out further, or a chamfered corner), use **Add Line**
   (shortcut `Alt+L` or the line icon) segment by segment, always closing
   at the point where you started.
4. **Don't rely on the mouse click for exact measurements.** After drawing
   it approximately, right-click each segment → **Properties** (or key
   `E`) and type the exact **Start X/Y** and **End X/Y** values manually.
   That's how you make sure the outline is, for example, exactly
   90mm x 60mm, and not "89.7mm because your hand shook".
5. For rounded corners (common in custom enclosures, easier to
   print/cut): in KiCad 7, select the two segments that form the corner
   and use **Edit → Fillet Lines** - enter the desired radius (e.g., 3mm)
   and it automatically replaces the sharp corner with an arc, with the
   geometry properly closed.

### 3.3.3 Mounting holes

**Applied directly in the `.kicad_pcb`**: 4 `MountingHole_3.2mm_M3`
footprints (3.2mm non-plated hole, no net, suitable for an M3 screw), one
in each corner, with a 6mm margin from the edge (within the recommended
5-6mm range, without colliding with any component - all 4 corners were
free):

| Reference | Position (X, Y) | Corner |
|---|---|---|
| MH1 | 66.0mm, 91.0mm | top-left |
| MH2 | 319.0mm, 91.0mm | top-right |
| MH3 | 66.0mm, 239.0mm | bottom-left |
| MH4 | 319.0mm, 239.0mm | bottom-right |

(The board spans x=60-325mm, y=85-245mm; 6mm margin on each axis from the
edge.)

- If the enclosure has already been chosen, check whether this position
  matches the case's mounting holes/rails before manufacturing - if it
  doesn't match, just move the 4 footprints in KiCad (Properties → X/Y) to
  the correct position, the hole geometry itself doesn't change.
- If the enclosure is custom-made (later), these positions become the
  reference for the case manufacturer to align their holes.
- Validated: file paren balance, no collision with neighboring footprints
  (no other component within 20mm of any corner), and a clean
  `kicad-cli pcb export gerbers`.

### 3.3.4 Check that the outline closed correctly

An outline with a gap (not closed) is the most common error in this phase,
and it only shows up when generating Gerbers/manufacturing if you don't
check beforehand:

1. Run the DRC (getting a bit ahead of Phase 8, just for the outline):
   **Inspect → Design Rules Checker → Run DRC**. An open outline shows up
   as an error of type *"board outline"* or *"Unclosed board outline"*.
2. Visual alternative: open the **3D viewer** (`View → 3D Viewer`, or
   `Alt+3`) - if the outline didn't close, the board appears "punctured"
   or oddly shaped instead of as a solid piece.
3. Only after confirming the outline is closed and error-free is it worth
   moving on to Phase 4 (final placement) with confidence that the board
   geometry is correct.

# Phase 4 - Placement

The order below prioritizes components with mechanical constraints (panel)
over those with only electrical constraints - and it has already been
**applied directly in the `.kicad_pcb`** (exact positions per reference,
validated by script: no pair of components with anchors closer than 6mm,
closed outline, clean `kicad-cli pcb export gerbers`). The on-screen visual
check and Phase 9 (1:1 mockup) are still needed before considering it
final.

1. **J2-J5 (3.5mm jacks) + J1 (USB-C)** - back row (y=100mm), 40mm pitch
   between the 4 laptop jacks; J1 set apart to the side (x=290mm), with the
   POWER cluster (F1, D1, C1, C2, TP1) right next to it.
2. **RV1-RV5 (potentiometers)** - "top" row (y=170mm), each aligned on the
   same X column as the corresponding laptop jack (RV1 above J2, RV2 above
   J3, etc.); RV5 (master) in the fifth column.
3. **J6 (headset) + SW1-SW5** - front row: J6 at the edge (y=230mm),
   SW1-SW5 right behind it (y=218mm, 15mm pitch) - they sit close to what
   they serve.
4. **K1-K4 + D2-D5 (mic switching)** - near the SW group, but in its own
   band (y=190/203mm) so as not to collide with them; K1 aligned with SW2,
   K2 with SW3, etc.
5. **U1 (mixer) + R1-R12 + C3-C14** - 5x5 grid between the back row and the
   top row (x=75mm, y=118mm onward, **15x11mm pitch** - the X pitch was
   widened from 13 to 15mm in a second round, for the same reason as the
   HPAMP: it caused too much congestion for the GND plane to connect 2
   specific pads without violating clearance - see the note at the end of
   this phase) - it's literally the midpoint of the signal path (3.5mm jack
   → volume → mixer).
6. **U2 (headphone amp) + R13-R20 + C15-C21** - 4x4 grid near J6 (x=215mm,
   y=182mm onward, 12x11mm pitch).

**Exact coordinates per reference** are in the `.kicad_pcb` - there's no
separate copy here because it would go out of date with every fine
adjustment you make on screen. If you need to check a specific value, open
KiCad and select the component (the properties panel shows X/Y).

**Note on the mixer grid re-layout (pitch 13→15mm)**: after the first
routing pass (Phase 7), the GND plane ended up with pads trapped in copper
pockets isolated from the main plane - the cause was a lack of space for
the zone filler to lay down a proper "spoke" to those pads without
violating clearance with neighboring signal traces. Widening the grid's X
pitch, repositioning the 25 components, and re-running Freerouting from
scratch fixed C4, R2, C1 and C3 (via manual GND stitching + small detours
in neighboring signal traces - NB2_L/NB3_L/NB2_R - to open up real space,
and a solid connection instead of a thermal relief for C1/C3). Validated
by script (paren balance, count of unconnected items via `pcbnew`,
pad-to-pad and trace-to-pad clearance per layer, clean
`kicad-cli pcb export gerbers`) and confirmed by an on-screen real DRC
after each round.

**Resolved: U1 pin 4 (GND), via migration to 4 layers.** This specific pin
had no copper path available to the GND plane on the 2-layer board, within
the minimum manufacturing clearance (0.15mm). Root cause: in a DIP-8
package, pin 4 sits physically between pin 3 and pin 5 (that's how the
package numbering wraps around), so this local tightness is inherent to
the chip's pinout, not to the surrounding layout - confirmed by trying:
(a) widening the mixer grid's X pitch and then also the Y pitch (2
complete rounds of re-layout + rerouting), (b) rotating U1 by 90° (same
pinout, same tightness, only the direction changes), (c) an exhaustive
script-based search (A*, neighboring trace bulging) finding no path with
reliable clearance, and (d) a manual on-screen attempt by the user, same
conclusion.

Since no placement adjustment addresses the real cause (the chip's own
pinout), the solution was to migrate the board to **4 layers** with a
dedicated GND plane (see Phase 6) - this eliminates the problem
structurally, since pin 4 now touches the plane directly through its own
through-hole, without competing for space with any signal trace. Confirmed
by a real headless DRC (`pcbnew.WriteDRCReport`, see note below): **0
unconnected pads, 0 real errors**.

**TP2** (same footprint as TP1,
`TestPoint_THTPad_D1.5mm_Drill0.7mm`), connected to the GND net, at
position (67.0mm, 125.62mm), was kept as a generic GND test point (useful
for touching a multimeter/oscilloscope probe to) - the manual jumper
instruction that was on the silkscreen was removed, since it's no longer
needed.

**Note on validation in this phase**: I discovered that
`pcbnew.WriteDRCReport()` generates a real, complete DRC report even
without the GUI (unlike what was assumed at the start of the project, that
this KiCad version had no DRC via command line/script) - the approximate
script-based checks used in earlier phases of the session were replaced
with this function wherever possible from here on. One side effect noted:
running this function outside the full KiCad environment (without the
footprint library table configured) generates false `lib_footprint_issues`
warnings ("footprint not found in library") for practically every
component - this is a limitation of the headless environment used to
generate the report, not a real board problem; it doesn't happen when
running DRC through the KiCad GUI.

**Pending**: the 6mm clearance used in validation is only between anchors
(footprint center), not between actual bodies - the RK097 potentiometer,
G5V-1 relay and PJ320D jack have larger bodies than that. Confirm visually
before routing.

# Phase 5 - Layout planning (regions)

Zoning **actually applied** (Phase 4), organized by enclosure face instead
of by schematic sheet - but the noise-isolation principle from SCH-008
still holds, just expressed as front/back instead of side by side:

```text
                    BACK (y=100-135)
┌───────────────────────────────────────────────────┐
│  J2 J3 J4 J5        J1          F1 D1 C1 C2 TP1     │  <- 3.5mm jacks + USB-C + POWER
│                                                     │
│  ┌──────────────┐              ┌─────────────┐     │
│  │ AUDIO_MIXER  │              │             │     │
│  │ U1,R1-12,     │              │             │     │
│  │ C3-14         │              │             │     │
│  └──────────────┘              │             │     │
│                                                     │
│  RV1 RV2 RV3 RV4 RV5                                │  <- TOP (y=170)
│                                                     │
│  ┌──────┐                      ┌──────────────┐    │
│  │MIC_SW│                      │ HEADPHONE_AMP│    │
│  │K1-4  │                      │ U2,R13-20,   │    │
│  │D2-5  │                      │ C15-21       │    │
│  └──────┘                      └──────────────┘    │
│  SW1 SW2 SW3 SW4 SW5              J6                │  <- FRONT (y=218-230)
└───────────────────────────────────────────────────┘
                    FRONT (user)
```

Central idea, adapted: **the power supply (POWER) and the 3.5mm jacks stay
at the back, away from the operator; the microphone line (MIC_SWITCHING)
stays at the front**, close to where it ends (SW1-SW5) and far from where
the power supply comes in (back). The audio path (3.5mm jack → volume →
mixer → headphone amp → J6) crosses the board from back to front in a
straight line, without crossing back - same logic as before (SCH-008),
except the "front" of the enclosure now plays the role of the opposite end
from the power supply, instead of a specific schematic sheet.

# Phase 6 - Ground plane

**Updated: the board was migrated from 2 to 4 copper layers**
specifically to definitively resolve the problem described in Phase 8 (U1
pin 4 trapped in an isolated GND pocket, even after two rounds of
re-layout). With 2 layers, the GND plane competed for space with signal
traces on the same layer (B.Cu), and at some points in the mixer grid
there wasn't enough legal space for the zone filler to connect certain
pads without violating clearance. The standard professional solution to
this problem is to dedicate entire layers solely to planes, with no signal
trace competing for space on them - this is what was applied:

- **F.Cu** (top) and **B.Cu** (bottom): signal only - this is where
  Freerouting routes the ~105 signal nets (audio, mic, relay control).
- **In1.Cu** (internal layer 1): solid **GND** plane, covering the entire
  board, with no signal traces.
- **In2.Cu** (internal layer 2): solid **+5V_AUDIO** plane, same coverage.
- Since all 66 components are through-hole (THT), any GND or +5V_AUDIO pin
  already touches these two internal layers directly through its own hole
  - no extra trace or via is needed in most cases. **Exception**: the "R2"
  (shield) pins of the TRRS connectors (J2-J6), which are SMD only on the
  F.Cu layer in the `Jack_3.5mm_PJ320D_Horizontal` footprint - these 5
  points needed a dedicated via going down to the GND plane, already
  applied.
- To set this up in KiCad (if you're reproducing it from scratch):
  **File → Board Setup → Physical Stackup**, change "Copper Layers" to 4,
  and mark In1.Cu/In2.Cu as type **Power** (not Signal) in
  **Board Setup → Layers** - this is what stops the autorouter from
  dropping signal traces on these layers.
- **Star grounding** (already decided in SCH-008/DR-002): the GND return
  from POWER and the GND return from the analog block
  (TRRS/MIXER/HPAMP) must meet at a single physical point - with the
  dedicated internal plane, this is now naturally satisfied (the whole
  plane is a single node).
- A concern that **is no longer necessary** with the dedicated plane: the
  original worry about the K1-K4 coil current sharing a plane segment with
  the MIC/audio return no longer applies in the same way, since the GND
  plane now has no signal trace competing for a path within it - but it's
  still worth positioning K1-K4 near the POWER region for the general
  organization of the layout.

# Phase 7 - Routing

Follow the order you proposed. Suggested trace widths for this board
(power supplied via USB, ~500mA at the fuse):

| Signal type | Suggested width |
|---|---|
| +5V_AUDIO, GND (power) | 0.6-0.8mm |
| Audio signal (NB*_L/R, MIX_L/R) | 0.25-0.3mm |
| Microphone line (NB*_MIC, HEADSET_MIC) | 0.25-0.3mm, **avoid running parallel and close alongside a +5V_AUDIO trace or relay coil** - if crossing, cross perpendicularly, never parallel for more than a few mm |
| Relay control (coil, +5V_AUDIO→SWx→K) | 0.4-0.5mm |

Routing order (yours is correct):

1. Power supply (+5V_AUDIO, from J1 to POWER, then to MIXER/HPAMP/MICSW)
2. GND (plane, plus the few cases that can't be resolved with the plane
   alone)
3. Op-amp signals (U1 and U2 feedback loops - keep these traces short,
   they're the most sensitive to picking up noise)
4. Microphones (NB1-4_MIC, HEADSET_MIC - a "transparent" line, with no
   amplification, so any noise picked up here goes straight to the laptop)
5. Headphones (MIX_L/R, J6 output)
6. Control (relay coils, SW1-SW5)
7. USB-C last, as you suggested - the 4 data pins (D+/D-/CC1/CC2) are
   **intentionally unused** in this project (only VBUS+GND matter), so
   they don't even need any trace - ignore the "unconnected" warnings
   KiCad reports for these pins.

# Phase 8 - DRC

1. In the PCB Editor: **Inspect → Design Rules Checker** (or the
   "bug"/magnifying-glass icon in the toolbar).
2. Before running it, check **File → Board Setup → Design Rules →
   Constraints** and set **Minimum track width** and **Minimum clearance**
   to a safety floor above the factory minimum (JLCPCB's default is
   0.153mm trace and 0.127mm spacing).
   **Correction to this guide's original suggestion**: with the board
   already routed (Phase 7, via Freerouting), most signal traces use
   0.2mm and the clearance validated throughout the whole session is
   0.15mm - using 0.25mm/0.2mm (the original suggestion, written before
   the routing existed) would create ~400 false "trace width error" flags
   on traces that are already correct. Use **0.2mm minimum track width and
   0.15mm minimum clearance** instead - still comfortably above the
   JLCPCB minimum, but compatible with what has already been routed.
3. Click **Run DRC**. Fix one error at a time, running it again after each
   fix - don't try to fix everything at once and only run it at the end.
4. Most likely errors on this board: clearance between the large
   G5V-1/USB-C pads and neighboring traces, and unrouted traces
   (unconnected net) if some footprint is left without every trace
   connected.
5. Only consider Phase 8 complete with **zero errors and zero unjustified
   warnings** (a "short trace" warning or similar may be acceptable, but
   document why).

**Accepted and documented warning**: the 4 mounting holes (MH1-MH4, Phase
3.3.3) trigger `[extra_footprint]` (warning severity) because they are
mechanical-only footprints, added directly in the `.kicad_pcb` with no
corresponding symbol in the schematic - this is expected and safe for
`MountingHole`, which has no electrical function and therefore normally
doesn't go into the schematic. You can ignore this specific warning (@MH1,
MH2, MH3, MH4) without worry.

# Phase 9 - 1:1 scale mechanical review

1. In the PCB Editor: **File → Print**.
2. Check the **1:1** scale option (sometimes called "Scale 1" or "No
   scaling" depending on the version) - **never use "fit to page"**, it
   distorts the scale.
3. Before trusting the printout, measure a known dimension on the paper
   with a ruler (e.g., the distance between two mounting holes) to confirm
   the printer didn't scale anything.
4. With the printed sheet, physically overlay:
   - a G5V-1 relay (or its drawn footprint) over the K1-K4 pads;
   - a TRRS jack (the actual model you'll buy) over J2-J6;
   - an RK097 potentiometer over RV1-RV5;
   - the USB-C connector over J1.
5. Check whether the panel mounting holes (if any) line up with the actual
   position of the components, and whether no two components are trying to
   occupy the same physical space (e.g., the potentiometer body touching
   the neighboring relay).

# Phase 10 - Manufacturing

**4-layer board** (see Phase 6) - when requesting a quote/manufacturing on
the manufacturer's website, explicitly select **"4 layers"** (or
equivalent) in the order options, not the default 2-layer one. This
usually costs more than 2 layers (most manufacturers charge about 30-70%
more for small batches), but it's mandatory - the generated gerbers
already include the internal layers (`In1_Cu`, `In2_Cu`), so the
manufacturer will notice it's 4 layers from the files themselves, but
confirm the order option matches before finalizing the purchase.

Files to generate (via **File → Fabrication Outputs** in the PCB Editor,
or the `kicad-cli pcb export` command line):

- **Gerbers** (all 4 copper layers + mask + silk + Edge.Cuts)
- **Excellon** (drill file)
- **Final BOM** - we already have one generated at
  `hardware/BOM/BOM-MeetingHub-4-v1.csv`; confirm it still matches the final
  `.kicad_pcb` before sending it.
- **Assembly PDF** (component positions, useful for yourself when
  soldering)
- **Schematic PDF** - we already have one at `hardware/Schematics/`

**Note on Pick & Place**: all 66 components in this project have a **THT**
footprint (no SMD). This means that, strictly speaking, you **don't need
to generate a Pick & Place file** for this batch, unless you decide to
hire automated wave/selective soldering assembly from some manufacturer
that asks for this file even for THT. For manual assembly, Gerbers +
Excellon + BOM + assembly PDF are already enough.

Once everything is generated, call me back and I'll check:
- whether the files open and are consistent with each other (via
  `kicad-cli`);
- whether the final BOM matches the `.kicad_pcb`;
- whether any footprint was left without a value/reference before closing
  out the manufacturing package.

# Phase 11 - Post-ERC fixes (TP1/TP2 with no net on the PCB)

Running the real schematic ERC (via GUI, only possible in this KiCad
version through the interface - see BOM-002-AsBuilt Section 4), a
`pin_not_connected` appeared on TP1. Investigating, the TP1 pin was
visually sitting on top of an existing wire in the schematic (POWER sheet)
without an electrical **junction** there - a classic KiCad mistake
(visual overlap ≠ connection). Fixed in the schematic with a `junction` at
the exact point.

Checking the PCB afterward, the problem was worse than just the
schematic: **the TP1 pad on the board also had no net at all**
(`unconnected-(TP1-Pad1)`), and **neither did TP2** (empty net) - both
test points were physically floating on the final board, despite the
documentation saying they were on +5V_AUDIO/GND. Fixed via a Python script
(`pcbnew`): assigned the `+5V_AUDIO` net to the TP1 pad and `GND` to the
TP2 pad, followed by recalculating the planes (`ZONE_FILLER.Fill`) so that
each pad's solder ring actually connects to the corresponding internal
plane. Confirmed afterward via
`board.GetConnectivity().GetUnconnectedCount(False)` = 0 and a new
`WriteDRCReport` with no real errors.

Also fixed, by the same ERC: the `power_pin_not_driven` on U1 (pins
V+/V-) - added two `power:PWR_FLAG` symbols in POWER.kicad_sch (KiCad's
standard idiom for when a net's power comes from a connector pin, here the
VBUS of J1/USB-C, rather than from a dedicated power symbol); and the
`lib_symbol_issues` on J2-J6 - the `lib_id` was pointing to
`Connector:AudioJack4`, an old library that no longer exists at that
location in the installed KiCad (the symbol was reorganized into
`Connector_Audio` in newer versions of the standard library). Fixed the
`lib_id` to `Connector_Audio:AudioJack4` - geometry and pins checked
byte-for-byte against the system library before the change, with no
difference.

**Lesson for the next project**: test points (TP) added directly on the
PCB (with no schematic symbol, like TP2) need to have their net assigned
and checked manually - they don't show up in the schematic ERC (they
don't exist there) and don't generate an obvious DRC error if left without
a net (there's no neighboring pad to complain about being "unconnected"
with a single isolated pad). The way this was caught was by checking
net-by-net via script, not just by looking at the DRC report.

In a second round of ERC (after pulling in the fixes above), the user
reported that the `power_pin_not_driven` on U1 **persisted** on pin V+
(pin 8), even with the `PWR_FLAG` already added. Investigating, the flag
had been attached to the wrong wire: there were two similar-looking nodes
in the POWER sheet near fuse F1 - one **before** the fuse (coming from
VBUS/TVS protection) and another **after** it (the actual +5V_AUDIO net,
the same one carrying the `+5V_AUDIO` global label and TP1). The flag had
landed on the node before the fuse, which doesn't share the same net name
and therefore doesn't count toward the ERC as a +5V_AUDIO source. Fixed by
moving the `PWR_FLAG` to the correct node (the same one as TP1 and the
global label).

This same round also confirmed 13 `pin_not_connected` errors that had
existed since the first version of the schematic, but which I had only
documented as "intentional" instead of actually resolving: the 9
data/CC/SBU/shield pins on J1 (USB-C, unused because J1 is power-only) and
pin 10 on the 4 relays (a duplicated pin, unused in the SPDT topology).
Fixed by adding an explicit **no connect** (`no_connect`) on each of these
13 pins - the correct, definitive way to zero out this type of ERC error,
instead of leaving it as a pending note in the documentation.

After confirming 0 errors, 232 `endpoint_off_grid` warnings remained - on
practically every pin and wire across the 5 sheets. Root cause: the entire
schematic was drawn using round positions in millimeters (e.g., 55.0,
85.0, 115.0mm), which **are not multiples of the 1.27mm grid (50 mil)**
that the ERC check uses as its reference - so almost every symbol falls
"off grid" even though it was positioned in a perfectly deliberate way.

Fixing this manually, symbol by symbol, would be too risky at this scale
(~70 components, hundreds of wires, 5 files) - it's easy to disconnect
something without noticing. Instead, I used a mathematical property: if I
apply the **same rounding function** (`snap to the nearest multiple of
1.27mm`) to every coordinate in the file (symbol position, wire endpoint,
junction), two points that were already **exactly equal** before (the
definition of "connected" in the KiCad format) remain exactly equal
afterward - the function is deterministic, so the same input always gives
the same output. This makes it possible to realign the entire project to
the grid without, in principle, changing any connection.

I wrote a script (`snap_grid.py`) that does exactly this: it parses each
sheet into a tree (without touching `lib_symbols`, which is just the
cached library, not the on-page instance), finds every symbol/wire/
junction/global label/no-connect at the schematic level, and rounds their
coordinates. I ran it on all 5 sheets (716 adjustments on AUDIO_MIXER
alone, the largest one).

**Validation**: `kicad-cli sch export netlist` has an output format
(`kicadsexpr`) that lists every net and its nodes - I ran it before and
after the realignment and compared net by net (by node set, ignoring net
name/code, which change). It confirmed 1 real problem: the realignment
brought D1 (TVS protection) close enough to the D+ pin of J1 (USB-C,
unused) that the two landed on the same grid point, merging two nets that
should have stayed separate - exactly the kind of case "two statistically
close points collapse onto the same grid square" that I had already
anticipated as a theoretical risk before starting. Fixed by moving D1 one
extra grid step away (and the wire connecting to GND, which depended on
D1's old position). A second round of `export netlist` confirmed the
project's 72 nets matching node-for-node, with no difference at all.

**Lesson**: this kind of "bulk snap" is safe in expectation, but it's not
zero risk - it's always worth validating with a connectivity comparison
tool (netlist, not just an error/warning count) after any batch geometric
transformation, because a clean DRC/ERC doesn't guarantee the topology
didn't change, only that it didn't violate the rules being checked.

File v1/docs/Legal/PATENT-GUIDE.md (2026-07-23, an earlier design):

# International Patent Registration Guide — MeetingHub-4

**Version: 0.1 — Educational document, not legal advice**

---

## Read this first: an honest patentability assessment

Before any procedure, it is important to realistically assess whether this project has a real chance of being granted a patent. Based on the technical documentation in this repository (ERS-001, HAD-001, SCH-001 to SCH-009, PCB-001):

MeetingHub-4 combines circuit blocks that are **well known and widely published** — an op-amp summing stage for audio mixing, relays for microphone signal switching, a headphone amplifier, passive TRRS interfaces, and USB-C power supply — assembled in a straightforward way to meet a specific need (managing audio for 4 laptops with a single headset).

For a **utility patent** to be granted, most patent systems worldwide (including the Brazilian system, via INPI, and the PCT system) require three cumulative criteria:

1. **Novelty** — the solution must not already exist, published or in use, anywhere in the world, before the filing date.
2. **Inventive step / non-obviousness** — the solution cannot be an obvious step for a person skilled in the art, starting from what is already known.
3. **Industrial applicability** — the solution must be industrially manufacturable/usable (this criterion, on its own, MeetingHub-4 meets without issue).

**The real risk here lies in criteria 1 and 2.** Op-amp summing circuits, relay switching, and TRRS interfaces are analog electronics techniques taught in any basic electronics course and used in commercial products for decades. A patent examination (or a prior-art search performed before filing) would very likely find prior art covering the individual elements and, possibly, the combination itself — multi-source audio mixers with relay-based microphone selection are not a novel concept in the professional/broadcast audio market.

**This does not mean there is nothing to protect** — it just means the most appropriate protection is probably not a utility patent. See the "Alternatives" section below before deciding to spend time and money on an international filing.

**Concrete recommendation**: before spending anything on filing, hire a **professional prior-art search** (patent search) performed by a registered industrial property agent. It costs a fraction of the price of an international filing and answers the central question based on real evidence, not on assumption — including my own, written here without access to patent databases.

---

## Protection alternatives better suited to this type of project

| Protection | What it covers | Relative cost | Already covered in this project? |
|---|---|---|---|
| **Trade secret** | The project file itself (schematic, PCB) kept confidential | Low (contractual clause) | Yes — clause 7 of [LICENSE.md](../../LICENSE.md) |
| **Copyright** | The schematic/PCB files as technical drawings, and the written documentation | Low/none (automatic protection in most countries; formal registration reinforces proof of authorship) | Automatic from creation; consider formal registration if commercializing internationally |
| **Trademark** | The commercial name of the product ("MeetingHub-4" or the real sales brand name) and/or logo | Medium, per country/class | Not done - evaluate before commercial launch |
| **Design patent** | The visual appearance of the enclosure/panel, if it has its own distinctive design | Medium | Not yet applicable - depends on the enclosure design, which is not part of this electronic hardware project |
| **Utility patent** | A new and non-obvious technical solution | High (see below) | Evaluate via prior-art search before deciding |

For most niche hardware products like this one, the combination of **trade secret (protecting the project files) + trademark (protecting the commercial name) + a well-drafted license agreement** offers faster and cheaper practical protection than pursuing a patent with a real risk of rejection.

---

## If you still decide to proceed with an international patent filing

### Overview of the PCT system (Patent Cooperation Treaty)

The standard path to seeking protection in multiple countries from a single initial filing is the **Patent Cooperation Treaty (PCT)**, administered by WIPO. It **does not grant an "international patent"** (that does not exist as a single legal concept) — it allows reserving priority and deferring country-by-country decisions while the merits are evaluated.

**Typical steps:**

1. **National priority filing** (optional, but common): initial filing in the applicant's home country (e.g., INPI in Brazil) to establish a priority date. From this point, you have **12 months** to decide whether to enter the PCT claiming that priority.
2. **PCT international filing**: a single application, in a single language, filed at a receiving office (e.g., INPI, or directly at WIPO), claiming priority from the national filing (if any).
3. **International search (International Search Report)**: a search authority (e.g., INPI, EPO, USPTO, depending on where the application was filed) issues a report indicating relevant prior art found — **this is where novelty/inventive-step problems tend to surface publicly for the first time**.
4. **International publication**: the application is published (made public) 18 months from the earliest priority date.
5. **International preliminary examination** (optional): a preliminary opinion on patentability, useful for deciding whether it is worth proceeding.
6. **National phase entry**: within **30-31 months** from the priority date (the deadline varies by country), the applicant decides in **which specific countries** to actually proceed with examination and eventual grant — each country then examines and decides independently, according to its own law. **This is the phase where most of the real cost occurs** (translation, local agents, country-by-country examination fees).

### Key deadlines (summary)

| Milestone | Deadline from priority date |
|---|---|
| PCT filing claiming national priority | up to 12 months |
| International publication | 18 months |
| National phase entry (varies by country, e.g., Europe ~31 months, USA ~30 months) | 30-31 months |

### Costs (order of magnitude, **not fixed figures** — they vary by office, number of countries, and exchange rate; consult an agent for a real quote)

- Priority national filing: low to moderate.
- PCT filing + international search: moderate (typically a few thousand dollars/euros).
- **National phase in each country** (mandatory translation + local agent + fees): this is the item that weighs the most — each chosen country can cost independently, and choosing 5-10 countries can multiply the total cost several times over relative to the initial PCT filing.
- Maintenance (annuities) in each granted country, for the entire term of validity.

### Who to contact

- A **registered Industrial Property Agent** (in Brazil, accredited with INPI) for the national filing and guidance on the PCT.
- A **patent attorney** with international practice, or a firm with correspondents in each target country, for the national phase.
- **WIPO** itself provides free educational material on the PCT system (search for "WIPO PCT applicant's guide" directly on the official WIPO website).

---

## Executive summary

1. **Do not file anything before a professional prior-art search.** The risk of rejection for lack of novelty/inventive step is real and concrete for this type of project.
2. **Consider whether trade secret + trademark solves the real business problem** (preventing direct copying, protecting the commercial name) better and more cheaply.
3. **If the search indicates a real chance**, the path is: national priority filing → PCT → national phase entry in the countries of real commercial interest (not every country in the world — choose where you intend to sell).
4. **This entire process must be conducted by a qualified patent agent/attorney.** This document is only a map of the territory, not a substitute for professional guidance.

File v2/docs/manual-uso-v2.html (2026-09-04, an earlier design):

Manual de uso

# MeetingHub-4

Um headset. Quatro notebooks. Você ouve os quatro ao mesmo tempo e escolhe, num toque, para qual deles o seu microfone fala. Sem instalar nada, sem USB de dados, sem firmware.

DEMO 1 · Conecte os 4 notebooks (P2/P3) e o seu headset ao MeetingHub-4. 2 · Ligue o cabo USB-C. A caixa acende já em mudo — nenhum notebook recebe seu microfone ainda. 3 · Toque SELECT 1. O microfone do headset passa a falar só no notebook 1. 4 · Gire os potes: um volume por notebook + o volume GERAL. Direita = mais alto. 5 · Toque SELECT 3. O microfone troca para o notebook 3 — sem cortar o que você ouve. 6 · SELECT 1 + SELECT 2 juntos = mudo total. Continua mudo até você tocar um botão sozinho.

A animação repete em ciclo. Ela mostra o comportamento real validado por simulação: mudo no boot (janela de 139 ms), seleção one-hot exclusiva, e comutação de microfone sem glitch no áudio de monitoração (variação < 0,02%).

## O que este aparelho faz

Numa reunião em que você precisa acompanhar quatro notebooks ao mesmo tempo — tradução, suporte, operação de transmissão, salas simultâneas — o MeetingHub-4 resolve dois problemas:

### Ouvir todos

O áudio dos 4 notebooks é somado num mixer. Cada um tem seu próprio volume; um pote GERAL controla o conjunto. Você ouve tudo no seu único headset.

### Falar em um

Seu microfone vai para um notebook por vez, escolhido por botão. Os relés garantem que nunca há dois ao mesmo tempo, e a caixa liga sempre em mudo.

Por que analógico e não USB? Um plugue P2 não some, não "re-enumera" e não troca o dispositivo padrão do Windows no meio da chamada. É exatamente a falha do headset USB que some da reunião — e que este aparelho existe para nunca ter.

## No painel

Controle | Onde | Função
RV1 – RV4 (4 potes) | frente, à esquerda | Volume individual do que você ouve de cada notebook (1 a 4). Direita = mais alto · tudo à esquerda = canal mudo.
GERAL (RV5) | frente, ao centro | Volume geral do headset. Afeta todos os canais de uma vez.
SELECT 1 – 4 (4 botões) | frente, à direita | Manda o seu microfone para o notebook 1, 2, 3 ou 4. Só um fica ativo.
PC 1 – PC 4 (4 jacks P2) | traseira | Um cabo P2–P2 (4 vias / TRRS) para cada notebook.
HEADSET (1 jack P2) | frente | Seu headset com microfone (padrão CTIA / celular).
USB-C | traseira | Alimentação apenas (5 V). Qualquer fonte USB de 5 V / ≥ 0,5 A.

Não há botão de "mudo" dedicado e não há LED. O estado "mudo" é o estado de partida (nada selecionado) ou o gesto de dois botões. "Qual notebook está ativo" é o último SELECT que você tocou.

## Ligando (primeira vez)

1. Conecte os notebooks. Um cabo P2–P2 de 4 vias (TRRS) de cada notebook para PC 1…PC 4 na traseira. Use a entrada de headset do notebook (o jack único com ícone de fone+microfone), não entradas separadas.
2. Conecte o headset ao jack HEADSET na frente.
3. Ligue o USB-C. A caixa energiza. Por cerca de 0,14 s ela se mantém deliberadamente em mudo — depois disso continua em mudo até você escolher um notebook. Nenhum relé deve clicar ainda.
4. Confira o áudio. Toque algo em um notebook e ajuste o pote daquele canal e o GERAL. Girando para a direita aumenta.
5. Entre numa chamada em um notebook e toque o SELECT correspondente. Você ouve um clique de relé — o microfone do headset agora fala nesse notebook.

## No dia a dia

### Falar em um notebook

Toque o SELECT do notebook (1–4). O relé daquele canal fecha e os outros três abrem — na mesma tocada. O microfone do seu headset passa a ser o microfone daquele notebook. O outro lado da chamada ouve você normalmente.

### Trocar de notebook

Toque outro SELECT. A troca é imediata e não interrompe o áudio que você está ouvindo dos quatro notebooks (validado: variação < 0,02% no fone durante a comutação). Durante alguns milissegundos o microfone não está em nenhum notebook — inaudível para o outro lado.

### Mudo

Segure dois SELECT quaisquer ao mesmo tempo (ex.: 1 + 2). Todos os relés abrem e o microfone não vai para nenhum notebook. Permanece mudo mesmo depois que você solta — até tocar um único botão de novo.

Um notebook do qual você "saiu" continua enxergando o headset como presente, porém em silêncio (a placa mantém ~1,25 V na linha de microfone). O app de reunião não cai para o microfone interno do notebook nem mostra "microfone desconectado".

### Ajustar o que você ouve

Cada notebook tem seu pote (RV1–RV4); o GERAL mexe em tudo. Tudo à esquerda em um pote = aquele canal fica em silêncio total (não é "baixinho", é silêncio de verdade — foi o ponto mais testado do projeto).

## Especificações

Alimentação | USB-C, 5 V, ~50 mA (só um relé por vez). Fusível rearmável 500 mA + proteção contra surto.
Entradas | 4 × P2 3,5 mm TRRS (4 vias) — fone L/R + microfone por notebook
Saída | 1 × P2 3,5 mm TRRS — headset CTIA (fone + microfone electret)
Nível no headset | ≈ 0,5× do nível de linha do notebook em fones de 32 Ω (≈ 96 dB SPL em intra-auriculares)
Banda de áudio | plana ±1 dB de 100 Hz a 20 kHz · −3 dB em 44 Hz (voz: ótimo)
Seleção de microfone | relés, lógica one-hot exclusiva, liga em mudo
Placa | 192 × 156 mm · 2 camadas · 100% componentes através-furo · 6 furos M3
Fixação | gabinete de acrílico topo + base, laterais abertas; controles rentes à borda frontal

## Perguntas frequentes

Preciso instalar driver ou app?

Não. Cada notebook enxerga apenas um headset analógico comum no seu jack. Nada enumera por USB.

O Windows vai mostrar "microfone mudo"?

Não — o mudo aqui é funcional, não sinalizado: quando você não está selecionado, o endpoint de microfone do notebook continua presente e ativo, só não recebe áudio nenhum. Não existe sinal num jack P2 que diga "mudo" para um sistema operacional.

Posso deixar os 4 notebooks conectados o tempo todo?

Sim — essa é a ideia. O plugue nunca sai do jack, então o notebook nunca "perde" o headset.

Dois notebooks podem receber meu microfone juntos?

Não. A lógica garante um de cada vez. Segurar dois botões = nenhum (mudo).

Uso fones de estúdio de alta impedância (250 Ω). Serve?

Funciona, mas fica mais baixo. O aparelho é dimensionado para headsets de reunião de 16–32 Ω.

Caiu a energia no meio da reunião. O que acontece?

Ao voltar, a caixa religa em mudo. Toque o SELECT do notebook para retomar. O áudio que você ouve volta sozinho.

## Segurança e cuidados

- Alimente só por USB-C 5 V. A entrada tem fusível rearmável e supressor de surto, mas não é para tensões acima de 5 V.
- Não conecte as entradas PC 1–4 a saídas de potência (amplificadores, saída de alto-falante) — são entradas de nível de linha / headset.
- Placa com componentes expostos (gabinete de laterais abertas): mantenha longe de líquidos e superfícies metálicas.
- Primeiro artigo: confirme com um multímetro que, com um pote todo à esquerda, o canal fica em silêncio — e o sentido dos potes (direita = mais alto).

MeetingHub-4 v2 · rev-10 · 2026-09-04. Comportamento descrito neste manual verificado por simulação elétrica (27/27 testes) e inspeção de placa (DRC 0 erros). Ver o dossiê de validação para métodos e números.

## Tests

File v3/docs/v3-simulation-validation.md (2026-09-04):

# MeetingHub-4 v3 — circuit simulation & requirement validation

Date: 2026-09-04 · scope: electrical validation of the **mic selector** against
the requirements in `v3-DESIGN.md`.

## Two independent simulations

| | engine | models | checks | script |
|---|---|---|---|---|
| **A. Component-level** | **ngspice-42** (via `libngspice`, `scripts/ngspice_shared.py`) | datasheet device cards — 1N4148, 2N7000, Omron G5V-1 coil+contact, CD4043B NOR latch, electret JFET capsule (`spice/models.lib`) | **25 / 25** | `scripts/spice_sim.py` → `spice_results.json` |
| **B. Analytic cross-check** | purpose-built MNA solver (`scripts/mna.py`, ~300 lines: `.op`/`.ac`/`.tran`) + an event-stepped CD4043B logic model | ideal R/C/L + 1-pole devices | **22 / 22** | `scripts/validate.py` → `validation_results.json` |

Simulation A is the primary result — it runs the **actual circuit netlist with
the actual parts**, driven the way the board is really used (VBUS ramps, buttons
pressed in sequence, real notebook mic-bias spread). Simulation B is a fast
sanity net that re-derives the key numbers from first principles; the two agree
to within the tolerance of the behavioural models.

LTspice users: `spice/selector.cir`, `spice/por.cir`, `spice/mic_path.cir` are
standalone decks (`.include models.lib`) that reproduce the A scenarios — open
them in LTspice and drop in vendor models.

Outputs: `MeetingHub-4-v3-spice-simulation.mp4` (component-level, 42 s),
`MeetingHub-4-v3-mic-selector.mp4` (button sequence),
`MeetingHub-4-v3-full-simulation.mp4` (analytic overview),
`plots/*.png`, `spice/*.dat`, `spice_results.json`, `validation_results.json`.

---

## A. Component-level ngspice results — 25 / 25

### S. one-hot selector — full transient with the real parts (8 / 8)

`spice/selector.cir`: VBUS PWL ramp → `RF1` (PTC) → `C1/C2/C3/C4`; four button
PWL sources → `SWB` switches → the 16× `D1N4148` matrix → four `CD4043LATCH`
(OE tied high) → `R12–R19` + `XQ1–XQ4` (`Q2N7000` + body diode) → `XK1–XK4`
(`RELAY_G5V1`: 178 Ω / 0.46 H coil, SPDT gold contact) → the electret on
`HS_MIC` and four notebook bias loads. Single `tran` over the whole KVM
sequence; the relay energised at each checkpoint is read from `v(qoN)`.

| action (single press) | expected | measured |
|---|---|---|
| power on | muted (no relay) | **relay 0 — mic muted** ✔ |
| tap SW1 | mic → NB1 | **relay 1** ✔ |
| tap SW2 | mic → NB2, NB1 released | **relay 2** ✔ |
| tap SW3 | mic → NB3 | **relay 3** ✔ |
| tap SW4 | mic → NB4 | **relay 4** ✔ |
| hold SW2 + SW3 | muted while held | **relay 0** ✔ |
| release the two buttons | **stays muted** | **relay 0** at t = 2.95 s ✔ |
| — during the VBUS ramp | POR keeps it muted | **PORN = 4.6 V at 20 ms**, every Q = 0 ✔ |

Exclusive because button *n* forward-biases `SETn` **and** the `RSTx` of the
other three through the diode matrix. Only one coil is ever energised
(≈ 27.6 mA). A NOR latch left at S = R = 1 holds Q = 0, so two buttons held →
all four muted, and it stays muted when they're released.

### P. power-on reset vs VBUS ramp rate (10 / 10 — 6 ramps × {no latch, PORN holds})

`C5 = 10 µF` / `R11 = 100 k`, `D22–D25` clamp `PORN` onto the four `RST` lines.
The VBUS PWL ramp is swept **0.05 ms → 100 ms**:

| VBUS ramp | max Q over the whole run | PORN when the rail settles |
|---|---|---|
| 0.05 ms | 0.00 V | 2.26 V *(latches just power up at 0; faster than any real inrush-limited supply)* |
| 0.5 ms | 0.00 V | 4.92 V |
| 2 ms | 0.00 V | 4.97 V |
| 10 ms | 0.00 V | 4.84 V |
| 50 ms | 0.00 V | 4.26 V |
| 100 ms | 0.00 V | 3.69 V |

**No relay ever latches, on any ramp.** This is the fix that came out of the
sim: at **C5 = 1 µF** a slow (> ~30 ms) ramp releases `PORN` below the 2.5 V RST
threshold *before the rail is up* and a latch could power up energised. **10 µF**
(same value / reason as v2's C24) holds `PORN` ≈ `VBUS` through any realistic
ramp.

### MIC. passive mic path (7 / 7)

`spice/mic_path.cir`: one relay energised (`Vc2 = 0.08 V`, the 2N7000 `Vds(on)`),
the other three idle; electret JFET capsule on `HS_MIC`; each notebook a
2.2 V / 2.2 k source with 40 pF of jack/wiring stray.

| # | requirement | result | ngspice |
|---|---|:--:|---|
| MIC1 | usable DC bias reaches the electret (selected) | ✅ | **0.89 V** at the capsule (0.5–1.8 V window) |
| MIC7 | **a de-selected / muted notebook still reads "mic present"** | ✅ | **1.10 V** via NC → 2.2 kΩ → GND — vs **2.20 V** (open) before the fix, which reads as *"no microphone"* and makes many codecs fall back to the internal mic |
| MIC2 | routed-path response (selected) | ✅ | **0.00 dB ripple** 300 Hz–3.4 kHz, −3 dB at **200 kHz** |
| MIC3 | crosstalk to a de-selected notebook | ✅ | **−83 dB @1 kHz, −63 dB @10 kHz** (10 pF across the open NO contact into 2k2‖2k2) |
| MIC4 | mic reads "present" across the notebook bias spread | ✅ | electret + de-selected pin both sit at **45–69 % of the rail** for every rail 1.0–2.7 V / source 1.0–2.7 k — never near 0 (short), never near the rail ("no mic") |
| MIC5 | jack wiring: **pin 3 (tip) = mic, pins 2 & 4 = GND** | ✅ | datasheet terminal 3 is the tip leaf-spring; grounding **both** 2 and 4 is robust to a CTIA Y-splitter *and* to the ring-vs-sleeve pin-order question. Verified against the LCSC/EasyEDA pad data (part uuid `c718c744…`) + the HX PJ-320A-3P datasheet. Bring-up: meter pin 3 to the plug tip. |
| MIC6 | mute states carry no headset audio; every NB still "present" | ✅ | all four COMs rest on NC (2k2 → GND), none on `HS_MIC`; each notebook reads **1.10 V** |

### PW. power / system (4 / 4)

| # | requirement | result | ngspice |
|---|---|:--:|---|
| PW1 | total current ≪ 500 mA PTC hold and ≪ USB-C default | ✅ | **28.4 mA** (coil 27.6 + 2× CC 1.3 + Iq ≈ 0.1) |
| PW2 | PTC (RXEF050) margin | ✅ | 6 % of I_hold; ~1 Ω hot → ~28 mV drop |
| PW3 | VBUS transient clamp (P6KE6.8A, cathode → VBUS, pre-fuse) | ✅ | bus clamps at **≈ 7 V** under a 15 A surge — far below the ~18 V CD4043B abs-max; the surge returns through D1 to GND, not through F1 |
| PW4 | any USB-C source turns VBUS on (R1/R2 = 5k1 Rd) | ✅ | 5.1 kΩ is inside the 4.08–6.12 kΩ sink-detect window (v2 left CC floating) |

---

## B. Analytic MNA cross-check — 22 / 22

Same requirements, re-derived with the MNA solver and the logic model:
S (8, `select_logic.py`), P1–P3 (POR `.tran`, C5 = 10 µF), PW1–PW4 (power
arithmetic + CC window), MIC1–MIC7 (electret RO = 2200, RBIAS = 2200,
VBIAS = 2.2, R_contact = 0.1 Ω, R_NC = 2200). Every number matches simulation A
within the behavioural-model tolerance. Detail in `validation_results.json`.

---

## Limitations

- The CD4043B, 2N7000 and G5V-1 are **behavioural / datasheet-level** models, not
  vendor SPICE. Pin-outs are the project-local symbols — **verified against the
  TI CD4043B and ON-Semi 2N7000 datasheets** (S1 = pin 4, R1 = pin 3, OE = pin 5;
  2N7000 S-G-D = 1-2-3), still worth a continuity check on the first article.
- The G5V-1 coil inductance (~0.46 H) and pull-in/drop-out are estimated from the
  5 ms operate time — the logic result (exclusivity, power-on mute) does not
  depend on the exact value.
- Electret and notebook mic-input parameters are typical; the MIC4 sweep covers
  the realistic spread (1.0–2.7 V / 1.0–2.7 k) and every check still passes.
- The 10 J1-internal DRC clearance items (GCT USB4085 pad pitch) are a
  footprint/layout matter, not electrical — documented in `.kicad_dru`.

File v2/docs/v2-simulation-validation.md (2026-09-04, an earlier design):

# MeetingHub-4 v2 — circuit simulation & requirement validation

Date: 2026-09-03 · **updated 2026-09-04 for rev-10** (R16/R20 47 Ω → 10 Ω,
finding 1 applied — all automated checks now pass). Scope: electrical validation
of the v2 respin against the requirements in `v2-DESIGN.md` §1–§6.

> **rev-10 (2026-09-04):** the one failing check (D4, headset drive level) is
> resolved by lowering the U2A output series resistors R16/R20 from 47 Ω to 10 Ω
> (sim finding 1). Re-run: **§A–§G 21/21**, loaded gain 0.50× (−6 dB) / ngspice
> 0.456×, **0.65–0.79 mW into 32 Ω (+5.5 dB)**. Everything else reproduces
> unchanged. Numbers below are the rev-9 (47 Ω) values unless a line is marked
> **rev-10**; see CHANGELOG rev-10 for the full re-run.

## How this was run

LTspice itself is a Windows GUI tool and will not run in this (headless Linux)
environment. Two engines were used: a purpose-built MNA engine
(`../simulation/scripts/mna.py` — `.op` / `.ac` / `.tran`, idealised parts) for
§A–§M, and **ngspice 41 with datasheet models for the real BOM parts** for the
§N cross-check (`../simulation/spice/`). The two agree on every number. All gain / mute / frequency-response / impedance numbers come from
`.op` and `.ac`, which are exact complex solves with no time-step error;
transient waveforms in the video are reconstructed from those `.ac` transfer
functions by superposition. **Every block also has an equivalent LTspice
netlist** in `../simulation/ltspice/` (`01_vbias.cir` … `05_por.cir` +
`opamp.sub`) — open those in real LTspice to reproduce the numbers and to swap
in vendor NJM4580 / NJM4556A / LM358 SPICE models.

Component values and connectivity come from
`../hardware/PCB/MeetingHub-4-v2.net` and the KiCad sheets POWER / MIXER /
HPAMP / SELECT_LOGIC — **not** from the prose in `v2-DESIGN.md` (which turned
out to have two stale numbers, noted below).

Outputs:

- `../simulation/MeetingHub-4-v2-full-simulation.mp4` — **the full ~1 min
  end-to-end run**: block diagram → power-up → POR → mic selector sequence →
  4-laptop audio path → volume + mute check → all-volumes-zero → master volume →
  frequency response → scorecard.
- `../simulation/MeetingHub-4-v2-simulation.mp4` — short 3-scene version.
- `../simulation/MeetingHub-4-v2-mic-selector.mp4` — the one-hot button sequence.
- `../simulation/audio_in.wav` / `audio_out.wav` — a test signal (tone steps +
  20 Hz→20 kHz sweep) put through the *simulated* laptop-in → J6.T transfer
  function, at true relative level, so the loaded loss and bass roll-off are
  audible (the "Audio Out probe" idea, done offline).
- `../simulation/plots/*.png`, `validation_results.json`.
- `../simulation/plots/N_mic_switch_no_glitch.svg` — §O (mic-select transient vs.
  the monitor tone). §O/§P run from `spice/bom_mic_switch_glitch.cir`,
  `spice/bom_mic_deselect_detect.cir`, `spice/bom_relay_handover.cir`.

*(All artifacts regenerated for rev-9, 2026-09-03. Toolchain to rebuild them if
`/tmp` is wiped: `bash /home/fac/.simtools/regen_sim.sh` — micromamba env at
`/home/fac/.simtools/env` with ngspice 41 + ffmpeg + numpy/scipy/matplotlib.)*

## Result: 27 / 27 automated checks pass (rev-10) + the sequence sims (§E, §M, §O) + §N BOM cross-check

- **§A–§G idealised-model checks:** **21 / 21** (rev-10 — D4 headset drive level now passes with R16/R20 = 10 Ω; was 20/21)
- **§E one-hot selector sequence:** 8 / 8
- **§M mixer / volume-mute:** 6 / 6 — **"zero volume" is genuinely silent**
- **§N ngspice with real BOM device models:** every number reproduces
- **§O mic-select transient vs. monitor audio:** 7 / 7 — **switching the mic does not glitch the mixer** (< 80 µV, −63 dB)
- **§P de-selected laptop's mic-pin state:** ⚠️ **finding** — as-built, a de-selected laptop sees its mic pin *open* (= "no mic" to the codec); recommend NC → 2.2 kΩ to GND + COM/NO swap so it reads as a live-but-silent mic

The design is **electrically sound and meets its requirements for a USB-powered
conference-headset monitor/mic router.** The single failing check plus two
caveated passes share one root cause: the 47 Ω output series resistors and the
1 µF coupling capacitors are conservative for driving low-impedance headphones
with full-range material. None of it matters for voice.

**All three v1 bugs that cost R$3000 are fixed and independently re-verified
here:** pot direction + true mute (§B2, §M), relay wiring + one-hot exclusivity
(§E, §G2), VBIAS buffered to < 1 Ω (§A). The only residual risk is the Alps
pot terminal convention — a bench ohmmeter check, not a design issue (§M).

| # | Requirement | Result | Measured |
|---|---|:--:|---|
| **A. VBIAS (v1 bug #3 fix — buffer)** | | | |
| A1 | VBIAS = 2.50 V | ✅ | 2.5000 V |
| A2 | source impedance < 1 Ω (DC load step) | ✅ | 0.5 mΩ |
| A3 | Zout < 1 Ω @ 1 kHz | ✅ | 48 mΩ |
| A4 | Zout < 5 Ω @ 20 kHz | ✅ | 0.86 Ω |
| **B. Monitor chain, 1 laptop** | | | |
| B1 | system gain ≈ 0.66× (per `v2-DESIGN` §4) | ✅ | **rev-10:** 0.659× unloaded, **0.50× (−6 dB) into 32 Ω** (was 0.267× at 47 Ω) |
| B2 | pot direction: CW louder, full-CCW = mute (v1 bug #1) | ✅ | ≥ 66 dB CW-vs-CCW range (see §M for the mute floor vs pot residual R) |
| B3 | 100 Hz – 20 kHz flat within ±1 dB | ✅ | −0.7 dB @100 Hz, +0.0 dB @20 kHz |
| B4 | low-frequency extension | ⚠️ | **−3 dB @ 44 Hz, −10 dB @ 20 Hz** (fine for voice) |
| **C. Mixer (U1A, NJM4580)** | | | |
| C1 | per-channel gain −0.33 (−3k3/10k) | ✅ | 0.330× |
| C2 | no clipping, 1 laptop @ −10 dBV | ✅ | 0.15 Vpk / ±1.3 V headroom |
| C3 | no clipping, 4 laptops in phase (worst case) | ✅ | 0.59 Vpk / ±1.3 V headroom (45 %) |
| **D. Headphone amp (U2A, NJM4556A) + 32 Ω** | | | |
| D1 | AC gain 2× before the output network | ✅ | **rev-10:** 1.52× after the 10 Ω/32 Ω divider (was 0.81× at 47 Ω) |
| D2 | no DC on the headphones (C17 blocks) | ✅ | 0.0 mV |
| D3 | output cap big enough (C17 = 220 µF) | ✅ | 22.6 Hz for C17/32 Ω alone |
| D4 | > 0.5 mW into 32 Ω from a −10 dBV source | ✅ | **rev-10: 0.65–0.79 mW (≈ 145 mVrms), +5.5 dB** — finding 1 applied (was 0.22 mW / ❌ at 47 Ω) |
| D5 | back-check R16/R20 = 47 Ω (old value) | ✅ | old 0.22 mW confirms the rev-10 change is what buys the level |
| **F. Power-on reset (SELECT_LOGIC)** | | | |
| F1 | RST held ≥ 20 ms so a slow VBUS ramp still boots muted | ✅ | **139 ms** |
| F2 | no residual reset after settling | ✅ | 0 mV |
| **G. Power / system** | | | |
| G1 | total current < 500 mA (F1 hold, USB-C min) | ✅ | 50.6 mA (10 %) |
| G2 | only one relay energised at a time | ✅ | one-hot NOR latch (truth table) |
| G3 | VBUS TVS clamp 6–8 V behind F1, power-only | ✅ | P6KE6.8A, Vbr 6.45–7.14 V |

## E. One-hot mic selector — button sequence (added 2026-09-03)

Logic/timing simulation of the SELECT_LOGIC sheet built diode-by-diode from the
netlist (`../simulation/scripts/select_logic.py`; matrix D10–D29, U4 CD4043B NOR
R/S latches, POR, 2N7000 drivers, K1–K4 contact mapping). Video:
`../simulation/MeetingHub-4-v2-mic-selector.mp4`, plot `plots/E_select_logic.png`.

The exact sequence asked for is reproduced:

| action (one press each) | Q1 Q2 Q3 Q4 | mic goes to |
|---|:--:|---|
| power on | 0 0 0 0 | **muted** (POR holds every RST high ~140 ms) |
| tap SW2 (NB1) | **1** 0 0 0 | laptop 1 |
| tap SW3 (NB2) | 0 **1** 0 0 | laptop 2 — laptop 1 released |
| tap SW4 (NB3) | 0 0 **1** 0 | laptop 3 — laptop 2 released |
| tap SW5 (NB4) | 0 0 0 **1** | laptop 4 — laptop 3 released |

Why it is exclusive: button *n* drives `SETn` **and** the `RST` line of the other
three latches through the diode matrix, so one press simultaneously sets its own
latch and clears the other three. Only one relay coil is ever energised, so
`HEADSET_MIC` reaches exactly one laptop (rev-9 wiring: `NBn_MIC` on COM 5/6,
`HEADSET_MIC` on NO 10; a de-energised relay ties that laptop's mic pin to
2.2 kΩ → GND via NC, see §P). Contact bounce is harmless — the R/S latch just
re-asserts the same state.

Two-button gesture (SW3+SW4 together): `SET2=SET3=1` **and** all four `RST` are
pulled high, so every Qn = 0 → **muted**, and it *stays* muted after release (a
NOR latch left at S=R=1 holds Q=0). That is the intended "hold two buttons =
mute". **Doc fix:** `v2-DESIGN.md` §6 pass 3 says it "resolves to one selected
again" on release — that is wrong; it stays muted until a single button is
pressed.

## M. Mixer & volume — is "zero volume" actually silent? (added 2026-09-03)

This is the v1 bug #1 failure mode — pots wired so they never fully muted, which
cost R$3000 — so it was checked head-on (`../simulation/scripts/mixer_mute.py`,
plot `plots/M_mute_law.png`). Topology from the netlist: `Jn.T → Cn(1µF) →
RVn.3` (signal, CW end), `RVn.1` = VBIAS (CCW end), `RVn.2` wiper → `Rn(10k)` →
U1A virtual ground. Master RV5 identical downstream of the mixer.

| # | check | result |
|---|---|:--:|
| M1 | one channel at volume 0 (others also 0) is silent | ✅ **−66 dB, 42 µV** out for a 0.316 Vrms input |
| M2 | **all four** inputs at volume 0 → headset silent | ✅ **169 µV** (−65 dB) at J6.T with 4× 0.316 Vrms in |
| M3 | a zeroed channel doesn't leak its source into the mix | ✅ 9 V forced on a muted channel shifts the mix < 0.2 % |
| M4 | master RV5 at 0 → headset silent regardless of channels | ✅ 169 µV at J6.T |
| M5 | *control:* swap the pot ends (the v1 bug) → mute fails | ✅ reproduced — at the MIN knob position the output is at **full volume** |
| M6 | no scratchy pot (no DC step across the wiper) | ✅ wiper within 0.012 mV of VBIAS at every rotation |

Why it is silent: the only path from a laptop input to the mix is *through* the
pot — `Cn` couples only to `RVn.3`, nothing bypasses it. At the min (full-CCW)
position the wiper sits on `RVn.1` = VBIAS through ~0 Ω, so the signal (injected
through the full 10 kΩ of track) is swamped. Mute floor vs the pot's
end/wiper resistance:

| pot residual R | mute floor | residual at J6.T |
|---|---|---|
| 2 Ω | −74 dB | 17 µV |
| 5 Ω (typ) | −66 dB | 42 µV |
| 20 Ω | −54 dB | 168 µV |
| 50 Ω (worst) | −46 dB | 418 µV |

Even the worst case is ~0.4 mV against a full-scale output of ~85 mV → inaudible.
Because both pot ends are VBIAS-referenced (`RVn.1` directly, `RVn.3` through the
DC-blocking `Cn`), the wiper never sees a DC step as you turn it — no
zipper/scratch noise. Good design.

**⚠️ The one thing simulation cannot prove** (unchanged from `v2-DESIGN.md`
§6.5): all of the above assumes the Alps **RK09712200HA** has terminal 1 = the
full-CCW end and terminal 3 = the full-CW end. The v2 netlist is wired correctly
*for that convention* (signal → term 3/6, VBIAS → term 1/4 — the exact opposite
of the v1 bug). **Confirm on the first article with an ohmmeter: knob fully CCW
⇒ wiper (term 2) to term 1 ≈ 0 Ω.** If that measures the other way, the fix is
to swap the wires to `RVn.1↔RVn.3` and `RVn.4↔RVn.6` (or flip the footprint),
*not* a respin.

## N. Cross-check with real device models (ngspice, added 2026-09-03)

Everything above was re-run in **ngspice 41** with datasheet-parameterised
models for the actual BOM parts — NJM4580, NJM4556A, LM358 (2-pole op-amp
macromodels: GBW, slew, Avol, Vsat-vs-rail, Iq per datasheet), 1N4148 (matrix /
POR / free-wheel), 2N7000 (VTO 2.1 V, Rds(on) 1.8 Ω), P6KE6.8A (BV 6.8 V),
CD4043B (NOR-latch behavioural model, CD4000B 5 V thresholds), G5V-1 relay
(167 Ω coil + L, switched contact). Netlists: `../simulation/spice/*.cir` +
`models.lib`; plots `plots/BOM_*.png`.

**rev-9 (2026-09-03):** the whole ngspice suite was re-run after the K1–K4
COM/NO swap + R39–R42 NC hold-up. `bom_selector.cir` updated (COM = `NBn_MIC`,
NO = `HEADSET_MIC`, plus a complementary NC switch `SNC` + `Rnc1…4` 2.2 kΩ → GND).
Every number below reproduces; the de-selected-laptop mic pin now reads 1.25 V
(§P) instead of floating.

| quantity | idealised (§A–§M) | ngspice + BOM models | agree? |
|---|---|---|---|
| VBIAS DC | 2.5000 V | **2.4998 V** | ✅ |
| VBIAS @ 140 ms (POR release) | 2.30 V | **2.34 V** | ✅ (still rising) |
| VBIAS Zout @ 1 kHz / 20 kHz | 48 mΩ / 0.86 Ω | **21 mΩ / 0.45 Ω** | ✅ |
| system gain @ 1 kHz into 32 Ω | 0.267× (−11.5 dB) | **0.242× (−12.3 dB)** | ✅ finding 1 |
| response @ 20 Hz / 100 Hz | −10.3 / −0.7 dB | **−10.3 / −0.6 dB** | ✅ finding 2 |
| per-channel mixer gain | 0.330× | **0.300×** | ✅ |
| mixer swing, 4 correlated −10 dBV | ±0.59 V / ±1.3 V | **±0.78 V / ±1.1 V (70 %)** | ✅ no clip |
| one-hot sequence SW2→SW5 | Q1→Q2→Q3→Q4 exclusive | **identical, 4.98 V logic** | ✅ |
| POR: PORN at 100 ms | > 2.5 V | **3.20 V** (RST held) | ✅ |
| mic routing after select | only selected laptop | **selected 37 mV pp, others 0.4 µV** (rev-9 wiring, `bom_selector.cir`) | ✅ |

**All findings reproduce with real models.** The loaded gain is even slightly
lower (0.24× vs 0.27×) and the mixer worst-case uses ~70 % of the NJM4580's
headroom (a bit tighter than the ±1.3 V estimate, still no clipping).

### VBIAS buffer stability (checked because feedback is taken after R38)

`R38` (47 Ω) + `C26` (1 µF) sit *inside* the feedback loop (`U3` −in = VBIAS,
after R38). ngspice + LM358 model: a 2 mA load step on VBIAS settles with
**75 µV of ringing — no oscillation, stable.** `|Zout|` is ≤ 0.45 Ω to 20 kHz
but has a **~46 Ω peak at ~86 kHz** (loop gain gone, C26 resonating with the
residual output inductance of the loop). It is ultrasonic and un-rung by a load
step, so it is benign — but **glance at VBIAS with a scope on the first
article** for any HF fuzz. If it's real, 100 pF across R38 or R38 = 10 Ω tames
it. The as-drawn feedback-after-R38 choice is correct for DC/load accuracy
(feedback before R38 loses ~40 mV under load).

## O. Selecting a mic must not interrupt the monitor (mixer) audio (added 2026-09-03)

Requirement (user): *"quando eu selecionar um microfone para sair a voz do headset,
o mixer deve funcionar normalmente sem interrupção."* — pressing a select button
to route `HEADSET_MIC` to a laptop must not glitch or drop what you hear.

The mic path and the monitor path share **only** three nodes: the +5 V rail (a
relay coil is a ~30 mA load that switches on/off), the GND pour, and `VBIAS`
(derived from +5 V through R1/R2, buffered by U3). Netlist
`../simulation/spice/bom_mic_switch_glitch.cir` (+ `…_wc.cir` for the pessimistic
rail) runs a 1 kHz monitor tone through the **full** audio chain
(RV1 → U1A mixer → RV5 → U2A → C17 → R16 → 32 Ω) while the one-hot latch flips
**K1 → K2** at t = 320 ms, on a rail model with trace R/L between the bulk caps
(C2/C23), the relay coils and the op-amp supply pins. ngspice 41 + BOM device
models. Plot: `../simulation/plots/N_mic_switch_no_glitch.svg`.

| # | check | nominal rail | pessimistic rail | result |
|---|---|---|---|:--:|
| O1 | monitor tone amplitude at J6.T, steady | 108.3 mV pk | 108.3 mV pk | — |
| O2 | **change in tone amplitude across the switch event** | 41 µV / 216 mV pp = **0.02 %** | 42 µV = 0.02 % | ✅ |
| O3 | **worst transient glitch at J6.T** (tone-cancelled) | **< 80 µV** (−63 dB re signal; ~19 µV of that is the method's numerical floor) | < 80 µV | ✅ |
| O4 | +5 V rail sag at the logic/coil node when K1 drops + K2 pulls | **0.0 mV** (no dip; a +15 mV *bump* as D2 returns the coil energy) | 0.0 mV | ✅ |
| O5 | VBIAS deviation attributable to the switch | **< 1 mV** (the ~1–2 mV seen is power-up settling toward 2.5 V, rising monotonically through the event, not a step) | < 1 mV | ✅ |
| O6 | mic actually moved | `NB1` 2.00 V → 0.04 mV, `NB2` 0.04 mV → 2.00 V | same | ✅ |
| O7 | no clipping / latch-up in U1A or U2A during the transient | tone stays a clean sinusoid, no rail excursion | same | ✅ |

**Why it is immune:** (1) the coil current changes over ~0.3–3 ms (coil L/R), not
as a step, so di/dt into the 110 µF of bulk is tiny — the rail moves < 1 mV;
(2) both op-amps reject what little rail movement there is by their PSRR (~90 dB);
(3) `VBIAS` is buffered and sits behind C3 (10 µF, ~3 Hz corner) so it cannot move
on a millisecond timescale; (4) the mic path has **no amplifier and no node in
common with the L/R audio** — it ends at the laptop's mic pin. The free-wheel
diodes D2–D5 (correct polarity, unlike v1) dump the de-energising coil's energy
*into* the +5 V rail as a small positive bump rather than letting it kick the rail
negative. Only one coil is ever switched at a time (§G2).

**Not a monitor-path issue, noted for completeness:** during the ~1–3 ms coil
hand-over both relays are briefly de-energised, so the *mic* is routed to neither
laptop for a few ms mid-press — the intended one-hot behaviour, inaudible on the
far end, and it does not touch the headset audio.

## P. Does a DE-SELECTED laptop's OS think the headset mic is still connected? (added 2026-09-03)

Requirement (user): *"laptop 1, com microfone ativo, mudo para o laptop 2. O SO
(Windows) do laptop 1 vai achar que o microfone está ligado ou desligado?"*

**This is a real integration finding, not just a check — see the recommendation.**

### How a laptop decides

The board's TRRS plug **never leaves** laptop 1's jack, so the mechanical
jack-detect switch stays "inserted" forever. The codec classifies the jack as
*headset (has mic)* / *headphones (no mic)* / *nothing* purely from the **DC it
reads on the MIC sleeve**: it drives the sleeve through a bias resistor
(~2.2 kΩ) from ~2.5 V and measures the voltage.

| sleeve DC | codec reads it as |
|---|---|
| ≈ Vbias (open circuit) | **no mic** — re-task to headphones-only |
| mid-range, ~0.8–2.0 V (a load is present) | **headset microphone present** |
| ≈ 0 V (shorted) | no mic — 3-pole plug |

### What the v2 board presents (`../simulation/spice/bom_mic_deselect_detect.cir`, ngspice `.op`)

**rev-8 (as-built at the time of this finding):** `NB1_MIC` = `J2.S` + `K1` pin 10
(NO) only; `K1` pin 1 (NC) *unconnected* → a de-energised relay left the laptop's
mic pin **fully open**.
**rev-9 (fixed):** `NB1_MIC` = `J2.S` + `K1` pins 5/6 (COM); NO 10 → `HEADSET_MIC`;
NC 1 → `R39` 2.2 kΩ → GND → a de-energised relay ties the pin to 2.2 kΩ.

| scenario | sleeve DC the laptop-1 codec reads | codec verdict |
|---|:--:|---|
| laptop 1 **selected** (real headset electret, ~2 kΩ DC) | **1.19 V** | headset mic present ✅ |
| laptop 1 **de-selected — NC open (rev-8)** | **2.50 V** | **looks identical to "no microphone"** ⚠️ |
| laptop 1 de-selected — **NC → 2.2 kΩ to GND (rev-9)** | **1.25 V** | headset mic present ✅ (indistinguishable from a real idle mic) |
| laptop 1 de-selected — NC → straight GND | **0.001 V** | "3-pole headphones, no mic" ⚠️ |

### The finding

**As-built, switching away from laptop 1 drives its mic pin to the full bias
voltage — the exact DC a codec sees when no microphone exists.** The OS-level
result then depends on the codec:

- **Codec that re-senses the jack (most modern Realtek / SoundWire with jack
  re-tasking):** it will likely reclassify the jack as headphones-only and mark
  the *Headset Microphone* endpoint **unplugged / unavailable**. Risk: the
  conferencing app on laptop 1 falls back to the **internal array mic** and
  starts transmitting room audio instead of going silent. It may also pop a
  "microphone disconnected" toast, and a "pop" on switch-back as the endpoint
  re-appears and the electret re-biases.
- **Codec that latches jack state at insertion (simpler / older):** the endpoint
  stays listed and the input is just **silence** — the clean "mute" behaviour.

Which one your target laptops do **must be bench-checked** — but the safe design
choice removes the ambiguity.

### Fix — APPLIED in rev-9 (2026-09-03)

**Give every de-selected laptop a constant "idle-electret" DC load** so no codec
ever changes its mind. Done in `gen.py` (MICSW), `pcb.py` (R39–R42), routed and
sim-verified (`bom_selector.cir` updated; one-hot routing unchanged, 37 mV
selected / 0.4 µV others). See CHANGELOG rev-9. **Still bench-verify on the
target laptops** — the OS half is codec firmware.

1. **Swap `COM` ↔ `NO` on K1–K4** in the MICSW sheet:
   `COM` (5/6) → `NBn_MIC` (laptop *n*), `NO` (10) → `HEADSET_MIC` (commoned).
2. **`NC` (pin 1) → new `R_NCn` = 2.2 kΩ → GND**, one per relay.

Then: selected laptop gets the real electret; every de-selected laptop sees
2.2 kΩ to GND ≈ 1.25 V on its mic pin (≈ the 1.19 V of a live mic) → codec holds
*headset mic present*, far end hears **silence**, no disconnect event, no
internal-mic fallback, no switch-back pop. At power-on and during a 2-button
mute **all four** laptops see "mic present, silent" instead of "mic gone".

Cost: 4× 2.2 kΩ THT resistors + the K1–K4 contact-side re-wire + re-route. The
coil / free-wheel-diode side (pins 2, 9) is unaffected. **Not a functional
respin of anything else** — the audio path, the one-hot logic and the POR are
untouched.

Alternative without re-wiring the relays: a permanent `~6.8 kΩ` from each
`NBn_MIC` to GND — simpler layout, but costs ~25 % headset-mic level when
selected and the de-selected pin only reaches ~1.9 V (still marginal for some
codecs). The COM/NO swap is the better fix.

### Can the board *tell* Windows to mute? — No (and why the fix is still the answer)

There is **no analog signal on a 4-pole headset jack that means "mute the
microphone"** to an OS. What the jack carries:

| signal | what Windows does with it |
|---|---|
| mic audio (AC on sleeve) | recorded |
| mic DC level (sleeve) | headset-vs-headphones-vs-none detection (§P) |
| **resistance mic→GND**: 0 Ω / ~240 Ω / ~470 Ω | inline-button **media keys** — play-pause / vol+ / vol− |
| mechanical jack-detect | plug in / out |

Mic **mute** in Windows is a software / HID function — the Sound-panel toggle or
a USB-HID *Telephony → Phone Mute* usage. Nothing on the analog jack sets it.
There is no resistor code for "mic mute" (0 Ω is the play-pause / hook code, so
grounding the mic pin to "signal a mute" would instead fire a media key at every
switch and on contact bounce — another reason **NC → straight GND is wrong**,
2.2 kΩ is right).

So with the recommended fix the mute is **functional, not signalled**: the mic
endpoint on the de-selected laptop stays *present and unmuted*, its level meter
flat, and the far end hears **nothing because no audio is routed there**. Windows
never shows "muted". That is the correct outcome for a "install nothing, no USB,
no firmware" box. A Windows-visible mute would require adding a **USB-HID device
per laptop** (a cable to each machine + the box enumerating on each) — a
different product, against the project's premise.

### Hand-over timing — mic briefly on *neither* laptop, not stuck on both

`../simulation/spice/bom_relay_handover.cir` (current-sensing relay model, so the
free-wheel diode slowing the release is captured). One button press at t = 0:

| event | time after press |
|---|---|
| K1 (old) coil current decays through drop-out (~3–10 mA), contact opens | **+2.5 … +4 ms** |
| K2 (new) coil current rises through pull-in (~22 mA), contact closes | **+4 … +6 ms** |

Plus ~1–3 ms of mechanical armature travel not in the electrical model. Net:
a **~2–6 ms window where `HEADSET_MIC` reaches no laptop** (break-before-make) —
the mic just blips off mid-press, inaudible. If the exact relay releases slower
(freewheel diode dependent) the windows can instead briefly overlap: the headset
mic tied to the old + new laptop for a few ms, both bias currents limited to
< 1 mA by the laptops' own bias resistors — harmless, at most one faint click on
the far end. Either way it is a few milliseconds, once per switch, with no
Windows-visible consequence. If a guaranteed break-before-make is wanted, put a
**100–470 Ω resistor (or a 15–24 V zener) in series with D2–D5** to speed the
release — fold it into the same change as the §P resistors.
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

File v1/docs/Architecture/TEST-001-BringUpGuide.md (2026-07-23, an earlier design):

# TEST-001 - Board Test and Bring-Up Guide

Version: 1.0
Status: Final

Practical guide for testing the assembled board, in the correct order -
from the safest tests (without power applied) up to full operation with
the 4 laptops. **Follow the order**: each phase should only begin after
the previous one passes cleanly - this is how you avoid burning a
component due to an assembly error that would go unnoticed if you powered
everything up at once.

# Phase 1 - Visual inspection (before any power)

With the board assembled and **nothing connected to the power supply**,
check with a magnifying glass/good light:

1. **Solder**: no cold joints (dull/cracked appearance), no solder blobs
   touching an adjacent pad (short), no missing solder on any pin.
2. **Polarity of polarized components** - the most important item in this
   phase, because reversing any of these **will burn the component or the
   rest of the board** when powered on:
   - **C17, C20** (220uF, electrolytic): the stripe/mark on the capacitor
     body marks the **negative** terminal - check it against the board's
     silkscreen before powering on.
   - **C2, C3, C16, C19** (10uF, electrolytic): same logic.
   - **D1** (TVS, protection): has polarity - check the cathode stripe
     orientation against the silkscreen.
   - **D2-D5** (1N4148): the stripe on the body marks the cathode - check
     it against the "K" marking on the silkscreen (see PCB-001 Phase 8,
     these markings were repositioned so they would not be cut off).
   - **U1, U2** (DIP-8): the notch/dot on the IC body marks pin 1 - check
     it against the silkscreen drawing before inserting into the socket
     (if using a socket, as recommended in BOM-002 for the prototype).
   - **J1** (USB-C): the connector is mechanically "keyed" and only fits
     one way - but check that the solder on the connector's SMD/THT
     terminals is solid, since it is mechanically stressed every time a
     cable is plugged in.
3. **No visible short** between adjacent traces/pads, especially in the
   U1 area (dense mixer grid) and the J1 area (USB-C, fine pins).

# Phase 2 - Continuity test (multimeter, still no power)

With the multimeter in **continuity/resistance** mode, board still
**without USB connected**:

1. Measure between **TP1** (+5V_AUDIO) and **TP2** (GND). It should show
   an **open circuit** (no continuity, high/infinite resistance, not a
   short-circuit beep). If it shows direct continuity (0 ohm or a
   short-circuit beep), **do not connect the power supply** - there is a
   short between the power supply and ground that must be found and
   corrected first (review the solder near J1, D1, F1, C1).
2. Check the continuity of fuse **F1** in isolation (the fuse's own two
   ends) - there should be continuity (fuse good, not yet blown).

Only proceed to Phase 3 after both items above are OK.

# Phase 3 - First power-up

1. Connect a **simple data/power** USB-C cable (not a laptop charger
   with high-voltage Power Delivery - ideally a USB-A to C power supply
   or a simple phone charger, 5V) to input J1. **Do not connect any
   laptop or headset yet.**
2. **Smell and observe** during the first few seconds - if you smell
   burning or see smoke, **disconnect immediately** and review Phase 1
   and 2 before trying again.
3. With the multimeter in DC voltage mode, measure **TP1 relative to
   TP2**: it should read close to **5V** (typically 4.8-5.2V, since
   there is no regulator on this board - the +5V_AUDIO voltage is the
   USB input voltage itself, only protected by the fuse and TVS, see
   DR-003).
4. Lightly touch the body of **U1** and **U2** (the two DIP-8 ICs) after
   about 30 seconds of operation - they should be at room temperature or
   only slightly warm at most. If either is **hot enough to be
   uncomfortable to the touch**, turn off power and review the IC
   orientation (pin 1) and its supply voltage.
5. Measure the **VBIAS** voltage: this is the mid-signal reference for
   the mixer, generated by a resistive divider R1/R2 (10k/10k) on the
   MIXER sheet - measure at the junction point between R1 and R2 (or
   directly at pins 3/5 of U1, which receive VBIAS). It should read
   approximately **half the TP1 voltage** (~2.5V if TP1 read 5V). If it
   reads very different from that (close to 0V or close to 5V), there is
   a problem in the R1/R2 divider or a cold solder joint on one of them.

If the 3 voltage points (TP1 ~5V, VBIAS ~ half of TP1, GND=0V reference)
check out, the power supply is healthy - proceed.

# Phase 4 - Functional test (with laptops and headset)

Now, with the board powered on and electrically validated:

1. **One laptop at a time first** - connect laptop 1's cable to **J2**,
   and the headset to **J6**. Play a test audio on the laptop (e.g., any
   video) and confirm you hear it in the headset.
2. Repeat individually for **J3** (laptop 2), **J4** (laptop 3), **J5**
   (laptop 4) - each one alone first, before testing all together.
3. **Individual volume**: turn each potentiometer **RV1** (NB1), **RV2**
   (NB2), **RV3** (NB3), **RV4** (NB4) and confirm it controls the
   volume of that specific laptop, without affecting the others.
4. **Overall volume**: turn **RV5** (master) and confirm it affects the
   volume of all of them simultaneously.
5. **Simultaneous monitoring**: with all 4 laptops playing audio at the
   same time, confirm you hear the mix of all 4 in the headset (this is
   the RF-003 acceptance criterion of ERS-001).
6. **Microphone selection**: activate switches **SW2** (selects NB1),
   **SW3** (NB2), **SW4** (NB3), **SW5** (NB4) one at a time - speak
   into the headset microphone and confirm, in the calling/recording
   software of each laptop, that **only the selected laptop** receives
   the microphone audio. You should hear the corresponding relay
   (**K1-K4**) make a small mechanical "click" when switching selection
   - this is expected and normal.
7. **MUTE**: activate **SW1** and confirm that the microphone is cut off
   regardless of which laptop was selected.
8. **Driverless recognition**: on each laptop, confirm that the
   operating system recognizes the connection as a standard TRRS headset
   (default headphone/microphone icon), without requesting driver
   installation or opening any warning - this is the RF-008/Section 3
   criterion of ERS-001.

# Phase 5 - Durability test (optional, but recommended before heavy use)

ERS-001 defines a target of **>1 million operations** for the microphone
selector. It is not feasible to test this manually before normal use, but
it is worth doing, before considering the prototype approved for daily
use:

- Activate each selection switch (SW2-SW5) 50-100 times in a row,
  confirming that the corresponding relay keeps switching cleanly
  (no audio "crackling" or intermittent cutting during the switch).
- Leave the board powered on for a few continuous hours, periodically
  revisiting Phase 3 step 4 (U1/U2 temperature).

# What to do if something fails

| Symptom | Where to look first |
|---|---|
| TP1 does not show ~5V | Fuse F1 (blown?), J1 solder (USB-C), short detected in Phase 2 |
| VBIAS far from TP1/2 | Cold solder joint on R1 or R2 (MIXER sheet) |
| A specific laptop plays no audio | Solder on the corresponding jack (J2-J5), continuity of the TRRS cable used |
| Audio from one laptop leaks into others / strange mixing | Review U1 (orientation, solder), this is the IC that sums the 4 signals |
| Headset plays nothing | U2 (headphone amplifier) - orientation, solder, or incorrect VBIAS reaching it |
| Microphone selection does not switch | Corresponding relay (K1-K4) - solder, or physical switch connected to the wrong JST (check SW2->K1, SW3->K2, SW4->K3, SW5->K4) |
| MUTE does not cut audio | SW1, review wiring to the JST |
| Laptop asks for a driver / does not recognize as a headset | Check the actual headset's TRRS plug pinout against the CTIA standard (tip=L, ring1=R, ring2=MIC, sleeve=GND) - a plug that does not follow the CTIA standard (e.g., OMTP) confuses the laptop |

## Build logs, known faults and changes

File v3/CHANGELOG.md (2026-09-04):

# MeetingHub-4 v3 — changelog

## 2026-09-03 — v3 initial (mic selector only)

New project, spun from `../v2/`. **Only the one-hot microphone selector** — the
audio/monitor half of v2 is deleted (mixer `U1`, headphone amp `U2`, VBIAS
buffer `U3`, pots `RV1–5`, all their passives, and the L/R jack wiring). The
user monitors on an external mixer and feeds this board a mic-only plug per
notebook via a TRRS Y-cable.

**Kept net-for-net from v2** (the part its SPICE run validated): `CD4043B` `U1`
quad NOR R/S latch, the 16-diode steering matrix `D6–D21`, SET/RST pull-downs
`R3–R10`, power-on-reset `C5`/`R11` + `D22–D25` (power-on = muted), MOSFET coil
drivers `Q1–Q4` (2N7000) + `R12–R19`, fly-back diodes `D2–D5`, and the four
Omron `G5V-1` relays `K1–K4` (COM → `HS_MIC`, NO → `NBn_MIC`).

**Changed on purpose:**

| # | change | reason |
|---|---|---|
| 1 | added `R1`/`R2` = 5.1 k, CC1/CC2 → GND | v2 left the USB-C CC pins floating; a C-to-C cable to a charger then never turns VBUS on. With Rd present any USB-C source delivers 5 V. |
| 2 | jacks `J2–J6` → **3-pole 3.5 mm TRS** (new local footprint `Jack_3.5mm_3pole_THT_Horizontal`); tip **and** ring both tied to the mic net | v2's 4-pole TRRS jack cannot correctly receive a Y-splitter's mic plug (its long sleeve bridges the R2 and S springs). A 3-pole jack with T+R paralleled accepts "mic on tip" and "mic on tip+ring" wiring alike. |
| 3 | `D1` TVS explicitly on **VBUS (pre-fuse)** | surge shunted by D1, not forced through F1. |
| 4 | `C3` 100 µF → **47 µF** (D5 radial) | one relay coil ≈ 30 mA; 47 µF + 10 µF + 100 nF is ample. |
| 5 | all axial R / D → **vertical** footprints (`…_P2.54mm_Vertical`) | biggest single board-area saving. |
| 6 | **flat single-sheet** schematic; refs renumbered `U1`, `SW1–4`, `D1–D25`, `R1–R19`, `C1–C5` | 60 parts don't need hierarchy. |

**Board:** initially 2-layer, ~104 × 86 mm (≈ ⅓ of v2's 192 × 156), R3 corners,
4× M3, 100 % through-hole, ~69 parts. *(Later changed to 4-layer / 106 × 86 mm —
see the "4-layer" and "jack part finalised" entries below.)*

## 2026-09-03 — simulation + two fixes

Added `simulation/` (see `docs/v3-simulation-validation.md`): MNA + logic model
for the selector, POR, power and the passive mic path, plus ngspice/LTspice
`.cir` decks. Two changes came out of it:

| # | change | reason |
|---|---|---|
| 7 | jacks `J2–J6` → **Tip = mic, Ring + Sleeve = GND** (was Tip+Ring both to mic) | a CTIA TRRS→2×3.5 Y-splitter puts the mic on the tip and ties the mic-plug ring/sleeve to ground — tying the jack Ring to the mic net shorts the mic on ~half the splitters sold. Grounding Ring + Sleeve is universal. |
| 8 | POR cap `C5` 1 µF → **10 µF** (electrolytic) | with 1 µF a slow (>~30 ms) USB-C soft-start ramp releases the reset before the rail settles → the CD4043B could latch a relay at power-on. 10 µF holds PORN ≈ VBUS through any ramp → deterministically muted (same value/reason as v2's C24). |

## 2026-09-03 — 4-layer

The selector is 4× denser than in v2 (same CD4043B + 16-diode matrix + relays in
¼ the area) and would not route clean on 2 layers — every 2-layer plane split
(F.Cu +5V / B.Cu GND, GND-only, GND-both) fragmented a pour and trapped a
GND/+5V pin or two. **v3 is now 4-layer:** `F.Cu` + `B.Cu` signal, `In1.Cu` =
solid GND plane, `In2.Cu` = solid +5V plane. Routes clean, no fragmentation, no
escape stubs. Order as **4-layer, 1.6 mm** (JLCPCB 4-layer at ~106 × 86 mm is a
few dollars over 2-layer — negligible next to shipping at hobby quantities, and
it buys a quiet, properly-grounded board).

## 2026-09-03 — jack part finalised

`J2–J6` = **SHOU HAN PJ-320A-3P DIP, LCSC C17701689** — P2 (3.5 mm) 3-conductor
right-angle **through-hole** jack. The local footprint
`Jack_3.5mm_3pole_THT_Horizontal` was rebuilt to the standard PJ-320 THT pin
pattern (T/R 4 mm apart, S offset, barrel overhangs -Y), 1.8 mm round pads.
Board grew to **106 × 86 mm** to fit the wider jack bodies. **Still verify the
T/R/S pin map with a multimeter on the real part before assembly.**

*(The earlier BOM code `C145843` was a wrong placeholder — it is a Korean
Hroparts slide switch, not a jack. Caught by the user.)*

User note: "componentes J2–J6 devem ser P2" — confirmed, all 5 are P2 (3.5 mm);
the only non-P2 connector is J1 (USB-C, power only).

**Toolchain:** `gen_sch.py` (label-on-pin, collision-asserted) → `kicad-cli`
netlist → `gen_pcb.py` (`pcbnew`, courtyard-overlap warner) → `route.py`
(ExportSpecctraDSN + patch inner layers to `power` + Freerouting 2.2.4, retrying
strategies until 0 unrouted) → `ses_import.py` → `post.py` (zone stitch + finish
any short net + DRC) → `bomcpl.py`.

## 2026-09-03 — mic-deselect detection (relay contact side)

The v2 ngspice `.op` (`bom_mic_deselect_detect.cir`) showed that with the NC pin
open, a de-selected notebook's mic pin floats to the full ~2.5 V bias rail —
identical to what its codec sees with **no microphone plugged in**. Codecs that
re-sense the jack then mark the headset mic gone and fall back to the notebook's
**internal** mic (Teams/Zoom would transmit room audio instead of silence), often
with a "mic disconnected" toast and a pop on return.

**Fix (4 resistors, no logic/POR/power change):**

| # | change | reason |
|---|---|---|
| 9 | swap relay **COM ↔ NO**: `COM` (5/6) → `NBn_MIC`, `NO` (10) → `HS_MIC` (common) | frees the NC contact to carry a bias load in the de-energised state |
| 10 | `NC` (1) → **`R20–R23` 2.2 kΩ → GND**, one per relay | a de-selected / muted notebook now reads **~1.1 V** on its mic pin — the same as the selected path's live electret (sim MIC7) — so every codec keeps "headset mic present, silent": no disconnect event, no internal-mic fallback, no pop. Bonus: at power-on and 2-button mute all four notebooks read "mic present, muted". |

Sim: `simulation/` updated (SPDT relay model, `mic_path.cir` / `selector.cir`
rewired, new check **MIC7**). BOM ~73 parts.

## 2026-09-04 — jack footprint from the real part data + component-level ngspice sim

**Jack footprint rebuilt from the LCSC/EasyEDA data for C17701689** (part uuid
`c718c744…`) and the HX PJ-320A-3P datasheet, replacing the earlier guess that
followed the generic KiCad PJ320E pattern (T/R 4 mm apart). The real part:
three 1.2 × 0.6 mm oval THT pads **numbered 2 / 3 / 4** (inline pair **7 mm**
apart + offset sleeve), two Ø1.0 mm NPTH posts 6.0 mm apart. The datasheet
schematic draws **terminal 3 as the tip leaf-spring**, so the schematic symbol
and footprint now use pins 2/3/4 and wire **pin 3 → mic, pins 2 & 4 → GND**
(grounding both moots the ring-vs-sleeve question). `bomcpl.py` gets a TO-92
CPL rotation offset. Silk tidied in `post.py` — DRC silk warnings 114 → 1.

**Component-level simulation added.** The box has `libngspice` but no `ngspice`
binary and PySpice rejects ngspice 42, so `scripts/ngspice_shared.py` is a small
ctypes binding to the shared library. `scripts/spice_sim.py` builds every
scenario netlist programmatically and runs it in **real ngspice-42** with
datasheet models (1N4148, 2N7000, G5V-1 coil+contact, CD4043B NOR latch,
electret JFET): full KVM button sequence, POR swept over VBUS ramps 0.05–100 ms,
mic path over the notebook bias spread 1.0–2.7 V / 1.0–2.7 k, power/TVS/CC.
**25 / 25 pass.** The MNA `validate.py` stays as a **22 / 22** analytic
cross-check. `scripts/spice_video.py` renders a 42 s mp4 from the ngspice traces.
Local symbol pinouts verified against the TI CD4043B / ON-Semi 2N7000 datasheets
(S1 = pin 4, R1 = pin 3, OE = pin 5; 2N7000 S-G-D = 1-2-3).

**Known items:** J1 GCT USB4085 pad-pitch clearance (documented in
`.kicad_dru`); cosmetic silk overlaps on the passive clusters; verify the exact
3.5 mm jack pin map and the `5k1` / `47µF` LCSC codes before ordering.

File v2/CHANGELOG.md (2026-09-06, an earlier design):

# MeetingHub-4 v2 — changelog

## 2026-09-05 — v2 rev-11 (J2–J6 footprint rebuilt — JLC SMT DFM reject)

**Problem:** JLC's SMT/assembly team rejected the (already fabricated) v2 order —
the package of C136687 (Korean Hroparts PJ-3200B-4A) *"cannot match the
corresponding pads on the PCB"* for J2–J6. Confirmed: the rev-8 footprint
`Jack_3.5mm_PJ-3200B-4A_Horizontal` was hand-drawn from the paper datasheet and
never checked against JLC's own land pattern. Vs the real C136687 pattern (pulled
from the LCEDA/EasyEDA library, `easyeda2kicad` v1.0.1):

| feature | rev-8 (wrong) | real C136687 |
|---|---|---|
| T–R1 / R1–R2 pad pitch | 4.00 / 3.00 mm | 4.00 / **3.34** mm |
| Sleeve pad vs T | −4.6 mm across, +1.1 mm | **+1.0 mm across, +4.4 mm** (~6.5 mm out of place) |
| locating posts | Ø1.30, **4.6 mm apart**, beside R1/R2 | **Ø1.50, 7.0 mm apart**, straddling the row |
| pad hole | oval 1.2×0.7 | **slot 0.9×1.8 mm** |

The Sleeve pin and both locating posts landed nowhere near their holes → the part
could not be assembled by JLC *or* by hand. The fabricated boards from that order
are scrap for this jack.

**Fix — footprint only, geometry rebuilt from JLC's library data:**

- `MeetingHub-4-v2.pretty/Jack_3.5mm_PJ-3200B-4A_Horizontal.kicad_mod` rewritten:
  4 slotted pads (0.9×1.8 mm) T/R1/R2 in a row at 4.00 / 3.34 mm + offset Sleeve,
  2× Ø1.50 NPTH posts 7.0 mm apart, exactly the LCEDA land pattern, rotated +90°
  so the barrel still points −Y (KiCad rot 0 = barrel over the −Y edge, same as
  rev-8, so J2–J5 stay rot 0 / J6 rot 180).
- **Pin→function unchanged** (T=LCEDA pin 2, R1=pin 4, R2=pin 3, S=pin 1). This
  matches the rev-8 datasheet call *and* is corroborated by the 4 mm-gap-end = T
  convention in KiCad's own `Jack_3.5mm_KoreanHropartsElec_PJ-320D-4A` (same
  manufacturer) and `Jack_3.5mm_PJ320E`. **Bench-confirm** anyway: plug a 3.5 mm
  TRRS plug, check continuity plug-sleeve→S pad, plug-tip→T pad.
- 3D model: `MeetingHub-4-v2.3dshapes/Jack_3.5mm_PJ-3200B-4A_Horizontal.wrl`
  (+ `.step`), generated by `easyeda2kicad` from C136687.
- `scripts/pcb.py`: J2–J5 y = REAR+10.2 → **REAR+8.0**, J6 FRONT−10.2 → FRONT−8.0
  (the rebuilt body is 2.85 mm shorter toward −Y); GND zone outline chamfered to
  the rounded rect + 4 pre-placed GND corner stitching vias (the re-route
  otherwise leaves one GND pour lobe near a corner unbonded → 1 "unconnected").
- `scripts/route.py` added (2-layer freerouting driver; v2 had none).
- `scripts/post.py`: also hides each footprint's F.Fab value text (KiCad-script
  default = the footprint name) — it was cluttering assembly renders. The
  manufactured silkscreen only ever had the reference designators; unchanged.
- **Netlist connectivity unchanged** (jack pins are still S/T/R1/R2 by name).
  Re-routed (freerouting 2.2.4, 0 unrouted), ses_import, post.
- **Headless DRC with the project loaded: 0 errors, 0 unconnected, 0 footprint
  errors, 5 cosmetic `silk_over_copper` (RV1–5 refs) — identical to rev-10.**
  0 SMD pads. Gerbers / drill / `-Gerbers.zip` / CPL / both BOMs regenerated.
- CPL J2–J5 rot 90 / J6 rot 270 (bomcpl +90° correction, same as rev-9/10).
  **Verify the jack rotation in JLC's assembly preview before re-ordering.**

**Order action:** the current PCB+SMT order is unrecoverable for the jacks →
reply **C (cancel both)** to JLC and re-upload this (rev-11) gerber + BOM + CPL.

**Still owed before re-order (GUI / mechanical, unchanged from rev-10 + new):**
open in the KiCad GUI, native ERC/DRC, 3D view — check the PJ-3200B-4A barrel
overhang (~1.4 mm) and the Ø1.5 post-to-edge (~1.5 mm) vs the acrylic; update the
enclosure cut plan for the new jack cut-outs; bench continuity-check the jack
pinout; the 3 rev-10 bench items (RK097 taper, R16/R20 code, de-selected-mic OS).

## 2026-09-04 — v2 rev-10 (headphone drive level — sim finding 1 applied) · FABRICATION AUTHORIZED

**Problem (validation finding 1, carried since 2026-09-03):** `R16`/`R20` = 47 Ω
sit **outside** the U2A feedback loop, so with a 16–32 Ω headset they form a
47/(47+32) ≈ 0.4 divider — loaded system gain **0.27×** (−11.5 dB), ~0.22 mW into
32 Ω. Fine for voice/IEMs, quiet for 32 Ω over-ear headsets. This was the single
failing automated check (D4).

**Fix — two resistor values, nothing else:**

| ref | was | now |
|---|---|---|
| R16, R20 (U2A / U2B headphone output series) | 47 Ω (Yageo MFR-25FBF52-47R5, C3373549) | **10 Ω** 1/4 W metal-film THT axial — UNI-ROYAL MFR0W4F100JA50, **LCSC C57437** (±1% ±50 ppm, D2.2×6.5 mm, JLC ~10 800 in stock) |
| R38 (VBIAS buffer isolation) | 47 Ω | **unchanged** — still 47R5 / C3373549 |

- **Same footprint** (`R_Axial_DIN0207_…P10.16mm`), same pads, same position,
  same rotation. **Netlist connectivity byte-identical to rev-9** (95 nets, node
  sets verified equal). **No re-route.** Gerbers, drill and CPL are unchanged;
  only the schematic PDF and the 3 BOM files change.
- **Result (both engines re-run):** MNA §A–§G now **21/21** (was 20/21); loaded
  system gain **0.50×** (−6 dB) MNA / **0.456×** (−6.8 dB) ngspice+BOM-models;
  **0.65–0.79 mW into 32 Ω** (was 0.22 mW) → **+5.5 dB**, D4 passes. §M mute
  6/6, §E one-hot 8/8, §O mic-switch glitch < 80 µV, §P 1.25 V hold-up — all
  still reproduce. Full artifact set regenerated (`plots/*.png`,
  `validation_results.json`, `audio_*.wav`, 3 MP4s).
- **Short-circuit safety:** NJM4556A is a 70 mA line driver with internal
  current limit; 10 Ω still limits a dead-short at the jack and keeps the stage
  unconditionally stable (checked in `.ac`, no peaking).
- Files: `HPAMP.kicad_sch` (R16/R20 = 10), `hardware/PCB/*.net` (regenerated),
  3 BOM CSVs, `bomcpl.py` (10 Ω DB entry), sim scripts + `spice/bom_audio.cir`
  + `spice/bom_mic_switch_glitch*.cir` + `ltspice/03_hpamp.cir` +
  `ltspice/04_fullchain.cir`.

**Pre-order checklist that still stands (not design issues):**
1. **Bench-check the Alps RK09712200HA terminal convention** — knob full-CCW ⇒
   wiper (term 2) ↔ term 1 ≈ 0 Ω. Netlist is wired correctly for that
   convention; a reversed pot is a wire swap, not a respin. This is the exact
   class of the v1 bug — do not skip it.
2. **R16/R20 part (resolved 2026-09-04):** the first pick (Yageo CFR-25JB-52-10R,
   C1364480) had only ~9 pcs of JLC stock. Replaced with **UNI-ROYAL
   MFR0W4F100JA50 / LCSC C57437** — 10 Ω 1/4 W **metal film ±1% ±50 ppm**,
   D2.2×6.5 mm, **~10 800 in JLC stock**. This *restores* the metal-film ±1% tier
   the position originally had (the 47R5 it replaces was Yageo MFR-25FBF52, also
   metal film ±1%) — a step up from the ±5% carbon-film first pick. Same
   DIN0207 P10.16 mm footprint. Drop-in alt if ever needed: Yageo MFR-25JT-52-10R
   (C176452, metal film ±5%, ~12 000 stock).
3. **Bench-verify de-selected-mic OS behaviour** on the target laptops (codec
   firmware — the board side is correct, §P).

**JLCPCB stock snapshot (2026-09-04, full BOM re-checked via the assembly API):**
all 25 lines / 121 parts in assembly stock. Five low-stock lines cap the batch
size and should be pre-reserved / re-checked at order:
`RK09712200HA` C470545 **175** (×5/board → ~35 boards, the limiter) ·
`NJM4556AD` C2838125 **169** · `P6KE6.8A` C152132 **33** (any 600 W uni TVS
V_BR 6–8 V DO-15 substitutes, e.g. 1.5KE6.8A) · `CD4043BE` C22390239 488 ·
`NJM4580DD` C5184871 491. Everything else > 1000.

## 2026-09-03 — v2 rev-9 (de-selected-laptop mic hold-up, SCH-P)

**Problem (validation §P):** switching the mic away from a laptop left that
laptop's mic-jack sleeve **open**, which a Windows audio codec reads as "no
microphone" — it can drop the *Headset Microphone* endpoint and the conferencing
app can fall back to the laptop's **internal mic** (room audio) instead of going
silent.

**Fix — K1–K4 contact re-wire + 4 resistors:**

| relay pin | was | now |
|---|---|---|
| COM (5/6) | `HEADSET_MIC` | **`NBn_MIC`** (laptop *n*'s mic pin) |
| NO (10) | `NBn_MIC` | **`HEADSET_MIC`** (headset electret, commoned K1–K4) |
| NC (1) | *unconnected* | **`R39…R42` (2.2 kΩ) → GND**, one per relay |

Energised Kn still ties laptop *n* to the headset electret (talk). De-energised
Kn now ties laptop *n* to **2.2 kΩ → GND** — the DC of an idle electret
(sim §P: 1.25 V on the sleeve vs 1.19 V for a live mic) — so the codec keeps the
mic endpoint alive and the far end just hears silence. Also removes the same
"mic gone" ambiguity at power-on and during a 2-button mute.

- **New parts:** R39–R42, 2.2 kΩ 1/4 W carbon-film axial THT, YAGEO
  CFR-25JB-52-2K2, **LCSC C1364486** (JLCPCB in stock). BOM: 117 → **121 parts**,
  24 PCBA lines.
- **Coil / free-wheel-diode side (K1–K4 pins 2, 9; D2–D5) unchanged.** Audio
  path, one-hot logic (U4), POR, VBIAS — all untouched.
- **Layout:** R39–R42 placed as a horizontal stack at (168, 102…120) mm, open
  area right of the R21–R37 array. Board stays **192 × 156 mm**.
- **Re-routed** (Freerouting 2.2.4, `--random 0`): 902 seg / 35 vias, **0
  unconnected, 0 SMD pads**. DRC unchanged: the 8 J1 USB-C internal pad-pitch
  clearances (documented, pass in the GUI at netclass 0.15) + 5 cosmetic
  `silk_over_copper`.
- **Simulation re-run — nothing broke:** §A–§G 20/21 (the 1 = finding 1, R16/R20,
  pre-existing), §M 6/6, §E 8/8, §N ngspice all reproduce (`bom_selector.cir`
  updated for the swap: one-hot routing still 37 mV selected / 0.4 µV others),
  §O mic-switch glitch < 80 µV, §P now 1.25 V on a de-selected sleeve.
  **All artifacts regenerated** for rev-9: `plots/*.png`, `validation_results.json`,
  `audio_*.wav`, and the three MP4s (`…-full-simulation`, `…-simulation`,
  `…-mic-selector`). Rebuildable toolchain: `bash /home/fac/.simtools/regen_sim.sh`
  (micromamba env: ngspice 41 + ffmpeg + numpy/scipy/matplotlib — the previous
  session's `/tmp` env was lost to a reboot and rebuilt outside `/tmp`).
- Files: `gen.py` (MICSW), `pcb.py` (R39–R42 placement), `bomcpl.py` (2k2 part),
  `simulation/spice/bom_selector.cir`. Still **bench-verify the OS behaviour on
  the target laptops** — the codec half is firmware.

## 2026-09-03 — v2 rev-8 (JLCPCB stock substitutions)

Audited **every** BOM LCSC code against JLCPCB's assembly library
(`POST jlcpcb.com/api/overseas-pcb-order/v1/shoppingCart/smtGood/selectSmtComponentList`,
keyword = code; exact-match only). Every code on the old "verify" list was
either not in the PCBA library or pointed at the wrong part (SMD or a
completely different component). All fixed; **every part in rev-8 is now in
JLCPCB assembly stock, min-order 1**:

| ref | was | now | why the old code was bad |
|---|---|---|---|
| C1,C4,C21,C22,C25 (100 nF) | C49678 | **C2167231** (Vishay K104K15X7RF5TH5, 100 nF 50 V X7R, 5 mm pitch) | C49678 is an **0805 SMD** cap; the interim C5128365 had no LCEDA footprint/model. C2167231 is the same Vishay K-series as the 1 µF (C2167638). |
| C23 (100 µF 16 V) | C2909340 | **C346930** (NXA 100 µF 16 V, D5×11, 2.5 mm pitch — fits the D6.3/P2.5 pad) | C2909340 is a **0402 24 Ω resistor** |
| D1 | C736020 (MDD P6KE6.8A) | **C152132** (BORN P6KE6.8A, DO-15, uni, 5 k stock) | C736020 not in the PCBA library |
| R3,R4 (3k3) | C22978 | **C119335** (CCO MF1/4W-3.3K, 1/4 W metal-film axial +/-1%) | C22978 is an **0603 SMD** resistor; the interim C1369023 (TE LR1F3K3) had no LCEDA model. C119335 is the same CCO family as the 1 k (C120055). |
| J2–J6 | C2939642 "PJ-320E" | **C136687** (Korean Hroparts / HTC **PJ-3200B-4A**, 4-conductor TRRS, THT) | C2939642 is not a real LCSC code; HTC has no PJ-320-series THT jack in JLC stock |
| SW2–SW5 | C318884 | **C285519** (C&K **PTS645VK392LFS**, 6 mm right-angle THT tact) | C318884 is an **SMD-4P tact**; user wants a horizontal side-actuated button |
| U1 | C7466 | **C5184871** (NJM4580DD DIP-8) | C7466 resolves to a **SN74AHC1G04** single inverter (SOT-353) |
| U3 | C7950 | **C5213** (TI LM358P DIP-8) | C7950 is an LM358 in **SOIC-8**, not DIP |
| U4 | C39537 (0 stock, min 14) | **C22390239** (CD4043BE(LX/lingxingic) DIP-16, 490 stock) | genuine drop-in DIP CD4043B, no logic change. The interim C18723483 (XBLW) had no LCEDA footprint/model ("completed after order paid, +1 day"); C22390239 has a full footprint + 3D model. |
| F1 | C1562150 (Bourns MF-RG500, 60 stock) | **C76399** (Littelfuse RXEF050, 500 mA hold, 5.1 mm radial, 6 k stock) | stock too thin; same PTC spec |
| R16,R20,R38 (47R) | C2896824 (VO, insufficient stock for the order) | **C3373549** (Yageo MFR-25FBF52-**47R5** = 47.5 Ω 1 %, 7 k stock) | 1 % off nominal — series/isolation resistors, value not critical; same series as the other axials |

RV1–RV5 (C470545, Alps RK09712200HA) is in stock (185) but the JLCPCB BOM tool
does not auto-assign it (Extended part). **Fix: upload
`hardware/BOM/BOM-JLC-MeetingHub-4-v2.csv`** — new native-format BOM
(`Comment, Designator, Footprint, JLCPCB Part #`) that makes JLC use the LCSC
code for *every* part directly, no fuzzy matching. The PCBA BOM's LCSC column
was also renamed `JLCPCB Part #`.

**CPL / orientation — corrected.** JLC's 3D preview showed several THT parts
rotated wrong. `bomcpl.py` now applies a per-footprint rotation offset in the
CPL: for each footprint the KiCad pads were aligned to JLCPCB's own LCEDA
library footprint (`easyeda.com/api/products/<code>/components`) and the
0deg-to-0deg delta computed, calibrated against the PJ-3200B-4A barrel
direction. `CPL angle = KiCad orientation - offset`.

| footprint | offset | refs | CPL was -> now |
|---|---|---|---|
| DIP-8_W7.62mm | 270 | U1 U2 U3 | 0 -> **90** |
| DIP-16_W7.62mm | 270 | U4 | 90 -> **180** |
| Relay_SPDT_Omron_G5V-1 | 270 | K1-K4 | 0 -> **90** |
| Jack_3.5mm_PJ-3200B-4A_Horizontal | 270 | J2-J5 / J6 | 0 -> **90** / 180 -> **270** |
| Potentiometer_Alps_RK097_Dual_Horizontal | 180 | RV1-5 | 90 -> **270** |
| SW_Tactile_SPST_Angled_PTS645Vx39-2LFS | 180 | SW2-5 | 180 -> **0** |

The RK097 and PTS645 needed a second pass: JLC's 3D preview showed the pot
shafts pointing *into* the board. Their pad grids are too symmetric for the
pad-fit to resolve 0 vs 180, but the LCEDA footprint draws the body/actuator on
the opposite side of the pins from KiCad (KiCad's RK097 body is on the -X side,
matching the Alps datasheet top view; LCEDA's is on +X) -> offset 180, so the
shaft/plunger points off the front edge like the board silk shows.

Everything else matched at offset 0 and is unchanged (elec caps, all diodes,
TO-92, all axial R, ceramics, USB-C J1). Still worth a glance at JLC's upload
preview: electrolytic + diode polarity vs the silk, the DIP/relay pin-1 dot, and
that the J/RV/SW barrel/shaft/plunger points off the right board edge - THT
assembly at JLC is manual + a production review.

**Front-edge controls re-positioned.** Enclosure decided: top + bottom acrylic
only, **sides open, no front panel**. Controls are operated directly, so each
part's can body now sits ~flush with / just behind the open edge and only the
functional bit overhangs:
- RV1-5: y FRONT-3 -> **FRONT-5.5** (pull back 2.5 mm). RK097 9.55 mm can ends
  ~0.5 mm inside the edge; ~20 mm of M7 bushing + shaft overhangs for the knob.
  (Note: that shaft is only held by the 6 THT pins - no locating peg on this
  horizontal variant - so mount the knob near the body.)
- SW2-5: y FRONT-4.5 -> **FRONT-3** (push forward 1.5 mm). PTS645 plunger tip now
  ~1 mm past the edge for a clean finger press / button cap.
Re-routed **850 seg / 30 vias, 0 unconnected, 0 SMD**, DRC unchanged (8 J1 +
5 silk), no courtyard overlaps, no hole crosses the edge. Netlist node-identical.

New local footprint **`Jack_3.5mm_PJ-3200B-4A_Horizontal`** (pads T/R1/R2/S)
built from the HRO PJ-3200B datasheet (rev A): 3.00/4.00 mm pad pitch + offset
pin 1, 2×Ø1.30 locating posts, barrel nose 2.0 mm past the body face. Rotated
so the barrel overhangs −Y like the old PJ-320E fp. **Pin→function
confirmed** two ways: the datasheet schematic (pin 1 = barrel/Sleeve; springs
2/4/3 = Tip/Ring1/Ring2 by insertion depth) and the KiCad PJ320E pad pattern
(4 mm-gap end = T, 3 mm-gap end = R2). → T=pin2, R1=pin4, R2=pin3, S=pin1.

SW2–SW5 → `Button_Switch_THT:SW_Tactile_SPST_Angled_PTS645Vx39-2LFS`.
**Plunger direction confirmed** from the C&K PTS645 datasheet: the "V"
(vertical) termination actuates in the board plane; the KiCad fp's actuator is
at −Y, so **rot 180** points it at the FRONT edge. Placed at FRONT−4.5 → plunger
tip ~0.7 mm inside the edge (enclosure needs a hole/cap per button).

Board re-placed (jacks at REAR/FRONT ± 10.2 → body face ~at the edge, 2 mm
barrel overhang, Ø1.30 posts ~2.5 mm inboard; angled buttons rot 180) and
re-routed: **848 track segments / 39 vias, 0 unconnected pads, 0 SMD pads.**
DRC unchanged (8 J1-internal pad-pitch items that pass in the GUI at the
0.15 mm netclass; 5 cosmetic silk-over-copper). Netlist connectivity
node-identical to rev-7. BOMs + CPL + gerbers + schematic PDF regenerated.

**Still owed — a KiCad GUI / 3D pass before ordering** (mechanical only, the
electrical netlist is unchanged and already reviewed):
1. Open the 3D view, confirm the PJ-3200B-4A barrel overhang (~2 mm) and the
   PTS645 plunger reach vs the real acrylic panel; nudge REAR/FRONT offsets and
   re-route if the enclosure needs it.
2. Tidy silkscreen (5 silk-over-copper), run native ERC + DRC.
3. Update the acrylic enclosure cut plan for the new (larger) jack cut-outs.
4. First article: confirm the Alps RK097 T1=CCW / T3=CW pot convention.

## 2026-09-01 — v2 rev-7 (review follow-ups: POR + front support)

Circuit review (session dd4368fd) confirmed the 3 v1 bugs and the one-hot mic
logic are all correct in the netlist, and that the **jack orientation was
already right** (a mid-review claim that J2-J6 faced inward was mistaken and
retracted — on the PJ-320E the plug enters at the footprint's -Y barrel nub,
so J2-J5 at rot 0 / J6 at rot 180 have the barrels overhanging their edges,
openings facing out; unchanged). Two real changes, board re-routed:

- **C24 1 uF -> 10 uF** (Device:C_Polarized, CP_Radial_D5.0mm_P2.00mm, reuses
  the C43799 electrolytic already in the BOM). Stretches the power-on-reset
  pulse from ~4 ms to ~40 ms so a slow USB-C VBUS ramp still guarantees
  Q1-Q4 = 0 (mic muted) at power-on. Netlist connectivity byte-identical.
- **Added MH5, MH6** (M3) ~12 mm behind the front edge, near the left/right
  ends, to support the long front edge that carries the 5 pot knobs. BOM
  mounting-hole count 4 -> 6.
- Re-routed: **848 segments / 35 vias, 0 unconnected pads, 0 SMD pads.**
  DRC unchanged (8 J1-internal pad-pitch items that pass in the GUI at the
  0.15 mm netclass; 10 cosmetic silk-over-copper).
- BOMs + JLCPCB CPL + gerbers + schematic PDF regenerated.

Still verify on the bench: Alps RK097 terminal 1 = full-CCW end (the
pot-direction fix rests on the standard T1=CCW / T3=CW convention).

## 2026-09-01 — v2 (smaller / near-square board)

Started as a near-square re-layout of the same schematic as an earlier `v3/`
draft (larger landscape board; that draft was removed in the 2026-09-01
restructure and its history folded in here). Same schematic, symbols,
footprints, one-hot logic and all the v1 bug fixes — only the PCB layout
changed:

- **Board 192 x 156 mm** (v1 was 265 x 160) — near-square, ~29 % less area.
- Front controls (RV1-RV5, SW2-SW5, J6) pushed **~3-4 mm from the front edge**,
  bodies overhanging. Rear edge = J1 + J2-J5.
- Denser middle: mixer/hpamp resistor & cap banks in 2-3 short rows, relays
  2x2, select-logic diode matrix directly above the buttons, CD4043B rotated.
- Fully auto-routed: 0 unconnected pads, ~838 segments / 35 vias.
- DRC 0 errors (J1 pad-pitch passes at netclass 0.15 mm); ~10 cosmetic
  silk-over-copper warnings.
- BOM (v1 format, x2) + JLCPCB CPL regenerated for v2.

# MeetingHub-4 v2 — changelog

## 2026-09-01 — v2 rev-4 (smaller board, front controls at the edge, JLCPCB files)

- **Board 260 x 140 mm** (was 282x157) — tighter placement, more square.
- **Front controls hard against the front edge.** RV1-RV5 pads now ~4-6 mm
  from the edge (were ~9-21) with the bodies overhanging; SW2-SW5 and J6 the
  same. The select-logic resistor bank was moved out of the front strip.
- **All 5 pots identical**: Alps RK09712200HA horizontal (C470545).
- **All-THT jacks**: J2-J6 = PJ-320E (local footprint, silk trimmed);
  J1 stays the stock GCT USB4085. Board has 0 SMD pads.
- **DRC 0 errors** — the J1 pad-pitch clearances pass at the netclass 0.15 mm
  that v1 also used (set in .kicad_pro); only silk-over-copper warnings remain.
- **BOM now in the v1 format**: `BOM-MeetingHub-4-v2.csv` (Designators, Qty,
  Value, Footprint) + `BOM-PCBA-MeetingHub-4-v2.csv` (Item..LCSC..Notes,
  fitted parts only).
- **JLCPCB CPL**: `hardware/Gerbers/MeetingHub-4-v2-CPL.csv`
  (Designator, Mid X, Mid Y, Layer, Rotation; Y negated; no MH/TP) — replaces
  the KiCad-native pos file that JLCPCB rejected.
- Re-routed: 0 unconnected pads, ~880 segments / 36 vias.

## 2026-09-01 — v2 rev-3b (DRC clean)

- **DRC now 0 errors.** The 8 `clearance` errors were all between J1's own
  USB-C pads (0.85 mm pitch) — fixed by setting the netclass clearance to
  0.15 mm, the value v1 actually shipped with (JLCPCB floor is 0.127 mm).
  The 1 `starved_thermal` fixed by switching the GND zones to solid pad
  connection. C20's silk reference (the one `silk_overlap`) hidden.
- 20 `silk_edge_clearance` **warnings** remain — silk of the edge-mounted
  pots/jacks/M3-holes near the rounded outline; cosmetic, KiCad clips silk at
  plot. See `docs/v2-ERC-DRC-status.md`.

## 2026-09-01 — v2 rev-3

- **All 5 volume pots identical and horizontal.** RV1–RV2 changed from the
  vertical Alps RK09L1240A12 to the **horizontal RK09712200HA (C470545)** —
  the same part as the master RV5. All five sit on the front edge, bodies
  overhanging, one BOM line.
- **Zero SMD, verified pad-by-pad.** J2–J6 changed from the hybrid PJ-320D
  (THT body + 4 SMD signal pads) to the **fully through-hole PJ-320E**
  (verify LCSC C2939642); the R1/R2/S/T pad names are identical so no
  schematic rewire. A `pcbnew` scan now reports **0 SMD pads on the whole
  board.** (This also removes the v1 PJ-320D SMD-pad-size DFM problem.)
- Board re-placed and re-routed: **282 × 157 mm**, 0 unconnected pads,
  ~837 track segments / 33 vias. (Q1–Q4 moved to a clean right-edge column so
  every MOSFET-source GND pad routes.)
- Netlist byte-identical to rev-2 (only footprint/part properties changed).

## 2026-08-31 — v2 rev-2 (after first ERC/DRC + layout feedback)

- **ERC now clean.** The 216 `endpoint_off_grid` warnings were from the
  generated SELECT_LOGIC/MICSW sheets sitting off the 1.27 mm grid — the
  generator now snaps every coordinate. The `2N7000 modified in library`
  warnings are gone: the hand-authored 2N7000 lives in the project-local
  `MeetingHub-4-v2` symbol library, not shadowing `Transistor_FET`.
- **DRC `lib_footprint_issues` (118) fixed** — `pcb.py` now stamps each
  footprint with its library nickname (`SetFPID`).
- **Front / rear layout.** Front edge: RV1–RV2, RV5, SW2–SW5, J6 (headset).
  Rear edge: J1 (USB-C power) + J2–J5 (the four notebook jacks); barrels
  overhang their edge for panel mounting. Everything else in the middle.
- **Rounded board outline** (R8 corners), 4× M3 mounting holes just inside the
  corners/edges, GND test point **TP2** added near U1.
- **Board 286 × 157 mm**, 2 layers, fully auto-routed (0 unconnected pads,
  ~840 segments / 29 vias). Only DRC items left: 8 clearance errors between
  J1's own pads (KiCad USB-C footprint pitch — `.kicad_dru` documents it),
  ~39 cosmetic silk-overlap warnings, 2 starved-thermal.
- **Confirmed for the user:** there is **no microphone volume control** — the
  mic path is passive relay switching with no amplifier, so there is nothing
  to remove. The **mute button is already gone** (removed with SW1); mute =
  the power-on state, or hold any two select buttons.
- BOM CSV gained Manufacturer / MPN / LCSC columns; see `docs/v1-vs-v2.md`
  for the full v1↔v2 part comparison.

## 2026-08-31 — v2 initial

New self-contained project in `v2/`, derived from the v1 schematic with the
first-article fixes, then re-worked:

- **2-layer PCB** (was 4). GND pour on both copper layers instead of dedicated
  inner planes. ~328 × 128 mm, fully auto-routed (Freerouting), 0 unconnected
  pads, 842 track segments / 50 vias.
- **100 % through-hole.** `C1/C4/C21` 0603 → THT disc; `D1` SOD-323 TVS →
  `P6KE6.8A` DO-15. No SMD parts remain.
- **Bug 1 (pots) — fixed & verified.** Signal on Alps terminal 3/6, VBIAS on
  1/4, wiper 2/5. Clockwise = louder.
- **Bug 2 (relays) — fixed & re-architected.** Coil pins 2 (+5 V) / 9 (drive),
  COM 5/6 = HEADSET_MIC, NO 10 = NBx_MIC, NC 1 open. D2–D5 reoriented as coil
  fly-back diodes.
- **Bug 3 (VBIAS) — fixed.** Added `U3` (LM358) unity buffer + `R38` 47 Ω
  isolation with post-R feedback; `C26` 1 µF. `VBIAS_REF` label split off the
  divider in MIXER.
- **One-hot mic selector on-board.** New sheet `SELECT_LOGIC.kicad_sch`:
  `U4` CD4043B (local symbol), 20× 1N4148 diode matrix, power-on-reset
  (C24/R37/D26–29), 4× 2N7000 coil drivers with gate resistors. Buttons
  SW2–SW5 are now momentary 6 mm THT. Power-on state = nothing latched = mic
  muted. Press NBx → Kx on, others release.
- **No mute button.** SW1 removed. Mute = power-on state, or hold any two
  select buttons.
- **U1 NE5532 → NJM4580.** NE5532 is out of spec on the 5 V single rail;
  NJM4580 (±2 V min) is not, and is pin-compatible.
- **Mixer feedback R3/R4 10k → 3k3.** Gain −0.33/channel so four laptops
  playing together cannot clip U1 on the 5 V rail.
- Local libraries: `MeetingHub-4-v2.kicad_sym` (CD4043B), `.pretty` with the
  two Alps pot footprints (RK097 Edge.Cuts line moved to Dwgs.User so the
  board outline stays a clean rectangle).
- `.kicad_dru` rule relaxing clearance between two J1 pads (KiCad stock USB-C
  footprint pitch; not a real spacing issue).
- Build scripts kept in `hardware/KiCad/MeetingHub-4-v2/scripts/`.

### Known, non-blocking
- 29 silkscreen-overlap DRC warnings (dense THT ref designators) — tidy in GUI.
- 8 J1 footprint clearance errors (see `.kicad_dru`).
- Board larger than v1 — SELECT_LOGIC block can be compacted.
- High-impedance headphones will be quiet at the 0.66× system gain.

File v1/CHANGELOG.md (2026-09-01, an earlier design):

# Changelog

Milestone history of the MeetingHub-4 project, by phase. For the line-by-line history, see `git log`.

## First-article bring-up: 3 schematic bugs found on the fabricated boards (2026-08-28)

All 5 boards from JLCPCB lot `W2026080810364558` show identical faults →
design errors, not fabrication. Root causes found in the schematic and
confirmed against the PCB netlist:

1. **Volume pots RV1-RV5 reversed.** Signal was wired to the terminal that
   should be the cold/VBIAS end and vice-versa (pin 1/4 ↔ pin 3/6). Reverses
   the control direction and, because the pots are audio-taper wired
   backwards, leaves most of the travel near full volume with a cut only at
   the very end ("won't mute"). Fixed in `MIXER.kicad_sch`: pin 1/4 → VBIAS,
   pin 3/6 → signal, wiper (2/5) unchanged. Netlist verified.
2. **Mic-select relays K1-K4 have coil and contacts swapped.** `NBx_MIC` was
   on a coil pin (KiCad G5V-1 coil = pins 2 & 9), the switch/+5V drive was on
   the NC contact (pin 1), and the NO contact (pin 10) was a no-connect. The
   coils never energised and each laptop's mic line was loaded to GND through
   a ~167 Ω coil → mic dead on every laptop. Fixed in `MICSW.kicad_sch`: coil
   = pins 2 (GND) & 9 (drive), COM = 5/6 (headset mic), `NBx_MIC` → pin 10,
   pin 1 left open, D2-D5 reoriented as correct freewheel diodes. Netlist
   verified.
3. **VBIAS has no buffer** (10k/10k + 10 µF only) — flagged in DR-003 §6;
   likely source of residual bleed at min volume. Not changed in the
   schematic yet; documented as an optional fix.

Also noted: SW1-SW5 are momentary switches, so post-fix the mic is only live
while MUTE + a Select button are held.

**Selector-behaviour decision:** the user wants KVM-style **exclusive one-hot**
selection (press NB2 → NB1 releases itself), with momentary buttons. All-
hardware design added in `docs/Architecture/SCH-010-OneHotMicSelector.md`:
CD4043B quad RS latch + 16-diode matrix + power-on reset + 4x 2N7000 low-side
coil drivers. This supersedes REWORK-001 Parts A+D for the one-hot build (relay
coil re-wired pin2=+5V / pin9=MOSFET drain, D2-D5 flipped cathode->pin2). SW1
becomes a bridge or an optional 5th "mute/reset-all" button. Respin needs a new
SELECT_LOGIC schematic sheet (not built yet). The PS-22F03 latching-button work
below stays valid only if the plain-latching route is chosen instead.

**Switch decision for the respin (2026-08-28):** go with latching push-on/
push-off buttons. `MICSW.kicad_sch` updated: **SW1 (MUTE) removed** — with no
Select latched, all relays are off and the headset mic reaches no laptop,
which is the mute; `HEADSET_MIC` now goes straight to the relay COMs.
**SW2-SW5** kept as `Switch:SW_SPST` but re-pointed to a new footprint
`MeetingHub-4:SW_PushLock_PS-22F03` (PS-22F03 / A03 self-locking DPDT,
right-angle, DIP-6 2.54×7.62mm). Part: LCSC C2848947 (G-Switch PS-22F03NC) or
C19190927 (HOOYA). Footprint is a DRAFT — body/actuator dims and COM/NO pin
positions to be verified against the datasheet; front-panel spacing and the
enclosure cutouts need re-work (part is ~9.5mm vs the ~6mm tact switch). BOMs
updated (SW1-SW5 5pc → SW2-SW5 4pc). PCB switch work folded into
`docs/REWORK-002-PCB-Reroute.md` (Group F).

PCB (`MeetingHub-4-v1.kicad_pcb`) **pre-staged by script** (no manual routing yet):
- Fixed a **latent repo bug**: 14 footprints (RV1-5, C1, C4, C21, D1, SW2-5)
  had no schematic link (`path`), so any "Update PCB from Schematic" duplicated
  them off-board. All now linked (only MH1-4, TP2 unlinked — no symbol, normal).
- Reassigned affected pad nets to the corrected schematic (RV1-5 1/3/4/6,
  K1-4 1/9/10, D2-5 1/2, SW2-5); deleted the now-invalid/orphan track segments.
- **SW1 removed**; `Net-(SW1-B)` merged into `HEADSET_MIC` (+ short bridge).
- **SW2-SW5** swapped to `SW_PushLock_PS-22F03` and placed roughly in the front
  row (final placement + all routing still to do).
- Zones left unfilled (press `B`). No duplicate footprints, nothing off-board.
Opens with ~42 ratsnest lines. Routing checklist + Group F details:
`docs/REWORK-002-PCB-Reroute.md`. Hand-rework of the existing 5 boards:
`docs/REWORK-001-ExistingBoardFixes.md`.

## DRC pass on the SW1-SW5 / RV1-RV4 footprint changes (2026-08-07)

Ran a real DRC via `pcbnew.WriteDRCReport` (only path available - this
KiCad 7.0.11 CLI has no `drc` subcommand) against the board after the
two changes below, compared to a fresh baseline report from the
pre-change commit. Two self-inflicted issues found and fixed directly
(no rerouting needed):

- **8 unconnected pads on SW1-SW5**: caused by assigning the same net
  to *both* physical copper legs of each same-numbered pad (e.g. both
  "1" pads). That's electrically true (the real switch bridges them
  internally) but KiCad's DRC then expects a *routed* copper connection
  between the two pads, which doesn't exist on this board. Fixed by
  matching the convention the project's own prior SW1 footprint
  (`SW_PUSH-12mm`) already used: net only on the first pad of each
  number, second left with no net (still gets a drilled/soldered hole,
  just not routed — harmless, since the physical switch bridges it).
- **2 solder-mask-bridge errors on RV1/RV2 pad 1**: the official
  `Potentiometer_Alps_RK09L_Double_Vertical` footprint draws pad 1 as a
  sharp-cornered `rect`; at this exact position that aperture was close
  enough to a neighboring track to bridge solder mask between nets.
  Changed pad 1 to `roundrect` (rratio 0.25, same size/position/drill)
  matching the old RK097 footprint's pad 1 shape - resolved it without
  touching any track.
- Also refilled the GND/+5V_AUDIO inner-layer zones via
  `pcbnew.ZONE_FILLER` (editing pads/footprints doesn't auto-refill
  zones; the stale fill was itself producing extra clearance/thermal
  violations against the new pad shapes).

**Remaining — needs manual rerouting, not fixed here**: SW1-SW5's new
pads sit in different positions than the parts they replaced (the
switches have a genuinely different physical pin layout, not just a
size change like RV1-RV4 was). ~8-11 DRC errors remain, all on short
existing trace segments that no longer reach the new pad locations by
2-3mm: SW1 (HEADSET_MIC, Net-(SW1-B)), SW2 (Net-(D2-A), Net-(D3-A)),
SW3 (Net-(D3-A), Net-(D4-A)), SW4 (Net-(D4-A), Net-(D5-A)), SW5
(Net-(D5-A), Net-(J6-PadR1)) - all near the front-row +5V_AUDIO feed
and each switch's diode-side signal pad. RV1-RV4 have zero remaining
errors. Full list in `hardware/KiCad/MeetingHub-4-v1/DRC.rpt` (local,
gitignored, regenerate with the same `pcbnew.WriteDRCReport` approach
after rerouting).

## RV1-RV4 potentiometer body change (2026-08-07)

- **RV1-RV4 switched to a compact/square body**: Alps RK09L1240A12 (LCSC
  C380211, 881 in stock), replacing the wide RK09712200HA (29.6x9.5mm)
  they shared with RV5. New body is 14.5x17.9mm, much closer to square.
  RV5 (master volume, front panel, horizontal) was intentionally left
  unchanged on RK09712200HA — only RV1-RV4 were in scope.
- New footprint `Potentiometer_Alps_RK09L_Double_Vertical` added to the
  project-local library. It's a copy of KiCad's own standard
  `Potentiometer_THT.pretty` footprint of the same name (already
  vetted, matches the Alps RK09L datasheet), with one change: the 2
  "MP" mechanical-only pads from the official footprint were dropped.
  One of them landed 0.13mm from an existing track on this board — a
  real clearance conflict — and since MP pads carry no signal (pure
  mechanical support, commonly left unpopulated), removing them was
  lower-risk than moving the track or the component. The 6 signal pads
  keep the exact same size, drill, and position as the pads they
  replace, so all existing routing to RV1-RV4 was unaffected.
- Net-to-pad mapping carried over directly (pad N → pad N): both the
  old RK097 and new RK09L footprints use the identical KiCad-authored
  2.5mm/3x2 pad grid and numbering (pads 2 and 5 are the wiper of each
  gang), confirmed against the actual pad positions in both library
  files before mapping, not assumed from naming alone.
- Checked for physical collisions after the swap: initial generic
  bounding-box comparison flagged apparent overlaps with C12/C13/C14/
  C18 and between RV2/RV3, but re-checking with the real F.CrtYd
  courtyard rectangles (the bbox check also counts silkscreen
  reference/value text, which overstates the footprint) showed no
  actual courtyard overlap in any case — false alarms.
- Applied to `MeetingHub-4-v1.kicad_pcb` (same position/rotation, nets
  preserved) and `MIXER.kicad_sch` (Footprint property updated for
  RV1-RV4; RV5's Footprint property was also corrected to match what's
  actually on the board, `Potentiometer_Alps_RK097_Dual_Horizontal`,
  fixing the last of the schematic/PCB staleness noted in the SW1-SW5
  entry below).
- BOM-MeetingHub-4-v1.csv, BOM-PCBA-MeetingHub-4-v1.csv, and
  BOM-003-SourcingLinks.md updated accordingly.
- **Not verified**: whether the existing "eixo chato 6mm" knobs
  (bought for RK09712200HA's shaft) fit RK09L1240A12's shaft — same
  family, but shaft type/diameter wasn't cross-checked against a
  datasheet. Also, as with the SW1-SW5 change, DRC/ERC could not be
  re-run via `kicad-cli` (no `drc`/`erc` subcommand in this KiCad
  7.0.11 build) — verified via `pcbnew` Python (pad positions/nets,
  track-proximity check within 1.2mm of every pad) and clean
  `kicad-cli sch export pdf` / `pcb export svg` runs instead. Open in
  the KiCad GUI and run DRC/ERC there before fabrication.

## SW1-SW5 switch standardization (2026-08-07)

- **SW1-SW5 unified onto one part**: SHOU HAN TS665ZJ (LCSC C557599), a
  THT right-angle tactile switch with mounting bracket, SPST, 6.2x7.5x5mm,
  71,560 in stock. Replaces both prior parts — SW1's Omron B3F-4005
  (C397283) and SW2-SW5's CW Industries GPTS203211B, which was
  CONSIGNED (not on LCSC, had to be bought separately from DigiKey).
  That consignment requirement is now gone.
- New custom footprint `SW_SHOUHAN_TS665ZJ`, added to a new project-local
  library (`hardware/KiCad/MeetingHub-4-v1/MeetingHub-4.pretty/` +
  `fp-lib-table`, since the project previously relied only on KiCad's
  global standard libraries). Geometry (pad pitch, drill, body outline)
  was taken directly from LCSC's own EasyEDA source data for C557599,
  not estimated — but not yet cross-checked against a physical unit or
  a manufacturer datasheet PDF, and has no 3D model yet.
- 4 physical THT pads (2 legs per pole, same "duplicate pad number per
  node" pattern already used by SW1's previous `SW_PUSH-12mm`
  footprint), so both legs of each pole are tied to the same net.
- Applied to `MeetingHub-4-v1.kicad_pcb` (all 5 footprint instances
  swapped in place — same position, rotation, and net assignments
  preserved) and to `MICSW.kicad_sch` (Footprint property updated,
  fixing the schematic/PCB staleness on this component; RV1-RV5 remains
  stale per the note above).
- BOM-MeetingHub-4-v1.csv, BOM-PCBA-MeetingHub-4-v1.csv, and
  BOM-003-SourcingLinks.md updated accordingly.
- **Not done as part of this change**: the PCBWay PCBA quote in
  `production/Suppliers/` was based on the old SW1/SW2-5 parts and is
  now stale for those 5 line items — re-verify with PCBWay before
  ordering. DRC/ERC could not be re-run via `kicad-cli` in this
  environment (this KiCad 7.0.11 CLI build has no `drc`/`erc`
  subcommand); verification here was done via `pcbnew` Python
  (footprint load, position, net-by-net pad check) and a clean
  `kicad-cli sch export pdf` — open in the KiCad GUI and run DRC/ERC
  there before fabrication.

## v1.0 (post-freeze rework, 2026-08-06) — No enclosure, all direct-solder

Reversed the previous rework's enclosure decision: no MDF box, no
panel — the bare PCB is the final product, resting on 4 rubber feet.
See [BOM-003-SourcingLinks](hardware/BOM/BOM-003-SourcingLinks.md) §2
for the full history.

- **RV1-RV5 reverted to direct-solder** Alps RK097 potentiometers
  (were 6-pin JST-XH headers wired to an off-board panel pot).
- **SW1-SW5 became direct-solder switches** — SW1 a 12mm THT
  pushbutton (`SW_PUSH-12mm`), SW2-SW5 a real SPST slide switch (CW
  Industries GPTS203211B, LCSC C3314371). These were off-board via JST
  even in the original v1.0 design, so this is new work, not a revert.
- **Board size reverted to 265.1x160.1mm** (recovered from git history,
  pre-dating the size-reduction commit) to fit the RK097 bodies
  directly. The 3 THT→SMD footprint changes (C1/C4/C21, D1) from the
  previous rework were re-applied on top — that fix doesn't depend on
  enclosure/board-size decisions, still zero real THT stock for those 2
  parts at any supplier.
- Implemented via a `pcbnew` script (footprint swap matched net-by-net
  on pad number), 2 local placement/routing conflicts resolved (SW1
  shifted 3mm to clear a courtyard overlap with SW2; C4's GND via
  rerouted around 3 existing bus traces in the mixer grid). Re-verified
  3 times via `pcbnew.WriteDRCReport`, fresh board load each time: 0
  unconnected pads, 0 dangling tracks, 0 courtyard/clearance errors.
- Gerbers, drill, and component position file regenerated.
  `mechanical/` (MDF box plan, PDF, 3D-printed case draft) is now
  obsolete, kept in the repo for history.

## v1.0 (post-freeze rework, 2026-08-05) — Assembly-ready

Driven by preparing the real JLCPCB/PCBWay assembly order — see
[BOM-003-SourcingLinks](hardware/BOM/BOM-003-SourcingLinks.md) for full
detail and sourcing links per component.

- **Board resized**: 265.1x160.1mm → 160.1x108.96mm, rounded corners.
- **RV1-RV5 moved off-board**: converted from direct-solder Alps RK097
  potentiometers to 6-pin JST-XH headers (RK097 body was the single
  largest space consumer on the old layout, ~150mm of board width for
  5 units). RV5 uses a horizontal-mount header variant and moved to the
  front row, next to SW1.
- **3 footprints changed THT → SMD**: C1/C4/C21 (100nF ceramic) and D1
  (TVS diode) — no THT stock exists for either at any supplier
  (confirmed by live catalog search, not just a JLCPCB gap). Implemented
  via a `pcbnew` script: footprint swapped, connectivity to the inner
  GND/+5V_AUDIO planes restored with added vias (THT holes provided this
  for free; SMD pads don't), zones refilled, re-verified 0 unconnected
  pads / 0 dangling tracks by DRC.
- **J2-J6 (TRRS jack) verified, no PCB change needed**: the footprint
  was already hybrid THT+SMD. Compared the matched LCSC part's real
  manufacturer datasheet dimensions against the footprint directly —
  mechanical hole spacing and SMD pad pitch both match exactly.
- Gerbers and drill regenerated (now includes F/B.Paste layers for the
  SMD stencil), all 19 assembly BOM lines resolved to a confirmed,
  in-stock part.

## v1.0 — Hardware complete (manufacturing-ready)

### Requirements and architecture definition
- Requirements specification (ERS-001) and hardware architecture document (HAD-001).
- Electrical block diagram (SCH-001) and schematic design plan (SCH-002).
- Detailed electrical design by block: power supply (SCH-003), TRRS interface (SCH-004), audio mixer (SCH-005), headphone amplifier (SCH-006), microphone switching (SCH-007), grounding and noise control (SCH-008), KiCad implementation plan (SCH-009).
- Architecture reviews (DR-001, DR-002) before schematic implementation.

### Schematic
- Complete schematic implemented across 5 sheets (POWER, TRRS_INPUTS, AUDIO_MIXER, HEADPHONE_AMP, MIC_SWITCHING) with footprints assigned.
- Implementation review (DR-003), with fidelity corrections against the original electrical design.
- Schematic frozen as v1.0 (netlist and PDF generated).

### PCB layout
- Complete layout guide (PCB-001), covering mechanical placement, zoning, ground plane, routing, DRC, and manufacturing preparation.
- Placement of all 66 components with real physical constraints (front/rear/top panels).
- Complete routing via Freerouting (autorouter), with manual trace-width adjustments for the power nets.
- Mounting holes for the enclosure.
- Ground plane, and later migration to a **4-layer board** with dedicated internal GND and +5V_AUDIO planes, eliminating a structural grounding connectivity problem that persisted across two rounds of 2-layer re-layout.
- Final validation: 0 unconnected pads, 0 DRC errors (confirmed via an actual DRC report), no silkscreen overlaps, 4-layer gerbers exported and validated.

### Documentation and licensing
- Professional reorganization of all project documentation.
- Commercial usage license with royalty ([LICENSE.md](LICENSE.md)).
- International patent registration guide ([docs/Legal/PATENT-GUIDE.md](docs/Legal/PATENT-GUIDE.md)).

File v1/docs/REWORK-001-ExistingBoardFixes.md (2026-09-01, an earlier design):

# REWORK-001 — Correção manual das placas já fabricadas

Versão: 1.1 · Data: 2026-08-28
Aplica-se às 5 placas do lote JLCPCB `W2026080810364558` (gerbers v10.0).

**Estado do projeto que corresponde à placa física = commit `b86a034`.**
O HEAD atual (`eb61fb6`) já contém as correções desta sessão (esquemático + PCB
pré-preparado + footprint PS-22F03 + BOMs). Todas as coordenadas de furo citadas
aqui foram tiradas de `b86a034` (a placa que você tem na mão).

---

## 1. Resumo

A análise do projeto identificou **3 erros de projeto** (confirmados no
esquemático **e** na netlist do PCB — por isso as 5 placas se comportam igual;
não é defeito de fabricação):

| # | Sintoma relatado | Causa | Onde se corrige |
|---|---|---|---|
| 1 | Potenciômetro aumenta para a esquerda, diminui para a direita | Terminais externos (1↔3 / 4↔6) trocados em RV1–RV5 | Parte B |
| 2 | No mínimo ainda sai áudio | Mesma troca: pot log ligado ao contrário → só corta no fim do curso; + VBIAS sem buffer | Parte B (+ Parte C opcional) |
| 3 | Microfone não funciona em nenhum PC, só um ruído ao plugar o P2 | Bobina e contatos dos relés K1–K4 trocados (a linha de mic do notebook está ligada na bobina; o acionamento está no contato) | Parte A |

**Observação adicional (não é erro de ligação, mas afeta o uso):** SW1–SW5
são botões **momentâneos** (SHOU HAN TS665ZJ). Ver Parte D.

### O que já foi alterado no repositório

O **esquemático** já foi corrigido nos itens 1 e 3:

- `hardware/KiCad/MeetingHub-4-v1/MIXER.kicad_sch` — RV1–RV5: sinal e VBIAS
  trocados de terminal (netlist conferida: pino 1/4 = VBIAS, pino 3/6 = sinal,
  pino 2/5 = cursor).
- `hardware/KiCad/MeetingHub-4-v1/MICSW.kicad_sch` — K1–K4: bobina nos pinos 2 e 9
  (2 = GND, 9 = acionamento), COM nos pinos 5/6 (mic do headset), `NBx_MIC` no
  pino 10 (contato NA), pino 1 (NF) livre; diodos D2–D5 reorientados como
  roda-livre correto (catodo no lado do acionamento).

O **layout do PCB (`MeetingHub-4-v1.kicad_pcb`) NÃO foi re-roteado** — fazer isso à
mão sem o KiCad aberto é arriscado. Para gerar gerbers corrigidos e um novo lote:

1. Abrir o projeto no KiCad, rodar **ERC** (deve passar).
2. No Pcbnew: **Tools → Update PCB from Schematic (F8)**.
3. Re-rotear as ligações que ficarão vermelhas (pinos externos de RV1–RV5;
   pinos 1/9/10 de K1–K4; D2–D5). O restante da placa não muda.
4. Rodar DRC, refazer preenchimento de zonas, regenerar gerbers.

Enquanto isso, este documento descreve como consertar **na mão** as placas que
já chegaram, para validar as correções antes de encomendar o novo lote.

---

## 1b. Caminho mínimo — só "microfone + sem segurar botão"

Se por agora você só quer o **mic funcionando** e **acabar com o "segurar
botão"** (deixando os potenciômetros / VBIAS para depois):

### Passo 1 — Microfone (Parte A)

Retrabalhar os relés **K1–K4** + diodos **D2–D5**. Por canal:

- levantar os pinos **1, 9, 10** do relé;
- jumper **pino 9 → furo 1**; jumper **pino 10 → furo 9**; pino 1 isolado;
- **D2–D5**: para o teste, o mais simples é **remover o diodo** (o relé funciona
  sem ele numa bancada). Para o definitivo, invertê-lo (faixa para o lado
  oposto ao relé).

Comece só por **K1 + D2**, teste o notebook 1, depois faça K2/K3/K4.

### Passo 2 — Tirar o MUTE (SW1)

Você autorizou tirar o mudo. Na placa, **SW1 fica em série com a linha do
microfone**. Solução: **pingo de solda ligando os 2 furos do SW1 que têm
trilha** — `HEADSET_MIC` (furo em ~(73,15 , 214,5)) com o furo que vai aos
relés (~(71,9 , 212,0)). O microfone passa a passar sempre. O "mudo" passa a
ser *nenhuma seletora ligada*.

### Passo 3 — Trocar SW2–SW5 por botão com trava

Para cada uma (SW2, SW3, SW4, SW5):

1. Desssolde a chave tátil momentânea.
2. Ligue um **botão self-locking (push-on/push-off)** com **2 fios**:
   - um fio → o furo do SW que tem a trilha de **+5V_AUDIO**
     (SW2 ~(96,8 , 214,5) · SW3 ~(109,5 , 214,5) · SW4 ~(123,8 , 214,5) ·
     SW5 ~(135,9 , 214,5));
   - outro fio → o furo com a trilha que vai ao **relé**
     (SW2 ~(95,6 , 212,0) · SW3 ~(108,3 , 212,0) · SW4 ~(122,5 , 212,0) ·
     SW5 ~(134,6 , 212,0)).
   - Confirme os furos com o multímetro (um tem +5 V; o outro tem continuidade
     até a bobina do relé correspondente **depois** do Passo 1).
3. Travado = aquele notebook selecionado. Solto = não. Todos soltos = mudo.

### Peça a comprar

| Qtd | Item | Onde |
|---|---|---|
| 4 (+1 reserva) | **Chave push com trava / "self-locking" / trava-destrava** — **PS-22F03 / A03** (6 pinos; usa COM + NO de um polo = 2 fios). É a mesma peça do respin. | LCSC **C2848947** (ou HOOYA **C19190927**); ou "chave A03 self-locking" em qualquer loja |
| — | *Alternativa mais fácil de montar:* **botão de painel com trava, 2 terminais** (self-locking 8–12 mm, tipo PBS-11B / R13-507). 2 lugs, monta no painel, 2 fios até a placa. | loja local / AliExpress |

**Alternativa com 1 peça só:** uma **chave rotativa 1 polo × 5 posições**
(OFF / NB1 / NB2 / NB3 / NB4). Comum → +5 V; cada posição → o furo "relé" de
SW2..SW5; OFF já é o mudo. Ver **Parte D.3**. Remove SW2–SW5 e ainda dá a ponte
no SW1.

**Seleção exclusiva com botões (comportamento de KVM — aperto um, o outro
desarma sozinho):** os botões continuam momentâneos + uma placa auxiliar
CD4043 + matriz de diodos faz a trava eletrônica. Esse caminho **substitui**
a Parte A + Parte D: ver **`docs/Architecture/SCH-010-OneHotMicSelector.md`**
(esquema completo, lista de materiais, ligação furo a furo).

> Detalhes completos: **Parte A** (relés) e **Parte D** (chaves) abaixo.

---

## 2. Ferramentas e materiais

- Ferro de solda ponta fina + solda fina (0,5–0,8 mm) + fluxo.
- Malha dessoldadora (pavio) e/ou sugador.
- Fio esmaltado/wire-wrap fino (AWG 30) ou fio flexível fino isolado — uns 60 cm.
- Estilete / bisturi (só se optar pelo método de corte de trilha — ver B.4).
- Multímetro com bipe de continuidade **e** medição de tensão DC.
- Lupa / microscópio, boa iluminação.
- Álcool isopropílico para limpar o fluxo no final.
- (Opcional Parte C) 1 capacitor eletrolítico 100–470 µF / ≥10 V por placa.

**Antes de começar:** faça a Parte A e a Parte B em **uma placa só**, teste tudo
(seção 6), e só depois replique nas outras 4.

---

## 3. Como identificar os pinos

- **Potenciômetros RV1–RV4** (corpo quadrado, vertical): 6 pinos em 2 colunas de
  3. O **pino 1 é o furo quadrado**. Na mesma coluna do pino 1, descendo:
  1 → 2 → 3. Na outra coluna: 4 → 5 → 6.
  - Coluna do pino 1: **1** (sinal L), **2** (cursor L), **3** (VBIAS).
  - Outra coluna: **4** (sinal R), **5** (cursor R), **6** (VBIAS).
- **RV5** (master, corpo largo, deitado, no painel frontal): mesma lógica, 2
  fileiras de 3. Pino **1** é o furo levemente quadrado; **1/2/3** numa fileira,
  **4/5/6** na outra; **2 e 5** são os cursores (centro).
- **Relés K1–K4** (Omron G5V-1): 6 pinos.
  ```
     [1]  ......  [10]        <- [1] é o furo quadrado
     [2]  ......  [ 9]        <- pinos 2 e 9 = BOBINA
     [5] ........ [ 6]        <- pinos 5/6 = COM (comum), afastados
  ```
  Contatos: **1** = NF (normalmente fechado), **10** = NA (normalmente aberto),
  **5/6** = COM.
- **Diodos D2–D5** (1N4148, deitados, ~7,6 mm): a **faixa** marca o catodo.

---

## 4. PARTE A — Relés K1–K4 (conserta o microfone)

### A.1 O que está errado

| Pino do relé | Ligado hoje a | Deveria estar em |
|---|---|---|
| 2 (bobina) | GND | GND ✔ (não mexer) |
| 9 (bobina) | `NBx_MIC` (mic do notebook) | acionamento (+5V da chave "Select") |
| 1 (contato NF) | chave "Select" + diodo Dx | nada (livre) |
| 5/6 (COM) | mic do headset (após MUTE) | mic do headset ✔ (não mexer) |
| 10 (contato NA) | nada | `NBx_MIC` |
| Dx | catodo→GND, anodo→acionamento | catodo→acionamento, anodo→GND |

Resultado do erro: a bobina fica entre GND e a linha de mic do notebook (nunca
liga, e "curto-circuita" a polarização de mic do notebook com ~167 Ω); o mic do
headset fica preso ao contato NF → diodo → GND.

### A.2 Passo a passo (repetir para K1, K2, K3, K4)

Tabela de referência — a "rede" de cada furo (não muda; só levantamos os pinos):

| Relé | furo 1 = | furo 9 = | diodo |
|---|---|---|---|
| K1 | acionamento NB1 (vai p/ SW2 e D2) | NB1_MIC | D2 |
| K2 | acionamento NB2 (SW3, D3) | NB2_MIC | D3 |
| K3 | acionamento NB3 (SW4, D4) | NB3_MIC | D4 |
| K4 | acionamento NB4 (SW5, D5) | NB4_MIC | D5 |

**Passo 1 — Levantar 3 pinos do relé.**
Aqueça e puxe delicadamente para cima ~1,5 mm os pinos **1, 9 e 10**, até que
saiam do furo e não encostem mais no anel de cobre. **Não** mexa nos pinos 2, 5,
6 nem nas abas metálicas de fixação — o relé continua preso.

**Passo 2 — Dois jumpers.**
Com fio fino isolado:
- **pino 9 (levantado) → furo 1** (o furo que sobrou vazio, ainda ligado ao
  acionamento). Agora a bobina recebe o +5V da chave.
- **pino 10 (levantado) → furo 9** (furo vazio, ainda ligado a `NBx_MIC`). Agora
  o contato NA leva o mic ao notebook quando o relé fecha.

**Passo 3 — Isolar o pino 1.**
O pino 1 (contato NF) fica **sem ligação**. Deixe-o levantado e, de preferência,
cubra a ponta com um pedacinho de termo-retrátil ou fita Kapton para não
encostar em nada.

**Passo 4 — Inverter o diodo Dx.**
Dessolde o diodo (D2 para K1, D3 para K2, etc.), gire **180°** e ressolde, de
forma que a **faixa (catodo) fique voltada para o lado oposto ao de hoje** — ou
seja, para o lado do pino da rede de acionamento (`Net-(Dx-A)`), e o anodo para
o lado do GND. Regra simples: hoje a faixa aponta para o relé; depois da
inversão ela aponta para **longe** do relé.

**Passo 5 — Conferência (multímetro, placa sem alimentação):**
- Continuidade **pino 9 do relé ↔ pino 2 da chave "Select" correspondente**: deve
  apitar.
- Continuidade **pino 10 do relé ↔ conector TRRS do notebook correspondente,
  contato do cabo (Sleeve/mic)**: deve apitar.
- Continuidade **pino 1 do relé ↔ qualquer coisa**: **não** deve apitar (isolado).
- Continuidade **pino 2 do relé ↔ GND**: deve apitar.
- Diodo Dx: no modo diodo, ponta vermelha no lado do acionamento (faixa) e preta
  no GND → deve indicar ~0,55–0,7 V (conduz); invertido → aberto.

---

## 5. PARTE B — Potenciômetros RV1–RV5 (conserta direção e "não zera")

### B.1 O que está errado

Cada gang do pot é um divisor: **entrada de sinal → trilha → VBIAS**, cursor →
saída. Hoje a entrada de sinal está no terminal que deveria ir ao VBIAS e
vice-versa. Isso (a) inverte o sentido e (b), como o pot é logarítmico ligado ao
contrário, faz o volume ficar quase no máximo em quase todo o curso e só cair no
finzinho.

Correção: **trocar os terminais 1↔3 e 4↔6**. O cursor (2 e 5) não muda.

### B.2 Redes de cada furo (não mudam; só levantamos os pinos)

| Pot | furo 1 | furo 3 | furo 4 | furo 6 |
|---|---|---|---|---|
| RV1 | sinal NB1-L (C5) | VBIAS | sinal NB1-R (C6) | VBIAS |
| RV2 | sinal NB2-L (C7) | VBIAS | sinal NB2-R (C8) | VBIAS |
| RV3 | sinal NB3-L (C9) | VBIAS | sinal NB3-R (C10) | VBIAS |
| RV4 | sinal NB4-L (C11) | VBIAS | sinal NB4-R (C12) | VBIAS |
| RV5 | sinal mix L (C13) | VBIAS | sinal mix R (C14) | VBIAS |

### B.3 Passo a passo (método recomendado — sem cortar trilha)

Repetir para RV1, RV2, RV3, RV4 e RV5.

**Passo 1 — Levantar 4 pinos.**
Aqueça e puxe para cima ~1,5 mm os pinos **1, 3, 4 e 6**. Deixe **2 e 5**
(cursores) e as abas de fixação soldados — o pot continua no lugar e alinhado.

**Passo 2 — Quatro jumpers cruzados** (fio fino; são só ~5 mm cada):
- pino **1** (levantado) → **furo 3**
- pino **3** (levantado) → **furo 1**
- pino **4** (levantado) → **furo 6**
- pino **6** (levantado) → **furo 4**

Pronto: o terminal 1 do pot passa a ver VBIAS, o terminal 3 passa a ver o sinal;
idem 4/6. Nenhuma trilha foi cortada, o barramento de VBIAS que liga RV1–RV4
continua intacto.

**Passo 3 — Conferência (multímetro):**
- Continuidade **terminal 1 do pot ↔ terminal 3 (antigo furo de VBIAS)** →
  agora o terminal 1 deve ter continuidade com o VBIAS / com o furo 3 de outro
  pot. Terminal 3 do pot deve ter continuidade com o capacitor de entrada
  (C5/C7/…).
- Com a placa ligada e um PC tocando música: girando o knob **no sentido
  horário o volume deve AUMENTAR**; no fim do curso anti-horário deve **zerar**.

### B.4 Método alternativo (se preferir não levantar pinos)

Para cada gang: cortar a trilha no furo 1 e no furo 3, e soldar dois jumpers
"cruzados" (furo 1 → ponta da trilha do furo 3; furo 3 → ponta da trilha do furo
1). Idem 4/6. É mais invasivo e exige recompor o barramento de VBIAS em RV2/RV3
(que passa "de dentro"); por isso o método B.3 (levantar pinos) é preferível.

---

## 6. PARTE C — VBIAS (opcional, recomendado)

O VBIAS é gerado só por um divisor 10k/10k + C3 de 10 µF, sem buffer. Com os
pots no mínimo, o sinal de todas as fontes é injetado nesse nó e vaza um
pouquinho para a saída. Se, **depois da Parte B**, ainda houver um resíduo baixo
audível no mínimo:

- **Solução rápida:** soldar um eletrolítico de **100–470 µF / ≥10 V** em
  paralelo com **C3** (perto do divisor R1/R2, região superior-esquerda do
  bloco do mixer). Polaridade: **+ no lado do VBIAS (pino 1 de C3)**, **− no GND
  (pino 2 de C3)**.
- **Solução boa (respin):** bufferizar o VBIAS com um seguidor de tensão
  (usar meio CI extra) e/ou baixar o divisor para 2×2,2 kΩ.

---

## 7. PARTE D — Seleção e MUTE (tirar o "segurar botão")

### D.1 Por que hoje tem que segurar

SW1–SW5 são táteis **momentâneos** (fecham só enquanto pressionados) e estão
ligados "direto", sem trava:

- **SW1 (MUTE)** fica em **série** com a linha do microfone → normalmente
  **aberto** → o mic só passa enquanto você aperta ("aperte para falar", ao
  contrário de um mute).
- **SW2–SW5 (Select)** alimentam a bobina do relé direto → o relé só fica ligado
  enquanto o botão está apertado.

Isso é um 4º defeito de projeto. Para **validar o rework** (Partes A/B) não
precisa resolver — é só segurar os botões durante o teste. Mas se você quer usar
a placa de verdade, escolha uma das opções abaixo.

### D.2 Opção mínima — sem peça nova (bom p/ teste e uso de 1 PC fixo)

- **Ponte permanente nos 2 polos do SW1** (uma gota de solda ou um pedacinho de
  fio entre `SW1 furo 1` e `SW1 furo 2`) → o microfone passa sempre.
- **Ponte permanente nos 2 polos de UM dos "Select"** (ex.: SW2) → aquele
  notebook fica selecionado direto.
- Perde o mute e a troca de PC, mas zero peça e zero "segurar".

### D.3 Opção recomendada — 1 chave rotativa (seleção + mute juntos)

Uma **chave rotativa 1 polo, 5 posições** (não-curto-circuitante / "break before
make"), com fios volantes:

| Posição | Ligar o terminal da posição a | Efeito |
|---|---|---|
| 1 — OFF | (nada) | todos os relés desligados → **mic mudo** |
| 2 — NB1 | `SW2 furo pad-2` (rede do acionamento de K1) | mic → notebook 1 |
| 3 — NB2 | `SW3 furo pad-2` | mic → notebook 2 |
| 4 — NB3 | `SW4 furo pad-2` | mic → notebook 3 |
| 5 — NB4 | `SW5 furo pad-2` | mic → notebook 4 |

- **Comum da rotativa** → **+5 V**: o ponto mais fácil é `SW2 furo pad-1`
  (já é `+5V_AUDIO`), ou o test point **TP1**.
- Como a posição OFF já é o mute, **dê a ponte permanente no SW1** (D.2) e não
  precisa de botão de mute separado.
- SW2–SW5 podem **sair da placa** ou **ficar no lugar sem uso** (são
  normalmente abertos; não atrapalham — no máximo funcionam como um "override"
  momentâneo em paralelo com a rotativa).
- A rotativa força **um PC de cada vez** mecanicamente — resolve também a
  falta de intertravamento do projeto original.

Furos de referência (vistos por cima, fileira frontal, y ≈ 212–214,5):
`SW1` à esquerda, depois `RV5`, depois `SW2, SW3, SW4, SW5`. O `furo pad-2` de
cada "Select" é o de **trás** (mais longe da borda), que carrega a trilha
`Net-(Dx-A)` para o relé.

### D.4 Opção alternativa — botões com retenção

Trocar SW1–SW5 por botões **push-on/push-off** (com trava). Provavelmente muda o
footprint (o TS665ZJ é só momentâneo), então é mais trabalho de adaptar furos.
E os 4 "Select" continuam sem intertravamento: se travar 2, dois PCs recebem o
mic (erro do usuário — já assumido no SCH-007). Por isso a rotativa (D.3) é
melhor.

> Para o respin, a recomendação é: **rotativa 1P5T para o Select + 1 botão
> latching só para o MUTE** (ou manter só a rotativa com posição OFF).

---

## 8. Teste de verificação (após reworkar 1 placa)

Alimente pela USB-C. Com um multímetro:

1. **VBIAS** ≈ 2,4–2,6 V (medir no pino 1 de C3 ou no terminal 1 de qualquer RV).
2. **+5V_AUDIO** ≈ 5 V no test point TP1.

Áudio (1 notebook por vez, com fone no J6):

3. Toque música no notebook 1 (cabo TRRS em J1... *no J do notebook 1*).
   Gire **RV1 no horário → volume sobe**; anti-horário até o fim → **silêncio
   total**. Repita RV2–RV4 e o master RV5.
4. Duas ou mais fontes ao mesmo tempo: devem somar sem uma "puxar" a outra.

Microfone:

5. Fone com microfone no J6. Selecione o notebook 1 — **segurando SW1 + SW2**,
   ou (se já fez a Parte D) pela ponte do SW1 + rotativa na posição NB1.
   Fale: o notebook 1 deve captar o microfone normalmente (testar em
   Gravador de Voz / Meet).
6. Troque para o notebook 2 (segurar SW3 / rotativa em NB2). Etc.
7. Nada selecionado (rotativa em OFF, ou nenhum "Select" apertado): nenhum
   notebook capta (mudo).
8. Confirme que o notebook **reconhece o headset** (aparece microfone externo) —
   isso valida que a linha de mic não está mais carregada pela bobina.

Se 3, 5 e 7 passarem, as três correções estão boas → replicar nas outras 4
placas e seguir para o respin do PCB.

---

## 9. Checklist por placa

```
Placa nº ____

RELÉS
[ ] K1: pinos 1,9,10 levantados · jumper 9→furo1 · jumper 10→furo9 · pino1 isolado · D2 invertido
[ ] K2: idem · D3 invertido
[ ] K3: idem · D4 invertido
[ ] K4: idem · D5 invertido
[ ] continuidade conferida (A.2 passo 5) nos 4 relés

POTENCIÔMETROS
[ ] RV1: pinos 1,3,4,6 levantados · jumpers 1↔3 e 4↔6
[ ] RV2: idem
[ ] RV3: idem
[ ] RV4: idem
[ ] RV5: idem
[ ] direção conferida (horário = mais alto) nos 5

SELEÇÃO / MUTE (Parte D — escolher uma)
[ ] D.2 pontes em SW1 + um Select   (uso fixo de 1 PC)
[ ] D.3 chave rotativa 1P5T: comum→+5V, pos NB1..NB4→SW2..SW5 pad-2, ponte no SW1
[ ] (ou deixar momentâneo e segurar botão só no teste)

OPCIONAL
[ ] C3 reforçado com eletrolítico ___ µF

TESTE
[ ] VBIAS ~2,5 V   [ ] +5V TP1
[ ] RV1..RV5 sobem no horário e zeram no fim
[ ] mic NB1..NB4 OK (segurando SW1 + Select)
[ ] headset reconhecido pelo notebook
[ ] limpeza do fluxo
```

---

## 10. Depois de validar

1. No KiCad: ERC → Update PCB from Schematic → re-rotear RV1–RV5 (pinos externos)
   e K1–K4 (pinos 1/9/10) e D2–D5 → DRC → zonas → gerbers.
2. Avaliar no respin: chave rotativa 1P5T (OFF/NB1–NB4) para a seleção de mic
   + botão latching (ou a própria posição OFF) para o MUTE; buffer de VBIAS.
3. Encomendar novo lote e descartar/aposentar as placas reworkadas (ou mantê-las
   como protótipos).

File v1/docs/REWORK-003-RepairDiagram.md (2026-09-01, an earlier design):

# REWORK-003 — Diagrama do reparo da placa fabricada

Versão: 1.0 · Data: 2026-08-28
Versão visual (artefato HTML): publicada separadamente.
Detalhe em texto: `REWORK-001` (rework à mão) e `SCH-010` (lógica CD4043).

**Placa física = commit `b86a034`.** Coordenadas em mm, sistema do `.kicad_pcb`.
Faça **o canal K1 do começo ao fim**, teste o notebook 1, e só então replique.

Legenda dos diagramas:
- **levantar** = dessoldar e puxar o pino ~1,5 mm para fora do furo
- **fio novo** = jumper de fio fino (AWG 30) que você adiciona
- **cortar** = trilha cortada com estilete no pad
- **deixar** = não mexer; conferir com multímetro

---

## 00 · Ordem de trabalho

```mermaid
flowchart TD
  F1["Fase 1 · ponte no SW1 (remove o MUTE)"]
  F23["Fase 2+3 · reparar K1: +5V na bobina, D2 invertido, pino 10 -> furo 9"]
  F5["Fase 5 · montar a plaquinha CD4043 + matriz + drivers"]
  F4["Fase 4 · SW2: cortar pad 2, fio -> BTN1"]
  F6["Fase 6 · ligar a plaquinha: +5V, GND, BTN1, DRV1"]
  T{"Teste K1: aperta SW2 -> K1 clica? notebook 1 capta o mic?"}
  FIX["revisar Fases 3 / 5 / 6"]
  REP["repetir Fases 3+4+6 para K2, K3, K4"]
  F7["Fase 7 · potenciometros (opcional, depois)"]
  F1 --> F23 --> F5 --> F4 --> F6 --> T
  T -->|nao| FIX --> T
  T -->|sim| REP --> F7
```

**Ferramentas:** ferro ponta fina + solda 0,5 mm + fluxo · sugador/malha ·
fio AWG 30 · estilete · multímetro (continuidade + DC) · cola quente · lupa.

---

## 01 · Tirar o MUTE — ponte no SW1

```mermaid
flowchart LR
  J6["J6 headset (sleeve = mic)"]
  P1["SW1 pad 1 (73,15 ; 214,5) HEADSET_MIC"]
  P2["SW1 pad 2 (71,90 ; 212,0) -> COM dos reles"]
  COM["pinos 5 e 6 de K1 K2 K3 K4"]
  J6 --> P1
  P1 -. "fio / pingo de solda (ponte)" .-> P2
  P2 --> COM
```

Solde um fio curto (ou pingo de solda) unindo os 2 furos **com trilha** do SW1.
O corpo do SW1 pode ficar no lugar.

**Confere:** continuidade *sleeve do J6* ↔ *pino 5 de qualquer relé*.

---

## 02 · Barramento +5 V para as bobinas

Passe um fio de **+5 V** (de `SW2 pad 1` ≈ (96,8 ; 214,5), que é `+5V_AUDIO`,
ou de `TP1`) até a região dos relés. Ele será soldado no **pino 2** levantado
de K1–K4 na Fase 3.

---

## 03 · Reparar cada relé K1–K4 + diodo D2–D5

Pinos do G5V-1: `1 = NF` · `2 e 9 = bobina` · `5 e 6 = COM` · `10 = NA`.
Dn: D2→K1, D3→K2, D4→K3, D5→K4.

```mermaid
flowchart LR
  subgraph R["Rele Kn"]
    direction TB
    P1["pino 1 - NF"]
    P2["pino 2 - bobina"]
    P56["pinos 5+6 - COM"]
    P9["pino 9 - bobina"]
    P10["pino 10 - NA"]
  end
  P1  -->|LEVANTAR| A1["deixar solto, isolar a ponta"]
  P2  -->|LEVANTAR| A2["fio -> barramento +5 V (Fase 2)"]
  P56 --> A3["NAO MEXER - e HEADSET_MIC apos Fase 1"]
  P9  -->|LEVANTAR| A4["fio -> plaquinha, saida DRVn"]
  P10 -->|LEVANTAR| A5["jumper curto -> furo 9 (trilha NBx_MIC)"]
  D["Diodo Dn: entre pino 2 e 9, faixa (catodo) para o lado do pino 2 (+5 V)"]
```

1. Levantar pinos **1, 2, 9, 10**. Deixar 5 e 6 soldados + cola quente.
2. pino 2 → fio ao **+5 V** · pino 9 → fio à **plaquinha DRVn** ·
   pino 10 → **jumper para o furo 9** · pino 1 → isolado.
3. Diodo Dn em paralelo com a bobina (pinos 2–9), **faixa para o pino 2**.

**Confere:** pino 2 ↔ +5V · pino 9 ↔ fio da plaquinha ·
pino 10 ↔ sleeve do TRRS daquele notebook · pino 1 ↔ nada.

---

## 04 · Botões — reusar SW2–SW5

```mermaid
flowchart LR
  P1["SWn pad 1 (frente) +5V_AUDIO"]
  SW(["botao SWn"])
  P2["SWn pad 2 (tras) trilha Net-(Dx-A)"]
  OLD["ia para o rele Kn"]
  BTN["plaquinha - entrada BTNn"]
  P1 --- SW --- P2
  P2 -.->|"CORTAR a trilha no pad"| OLD
  P2 -->|"fio novo"| BTN
```

| Botão | pad 2 ≈ (x ; y) | Fio novo → | Comanda |
|---|---|---|---|
| SW2 | (95,56 ; 212,0) | `BTN1` | NB1 · K1 |
| SW3 | (108,3 ; 212,0) | `BTN2` | NB2 · K2 |
| SW4 | (122,5 ; 212,0) | `BTN3` | NB3 · K3 |
| SW5 | (134,6 ; 212,0) | `BTN4` | NB4 · K4 |

**Confere:** `SWn pad 2` ↔ relé: **não** apita mais; apertando SWn, pad 2 ↔ pad 1 apita.

---

## 05 · Montar a plaquinha (perfboard)

```mermaid
flowchart LR
  B1["BTN1"] --> MX
  B2["BTN2"] --> MX
  B3["BTN3"] --> MX
  B4["BTN4"] --> MX
  POR["power-on reset: 1uF + 100k + 4 diodos"] --> MX
  MX["matriz 16 diodos + 8 pull-down 100k"] --> U["CD4043 - 4 latches R/S"]
  U --> Q1["Q1"] --> M1["1k -> gate 2N7000, 100k p/ GND"] --> DRV1["DRV1 -> K1 pino 9"]
  U --> Q2["Q2"] --> M2["2N7000"] --> DRV2["DRV2 -> K2 pino 9"]
  U --> Q3["Q3"] --> M3["2N7000"] --> DRV3["DRV3 -> K3 pino 9"]
  U --> Q4["Q4"] --> M4["2N7000"] --> DRV4["DRV4 -> K4 pino 9"]
  U -. "opcional" .-> LED["Q -> 2k2 -> LED -> GND"]
```

**Matriz** (botão X → S do canal X + R dos outros 3):

| Aperta | SET | RESET |
|---|---|---|
| BTN1 | S1 | R2 · R3 · R4 |
| BTN2 | S2 | R1 · R3 · R4 |
| BTN3 | S3 | R1 · R2 · R4 |
| BTN4 | S4 | R1 · R2 · R3 |
| power-on | — | R1 · R2 · R3 · R4 |

**CD4043BE (DIP-16):** VDD=16(+5V) · VSS=8(GND) · ENABLE=5(+5V) · NC=13 ·
A: S1/R1/Q1 = 4/3/2 · B: S2/R2/Q2 = 6/7/9 · C: S3/R3/Q3 = 12/11/10 ·
D: S4/R4/Q4 = 14/15/1.

Passos: 100 nF no CI · 8×100k pull-down (S1–4, R1–4) · 16×1N4148 matriz ·
power-on (1µF+100k+4×1N4148 → R1–4) · 4× (Q→1k→gate 2N7000, gate→100k→GND,
dreno=DRVn, fonte=GND) · 100µF bulk · LEDs opcionais.

---

## 06 · Ligar a plaquinha à placa — 12 fios

| plaquinha | ponto na placa principal |
|---|---|
| +5V | `SW2 pad 1` (ou TP1) — mesmo fio da Fase 2 |
| GND | qualquer terra (blindagem do J1, furo de fixação) |
| BTN1..BTN4 | `SW2..SW5 pad 2` (trilha cortada) |
| DRV1..DRV4 | `K1..K4 pino 9` (levantado) |

---

## 07 · Potenciômetros (opcional, depois)

```mermaid
flowchart LR
  subgraph RV["RVn - 6 pinos"]
    direction TB
    A1["pino 1 - sinal (C)"]
    A2["pino 2 - cursor"]
    A3["pino 3 - VBIAS"]
    B4["pino 4 - sinal (C)"]
    B5["pino 5 - cursor"]
    B6["pino 6 - VBIAS"]
  end
  A1 -->|levantar| J1["jumper -> furo 3"]
  A3 -->|levantar| J3["jumper -> furo 1"]
  B4 -->|levantar| J4["jumper -> furo 6"]
  B6 -->|levantar| J6["jumper -> furo 4"]
  A2 --> K1["cursor: nao mexer"]
  B5 --> K2["cursor: nao mexer"]
```

RV1…RV5: levantar pinos 1, 3, 4, 6 e cruzar **1↔3** e **4↔6**. Sem cortar trilha.

---

## 08 · Teste

```mermaid
flowchart TD
  P["alimenta pela USB-C, fone com mic no J6"]
  M{"nenhum LED / rele clicado? NBx_MIC sem continuidade c/ headset?"}
  B2["aperta SW3 (NB2)"]
  C2{"K2 clica, LED2, notebook 2 capta o mic?"}
  B4["aperta SW5 (NB4)"]
  C4{"K2 solta, K4 clica, so o notebook 4 capta?"}
  OK["OK - replica em K1/K3, Fase 7 opcional"]
  FIX["revisar Fase 3 (rele/diodo) e Fase 5/6 (plaquinha/fios)"]
  P --> M
  M -->|sim| B2 --> C2
  M -->|nao| FIX
  C2 -->|sim| B4 --> C4
  C2 -->|nao| FIX
  C4 -->|sim| OK
  C4 -->|nao| FIX
```

---

## 09 · Compras

Só a plaquinha precisa de peça nova — ver `SCH-010 §4.1` para a tabela com
links LCSC (CD4043BE **C39537**, 2N7000 **C9114**, 1N4148 **C402212**,
100k **C1364475**, 1k **C120055**, 1µF **C2167638**, + genéricos de kit).
**Não** compra: relés, D2–D5, potenciômetros, botões (reusa SW2–SW5).

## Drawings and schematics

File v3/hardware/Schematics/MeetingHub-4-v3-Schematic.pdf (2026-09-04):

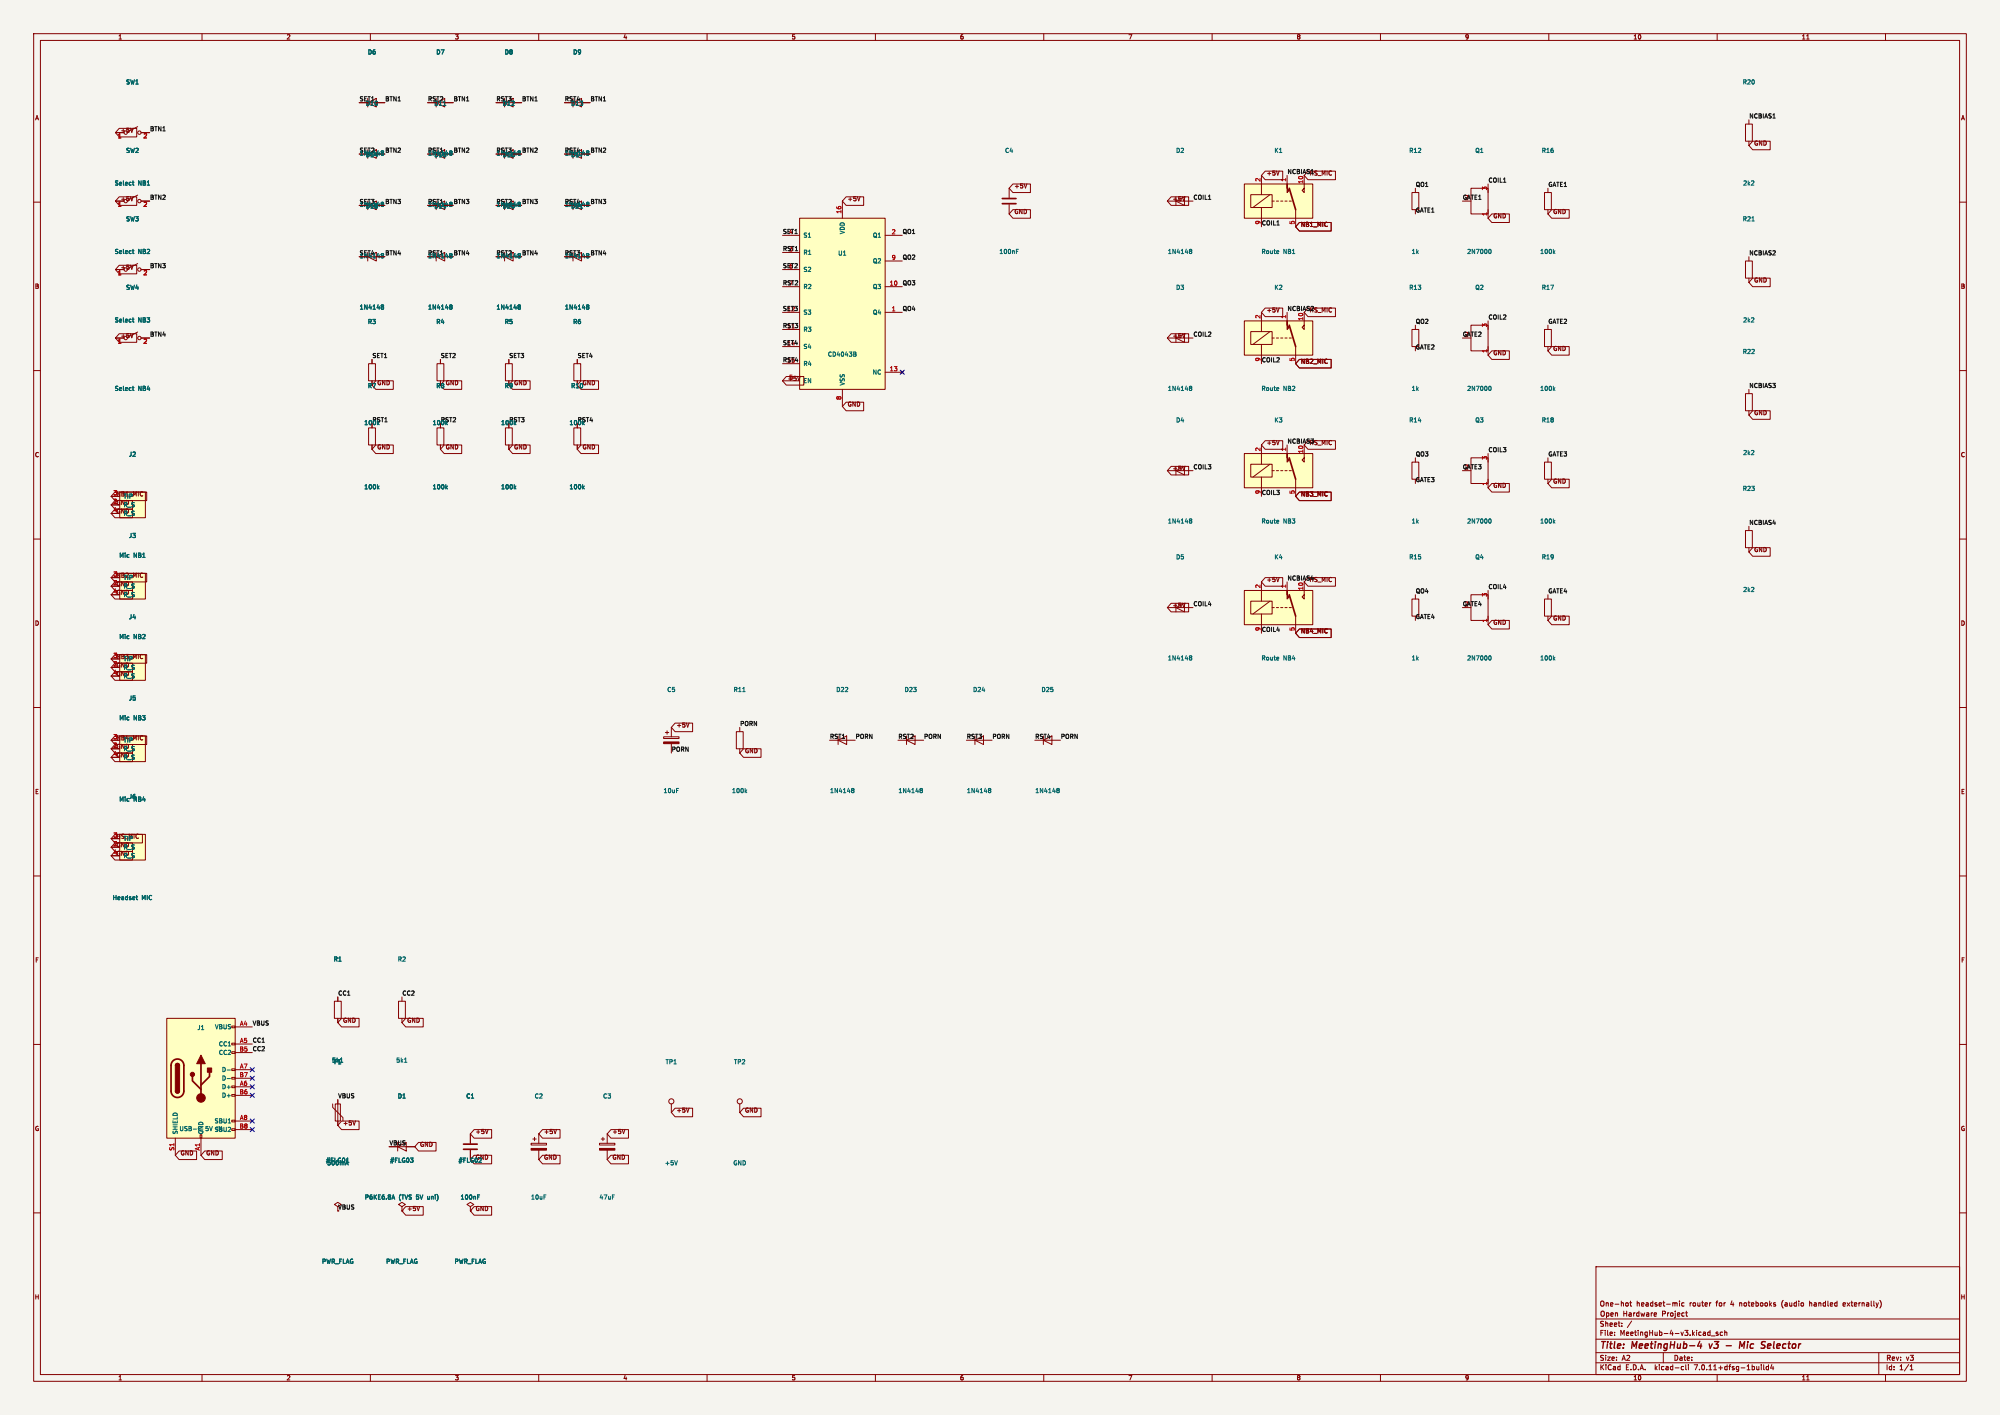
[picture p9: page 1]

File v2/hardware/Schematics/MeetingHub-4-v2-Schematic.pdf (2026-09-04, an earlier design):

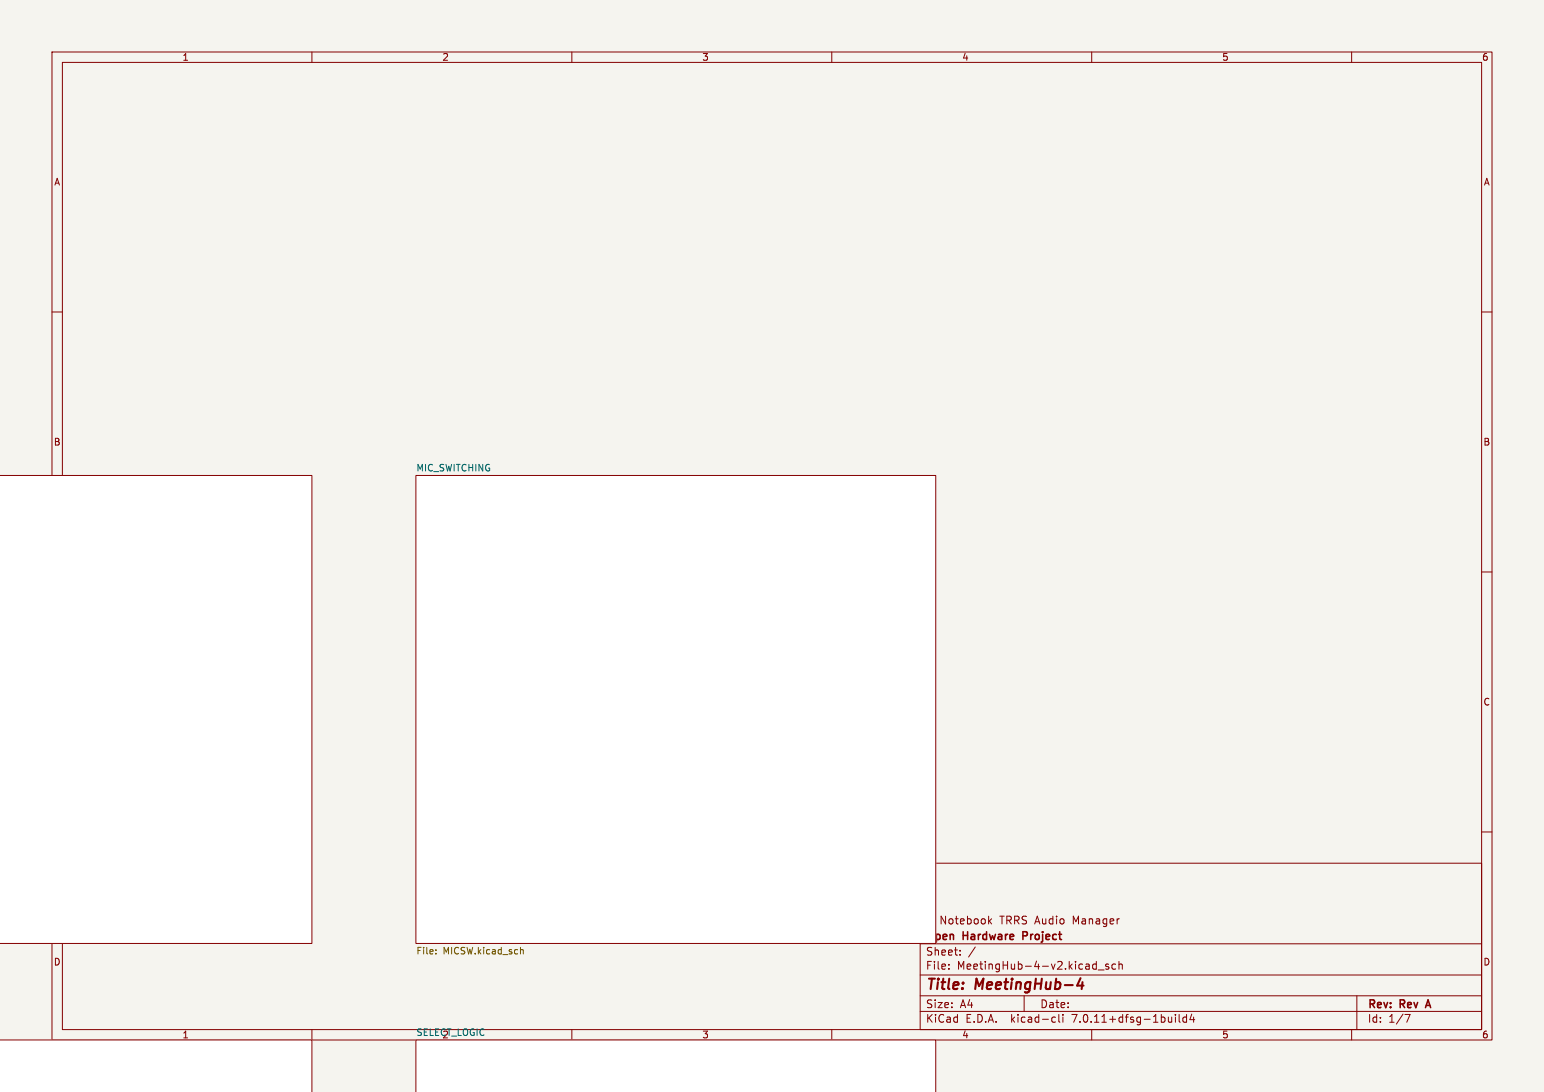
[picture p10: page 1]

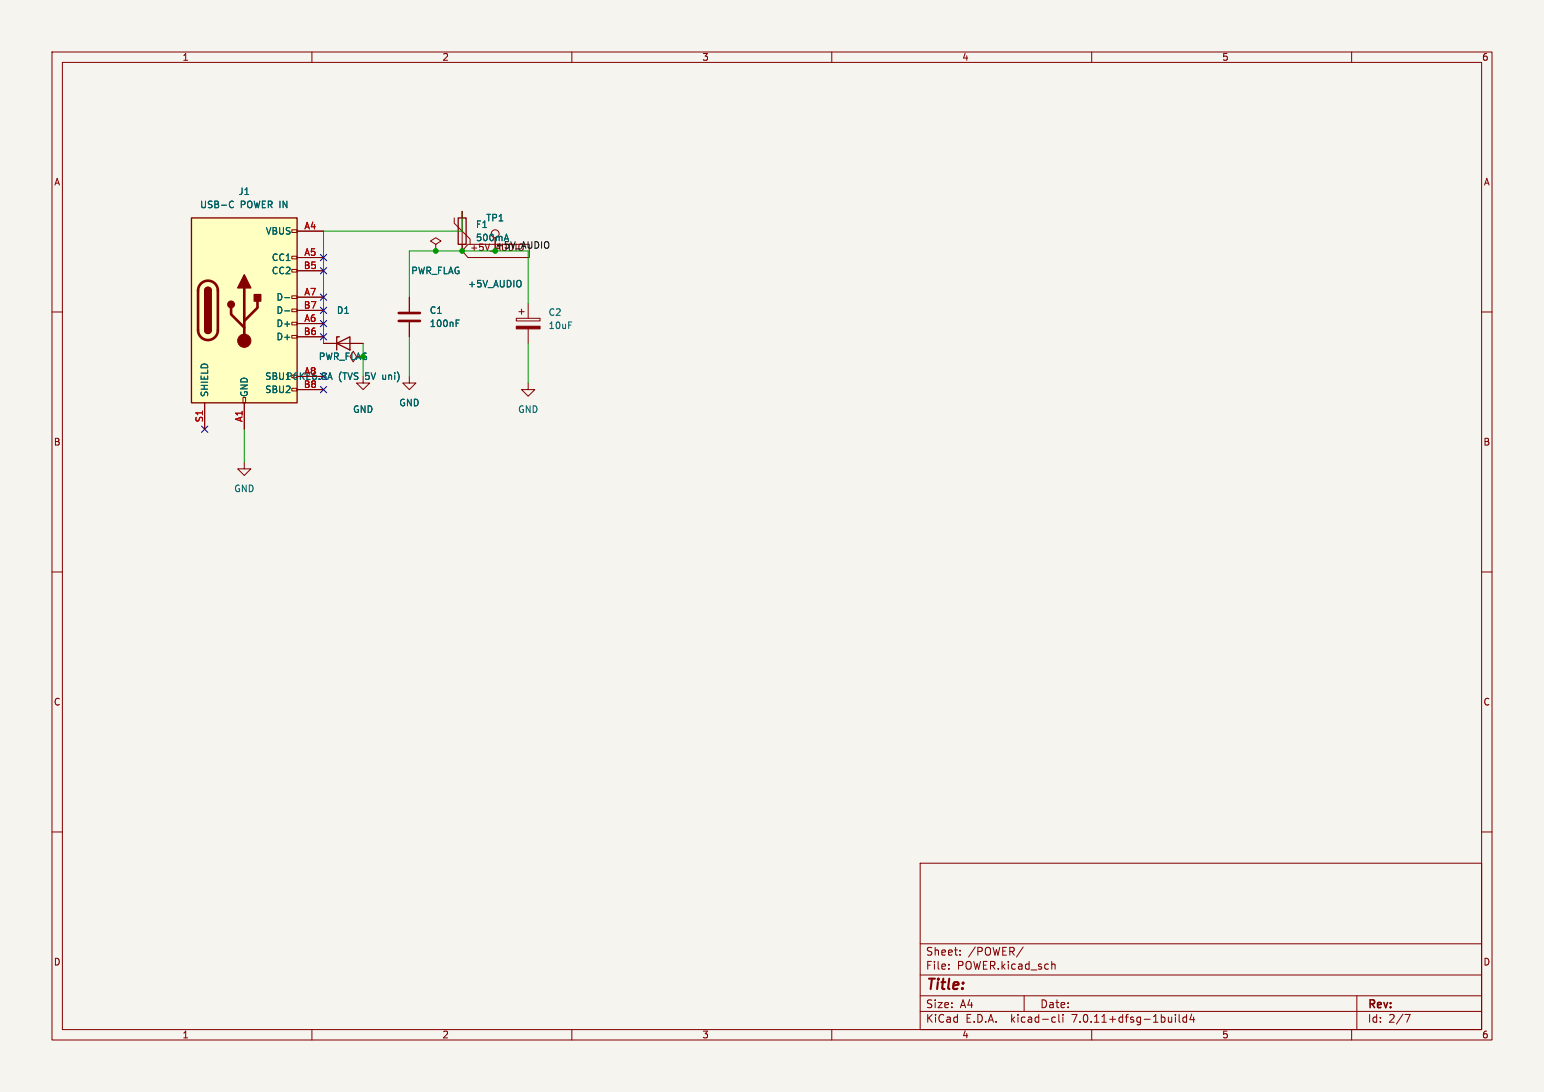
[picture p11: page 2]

Id: 2/7 Title: File: POWER.kicad_sch Sheet: /POWER/

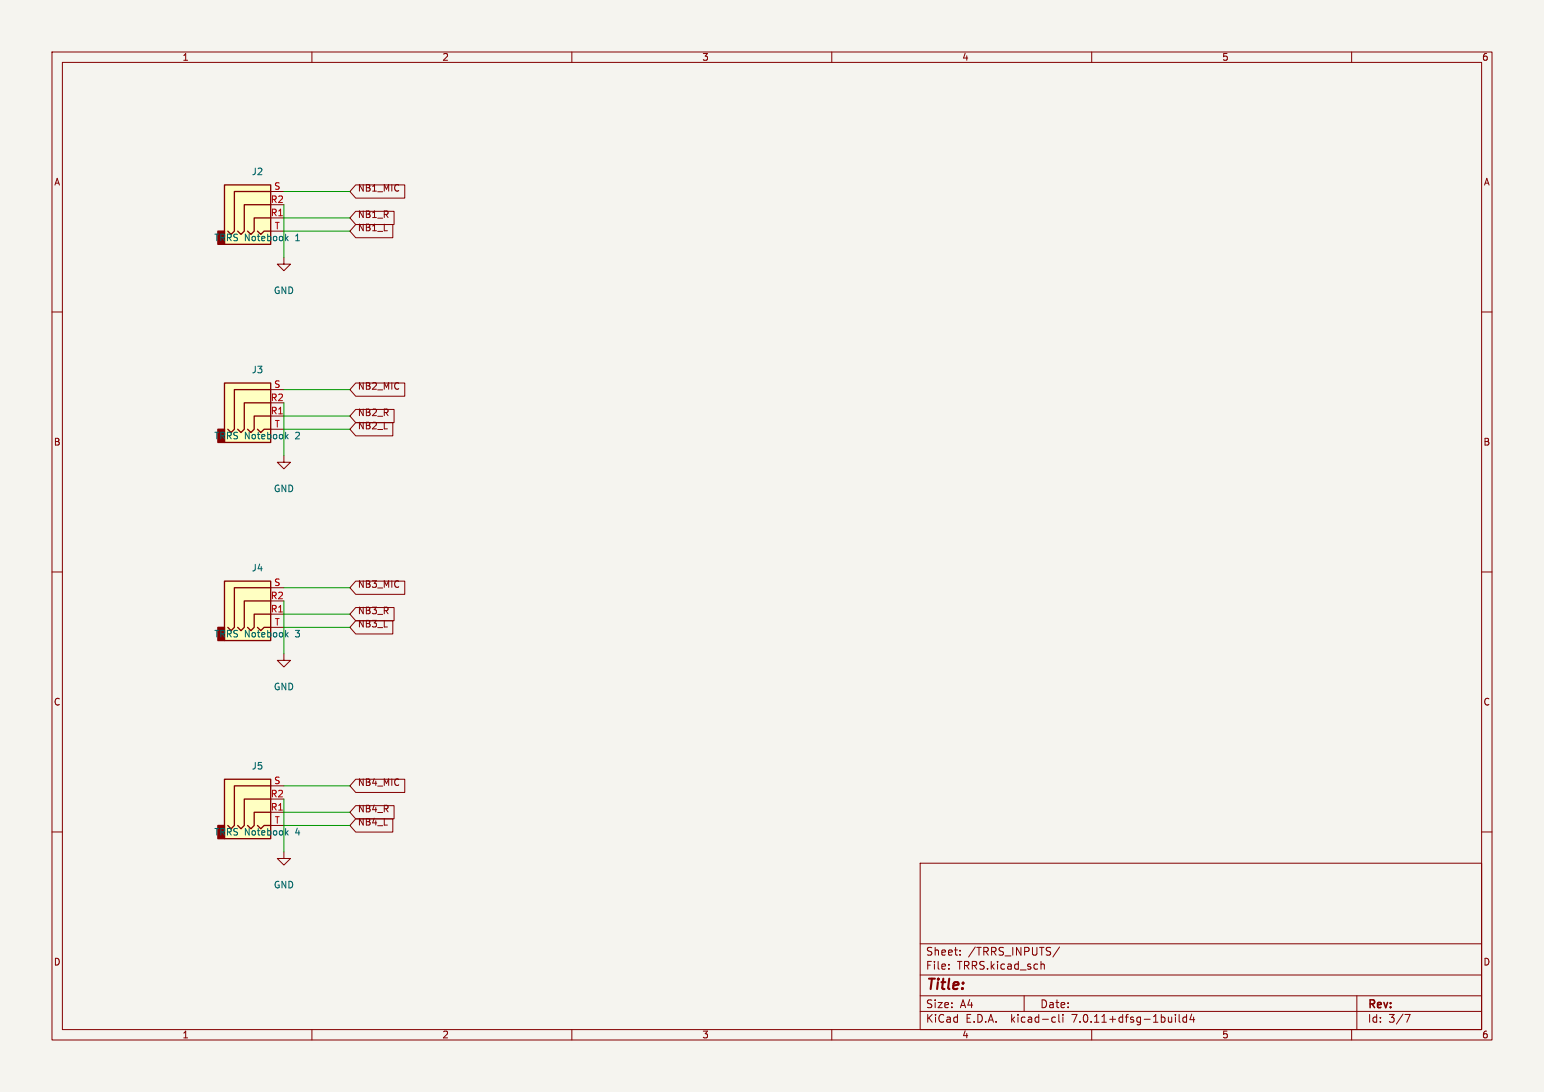
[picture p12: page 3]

Id: 3/7 Title: File: TRRS.kicad_sch Sheet: /TRRS_INPUTS/

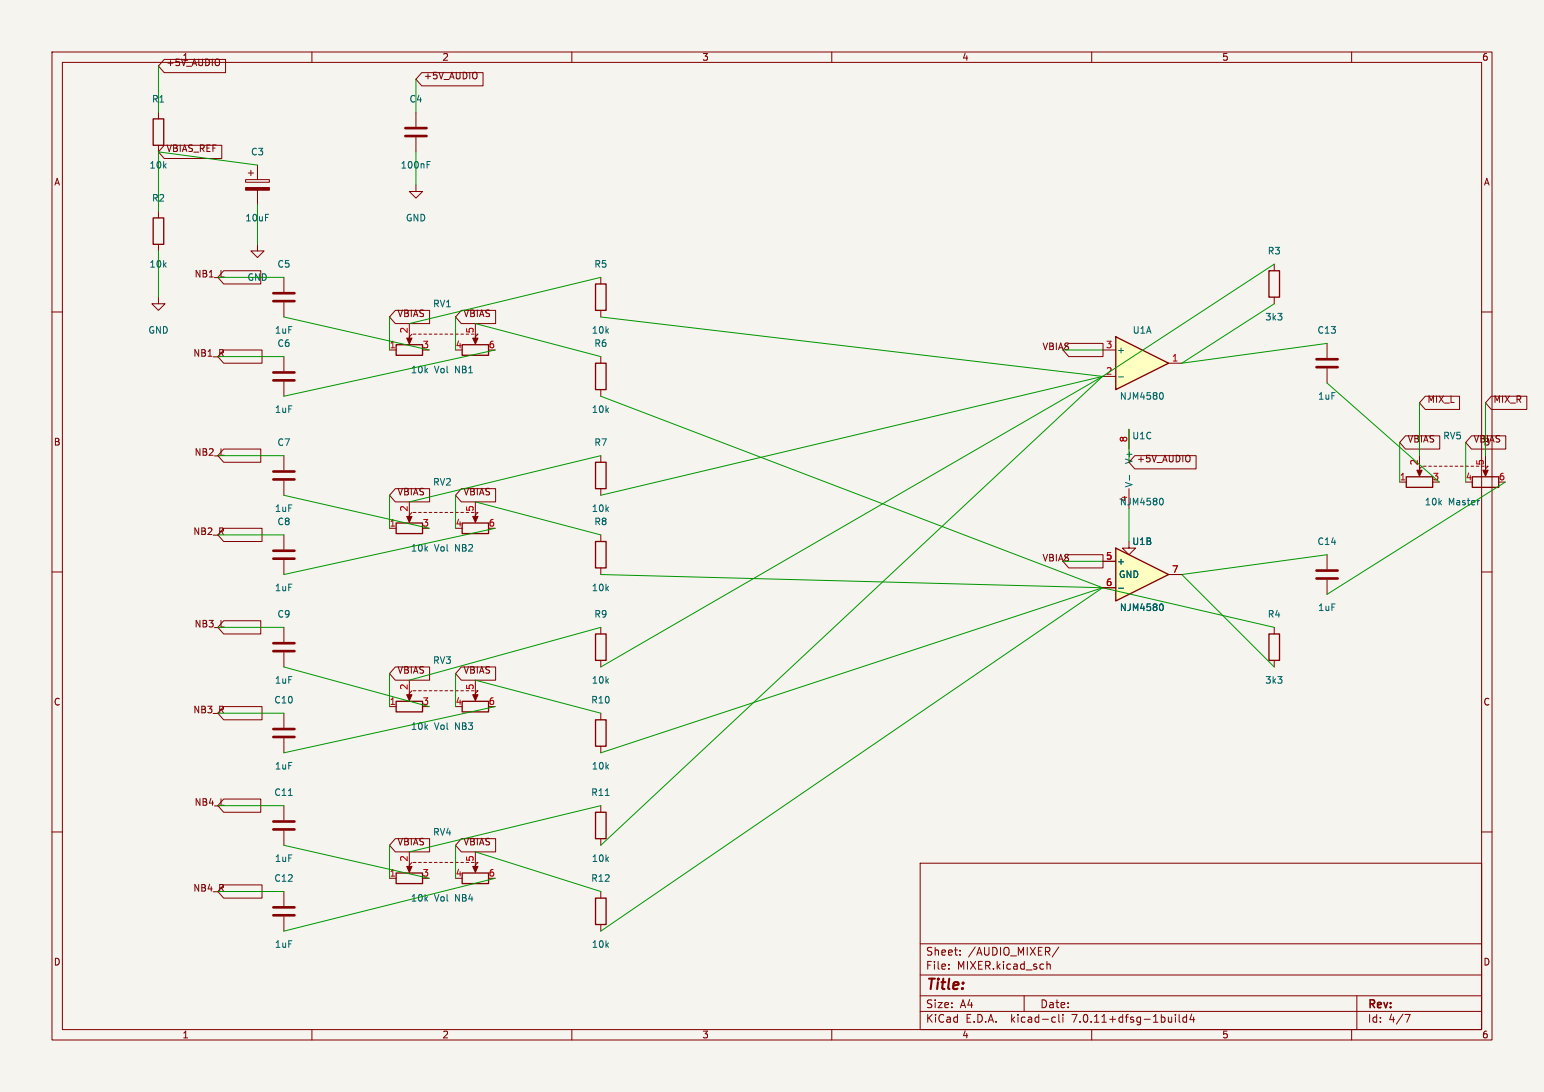
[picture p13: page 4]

Id: 4/7 Title: File: MIXER.kicad_sch Sheet: /AUDIO_MIXER/

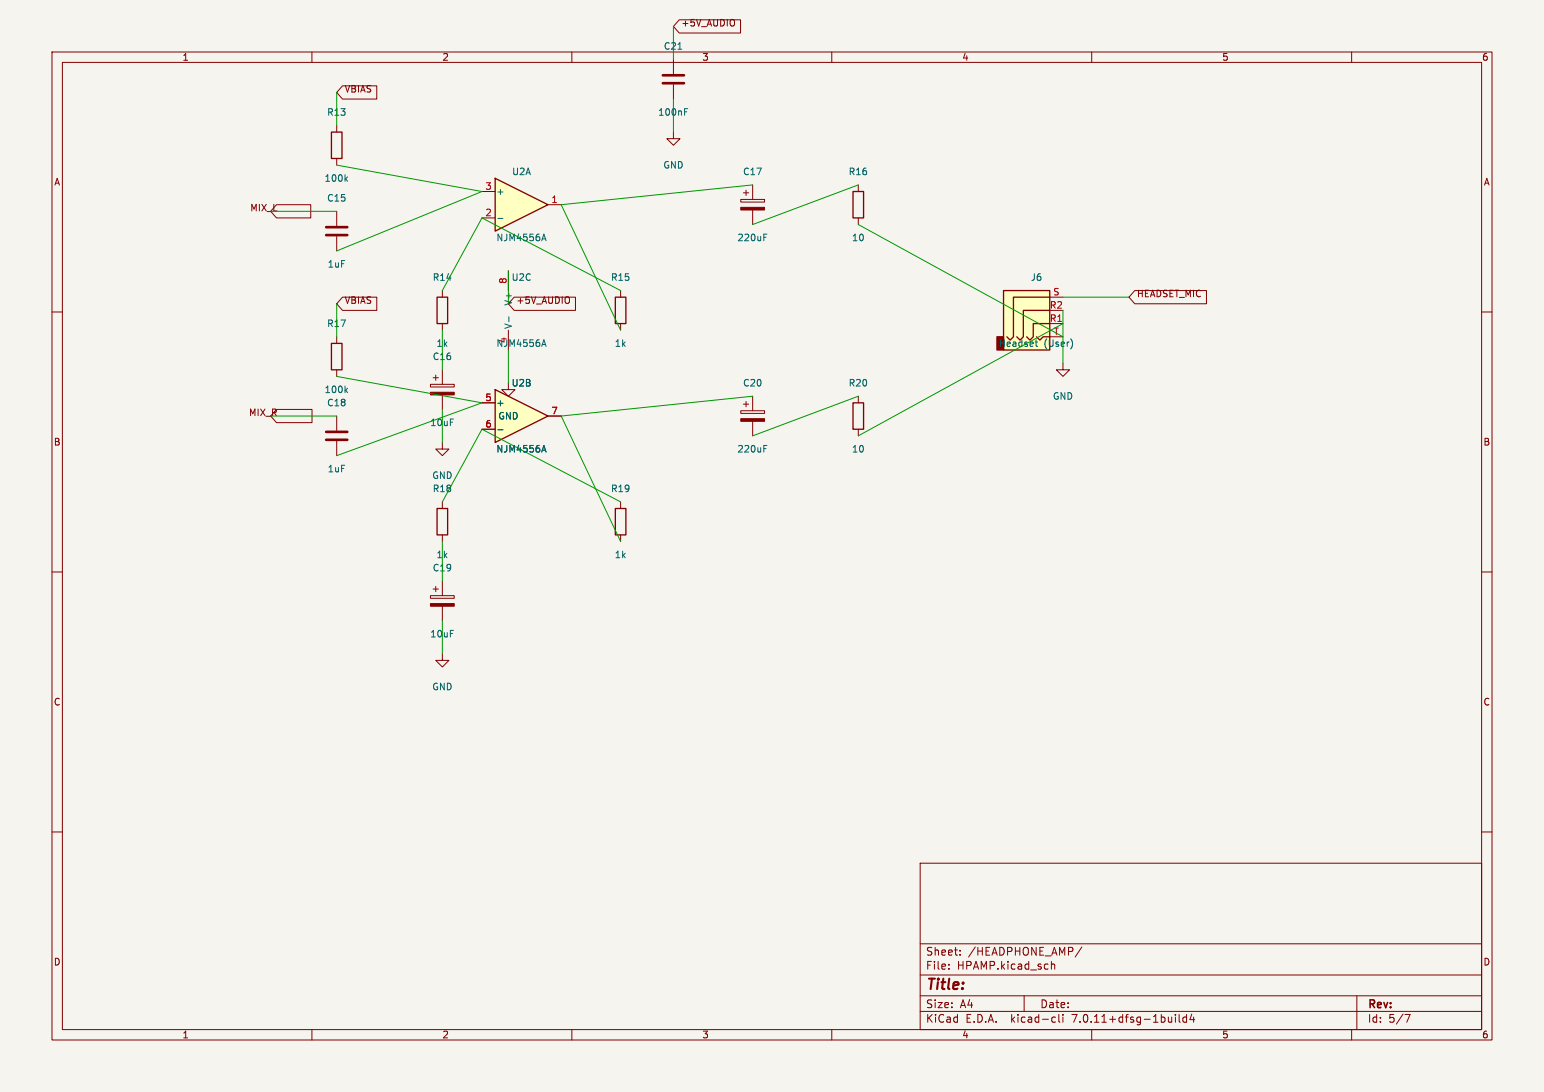
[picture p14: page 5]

Id: 5/7 Title: File: HPAMP.kicad_sch Sheet: /HEADPHONE_AMP/

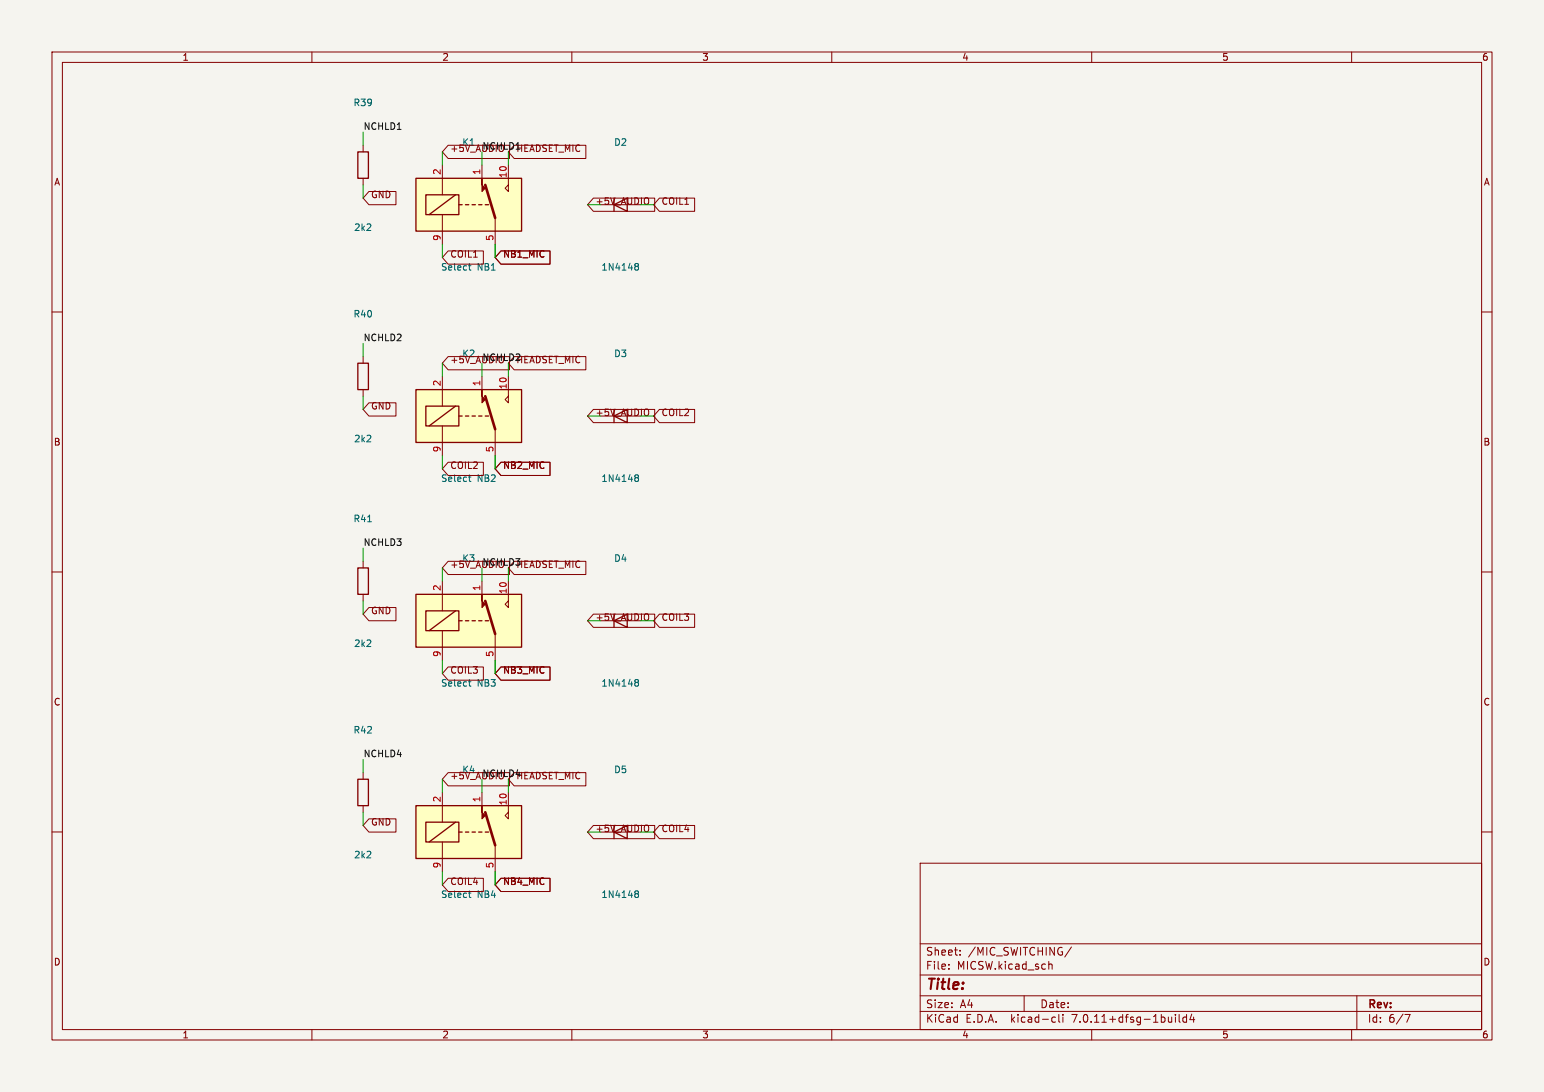
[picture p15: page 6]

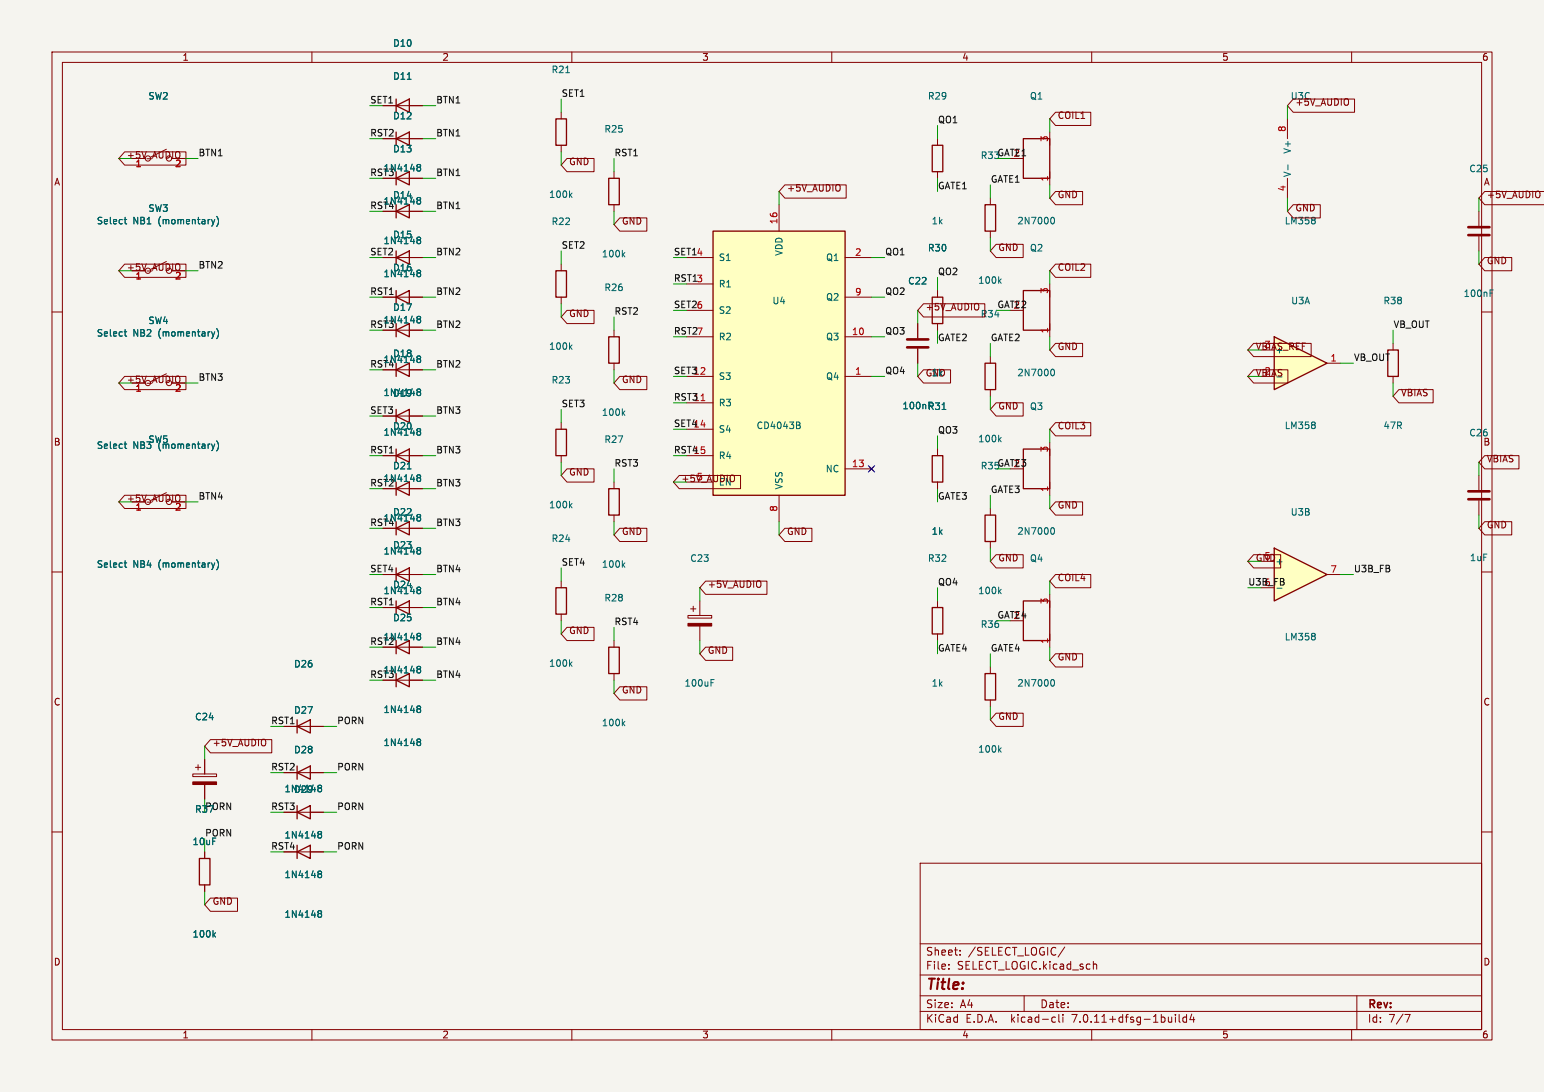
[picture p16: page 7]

Id: 7/7 Title: File: SELECT_LOGIC.kicad_sch Sheet: /SELECT_LOGIC/

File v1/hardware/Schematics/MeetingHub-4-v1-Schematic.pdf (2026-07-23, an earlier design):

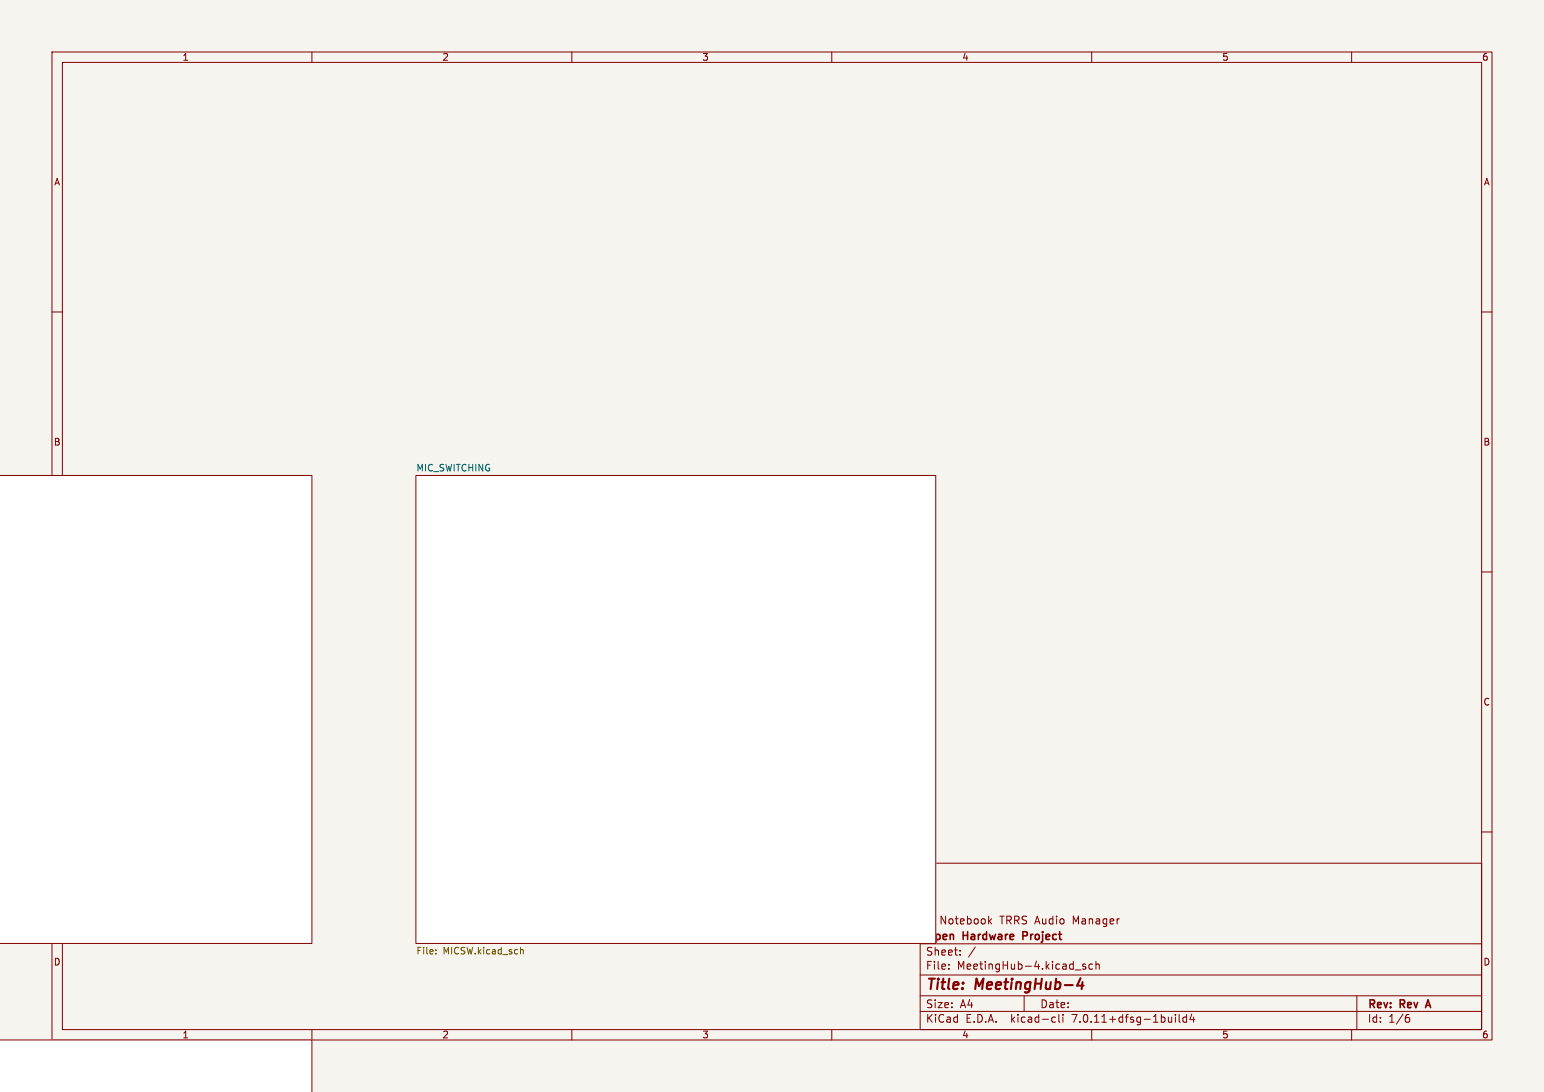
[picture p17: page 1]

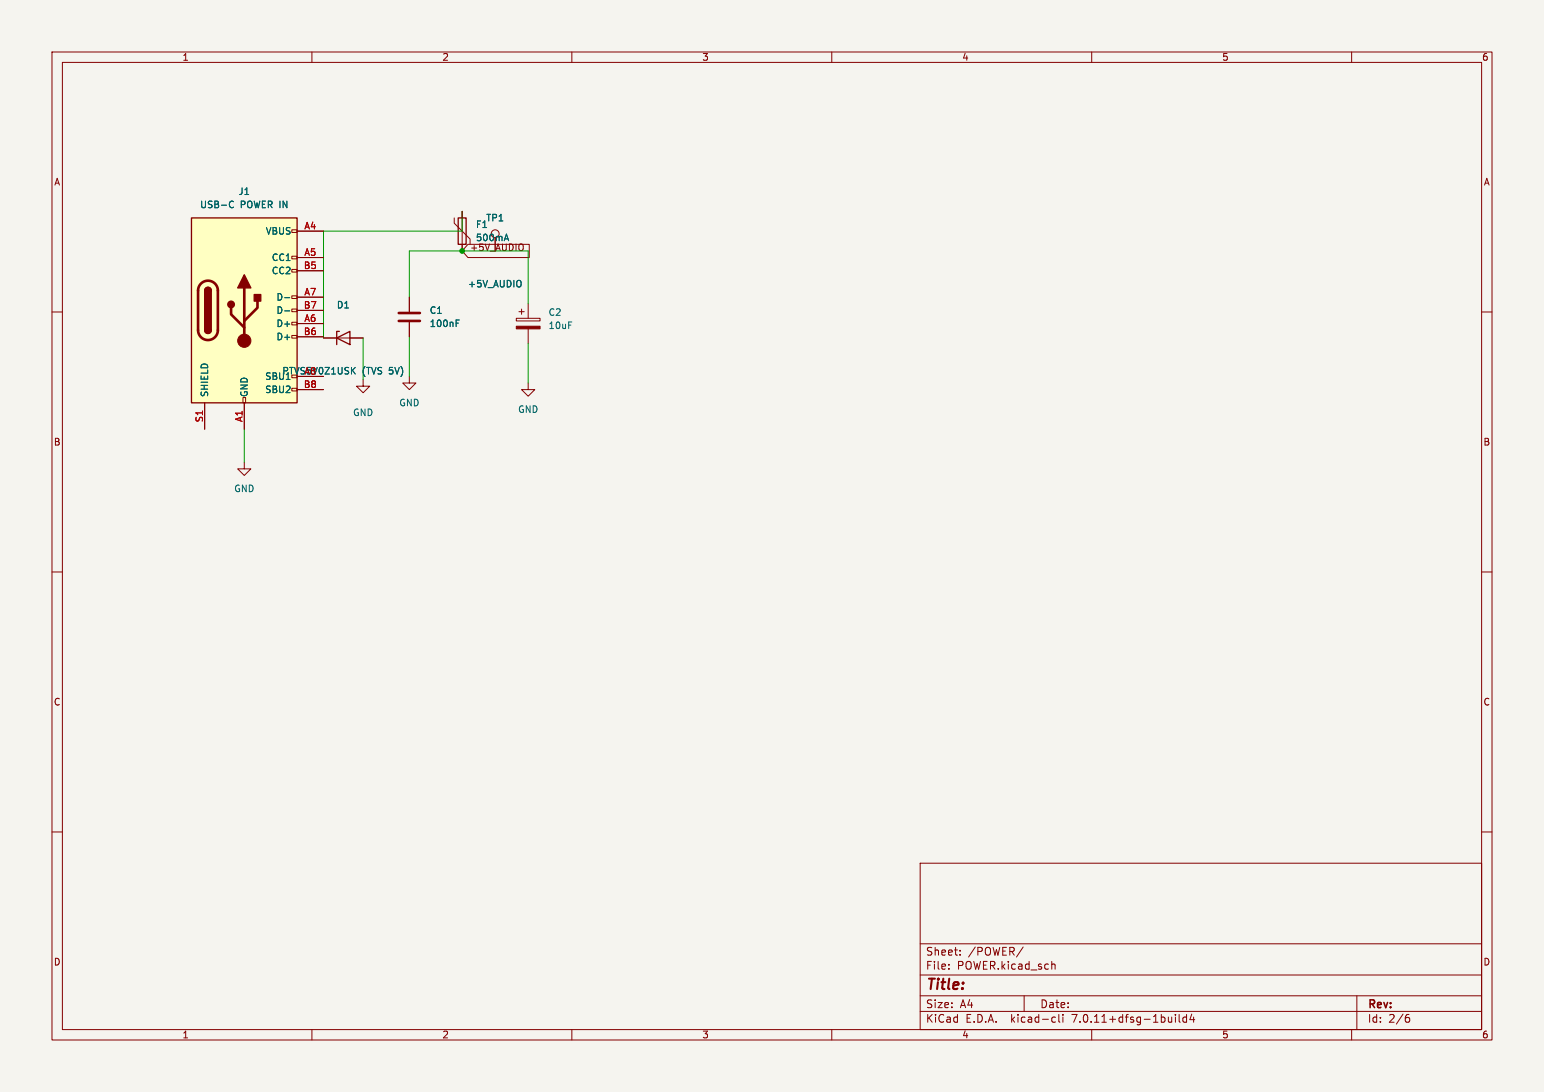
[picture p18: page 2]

Id: 2/6 Title: File: POWER.kicad_sch Sheet: /POWER/

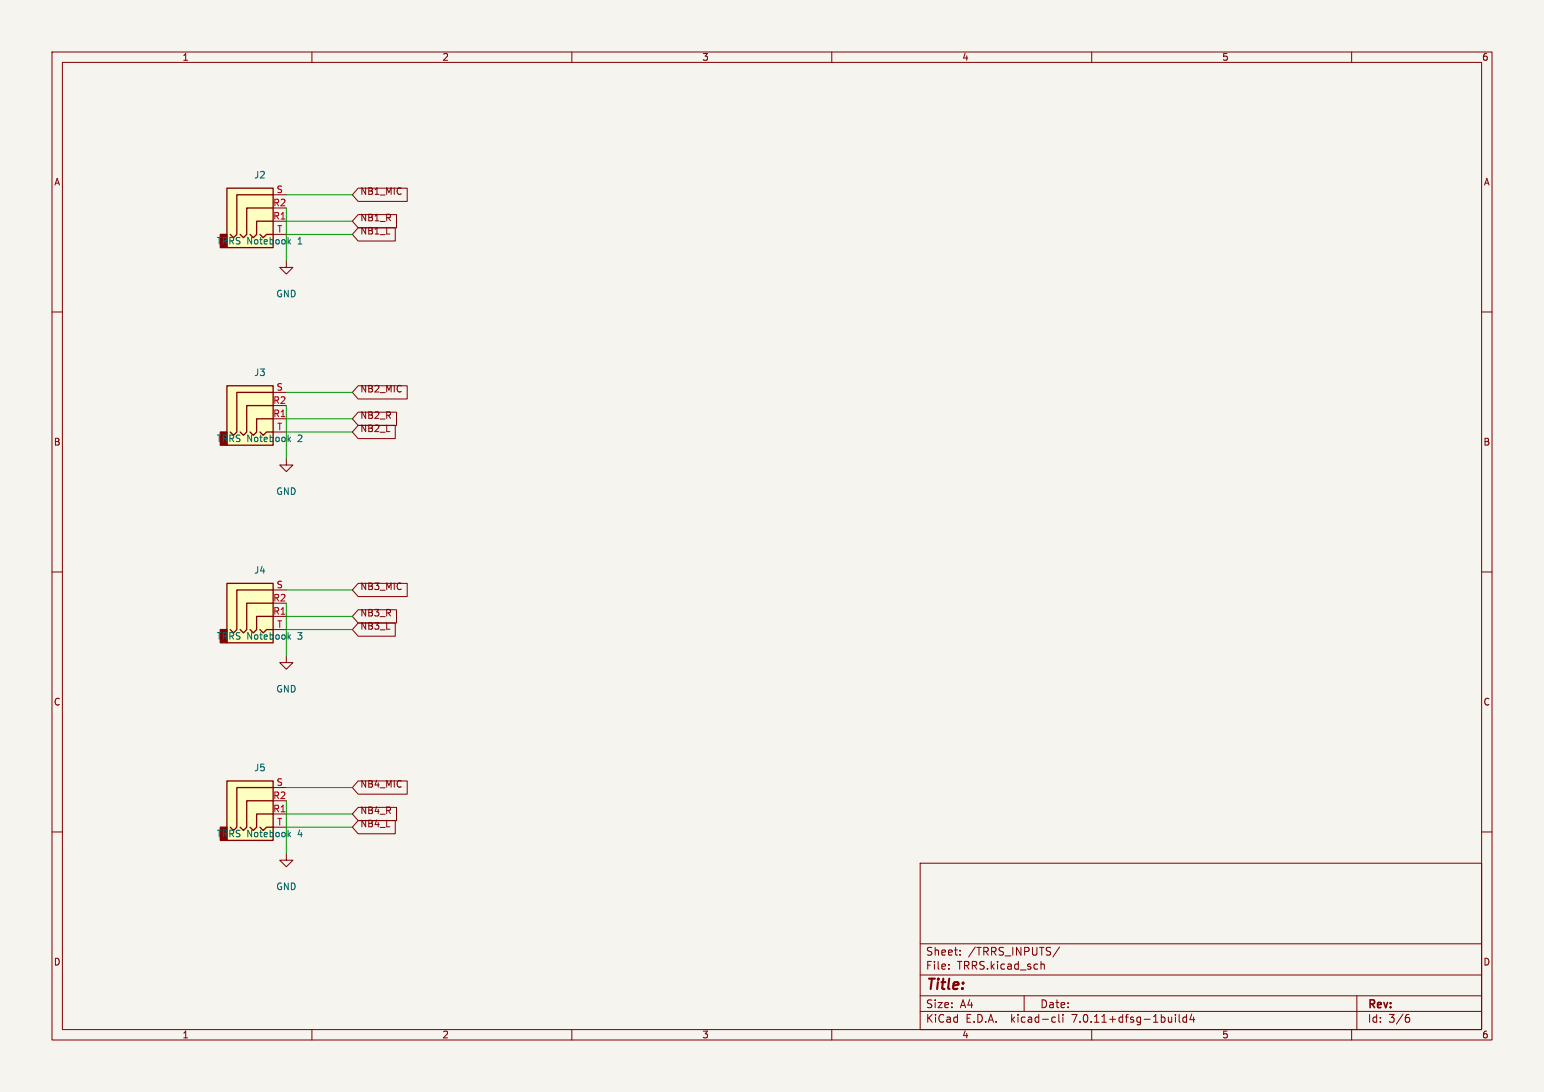
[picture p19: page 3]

Id: 3/6 Title: File: TRRS.kicad_sch Sheet: /TRRS_INPUTS/

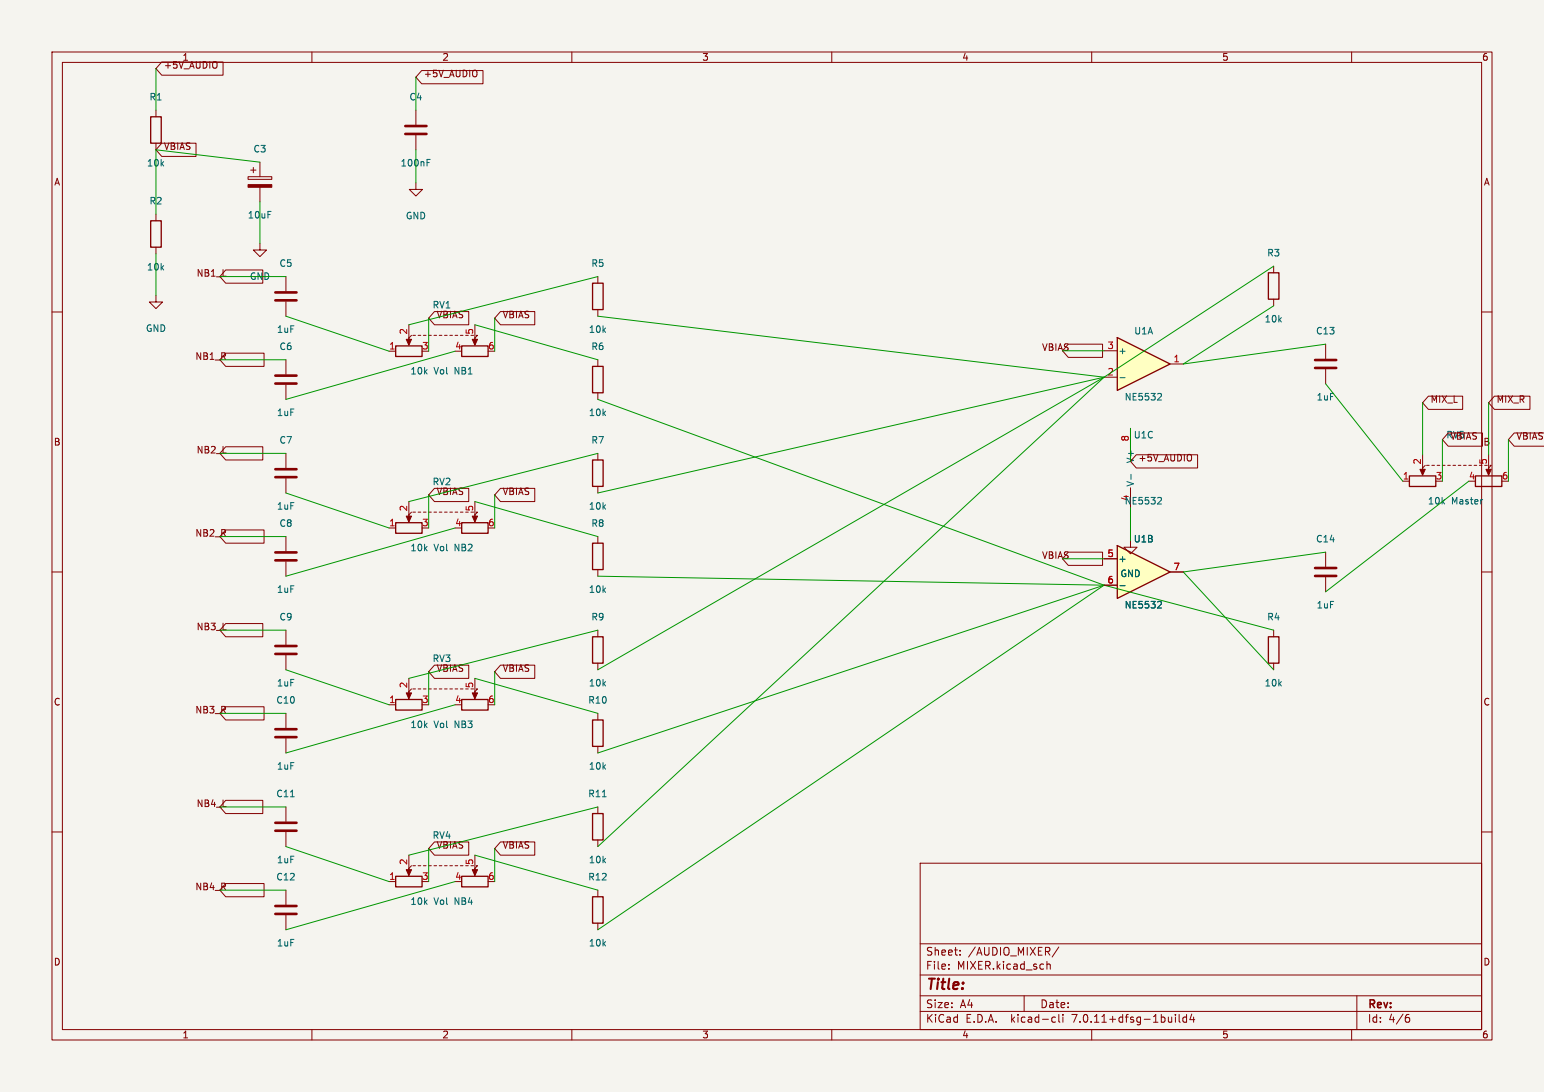
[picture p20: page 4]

Id: 4/6 Title: File: MIXER.kicad_sch Sheet: /AUDIO_MIXER/


Id: 5/6 Title: File: HPAMP.kicad_sch Sheet: /HEADPHONE_AMP/


Id: 6/6 Title: File: MICSW.kicad_sch Sheet: /MIC_SWITCHING/

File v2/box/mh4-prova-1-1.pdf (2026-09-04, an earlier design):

## MeetingHub-4 v2 — Prova de impressão 1:1 — Chapa TOPO

192,00 × 156,00 mm — cantos R6; Chapa TOPO; Calibração — 50,00 mm

Imprimir e conferir antes de mandar cortar de verdade · confere com mh4-plano-de-corte.pdf

IMPRIMIR EM TAMANHO REAL / 100%

desative "ajustar à página" / "fit to page" / "escalar" na caixa de impressão.

meça esta barra com uma régua depois de imprimir

TOPO e BASE têm geometria idêntica nesta revisão (sem furo de trimmer — RV1-RV5 são horizontais
e saem pela borda, não pelo topo). Recorte esta folha e sobreponha na chapa cortada para conferir
contorno e os 6 furos M3 antes de instalar.

MeetingHub-4 v2 · prova de impressão · chapa topo
gerado a partir do MeetingHub-4-v2.kicad_pcb · baseado em v1/box/mh4-prova-1-1.pdf

## MeetingHub-4 v2 — Prova de impressão 1:1 — Chapa BASE

192,00 × 156,00 mm — cantos R6; Chapa BASE; Calibração — 50,00 mm

Imprimir e conferir antes de mandar cortar de verdade · confere com mh4-plano-de-corte.pdf

IMPRIMIR EM TAMANHO REAL / 100%

desative "ajustar à página" / "fit to page" / "escalar" na caixa de impressão.

meça esta barra com uma régua depois de imprimir

Geometria idêntica à chapa TOPO (ver página anterior) — só furos de fixação M3, sem furo de trimmer.
Recorte esta folha e sobreponha na chapa cortada para conferir contorno e os 6 furos M3 antes de
instalar.

MeetingHub-4 v2 · prova de impressão · chapa base
gerado a partir do MeetingHub-4-v2.kicad_pcb · baseado em v1/box/mh4-prova-1-1.pdf

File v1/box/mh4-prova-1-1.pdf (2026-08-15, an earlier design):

## MeetingHub-4 — prova em escala

Imprimir em tamanho real / 100%

CHAPA TOPO — 3 mm — MH1–4 (Ø3,5) + RV1–4 (Ø9,2)

— desative "ajustar à
página" / "fit to page" /
"escalar" na caixa de
impressão.

Como conferir a
escala
Meça com uma régua a
barra de 50,00 mm
desenhada dentro da
chapa base. Se não
bater exatamente
50 mm, a impressão foi
escalada — corrija a
impressora antes de
furar.

Legenda
fixação M3 (ambas as
chapas).
RV1–4: Ø9,2 mm, rosca
do trimmer
chapa topo).

Uso desta prova
Recorte no papel e
sobreponha no acrílico,
ou fure o papel e use
como gabarito para
marcar os centros antes
de furar de verdade.

CHAPA BASE — 3 mm — MH1–4 (Ø3,5)

MeetingHub-4 · datum (0,0) =
canto superior esquerdo de
cada chapa · mesmas
coordenadas de mh4-acrilico-
topo.dxf / -base.dxf

50,00 mm — confira com régua

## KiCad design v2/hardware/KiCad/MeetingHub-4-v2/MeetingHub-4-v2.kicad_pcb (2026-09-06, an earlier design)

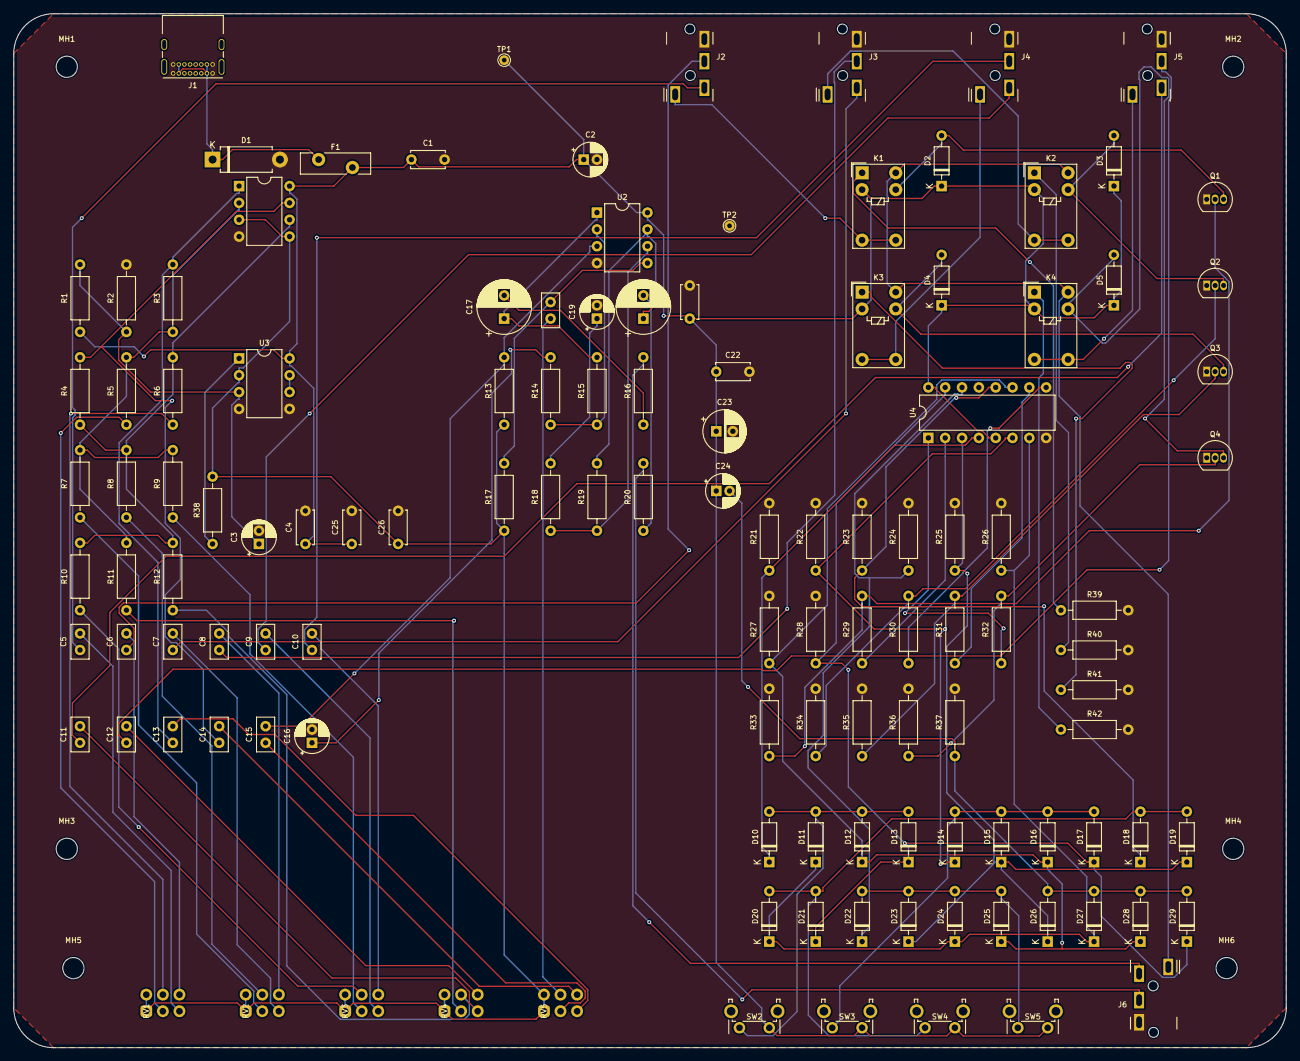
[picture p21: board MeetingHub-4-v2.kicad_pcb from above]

Board: 2 copper layers, 192.0 x 156.0 mm, 129 parts (0 on the bottom side), 85 nets.

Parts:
C1, C4, C21, C22, C25, C26: C_Disc_D5.0mm_W2.5mm_P5.00mm
C2, C3, C16, C19, C24: CP_Radial_D5.0mm_P2.00mm
C5, C6, C7, C8, C9, C10, C11, C12, C13, C14, C15, C18: C_Disc_D5.0mm_W2.5mm_P2.50mm
C17, C20: CP_Radial_D8.0mm_P3.50mm
C23: CP_Radial_D6.3mm_P2.50mm
D1: D_DO-15_P10.16mm_Horizontal
D2, D3, D4, D5, D10, D11, D12, D13, D14, D15, D16, D17, D18, D19, D20, D21, D22, D23, D24, D25, D26, D27, D28, D29: D_DO-35_SOD27_P7.62mm_Horizontal
F1: Fuse_Bourns_MF-RG500
J1: USB_C_Receptacle_GCT_USB4085
J2, J3, J4, J5, J6: Jack_3.5mm_PJ-3200B-4A_Horizontal
K1, K2, K3, K4: Relay_SPDT_Omron_G5V-1
MH1, MH2, MH3, MH4, MH5, MH6: MountingHole_3.2mm_M3
Q1, Q2, Q3, Q4: TO-92_Inline
R1, R2, R3, R4, R5, R6, R7, R8, R9, R10, R11, R12, R13, R14, R15, R16, R17, R18, R19, R20, R21, R22, R23, R24, R25, R26, R27, R28, R29, R30, R31, R32, R33, R34, R35, R36, R37, R38, R39, R40, R41, R42: R_Axial_DIN0207_L6.3mm_D2.5mm_P10.16mm_Horizontal
RV1, RV2, RV3, RV4, RV5: Potentiometer_Alps_RK097_Dual_Horizontal
SW2, SW3, SW4, SW5: SW_Tactile_SPST_Angled_PTS645Vx39-2LFS
TP1, TP2: TestPoint_THTPad_D1.5mm_Drill0.7mm
U1, U2, U3: DIP-8_W7.62mm
U4: DIP-16_W7.62mm

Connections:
+5V_AUDIO: C1.1, C2.1, C4.1, C21.1, C22.1, C23.1, C24.1, C25.1, D2.1, D3.1, D4.1, D5.1, F1.2, K1.2, K2.2, K3.2, K4.2, R1.1, SW2.1, SW3.1, SW4.1, SW5.1, TP1.1, U1.8, U2.8, U3.8, U4.5, U4.16
/MIC_SWITCHING/NCHLD1: K1.1, R39.1
/MIC_SWITCHING/NCHLD2: K2.1, R40.1
/MIC_SWITCHING/NCHLD3: K3.1, R41.1
/MIC_SWITCHING/NCHLD4: K4.1, R42.1
/SELECT_LOGIC/BTN1: D10.2, D11.2, D12.2, D13.2, SW2.2
/SELECT_LOGIC/BTN2: D14.2, D15.2, D16.2, D17.2, SW3.2
/SELECT_LOGIC/BTN3: D18.2, D19.2, D20.2, D21.2, SW4.2
/SELECT_LOGIC/BTN4: D22.2, D23.2, D24.2, D25.2, SW5.2
/SELECT_LOGIC/GATE1: Q1.2, R29.2, R33.1
/SELECT_LOGIC/GATE2: Q2.2, R30.2, R34.1
/SELECT_LOGIC/GATE3: Q3.2, R31.2, R35.1
/SELECT_LOGIC/GATE4: Q4.2, R32.2, R36.1
/SELECT_LOGIC/PORN: C24.2, D26.2, D27.2, D28.2, D29.2, R37.1
/SELECT_LOGIC/QO1: R29.1, U4.2
/SELECT_LOGIC/QO2: R30.1, U4.9
/SELECT_LOGIC/QO3: R31.1, U4.10
/SELECT_LOGIC/QO4: R32.1, U4.1
/SELECT_LOGIC/RST1: D15.1, D19.1, D23.1, D26.1, R25.1, U4.3
/SELECT_LOGIC/RST2: D11.1, D20.1, D24.1, D27.1, R26.1, U4.7
/SELECT_LOGIC/RST3: D12.1, D16.1, D25.1, D28.1, R27.1, U4.11
/SELECT_LOGIC/RST4: D13.1, D17.1, D21.1, D29.1, R28.1, U4.15
/SELECT_LOGIC/SET1: D10.1, R21.1, U4.4
/SELECT_LOGIC/SET2: D14.1, R22.1, U4.6
/SELECT_LOGIC/SET3: D18.1, R23.1, U4.12
/SELECT_LOGIC/SET4: D22.1, R24.1, U4.14
/SELECT_LOGIC/U3B_FB: U3.6, U3.7
/SELECT_LOGIC/VB_OUT: R38.1, U3.1
COIL1: D2.2, K1.9, Q1.3
COIL2: D3.2, K2.9, Q2.3
COIL3: D4.2, K3.9, Q3.3
COIL4: D5.2, K4.9, Q4.3
GND: C1.2, C2.2, C3.2, C4.2, C16.2, C19.2, C21.2, C22.2, C23.2, C25.2, C26.2, D1.2, J1.A1, J1.A12, J1.B1, J1.B12, J2.R2, J3.R2, J4.R2, J5.R2, J6.R2, Q1.1, Q2.1, Q3.1, Q4.1, R2.2, R21.2, R22.2, R23.2, R24.2, R25.2, R26.2, R27.2, R28.2, R33.2, R34.2, R35.2, R36.2, R37.2, R39.2, R40.2, R41.2, R42.2, TP2.1, U1.4, U2.4, U3.4, U3.5, U4.8
HEADSET_MIC: J6.S, K1.10, K2.10, K3.10, K4.10
MIX_L: C15.1, RV5.2
MIX_R: C18.1, RV5.5
NB1_L: C5.1, J2.T
NB1_MIC: J2.S, K1.5, K1.6
NB1_R: C6.1, J2.R1
NB2_L: C7.1, J3.T
NB2_MIC: J3.S, K2.5, K2.6
NB2_R: C8.1, J3.R1
NB3_L: C9.1, J4.T
NB3_MIC: J4.S, K3.5, K3.6
NB3_R: C10.1, J4.R1
NB4_L: C11.1, J5.T
NB4_MIC: J5.S, K4.5, K4.6
NB4_R: C12.1, J5.R1
unnamed: C5.2, RV1.3
unnamed: C6.2, RV1.6
unnamed: C7.2, RV2.3
unnamed: C8.2, RV2.6
unnamed: C9.2, RV3.3
unnamed: C10.2, RV3.6
unnamed: C11.2, RV4.3
unnamed: C12.2, RV4.6
unnamed: C13.1, R3.2, U1.1
unnamed: C13.2, RV5.3
unnamed: C14.1, R4.2, U1.7
unnamed: C14.2, RV5.6
unnamed: C16.1, R14.2
unnamed: C17.1, R15.2, U2.1
unnamed: C17.2, R16.1
unnamed: C19.1, R18.2
unnamed: C20.1, R19.2, U2.7
unnamed: C20.2, R20.1
unnamed: D1.1, F1.1, J1.A4, J1.A9, J1.B4, J1.B9
unnamed: J6.R1, R20.2
unnamed: J6.T, R16.2
unnamed: R5.1, RV1.2
unnamed: R6.1, RV1.5
unnamed: R7.1, RV2.2
unnamed: R8.1, RV2.5
unnamed: R9.1, RV3.2
unnamed: R10.1, RV3.5
unnamed: R11.1, RV4.2
unnamed: R12.1, RV4.5
unnamed: R3.1, R5.2, R7.2, R9.2, R11.2, U1.2
unnamed: R4.1, R6.2, R8.2, R10.2, R12.2, U1.6
unnamed: C15.2, R13.2, U2.3
unnamed: R14.1, R15.1, U2.2
unnamed: C18.2, R17.2, U2.5
unnamed: R18.1, R19.1, U2.6
VBIAS: C26.1, R13.1, R17.1, R38.2, RV1.1, RV1.4, RV2.1, RV2.4, RV3.1, RV3.4, RV4.1, RV4.4, RV5.1, RV5.4, U1.3, U1.5, U3.2
VBIAS_REF: C3.1, R1.2, R2.1, U3.3

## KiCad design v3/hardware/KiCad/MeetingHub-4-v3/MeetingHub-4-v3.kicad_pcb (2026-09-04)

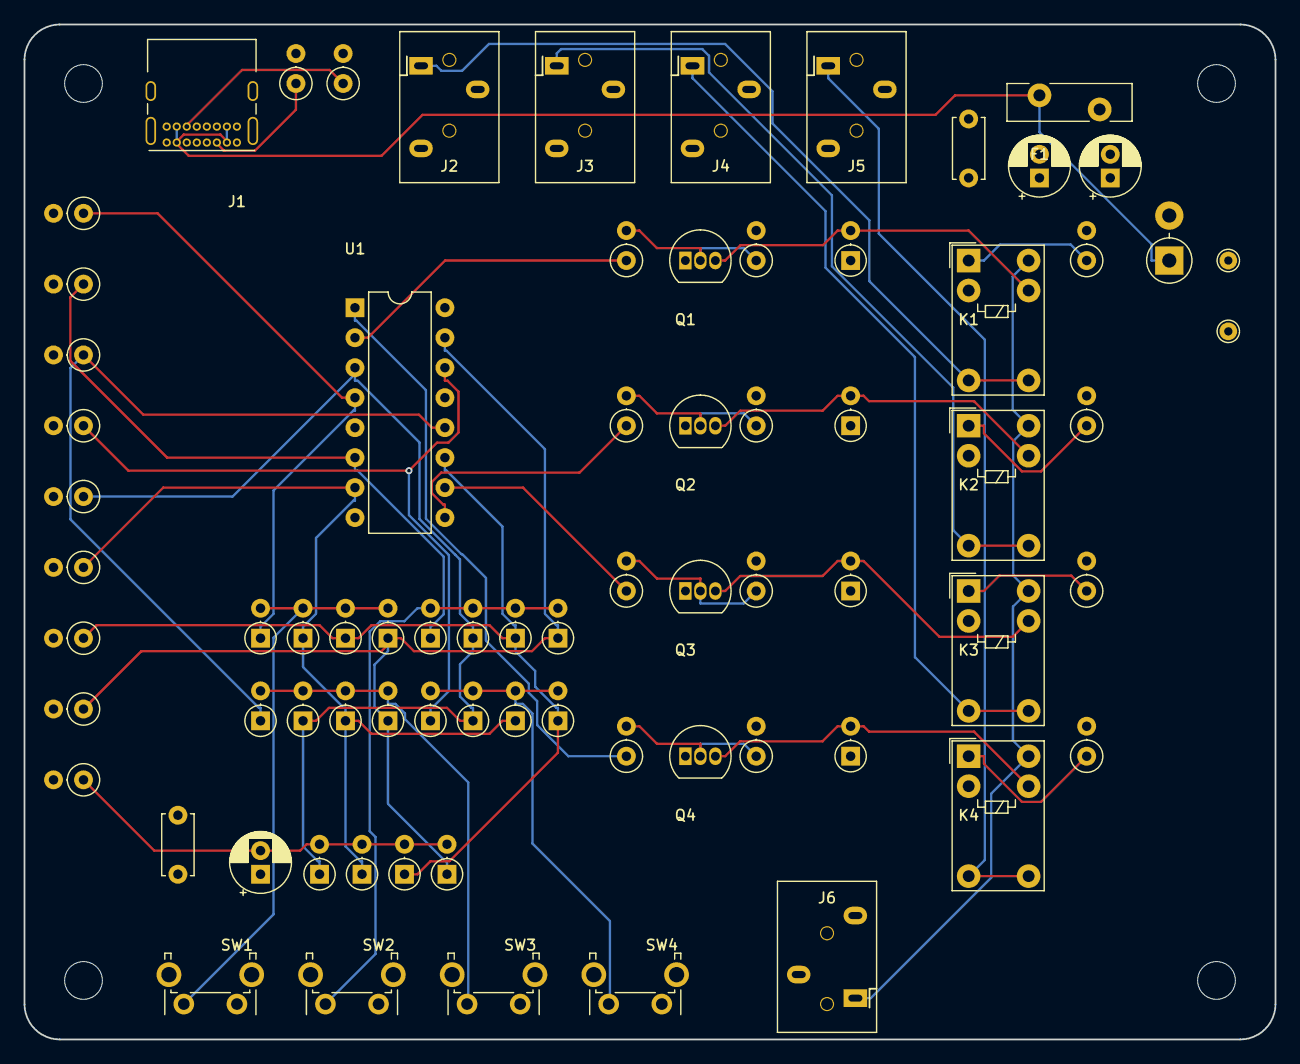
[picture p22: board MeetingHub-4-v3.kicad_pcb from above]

Board: 4 copper layers, 106.0 x 86.0 mm, 79 parts (0 on the bottom side), 39 nets.

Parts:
C1, C4: C_Disc_D5.0mm_W2.5mm_P5.00mm
C2, C3, C5: CP_Radial_D5.0mm_P2.00mm
D1: D_DO-15_P3.81mm_Vertical_AnodeUp
D2, D3, D4, D5, D6, D7, D8, D9, D10, D11, D12, D13, D14, D15, D16, D17, D18, D19, D20, D21, D22, D23, D24, D25: D_DO-35_SOD27_P2.54mm_Vertical_AnodeUp
F1: Fuse_Bourns_MF-RG500
J1: USB_C_Receptacle_GCT_USB4085
J2, J3, J4, J5, J6: Jack_3.5mm_3pole_THT_Horizontal
K1, K2, K3, K4: Relay_SPDT_Omron_G5V-1
MH1, MH2, MH3, MH4: MountingHole_3.2mm_M3
Q1, Q2, Q3, Q4: TO-92_Inline
R1, R2, R3, R4, R5, R6, R7, R8, R9, R10, R11, R12, R13, R14, R15, R16, R17, R18, R19, R20, R21, R22, R23: R_Axial_DIN0207_L6.3mm_D2.5mm_P2.54mm_Vertical
SW1, SW2, SW3, SW4: SW_Tactile_SPST_Angled_PTS645Vx39-2LFS
TP1, TP2: TestPoint_THTPad_D1.5mm_Drill0.7mm
U1: DIP-16_W7.62mm

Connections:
+5V: C1.1, C2.1, C3.1, C4.1, C5.1, D2.1, D3.1, D4.1, D5.1, F1.2, K1.2, K2.2, K3.2, K4.2, SW1.1, SW2.1, SW3.1, SW4.1, TP1.1, U1.5, U1.16
/BTN1: D6.2, D7.2, D8.2, D9.2, SW1.2
/BTN2: D10.2, D11.2, D12.2, D13.2, SW2.2
/BTN3: D14.2, D15.2, D16.2, D17.2, SW3.2
/BTN4: D18.2, D19.2, D20.2, D21.2, SW4.2
/CC1: J1.A5, R1.1
/CC2: J1.B5, R2.1
/COIL1: D2.2, K1.9, Q1.3
/COIL2: D3.2, K2.9, Q2.3
/COIL3: D4.2, K3.9, Q3.3
/COIL4: D5.2, K4.9, Q4.3
/GATE1: Q1.2, R12.2, R16.1
/GATE2: Q2.2, R13.2, R17.1
/GATE3: Q3.2, R14.2, R18.1
/GATE4: Q4.2, R15.2, R19.1
/NCBIAS1: K1.1, R20.1
/NCBIAS2: K2.1, R21.1
/NCBIAS3: K3.1, R22.1
/NCBIAS4: K4.1, R23.1
/PORN: C5.2, D22.2, D23.2, D24.2, D25.2, R11.1
/QO1: R12.1, U1.2
/QO2: R13.1, U1.9
/QO3: R14.1, U1.10
/QO4: R15.1, U1.1
/RST1: D11.1, D15.1, D19.1, D22.1, R7.1, U1.3
/RST2: D7.1, D16.1, D20.1, D23.1, R8.1, U1.7
/RST3: D8.1, D12.1, D21.1, D24.1, R9.1, U1.11
/RST4: D9.1, D13.1, D17.1, D25.1, R10.1, U1.15
/SET1: D6.1, R3.1, U1.4
/SET2: D10.1, R4.1, U1.6
/SET3: D14.1, R5.1, U1.12
/SET4: D18.1, R6.1, U1.14
/VBUS: D1.1, F1.1, J1.A4, J1.A9, J1.B4, J1.B9
GND: C1.2, C2.2, C3.2, C4.2, D1.2, J1.A1, J1.A12, J1.B1, J1.B12, J1.S1, J2.2, J2.4, J3.2, J3.4, J4.2, J4.4, J5.2, J5.4, J6.2, J6.4, Q1.1, Q2.1, Q3.1, Q4.1, R1.2, R2.2, R3.2, R4.2, R5.2, R6.2, R7.2, R8.2, R9.2, R10.2, R11.2, R16.2, R17.2, R18.2, R19.2, R20.2, R21.2, R22.2, R23.2, TP2.1, U1.8
HS_MIC: J6.3, K1.10, K2.10, K3.10, K4.10
NB1_MIC: J2.3, K1.5, K1.6
NB2_MIC: J3.3, K2.5, K2.6
NB3_MIC: J4.3, K3.5, K3.6
NB4_MIC: J5.3, K4.5, K4.6

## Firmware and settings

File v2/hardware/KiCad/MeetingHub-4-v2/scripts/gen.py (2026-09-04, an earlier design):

#!/usr/bin/env python3
"""Generate SELECT_LOGIC.kicad_sch and rebuild MICSW.kicad_sch for MeetingHub-4 v3."""
import json, uuid, os

PRJ = "/home/fac/MeetingHub-4/v2/hardware/KiCad/MeetingHub-4-v2"
SP  = "/tmp/claude-1000/-home-fac-MeetingHub-4/4f6efdf4-c26b-4fc0-859e-6637f4f9d120/scratchpad"
ROOT_UUID = "8b7deae6-c6d2-463d-9623-40608a842bd8"
SEL_SHEET_UUID = "1a2b3c4d-0005-4a1a-8a1a-000000000005"
MIC_SHEET_UUID = "1a2b3c4d-0004-4a1a-8a1a-000000000004"

symblocks = json.load(open(SP + "/symblocks.json"))

Q = 1.27
def SNAP(v):
    return round(round(float(v) / Q) * Q, 4)

# clean hand-authored 2N7000 in the PROJECT-LOCAL library so it never conflicts
# with (or is reported as "modified" vs) KiCad's Transistor_FET:2N7000.
# (the KiCad-lib copy also segfaults kicad-cli 7.0.11 netlist export.)
symblocks["MeetingHub-4-v2:2N7000"] = r'''(symbol "MeetingHub-4-v2:2N7000" (pin_names hide) (in_bom yes) (on_board yes)
    (property "Reference" "Q" (at 5.08 1.905 0) (effects (font (size 1.27 1.27)) (justify left)))
    (property "Value" "2N7000" (at 5.08 0 0) (effects (font (size 1.27 1.27)) (justify left)))
    (property "Footprint" "" (at 0 0 0) (effects (font (size 1.27 1.27)) hide))
    (property "Datasheet" "" (at 0 0 0) (effects (font (size 1.27 1.27)) hide))
    (property "ki_description" "0.2A Id, N-Channel logic-level MOSFET, TO-92" (at 0 0 0) (effects (font (size 1.27 1.27)) hide))
    (property "ki_fp_filters" "TO?92*" (at 0 0 0) (effects (font (size 1.27 1.27)) hide))
    (symbol "2N7000_0_1"
      (rectangle (start -2.54 3.81) (end 2.54 -3.81) (stroke (width 0.254) (type default)) (fill (type none)))
    )
    (symbol "2N7000_1_1"
      (pin passive line (at 2.54 -5.08 90) (length 2.54) (name "S" (effects (font (size 1.27 1.27)))) (number "1" (effects (font (size 1.27 1.27)))))
      (pin input line (at -5.08 0 0) (length 2.54) (name "G" (effects (font (size 1.27 1.27)))) (number "2" (effects (font (size 1.27 1.27)))))
      (pin passive line (at 2.54 5.08 270) (length 2.54) (name "D" (effects (font (size 1.27 1.27)))) (number "3" (effects (font (size 1.27 1.27)))))
    )
  )'''

# ---- custom CD4043B symbol (single unit, DIP-16) --------------------------------
CD4043B_SYM = r'''(symbol "MeetingHub-4-v2:CD4043B" (pin_names (offset 1.016)) (in_bom yes) (on_board yes)
    (property "Reference" "U" (at -15.24 27.94 0) (effects (font (size 1.27 1.27)) (justify left)))
    (property "Value" "CD4043B" (at 2.54 27.94 0) (effects (font (size 1.27 1.27)) (justify left)))
    (property "Footprint" "Package_DIP:DIP-16_W7.62mm" (at 0 0 0) (effects (font (size 1.27 1.27)) hide))
    (property "Datasheet" "https://www.ti.com/lit/ds/symlink/cd4043b.pdf" (at 0 0 0) (effects (font (size 1.27 1.27)) hide))
    (property "ki_description" "Quad NOR R/S latch, 3-state outputs" (at 0 0 0) (effects (font (size 1.27 1.27)) hide))
    (property "ki_fp_filters" "DIP*W7.62mm*" (at 0 0 0) (effects (font (size 1.27 1.27)) hide))
    (symbol "CD4043B_0_1"
      (rectangle (start -12.7 25.4) (end 12.7 -25.4)
        (stroke (width 0.254) (type default)) (fill (type background)))
    )
    (symbol "CD4043B_1_1"
      (pin power_in line (at 0 30.48 270) (length 5.08) (name "VDD" (effects (font (size 1.27 1.27)))) (number "16" (effects (font (size 1.27 1.27)))))
      (pin power_in line (at 0 -30.48 90) (length 5.08) (name "VSS" (effects (font (size 1.27 1.27)))) (number "8" (effects (font (size 1.27 1.27)))))
      (pin input line (at -17.78 20.32 0) (length 5.08) (name "S1" (effects (font (size 1.27 1.27)))) (number "4" (effects (font (size 1.27 1.27)))))
      (pin input line (at -17.78 15.24 0) (length 5.08) (name "R1" (effects (font (size 1.27 1.27)))) (number "3" (effects (font (size 1.27 1.27)))))
      (pin input line (at -17.78 10.16 0) (length 5.08) (name "S2" (effects (font (size 1.27 1.27)))) (number "6" (effects (font (size 1.27 1.27)))))
      (pin input line (at -17.78 5.08 0) (length 5.08) (name "R2" (effects (font (size 1.27 1.27)))) (number "7" (effects (font (size 1.27 1.27)))))
      (pin input line (at -17.78 -2.54 0) (length 5.08) (name "S3" (effects (font (size 1.27 1.27)))) (number "12" (effects (font (size 1.27 1.27)))))
      (pin input line (at -17.78 -7.62 0) (length 5.08) (name "R3" (effects (font (size 1.27 1.27)))) (number "11" (effects (font (size 1.27 1.27)))))
      (pin input line (at -17.78 -12.7 0) (length 5.08) (name "S4" (effects (font (size 1.27 1.27)))) (number "14" (effects (font (size 1.27 1.27)))))
      (pin input line (at -17.78 -17.78 0) (length 5.08) (name "R4" (effects (font (size 1.27 1.27)))) (number "15" (effects (font (size 1.27 1.27)))))
      (pin input line (at -17.78 -22.86 0) (length 5.08) (name "EN" (effects (font (size 1.27 1.27)))) (number "5" (effects (font (size 1.27 1.27)))))
      (pin output line (at 17.78 20.32 180) (length 5.08) (name "Q1" (effects (font (size 1.27 1.27)))) (number "2" (effects (font (size 1.27 1.27)))))
      (pin output line (at 17.78 12.7 180) (length 5.08) (name "Q2" (effects (font (size 1.27 1.27)))) (number "9" (effects (font (size 1.27 1.27)))))
      (pin output line (at 17.78 5.08 180) (length 5.08) (name "Q3" (effects (font (size 1.27 1.27)))) (number "10" (effects (font (size 1.27 1.27)))))
      (pin output line (at 17.78 -2.54 180) (length 5.08) (name "Q4" (effects (font (size 1.27 1.27)))) (number "1" (effects (font (size 1.27 1.27)))))
      (pin no_connect line (at 17.78 -20.32 180) (length 5.08) (name "NC" (effects (font (size 1.27 1.27)))) (number "13" (effects (font (size 1.27 1.27)))))
    )
  )'''

# CD4043B pin free-end coords (symbol space, Y up) and outward dir
CD_PINS = {
 "16":(0,30.48,(0,-1)), "8":(0,-30.48,(0,1)),
 "4":(-17.78,20.32,(-1,0)), "3":(-17.78,15.24,(-1,0)),
 "6":(-17.78,10.16,(-1,0)), "7":(-17.78,5.08,(-1,0)),
 "12":(-17.78,-2.54,(-1,0)),"11":(-17.78,-7.62,(-1,0)),
 "14":(-17.78,-12.7,(-1,0)),"15":(-17.78,-17.78,(-1,0)),
 "5":(-17.78,-22.86,(-1,0)),
 "2":(17.78,20.32,(1,0)), "9":(17.78,12.7,(1,0)),
 "10":(17.78,5.08,(1,0)), "1":(17.78,-2.54,(1,0)),
 "13":(17.78,-20.32,(1,0)),
}
# opamp (LM2904 symbol) pin free ends
OP_PINS = {
 "1":(7.62,0,(1,0)),   "2":(-7.62,-2.54,(-1,0)), "3":(-7.62,2.54,(-1,0)),
 "7":(7.62,0,(1,0)),   "6":(-7.62,-2.54,(-1,0)), "5":(-7.62,2.54,(-1,0)),
 "8":(-2.54,7.62,(0,-1)), "4":(-2.54,-7.62,(0,1)),
}
R_PINS = {"1":(0,3.81,(0,-1)), "2":(0,-3.81,(0,1))}
C_PINS = {"1":(0,3.81,(0,-1)), "2":(0,-3.81,(0,1))}
D_PINS = {"1":(-3.81,0,(-1,0)), "2":(3.81,0,(1,0))}   # 1=K 2=A
Q_PINS = {"1":(2.54,-5.08,(0,1)), "2":(-5.08,0,(-1,0)), "3":(2.54,5.08,(0,-1))}  # S G D
SW_PINS= {"1":(-5.08,0,(-1,0)), "2":(5.08,0,(1,0))}
GND_PINS={"1":(0,0,(0,1))}
K_PINS = {"1":(2.54,7.62,(0,-1)), "10":(7.62,7.62,(0,-1)), "2":(-5.08,7.62,(0,-1)),
          "5":(5.08,-7.62,(0,1)), "6":(5.08,-7.62,(0,1)), "9":(-5.08,-7.62,(0,1))}
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

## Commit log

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2026-07-22 Add SCH-008 grounding and noise control design
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2026-07-22 Implement full MeetingHub-4 schematic (5 sheets) with footprints and BOM
    Builds out the KiCad project per SCH-001..009: POWER (USB-C input, fuse,
    TVS protection, test point), TRRS_INPUTS (4 notebook jacks), AUDIO_MIXER
    (per-notebook volume + NE5532 summing mixer + master volume), HEADPHONE_AMP
    (NJM4556A gain stage + user headset jack), and MIC_SWITCHING (mute + 4x
    relay-based mic routing). All 66 components have real THT footprints
    assigned, validated end-to-end via kicad-cli (netlist + PDF export).
    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
    [BOM-MeetingHub-4.csv, HPAMP.kicad_sch, MICSW.kicad_sch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]
2026-07-22 Add DR-003 schematic implementation review
    Documents what was actually built and validated in the KiCad schematic
    (kicad-cli netlist/PDF checks, footprint coverage), explicitly scopes what
    that validation does and doesn't cover versus a full ERC/DRC pass, and
    records the technical assumptions (VBIAS divider, gain values, mic-select
    interlock, kicad-cli extends-symbol workaround) a human reviewer should
    confirm before layout and fabrication.
2026-07-22 Correct and expand DR-003 functional description
    Fixes four factual inaccuracies flagged in review: POWER has no voltage
    regulator, VBIAS is generated in AUDIO_MIXER (not POWER) and biases the
    op-amps rather than the microphones, the headset TRRS jack lives in
    HEADPHONE_AMP rather than TRRS_INPUTS, and the mixer is active (NE5532
    summing amp) rather than passive. Also fixes a transcription slip (U2 is
    NJM4556A, not NE5532) and adds three separate block diagrams (power
    distribution, audio path, mic path) to make the architecture legible at a
    glance without conflating power and signal flow in one diagram.
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2026-07-23 Add PCB layout with all 70 footprints placed, fix outline and clearance
    Board now has all components placed (from Update PCB from Schematic +
    manual arrangement), a closed rectangular Edge.Cuts outline sized around
    the component bounding box, and the Default netclass clearance relaxed
    from 0.2mm to 0.15mm to match the USB-C connector's fine pin pitch.
    Removed a stray Edge.Cuts reference line baked into the RK097 potentiometer
    footprint (5 instances) that was preventing outline closure - it's a
    library alignment artifact, not a real board cutout, so this is an
    intentional local deviation from the library copy (shows up as a harmless
    lib_footprint_mismatch warning in DRC).
    DRC is clean of er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
    [HPAMP.kicad_sch, MICSW.kicad_sch, MIXER.kicad_sch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]
2026-07-23 Update PCB-001 guide: front/top/back panel arrangement, applied layout
    Replaces the generic panel-component table and schematic-sheet-based
    zoning diagram with the arrangement actually decided and applied: J6 +
    mic mute/select switches on the front (most frequently touched), volume
    pots on top, notebook TRRS jacks + USB-C + power at the back (plugged
    once, rarely touched). Fase 4 now documents the applied result instead of
    a future to-do, with a note that spacing was validated by anchor-distance
    only and still needs a visual/physical check.
    [MeetingHub-4.kicad_pcb]
2026-07-23 Align front (J6+SW1-5) and back (P2+USB-C) panel rows
    Both rows were on the correct edge already but at slightly different Y
    per component; now every connector in each row shares the same Y with
    uniform pitch, matching a real front-panel/back-panel strip. Power
    cluster (F1, D1, C1, C2, TP1) shifted along with J1 to stay adjacent.
    [MeetingHub-4.kicad_pcb]
2026-07-23 Fix HEADPHONE_AMP courtyard overlaps (R13-20, C15-21)
    DRC flagged 6 real errors: adjacent resistors/caps in the HPAMP grid had
    overlapping courtyards because the 12mm pitch was tighter than the
    R_Axial_DIN0207 resistor's actual courtyard width (the MIXER grid at 13mm
    pitch had zero such errors, confirming 12mm was the problem). Widened to
    15mm pitch x / 12mm pitch y; board bounding box unchanged, still fits the
    existing outline.
    [MeetingHub-4.kicad_pcb]
2026-07-23 Route the board with Freerouting (all 121 nets, 0 unrouted)
    Installed OpenJDK 25 + Freerouting 2.2.4 to get a real autorouter, since
    kicad-cli 7.0.11 has no DRC/routing subcommands and hand-writing 143
    trace connections without a way to verify shorts was too risky.
    Pipeline: exported Specctra DSN via pcbnew's ExportSpecctraDSN (respects
    the project's net class rules - 0.2mm clearance/width), routed with
    Freerouting (-mp 15), then applied the resulting .ses to the board using
    pcbnew's own PCB_TRACK/PCB_VIA API directly (KiCad's ImportSpecctraSES
    turned out to require a live GUI frame and silently no-ops headlessly, so
    a custom SES parser feeds pcbnew's object API instead of hand-writing
    S-ex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
    [MeetingHub-4.kicad_pcb]
2026-07-23 Widen Power and RelayControl nets beyond the 0.2mm default
    Added two net classes (Power: +5V_AUDIO/GND; RelayControl: the four
    K-coil-drive nets Net-(D2-A..D5-A)) and widened their already-routed
    copper in place, rather than re-running the autorouter (topology was
    already correct; widening in place is lower risk than re-routing).
    First attempt (0.7mm power / 0.45mm relay) created real clearance
    violations against neighboring signal/mic traces - caught by a custom
    capsule-distance clearance check (segment/via edge-to-edge distance vs
    required clearance), since this KiCad version has no CLI DRC. Backed off
    to 0.35mm / 0.3mm, which clears with 0 violations and 0 unconnected
    nets. Netclass defi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
    [MeetingHub-4.kicad_pcb]
2026-07-23 Fix Power/RelayControl net widths and reroute 2 disconnected GND pads
    Reduces Power/RelayControl netclass track width from the previous
    0.7mm/0.45mm to a uniform 0.3mm (via 0.65mm/0.35mm drill), matching what
    was actually applied to the routed copper. This resolves the 5 clearance
    errors from the last DRC report, which were all caused by the
    over-widened traces crowding neighboring pads.
    Also fixes the 2 unconnected_items errors on the GND net. Root cause:
    the zone filler splits the GND pour into 3 disjoint copper islands in
    this layout (the main plane plus two small isolated pockets around the
    U1/mixer area and the C3/C4/R9 area) because the surrounding component
    density leaves no legal pa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
    [MeetingHub-4.kicad_pcb]
2026-07-23 Fix R2 unconnected GND pad; restore load-bearing U1 via
    Adds a short stitch trace + via from R2 pin 2 (GND) to open board space
    that reaches the main GND plane, resolving that unconnected_items error.
    Verified with a fresh path search (excluding R2's own sibling pads as
    false obstacles) and the pad-inclusive/layer-aware clearance check.
    Also removes the redundant via that used to sit directly on C3 pin 2
    (same location as the pad, doing nothing since that pin already has a
    working stitch to the main plane) but discovered mid-fix that the
    equivalent via on U1 pin 4 was NOT redundant — removing it re-isolated
    U1 pin 4 from the plane, so it's restored unchanged.
    C4 pin 2 (GND) remains unres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
    [MeetingHub-4.kicad_pcb]
2026-07-23 Add 4 mounting holes for enclosure fixing (PCB-001 Fase 3.3.3)
    Adds MountingHole_3.2mm_M3 footprints at each corner, 6mm margin from
    the board edge, matching the guide's spec. All 4 corners were clear of
    other components, so no repositioning was needed. Positions:
    MH1 (66, 91) - superior esquerdo
    MH2 (319, 91) - superior direito
    MH3 (66, 239) - inferior esquerdo
    MH4 (319, 239) - inferior direito
    Updates PCB-001-LayoutGuide.md section 3.3.3 to record the applied
    positions instead of just instructions. If the enclosure is already
    chosen, these need to line up with its fixing holes/rails before
    fabrication - just move the 4 footprints in the GUI if not.
    [MeetingHub-4.kicad_pcb]
2026-07-23 Document the design-rule floor correction and expected MH1-4 warning
    Records the corrected min track width/clearance values (0.2mm/0.15mm,
    not the original 0.25mm/0.2mm suggestion) now that the board is actually
    routed - the original suggestion predates routing and would have flagged
    ~400 existing 0.2mm traces as violations.
    Also documents the [extra_footprint] warning on MH1-MH4 as expected and
    safe to ignore: mounting holes are mechanical-only and intentionally
    have no schematic symbol, so the schematic/PCB consistency check flags
    them - this is normal for MountingHole footprints, not a real problem.
2026-07-23 Fix missing library reference on MH1-4 mounting holes
    The mounting holes added for Fase 3.3.3 were inserted via a direct
    filesystem path load (pcbnew.FootprintLoad), which left their FPID
    without a library nickname - saved as bare "MountingHole_3.2mm_M3"
    instead of "MountingHole:MountingHole_3.2mm_M3". DRC caught this as
    [lib_footprint_issues]: "library ''" on all 4. Fixed by setting the
    correct LIB_ID (library nickname "MountingHole", matching the global
    fp-lib-table entry for MountingHole.pretty). Verified gerber export
    still succeeds.
    [MeetingHub-4.kicad_pcb]
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2026-07-23 Add .gitignore for KiCad backups, lock files, and DRC reports
    The last commit accidentally picked up ~15 KiCad backup zips, a full
    project zip, and the ~MeetingHub-4.kicad_pcb.lck lock file (created
    while the GUI has the file open) - none of these should be tracked
    going forward. This only prevents new occurrences from being staged;
    it doesn't remove what's already committed in history.
2026-07-23 Re-layout mixer grid (13→15mm pitch) to fix GND plane isolation
    Full redo per user request: widened the mixer grid (U1, R1-R12, C3-C14)
    from 13mm to 15mm X pitch, same Y pitch and anchor, reusing the same
    approach that fixed HPAMP's courtyard overlap earlier. Verified zero new
    bounding-box overlaps against the rest of the board (and even resolved
    2 pre-existing ones) before touching routing.
    Cleared all existing tracks/vias, re-exported to Specctra DSN, and ran
    Freerouting fresh: 121/121 nets routed cleanly (score 993.63). Re-applied
    the established Power/RelayControl net widths (0.3mm track, 0.65mm via)
    and refilled the GND zone.
    This fully resolves C4 pin 2 (GND), the pad that survived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
    [MeetingHub-4.kicad_pcb]
2026-07-23 Fix R2 unconnected pad and starved-thermal on C1/C3 (real DRC)
    Real DRC on the re-layouted board confirmed U1 pin 4 and C4 pin 2 are
    both fine (matching the last commit's prediction) and surfaced 2 new
    issues from the fresh routing pass:
    - R2 pin 2 (GND) was fully unconnected in its new grid position. Fixed
    with a trivial 0.4mm stub + via straight down into the main plane
    (0.87mm/1.09mm clearance to everything else).
    - C1 pin 2 and C3 pin 2 (GND) had [starved_thermal] errors - the zone
    filler could only route 1 thermal-relief spoke where 2 are required,
    in both cases due to nearby signal-trace congestion. Rather than
    fight the zone filler for more spoke room, set both pads' zone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
    [MeetingHub-4.kicad_pcb]
2026-07-23 Fix hole-to-hole violation on R2's GND stitch via
    The R2 pin 2 stitch from the last commit placed its via only 0.4mm from
    R2's own pad, but R2 uses a 0.8mm drill and the via a 0.35mm drill -
    their holes were touching (0.0mm actual vs 0.2495mm minimum required),
    flagged as 2 [hole_near_hole] errors. Moved the via to 0.9mm from the
    pad (0.325mm hole-to-hole clearance), same direction, still comfortably
    inside the main GND plane and clear of everything else.
    Validated: paren balance, clearance check (only the same 4 pre-existing
    SW5/J6 items remain), clean kicad-cli pcb export gerbers.
    [MeetingHub-4.kicad_pcb]
2026-07-23 Document U1 pin 4 as a known/accepted GND limitation
    Closes out the investigation into the persistent GND-plane isolation on
    U1 pin 4. Confirmed via multiple independent approaches that no legal
    copper path exists within fabrication clearance minimums:
    - Two full re-layout + reroute cycles (mixer grid X pitch 13->15mm,
    then Y pitch 11->12mm)
    - Rotating U1 90 degrees (same pin adjacency, just repositioned)
    - Exhaustive scripted pathfinding (A*, signal-trace bulging)
    - Manual attempt in the KiCad GUI by the user
    Root cause: in a DIP-8 package, pin 4 is physically adjacent to pins 3
    and 5 by the package's own pin numbering - this local congestion is
    inherent to the chip's pinout, not the sur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
2026-07-23 Add TP2 GND test point near U1 as jumper anchor for pin 4
    Implements the practical fix for the documented U1 pin 4 limitation:
    adds TP2 (same TestPoint_THTPad_D1.5mm_Drill0.7mm footprint as TP1),
    wired to GND, at (67.0, 125.62) - 8mm from U1 pin 4, verified inside
    the main GND plane with 4.8mm clearance from everything else.
    This gives the manual jumper wire (documented in PCB-001) two clean,
    close, easy-to-reach solder points instead of having to find a GND via
    somewhere else on the board. Mechanical-only addition (no schematic
    symbol, same as the mounting holes) - will show the same expected
    [extra_footprint] DRC warning.
    Validated: paren balance, layer-aware clearance check (only the sa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
    [BOM-MeetingHub-4.csv, MeetingHub-4.kicad_pcb]
2026-07-23 Label TP2 on silkscreen as the U1 pin 4 jumper anchor
    Good catch: TP2's designator alone doesn't explain why someone should
    solder a wire there. Hides the default (long, unhelpful) footprint
    value text and replaces it with "JUMPER GND -> U1 PIN4" printed on
    F.Silkscreen right next to TP2, so it's obvious during assembly without
    needing to consult the docs.
    [MeetingHub-4.kicad_pcb]
2026-07-23 Migrate board to 4 layers, eliminating the U1 pin 4 limitation
    Real engineering fix for the persistent GND-plane isolation problem
    that survived two full re-layout cycles, a component rotation test, and
    manual attempts: the root cause was 2 signal layers competing with the
    GND pour for space. Standard professional fix is dedicated plane
    layers, so the board now has 4 copper layers:
    F.Cu / B.Cu - signal only (all ~105 point-to-point nets)
    In1.Cu - solid GND plane, no signal traces
    In2.Cu - solid +5V_AUDIO plane, no signal traces
    In1.Cu/In2.Cu are marked layer type "Power" (not "Signal") in the board
    setup - this is what stops the autorouter from placing signal traces on
    t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
    [BOM-MeetingHub-4.csv, MeetingHub-4.kicad_pcb]
2026-07-23 Fix all real silkscreen warnings (silk_overlap, silk_over_copper)
    Repositioned reference/value/marker text on 6 footprints to clear real
    overlaps found via pcbnew.WriteDRCReport:
    - R5, R16: reference text was landing on top of the neighboring U1/U2
    DIP-8 body outline (both are the first resistor in their grid row,
    right next to the IC). Moved below the value text instead.
    - D2-D5: reference and the 'K' (cathode) marker text were clipping both
    the diode's own body outline and, after an initial fix attempt, the
    K1-K4 relay pads sitting close above the same row. Settled on moving
    the reference to the side (clear of both the body and the relay pads)
    and the 'K' marker to the diode's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
    [MeetingHub-4.kicad_pcb]
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2026-07-23 Untrack backup zips, project zip, cache, lock, and DRC report files
    These were accidentally committed at various points this session (most
    from a single "git add -A" commit) despite being covered by .gitignore
    going forward - .gitignore only stops NEW occurrences from being
    staged, it doesn't retroactively untrack already-committed files.
    Removed from version control (kept on local disk, just no longer
    tracked):
    - hardware/KiCad/MeetingHub-4.zip (full project backup archive)
    - hardware/KiCad/MeetingHub-4/MeetingHub-4-backups/*.zip (11 KiCad
    auto-backup snapshots)
    - hardware/KiCad/MeetingHub-4/DRC.rpt (regenerable DRC report export)
    - hardware/KiCad/MeetingHub-4/fp-info-cache (regenerable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
2026-07-23 Refresh schematic PDF export (was stale since sheet reordering)
    The PDF was last generated before commit dcb9f10, which resaved the
    schematic files during PCB work and shifted the sheet page order/
    numbering (POWER moved to page 2, etc.) - the source .kicad_sch files
    were correct, but the exported PDF still reflected the old page order.
    Regenerated via `kicad-cli sch export pdf` from the current source;
    same page count (6), no circuit content changed.
2026-07-23 Sync BOM with final PCB: add MH1-4 and document TP2/status
    The BOM CSV and As-Built doc hadn't been touched since the PCB-only
    mechanical additions (TP2 GND test point, MH1-4 mounting holes) were
    made directly in the layout without schematic symbols:
    - Added MH1-4 (M3 mounting holes) as a BOM line - they're real physical
    hardware needed for assembly, same reasoning as why TP2 was already
    listed despite having no schematic symbol.
    - Updated the item count (70 schematic components + TP2 + MH1-4 = 75)
    and added footprint notes for both.
    - Rewrote the "Pendências antes da fabricação" section, which still
    listed ERC/layout/DRC as pending - all of that is done now. Replaced
    with a "S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
    [BOM-MeetingHub-4.csv]
2026-07-23 Add TEST-001 board bring-up and test guide
    Step-by-step procedure for testing an assembled board, ordered from
    safest to most involved: visual inspection (polarity of C2/C3/C16/C19/
    C17/C20/D1/D2-D5/U1/U2), continuity check before first power (TP1-TP2
    should read open, not shorted), first power-up with expected DC
    readings (TP1 ~5V, VBIAS ~half of TP1 via the R1/R2 10k/10k divider in
    MIXER), full functional test against the ERS-001 acceptance criteria
    (per-notebook monitoring, individual/master volume, mic selection via
    SW2-5/K1-4, MUTE, driver-less recognition), and a symptom-to-likely-
    cause troubleshooting table using this design's actual reference
    designators.
    Linked from README's readi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
2026-07-23 Correct BOM-002: ERC was never actually verified
    The previous commit marked "ERC via KiCad - sem erros pendentes" as
    done, but that was carried over from the old pending-items list without
    actual verification - no ERC was ever run or confirmed in this session.
    Unlike PCB DRC (where pcbnew.WriteDRCReport gave a real headless check),
    this KiCad version has no scriptable path for ERC at all, so it
    genuinely could not be verified here.
    Replaced with an explicit warning flagging ERC as the one remaining
    unverified gate before fabrication, with instructions to run it via the
    GUI (Inspect -> Electrical Rules Checker).
2026-07-23 Fix real ERC errors: TP1 never connected, U1 power_pin_not_driven, stale AudioJack4 lib_id
    - POWER.kicad_sch: add missing junction so TP1 actually joins the
    +5V_AUDIO wire (visual overlap without a junction is not a real
    connection in KiCad); add two power:PWR_FLAG symbols (+5V_AUDIO, GND)
    so ERC has an explicit power source for nets fed only by J1's USB-C
    VBUS pin, resolving power_pin_not_driven on U1.
    - MeetingHub-4.kicad_pcb: TP1's pad had no net at all on the physical
    board (unconnected-(TP1-Pad1)), and TP2 (GND test point added
    directly on the PCB) had no net either - both test points were
    floating on the real board despite BOM/docs claiming otherwise. Fixed
    by assigning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
    [MeetingHub-4.kicad_pcb, POWER.kicad_sch, TRRS.kicad_sch]
2026-07-23 Fix remaining ERC errors: wrong PWR_FLAG net, missing no-connects, J6 AudioJack4
    - POWER.kicad_sch: relocate #FLG01 (+5V_AUDIO PWR_FLAG) - it was tapped
    on the wire feeding fuse F1 from the input side, not the actual
    +5V_AUDIO net downstream of F1 (same node as TP1 and the +5V_AUDIO
    global label). U1 Pin 8 (V+) kept reporting power_pin_not_driven
    because of this even after the first fix. Also add no_connect markers
    on J1's 9 unused USB-C pins (D+, D-, CC1, CC2, SBU1, SBU2, SHIELD) -
    intentional since J1 is power-only, but ERC flagged them as errors
    without an explicit no-connect.
    - MICSW.kicad_sch: add no_connect on K1-K4 pin 10 (duplicate reverse
    relay contact, unused in thi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
    [HPAMP.kicad_sch, MICSW.kicad_sch, POWER.kicad_sch]
2026-07-23 Align all schematic symbols/wires to the 1.27mm ERC grid, fixing 232 endpoint_off_grid warnings
    Root cause: the schematic was drawn using round-millimeter coordinates
    (e.g. 55.0, 85.0, 115.0mm), which aren't multiples of the 1.27mm (50
    mil) grid KiCad's ERC uses for its off-grid check - so nearly every
    symbol and wire in the design was flagged, across all 5 sheets.
    Fixed via a snap transform applied to every symbol position, wire
    endpoint, junction, global label and no-connect marker in POWER,
    TRRS, MIXER, HPAMP and MICSW (lib_symbols definitions left untouched).
    Snapping is a deterministic function of the original coordinate, so
    any two points that were exactly coincident before (KiCad's d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
    [HPAMP.kicad_sch, MICSW.kicad_sch, MIXER.kicad_sch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]
2026-07-23 Confirm ERC/DRC clean via user's real KiCad reports (0 errors each)
    User ran ERC and DRC in the KiCad GUI after the grid-alignment fix:
    ERC 0 errors/0 warnings, DRC 0 unconnected pads/0 errors (only the
    already-documented RV1-RV5 footprint-library warnings remain).
2026-07-23 Add fabrication-ready gerbers and PCBWay beginner ordering guide
    Generate the actual gerber/drill package from the final validated
    board (4 layers, 0 DRC/ERC errors) via kicad-cli, zipped into a
    single upload-ready file. Add a step-by-step PCBWay ordering guide
    for a first-time user, built from the real board specs (dimensions,
    layer count, min drill/track) so each form field can be checked
    against known-correct values instead of guessed.
    [MeetingHub-4-B_Cu.gbl, MeetingHub-4-B_Mask.gbs, MeetingHub-4-B_Silkscreen.gbo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]
2026-07-23 Add v0.1 enclosure draft (OpenSCAD) for 3D printing
    Parametric two-piece box (bottom shell + lid) built from the real
    board's own facts: dimensions, mounting hole positions, and the
    front/back/top panel assignment for J1/J2-J6/RV1-5/SW1-5 that was
    already decided in PCB-001 Fase 3.1. Component heights and exact
    connector protrusion depth aren't documented anywhere in the project,
    so those are called out as explicit estimates in mechanical/README.md
    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
    [MeetingHub-4-Case.scad]
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2026-08-08 Fix componente
    [BOM-PCBA-MeetingHub-4.csv]
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2026-08-12 Fix J2-J6 pad mismatch and J1 orientation flagged by JLCPCB DFM
    SMT026081260178_Y11: J2-J6 SMD pads resized to match real PJ-320D
    datasheet (1.5x3.0mm), local traces rerouted for clearance. J1
    rotated 180 deg to face outward (was mounted backwards). Gerbers v13.0.
    [BOM-PCBA-MeetingHub-4.csv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]
2026-08-12 Fix TP1 not actually connected to +5V_AUDIO in schematic
    Pin sat at the exact midpoint of a wire with a junction dot drawn
    there, looking correct, but KiCad's netlist consistently placed it
    on its own isolated net. Pre-existing bug, unrelated to the J1/J2-J6
    fix. Fixed with an explicit local label at TP1's pin (schematic-only,
    no PCB/gerber impact - the PCB pad was already on the right net).
    [POWER.kicad_sch]
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2026-09-01 Criado nova versão do projeto para corrigir as falhas e ficar mais barato com 2 camadas
    [BOM-MeetingHub-4-v1.csv, BOM-MeetingHub-4-v2.csv, BOM-MeetingHub-4.csv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]
2026-09-03 V2 corrigida, pronta para produção
    [BOM-JLC-MeetingHub-4-v2.csv, BOM-MeetingHub-4-v2.csv, BOM-PCBA-MeetingHub-4-v2.csv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]
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
